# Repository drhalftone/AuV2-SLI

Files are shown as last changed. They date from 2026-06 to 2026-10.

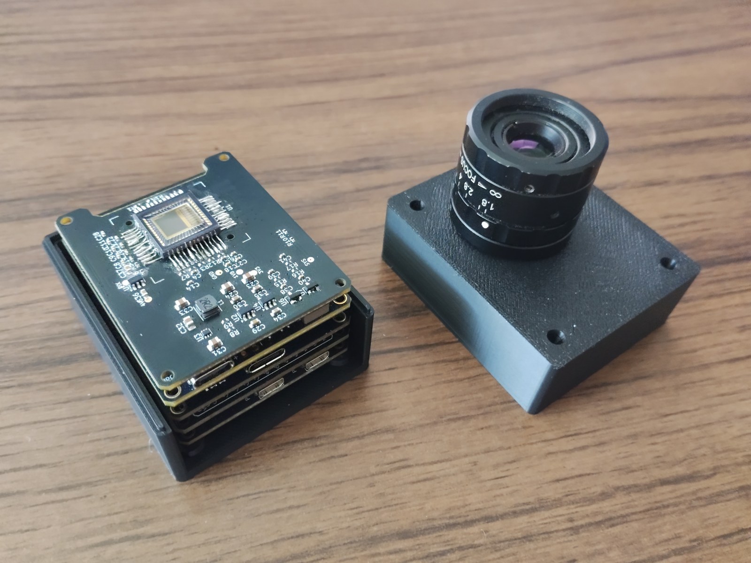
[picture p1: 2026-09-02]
press/stack_with_lens_cap_print.jpg

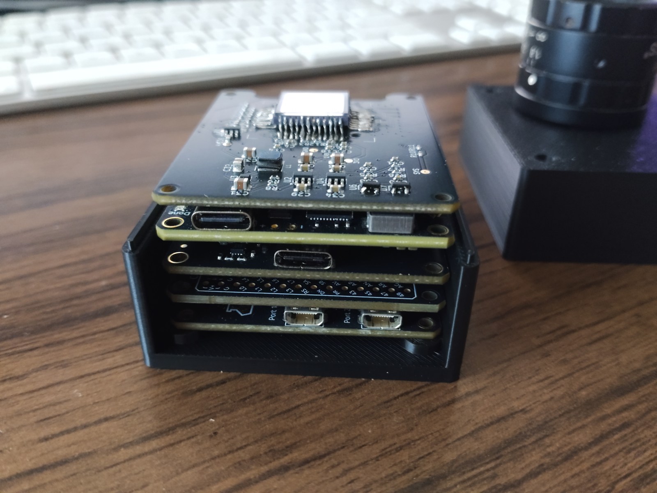
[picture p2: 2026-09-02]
press/stack_connector_edge_print.jpg

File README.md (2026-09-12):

# AuV2-SLI — an FPGA structured-light scanner with the camera inside it

A **BYOP (Bring Your Own Projector) machine-vision camera**: an Alchitry **Pt V2**
(Xilinx Artix-7 **XC7A100T-2**) sits inline on HDMI between a PC and a projector, and carries
an **ON Semi PYTHON 1300** global-shutter sensor on a stacked daughter board. One bitstream
generates the structured-light patterns, drives the projector, triggers the sensor at a
commanded delay from the projected vsync, and streams 10-bit frames to the host over an
**Alchitry Ft+** (FT601Q) USB 3.0 link.

The FPGA can:

- **Pass HDMI through** from a PC to the projector, triggering the camera on each new frame.
- **Replace the video with on-board SLI fringes** — resolution-adaptive, generated on the fly.
- **Run fully offline, with no HDMI source at all** — it reads the projector's EDID and drives
  it at a mode the projector actually advertises, up to **1280×1024@60** or **800×600@120**.
- **Genlock capture to projection** — camera triggers are issued a programmable delay after the
  projected vsync, and **stack**, so patterns advance at the full HDMI frame rate instead of at
  (exposure + delay).
- **Stream to the PC over USB 3** — 1280×1024 × 10 bit, byte-exact, up to 120 fps sustained.

> The HDMI datapath is adapted from [hamsternz/Artix-7-HDMI-processing](https://github.com/hamsternz/Artix-7-HDMI-processing) (MIT).
> Original SLI design by Qishi Hu. This fork adds the EDID-driven offline output, the adaptive
> pass-through clocking, the CEA-aware EDID merge, the PYTHON 1300 receive chain, the Ft+ USB 3
> image path, and genlock.

---

## 0. Quick orientation — what this repo is, on one screen

| | |
|---|---|
| **FPGA** | Alchitry **Pt V2**, `xc7a100tfgg484-2` (the original Au V2 / XC7A35T build still exists — `build.tcl`) |
| **Top level** | `sources_1/imports/RTL/Au2_SLI.vhd` (VHDL, instantiating the Verilog subsystems) |
| **Current build** | `build_merged.tcl` → `build_merged/Au2_SLI.{bit,bin}` — HDMI/SLI **+** camera **+** Ft+ |
| **Constraints** | `constrs_1/imports/RTL/Au2_pt.xdc` + `pt_ftplus_merged.xdc` |
| **Camera** | ON Semi **PYTHON 1300** (`NOIP1SN1300A-QTI`), 1280×1024, global shutter, 4-lane LVDS @ 720 Mbps |
| **Camera board** | `LauPythonCamera_Pt_Stack/` — the KiCad board **and** its Verilog (`ddr/`) |
| **Image path** | Alchitry **Ft+** (FT601Q) USB 3.0 — ~325 MB/s measured, 132 fps at 10-bit |
| **Control path** | the same Ft+ (opcode-0 tunnel), **and** a 115200 UART on Port A (COM6) kept as an independent witness |
| **Frame buffer** | DDR3 via MIG — **mandatory**, the sensor reads out in a 4.55 ms burst at 576 MB/s |

**Two control links, on purpose.** Everything the host needs is reachable over the Ft+. Port A's
UART is kept because *the frame stream goes silent exactly when the camera fails* — the link that
can still answer in that state is the one worth having.

### Where to look

| Document | For |
|---|---|
| [`USB_COMMAND_REFERENCE.md`](USB_COMMAND_REFERENCE.md) | **Every get and put** — 11 writable registers, ~120 readable, 6 table targets, the Ft+ opcodes |
| [`FTPLUS_API.md`](FTPLUS_API.md) | The Ft+ control API, marked R / W / R-W |
| [`FRAME_HEADER_PLAN.md`](FRAME_HEADER_PLAN.md) | Per-frame header design (format 3 → 4): pairing, timestamps, `pat_period` |
| [`GENLOCK_MILESTONES.md`](GENLOCK_MILESTONES.md) | Locking exposure to the projected frame — G0…G3 |
| [`MERGE_MILESTONES.md`](MERGE_MILESTONES.md) | How HDMI and camera were merged onto one FPGA — M0…M7 |
| [`PT_PASSTHROUGH_DEBUG.md`](PT_PASSTHROUGH_DEBUG.md) | Pass-through bring-up on the Pt, and the bug that broke 640×480 for 16 months |
| [`CAMERA_RTL_PLAN.md`](CAMERA_RTL_PLAN.md) / [`CAMERA_RTL_REVIEW.md`](CAMERA_RTL_REVIEW.md) / [`CAMERA_SENSOR_PROTOCOL.md`](CAMERA_SENSOR_PROTOCOL.md) | The camera receive chain: plan, review, datasheet constants |
| [`PC_INTERFACE_INVENTORY.md`](PC_INTERFACE_INVENTORY.md) | Complete PC ↔ FPGA comms inventory |
| [`ROADMAP.md`](ROADMAP.md) / [`MIPI_CSI2_ROADMAP.md`](MIPI_CSI2_ROADMAP.md) / [`POLARFIRE_PORT_FEASIBILITY.md`](POLARFIRE_PORT_FEASIBILITY.md) | Board stack, a MIPI CSI-2 receiver, a PolarFire port |

---

## 1. RTL module map

Paths relative to `sources_1/imports/RTL/` unless noted.

### 1.1 Top level and clocking

| Module | Role |
|---|---|
| `Au2_SLI.vhd` | **Top.** Instantiates everything; owns mode selection, the DRP retune, `ext_sync`, the boot retune one-shot |
| `clk_selector.v` | Chooses between the recovered pass-through clock and the offline generated clock (`sel`) |
| `drp_clkgen13.v` | The **offline** output-clock MMCM — 13 curated modes, retuned over DRP |
| `drp_recfg.v` | DRP write sequencer for `drp_clkgen13` (per-mode M/D/O words) |
| `rx_drp_recfg.v` | DRP sequencer for the **recovery** MMCM (pass-through side) |
| `rx_freq_band.v` | Picks the recovery-MMCM band from the **measured** input frequency — this is what makes pass-through adaptive rather than fixed-×15 |

Clock domains: `clk100` (control / EDID / USB), the pixel clock and its ×5 (`pixel_io_clk_x5`),
`wordclk` (72 MHz, recovered from the sensor's LVDS), and MIG's `ui_clk`.

### 1.2 HDMI receive (pass-through)

| Module | Role |
|---|---|
| `hdmi_io.vhd` | Wrapper for the input and output halves of the HDMI stream |
| `hdmi_input.vhd` | Decoded-stream assembly: control periods, data islands, sync extraction |
| `input_channel.vhd` | One TMDS channel: deserialise → align → decode (Mike Field) |
| `deserialiser_1_to_10.vhd` | ISERDESE2 1:10 |
| `alignment_detect.vhd` | **Bitslip search.** `signal_quality` accumulates `x"100000"` per error and trips at bit 27 |
| `tmds_decoder.vhd` | 10b → 8b TMDS decode |
| `video_meas.v` | Measures the **incoming** timing: h/v active, frame period, validity (regs `0x60`–`0x6A`) |
| `video_phase_fifo.v` | Elastic phase-compensation buffer across the recovered-clock boundary |

> **`alignment_detect.vhd` is the one to remember.** A dropped hex digit (`x"000100"` instead of
> `x"100000"`, introduced 2025-04-17) made the bitslip search **4096× too slow** — 31 ms per tap
> instead of 7.6 µs. Fast pixel clocks still converged; **640×480 never did.** Restoring the
> upstream constant fixed 640×480@60 and @75 pass-through.

### 1.3 HDMI transmit

| Module | Role |
|---|---|
| `dvid_output.vhd` | **DVI-D** output assembly: 3 × TMDS encode + 4 × serialise. Control codes only — **no guard bands, preambles or data islands** (those exist on the RX side, not here) |
| `tmds_encoder.vhd` | 8b → 10b TMDS encode |
| `serialiser_10_to_1.vhd` | OSERDESE2 10:1 — **the ceiling**: ×5 must stay under ~600 MHz |
| `vga.vhd` | **The live offline timing generator** — runtime H/V geometry in via ports, from `mode_timing_rom` |
| `video_timing_gen_rt.v` | Cleaner runtime timing generator (gates counters on `mmcm_locked`). **Written but NEVER instantiated** — unfinished Phase-D2 work; `vga.vhd` does this job today |
| `mode_timing_rom.v` | Per-mode video geometry lookup, keyed by `mode_idx` |
| `mode_table.vh` | The 14 curated modes (§4) |

### 1.4 EDID

| Module | Role |
|---|---|
| `i2c_master_edid.v` | Bit-banged I²C master; reads the **projector's** EDID off the output DDC |
| `edid_merge.v` | Self-contained merge unit + hot-plug ownership; re-probes every ~0.5 s |
| `edid_builder.v` | Builds the merged block served to the PC (monitor name `FPGA-PT`) |
| `edid_serve.vhd` | RAM-backed DDC **slave** on the input connector |
| `mode_select.v` | Parses the display EDID → supported-mode mask → the pick (regs `0x20`–`0x2A`) |

> `edid_fall` (reg `0x82`) counting **exactly 2/s is healthy** — it is the 0.5 s monitor-presence
> probe, not a fault. This was misdiagnosed twice.

### 1.5 Pattern generation

| Module | Role |
|---|---|
| `pattern_gen.v` | **Resolution-adaptive fringe DDS** (§5) |
| `pixel_pipe.v` | Pattern/pass-through mux, top-left-pixel trigger detection, the ready-paced GPIO handshake |
| `vga.vhd` | The offline test pattern — red = horizontal ramp, green = vertical ramp, blue = `h xor v` (XOR checker reveals geometry / tearing / a dead channel). Also generates the offline video timing — see §1.3 |

### 1.6 Camera — PYTHON 1300

RTL under `sources_1/imports/RTL/` and `LauPythonCamera_Pt_Stack/ddr/`.

| Module | Role |
|---|---|
| `cam_lvds_rx.v` | 1:10 LVDS receiver, PLL mode, per-lane IDELAYE2 |
| `cam_align.v` | Per-lane training / bitslip alignment |
| `cam_sync_decode.v` | Sync-channel decode + 4-lane de-interleave (proven bit-exact against the OVC reference) |
| `cam_spi_master.v` | 9-bit-addr / 16-bit-data SPI to the sensor |
| `cam_boot_seq.v` | ROM-driven power-up sequencer |
| `cam_cds_rom.v` | The CDS / sequencer-program upload payload |
| `cam_line_buf.v` | One-line capture buffer (bring-up) |
| `cam_async_fifo.v` | Dual-clock gray-pointer FIFO, **FWFT** |
| `cam_reply_fifo.v` | Control-plane reply bytes, `clk100` → `ui_clk` |
| `ddr/cam_frame_ft.v` | **The datapath.** Camera → DDR3 → FT601. Owns exposure, trigger period, re-arm, frame count, the genlock delay engine, and `cam_stat_o` |
| `ddr/cam_frame_ddr.v`, `ddr/ddr_bist.v`, `ddr/ddr_loop_ft.v`, `ddr/ft_probe_bottom.v` | Bring-up harnesses, kept as isolation tests |

> **The DDR3 is not optional.** The sensor reads a frame out in a **4.55 ms burst at 576 MB/s**
> against a 325 MB/s link. Live video cannot bypass the buffer, and lowering the frame rate does
> not help — the *burst* rate is what exceeds the link.

> `cam_async_fifo`'s `ram_style="block"` is **ineffective** (combinational FWFT read): 0 BRAMs are
> used. FIFO depth is not an available remedy.

### 1.7 Host link

| Module | Role |
|---|---|
| `uart_rx.v` / `uart_tx.v` | 8N1, LSB first |
| `uart_ctrl.v` | The `0xA5` control protocol — register file, table upload/readback |
| `status_line.v` | The one-line telemetry stream |
| `usb_link.v` | Arbitrates telemetry vs. command replies; **derives the max usable exposure** (§7.4) |
| `led_idle_anim.v` | "Sign of life" idle animation over the status LEDs |

---

## 2. Operating modes

### 2.1 Pass-through with top-left-pixel (TLP) trigger
The PC plays the patterns; the FPGA forwards the video unchanged, samples the **top-left pixel** of
each frame, and fires a camera pulse on the next VSYNC when that value changes.

### 2.2 Pass-through with on-board SLI patterns
The FPGA **replaces** the incoming frames with locally generated fringes. Orientation (`SW[0]`),
per-channel enables (`SW[3:1]`) and the frame/frequency sequencing drive it at runtime; all four
switches are overridable over USB (`SLICTRL`, reg `0x13`).

### 2.3 Offline (EDID-driven) — no HDMI source required
With nothing on the input, the FPGA generates everything from its own 100 MHz oscillator. The
output pixel clock **and** the video timing are reconfigured at runtime to match the projector's
EDID: a dedicated `MMCME2_ADV` is retuned over DRP and `vga.vhd`'s timing ports are loaded from the
curated table via `mode_timing_rom`.

> **Boot retune one-shot.** On power-up the DRP retune pulse used to be issued before the MMCM had
> locked, and was discarded — a blank screen on every cold boot. `Au2_SLI.vhd` now re-issues
> `clkgen_sen` once at **1 s** after configuration (`boot_cnt = 100_000_000` on `clk100`).
> `boot_cnt` is declared `integer` deliberately: both `STD_LOGIC_ARITH` and `NUMERIC_STD` are in
> scope in that file, so an `unsigned` would be ambiguous.

---

## 3. Genlock — the reason the FPGA is inline

`ext_sync` is the **output** vsync (`Au2_SLI.vhd`: `ext_sync => out_vsync`) delivered into
`cam_frame_ft.v`. Camera triggers are issued a programmable delay after it.

**Triggers stack.** Because the delay and the exposure are both known exactly, the delay engine is a
*fire-time queue*, not a wait-for-ready handshake:

```verilog
localparam [23:0] XS_TIMEOUT = 24'd10_000_000;   // 100 ms with no vsync -> fall back
localparam integer GLQ_AW    = 5;                // 32 outstanding triggers
reg [23:0] gl_now;                               // free-running 10 ns time base
reg [23:0] glq [0:31];                           // absolute fire-times
wire [23:0] gl_late = gl_now - glq[glq_rd];      // top bit CLEAR = deadline passed
wire gl_push = xs_rise && gl_live && !glq_full;
wire gl_pop  = !glq_empty && !gl_late[23];
```

So with a delay longer than a frame, **patterns advance at the full HDMI rate** — the capture of
pattern *k* simply arrives while pattern *k + floor(D/T)* is on screen. That pairing offset is
`floor(D/T)`; read it from reg `0x5E` (outstanding). **Do not assume it** — an offset wrong by one
yields a phase map that looks plausible and is wrong everywhere.

- `gl_en` is what was **commanded**; `gl_live` is whether `ext_sync` is actually arriving. They
  differ exactly when the display has gone away and the trigger has fallen back to free-running.
- Set it over the Ft+: **opcode 7**, `{4'd7, gl_en, 3'b0, delay[23:0]}`, delay in 10 ns ticks.
- Read it back over the UART: `0x5A`–`0x5C` delay, `0x5D` `{gl_live, gl_en}`, `0x5E` outstanding,
  `0x5F` FIFO overflows.

> **Sync must be held across the whole control period.** `hdmi_input.vhd` used to clear
> `raw_vsync`/`raw_hsync` alongside `raw_blank`, so on the 8 of 14 modes with **negative** vsync
> polarity `ext_sync` fired once per *line*. Sync is now assigned only from `ch0_ctl`.

**Not yet proven:** where the exposure actually lands optically inside the projected frame. Nothing
on the board sees photons — that measurement is photometric.

---

## 4. The curated mode table (`mode_table.vh`)

| idx | Mode | Pixel clock | H pol | V pol |
|---|---|---|---|---|
| 0 | 800×600@120 (CVT-RB) | 73.270 MHz | + | − |
| 1 | 640×480@120 (CVT-RB) | 52.420 MHz | + | − |
| 2 | 1024×768@75 (DMT) | 78.750 MHz | + | + |
| 3 | 800×600@75 | 49.500 MHz | + | + |
| 4 | 640×480@75 | 31.500 MHz | − | − |
| 5 | 1024×768@70 | 75.000 MHz | − | − |
| 6 | 800×600@72 | 50.000 MHz | + | + |
| 7 | 640×480@72 | 31.500 MHz | − | − |
| 8 | 1280×720@60 (CEA/DMT) | 74.250 MHz | + | + |
| 9 | 1280×800@60 (CVT-RB) | 71.110 MHz | + | − |
| 10 | 1024×768@60 | 65.000 MHz | − | − |
| 11 | 800×600@60 | 40.000 MHz | + | + |
| 12 | **640×480@60 — FAILSAFE** | 25.175 MHz | − | − |
| 13 | 1280×1024@60 (DMT) | 108.000 MHz | + | + |

**Selection order is `PRIO[] = {0,1,2,3,4,6,7,5,13,9,8,10,11,12}`** — highest refresh, then highest
pixel count.

> Priority is **deliberately not** the table index. `mode_idx` is a shared key into *both*
> `mode_table.vh` geometry **and** `drp_recfg`'s per-mode MMCM words, so re-sorting the table to
> express priority would hand each mode another mode's pixel clock. `mode_select` walks an explicit
> `PRIO[]` list instead; [`sim/tb_mode_select.v`](sim/tb_mode_select.v) covers it.

The EDID is a **filter, not a source** — a display's preferred timing is *matched against* this
table, never adopted. No match → idx 12.

Pin a mode with `MODEFORCE` (reg `0x14`; `0x8D` = force idx 13).

---

## 5. `pattern_gen.v` — resolution-adaptive fringes

The fringe period is solved **per mode at runtime** from the active size:

```
F     = active size along the varying axis   (orient=0 -> Vactive, orient=1 -> Hactive)
b     = ceil(F / 288)
P_lo  = 288b      P_mid = 48b      P_hi = 8b        (exact 1 : 6 : 36)
```

so the same `frq` index is a **different spatial frequency at every resolution**, and `P_lo` is
re-solved on a mode change. A scan spanning a mode change silently changes fringe period unless the
period travels with the data — which is why `pat_period` is in the planned frame header.

`frq == 3` is **not a fringe**: it selects a flat full-field flashing block for texture/albedo
capture. Sequence: 3 frequencies × 8 phases = 24 frames, plus the flash entries.

**The `corr` table is live in the pixel path.** `pattern_gen` presents its raw cosine to a 256-entry
transfer LUT and uses the result for every **fringe** pixel: `out = corr[cos]`. It powers up
identity, so leaving it unwritten changes nothing. FLASH pixels bypass it and stay true
`0x00`/`0xFF`. The lookup is **combinational by necessity** — a registered BRAM read would apply
each pixel's correction to the *next* pixel — so it synthesises as 256×8 LUTRAM.

`host/upload_corr.py --selftest` proves the LUT reaches the pixels: it uploads a constant curve and
watches the pipe-**output** top-left sample (`O=`) collapse onto that constant while the
pipe-**input** sample (`P=`) does not move.

> **`LUT` (0x00, 720 B) and `LUT_V` (0x01, 1280 B) have no consumer** — vestigial from the old
> `indexMap`/ROM design. They upload and read back fine and do nothing.

---

## 6. HDMI clocking, EDID merge, and the two ceilings

### Pass-through
`rx_freq_band.v` measures the incoming frequency and selects the recovery MMCM's band; the
multiplier **follows the input** rather than being fixed at ×15. `BANDWIDTH = HIGH`, so it tracks
the GPU's spread-spectrum clock.

**Verified working:** 640×480@60/@75, 800×600@60, 1024×768@60/70/75, 1280×720@60, 1280×800@60.

> **800×600 pass-through was advertised by arithmetic and never tested** until 2026-08-30; it ran
> the MMCM VCO at its rated minimum. `test_modecycle.py` measures only the **input**, so it reports
> success on a mode the projector never displays. Trust an eye on the projector, not that tool.

> **1280×1024 pass-through was attempted and dropped.** Recovering 108 MHz and re-serialising at
> 540 MHz never held sync — the recovered clock carries the GPU's spread spectrum, and a
> jitter-cleaner MMCM only reached "mostly perfect". Offline SXGA (clean clock, no domain crossing)
> is the supported 1280×1024 route.

### Served EDID
The FPGA reads the **projector's** EDID over the output DDC and serves the PC a **merged** EDID
(monitor name `FPGA-PT`) = `{projector's modes} ∩ {pass-through window}`, with a **60 MHz floor** so
only modes pass-through can actually hold are offered. The merge reads block-0 timings **and** the
CEA-861 extension's Video Data Block, so a TV-style sink advertising 720p60 only as VIC 4 is still
picked up.

### Hot-plug / EDID re-read
The board owns the host HPD line: held **low** until a projector is detected and a merged EDID
built, then asserted. It also **re-pulses HPD (~500 ms low) whenever the merged EDID content
changes** — many projectors serve a placeholder EDID during warm-up, and this makes their real modes
appear without unplugging the PC's cable. Per-build serial and checksum bytes are excluded from the
change detector, so it fires only on real mode changes.

`LINKCTL` (reg `0x15`) forces a self-timed disconnect: **dropping the host HPD is the only reliable
way to force the board offline** — a host-side detach cannot do it.

### Offline ceiling
The output serialiser sets it: **1280×1024@60 (108 MHz, ×5 = 540 MHz) is the top offline mode**,
HW-verified on this −2 part. **1080p60 is NOT reachable** (×5 = 742.5 MHz, over the ~600 MHz
OSERDES/BUFG ceiling; the HDMI I/O is on 3.3 V TMDS HR banks, ~1.2 Gb/s/ch).

---

## 7. The host interface

### 7.1 Two transports, one protocol

The `0xA5` framed protocol is identical on both links.

| Op | Request | Reply |
|---|---|---|
| Write reg | `A5 57 ADDR DATA CK` | `K` ok / `N` read-only or undefined / `E` bad CK |
| Read reg | `A5 52 ADDR CK` | `ADDR DATA CK2` |
| Upload table | `A5 5B TGT D[0..N-1] CK` | `K` / `E` |
| Read table | `A5 72 TGT CK` | `TGT D[0..N-1] CK2` |

`SYNC 0xA5` is never part of a checksum; `CK` drives the running payload sum to 0 mod 256.

**Over the UART** (COM6, 115200 8N1) the bytes go on the wire directly.

**Over the Ft+** they are tunnelled as **opcode-0 words**, three bytes at a time with an explicit
count: `{4'd0, count[3:0], byte2, byte1, byte0}`. They cannot be packed raw — the top nibble of
every OUT word is a camera opcode, so a protocol byte landing at `0x1?` would fire opcode 1 and
silently rewrite the exposure.

Replies come back **interleaved with video** on the IN pipe, with the same 32-byte header shape as a
frame: magic `"SLI1"` (frames are `"SLI0"`), format 4. **A reply is a transport chunk, not a
message** — one reply can split across two packets and two can share one, so the host reassembles a
byte stream and lets the `0xA5` framing do its own work. Replies leave only at **frame boundaries**:
at 120 Hz that is up to ~8.3 ms of latency, by construction. Size timeouts in milliseconds.

### 7.2 Ft+ opcodes (top nibble of each 32-bit OUT word)

| Op | Payload | Effect |
|---|---|---|
| 0 | `{count[3:0], b2, b1, b0}` | **`0xA5` protocol tunnel** — see above |
| 1 | `[15:0]` | Set exposure, in **375 ns** units |
| 2 | `[23:0]` | Set the free-running trigger period (10 ns ticks); ignored if ≤ 1000 |
| 3 | — | **Re-arm** the capture |
| 4 | `[5:0]` | Frames per run (1…`MAXF`) |
| 5 | — | Request a status reply on the IN pipe |
| 7 | `{gl_en, 3'b0, delay[23:0]}` | **Genlock**: enable + vsync→trigger delay in 10 ns ticks |
| 8 | *(planned)* | Arm an epoch reset on the next `ext_sync` — see `FRAME_HEADER_PLAN.md` |

> Opcode 6 is unassigned. Opcode 3 (**re-arm**) is easy to forget and its absence is invisible: a new
> exposure changes nothing the host can see, because DDR still holds the burst captured at the old
> value and capture is one-shot per bitstream load.

### 7.3 Register map

**Writable (11):** `0x13` SLICTRL, `0x14` MODEFORCE, `0x15` LINKCTL, `0x16` CAMSIM,
`0x30`–`0x34` CAM_SPI (addr / `{rw,addr[8]}` / wdata lo / wdata hi / GO), `0x37` CAM_GPIO,
`0x39` CAM_BOOT. Everything else answers `N` to a write.

| Addr | Name | Acc | Meaning |
|---|---|---|---|
| `0x00` | ID | R | constant `0x48` (`'H'`) — the control bitstream is loaded |
| `0x01` | VERSION | R | protocol version (`0x01`) |
| `0x02` | STATUS | R | `{vsync, hsync, VPol, sel, mode, rdy, f_frm, trig}` (same as the LEDs) |
| `0x06` | FLAGS | R | `{…, usb_sw_en, lut_loaded}` |
| `0x10` | PINS | R | `{eff_sw[3:0], phys_sw[3:0]}` — active vs. physical switch pins |
| `0x13` | SLICTRL | R/W | `{7:sw_en, 6:mode_en, 5:mode_val, 3:R, 2:G, 1:B, 0:orient}` |
| `0x14` | MODEFORCE | R/W | `{7:force_en, 3..0:idx}` — pin the **offline** mode (`0x8D` = idx 13) |
| `0x15` | LINKCTL | R/W | `{7..2:secs×2, 1:proj, 0:host}` self-timed disconnect; `0x41` = host-drop 8 s |
| `0x16` | CAMSIM | R/W | host-driven camera-ready, to run the pipeline with no camera |
| `0x20` | MODE | R | `{7:valid, 6:edid_ok, 3..0:mode_idx}` — the index **in use** |
| `0x21` | REFR | R | refresh rate, Hz |
| `0x22`–`0x23` | HACT | R | active pixels, 12-bit |
| `0x24`–`0x25` | VACT | R | active lines, 12-bit |
| `0x26`–`0x28` | PCLK | R | pixel clock in kHz, 17-bit |
| `0x29`–`0x2A` | SUPP | R | 14-bit supported-mode mask (bit *i* = table index *i*) |
| `0x30`–`0x36` | CAM_SPI | R/W | PYTHON 1300 SPI mailbox (`0x34` GO/busy, `0x35`/`0x36` rdata) |
| `0x37` | CAM_GPIO | R/W | `{7:reset_n, 2..0:trigger}` — resets to `0x00` (sensor held in reset) |
| `0x38` | CAM_MON | R | `{1..0:monitor}` |
| `0x39` | CAM_BOOT | R/W | boot sequencer; W starts it (`N` if busy), R = `{ready, busy, failed, pll_timeout}` |
| `0x3A` | CAM_STAT0 | R | `{stw[2:0], rd_busy, calib, aligned, streaming, cap}` — "is it alive" |
| `0x3B` | CAM_STAT1 | R | `{cfifo_ovf, ufifo_ovf, ufifo_empty, txe, 0000}` — "is it healthy" |
| `0x3C`–`0x3D` | LDROP | R | padded frames; **static == none lost** |
| `0x3E`–`0x3F` | CAM_PER | R | frame period **÷ 16**, in 72 MHz wordclk cycles |
| `0x40`–`0x41` | EXPO0 | R | exposure, 375 ns units |
| `0x42`–`0x47` | TRIG→INT | R | trigger → integration start, **min** then **max**, 10 ns units |
| `0x48`–`0x49` | INT_LEN | R | last integration length, 160 ns units |
| `0x4A`–`0x52` | VS_PER | R | vsync period: last / min / max, 10 ns units |
| `0x53`–`0x57` | MAXEXP | R | max usable exposure — §7.4 |
| `0x58`–`0x59` | XS_CNT | R | `ext_sync` edge count, free-running, wraps |
| `0x5A`–`0x5C` | GL_DLY | R | genlock delay, 10 ns ticks |
| `0x5D` | GL_STAT | R | `{6'b0, gl_live, gl_en}` |
| `0x5E` | GL_OUT | R | triggers outstanding = the pairing offset |
| `0x5F` | GL_OVF | R | genlock FIFO overflows (saturates) |
| `0x60`–`0x6A` | RX_MEAS | R | **incoming** HDMI: h/v active, period, `{vid_valid, meas_ok}`, recovered pclk kHz |
| `0x6B`–`0x6C` | RX_DIAG | R | decode diagnostics; phase-FIFO re-primes |
| `0x6D`–`0x80` | CTL/VDP/PRE/GB/EVT | R | control-period, video-data-period, preamble, guard-band and event counters |
| `0x81`–`0x82` | HPD_DIAG | R | HPD-to-PC falling edges; `edid_ok` falling edges |
| `0x83`–`0x8D` | OUT_MEAS | R | **transmitted** timing: h/v active, period, valid, pclk kHz |
| `0x8E`–`0x90` | TRIG_PER | R | the free-running trigger period in effect |

**Read `0x67` first.** If `meas_ok` is 0 the other six read 0 *on purpose* — a stale resolution that
looks live is worse than no answer.

**Min and max are the point** for `0x42`–`0x47` and `0x4A`–`0x52`. The datasheet gives no
trigger-to-exposure delay at all and says integration snaps to a line boundary (~5.7 µs) whenever it
begins during a readout — which in pipelined mode is always. `max − min` **is** that jitter,
measured; a single sample could not show it. The window resets every status tick (~10 Hz), so each
read describes a fresh window rather than an ever-widening high-water mark.

**Table targets** (op `0x5B` upload / `0x72` read):

| TGT | Name | Size | Acc | Contents |
|---|---|---|---|---|
| `0x00` | LUT | 720 B | R/W | vestigial — **no consumer** |
| `0x01` | LUT_V | 1280 B | R/W | vestigial — **no consumer** |
| `0x02` | CORR | 256 B | R/W | the radiometric transfer LUT, live in the pixel path (§5) |
| `0x03` | EDID | 256 B | **R** | the EDID the **display** sent us — what `mode_select` decided from |
| `0x04` | CAM_LINE | 1280 B | **R** | one captured camera line (bring-up) |
| `0x05` | EDID_SRV | 256 B | **R** | the **merged** EDID we serve to the PC |

`0x03` vs. `0x05` is the pair worth knowing: one is what the projector claims, the other is what the
PC is told. `host/offline_mode.py` reads both.

> An EDID readback is always 256 bytes; if the display has no extension block, bytes 128–255 are
> stale RAM. Byte `0x7E` of block 0 is the authoritative extension count.

### 7.4 Max usable exposure — the FPGA works it out itself

`usb_link.v` derives how long the sensor can integrate at whatever rate it is *actually* running:

```verilog
wire        gl_live_s  = cam_stat_i[169];
wire [23:0] trig_per_s = cam_stat_i[215:192];
wire [23:0] eff_per    = gl_live_s ? vsp_last_p : trig_per_s;   // vsync period, or free-run period
```

Reserve = `GAP_TICKS` 4410 (44.1 µs) + `MARGIN_TICKS` 1000 = **54.1 µs**, then scaled from 10 ns into
375 ns register units by `×27962 >> 20`.

- `0x53`/`0x54` — max exposure **in exposure-register units**; write it straight back with opcode 1.
- `0x55` — `{7: valid, 6: limited by the 16-bit register rather than by the frame period}`.
- `0x56`/`0x57` — the reserve subtracted, in 10 ns ticks.

**`valid = 0` means do not guess.** Commanding an exposure longer than the frame period wedges the
sensor until the FPGA is reconfigured — the exact failure this register exists to prevent.

> **Trap:** `0x3E`/`0x3F` holds the camera period **÷ 16** in 16 bits and therefore cannot represent
> anything below **68.67 Hz**. A genlocked 59.9 Hz and 6.16 Hz produce the same reading. Infer
> nothing about genlock from it — read `0x5D`. `host/max_exposure.py` still infers, and is wrong
> below 68.67 Hz.

### 7.5 Telemetry (COM6, 115200 8N1, ~2 lines/s)

```
S=sel V=pol T=trig F=frm M=mode R=rdy N=vsync L=hh D=hh G=hh P=hh C=hh O=hh
```

`S` = pass-through(1)/offline(0), `D` = decode debug (symbol-sync / PLL-lock / sel), `P`/`O` =
recovered vs. pipe-output top-left red, `N` = VSYNC edges per window.

> `N` is an **edge count** and dithers between 51 and 52 at 120 Hz — it cannot resolve the period
> better than ~2% and cannot see jitter at all. Use `0x4A`–`0x52` for that.

---

## 8. Host tools

### 8.1 Over the Ft+ — `ft_usb_video/host/`

Needs `ftd3xx`; only **one** process may hold the D3XX handle at a time.

> **There is exactly one viewer: `cam_live.py`.** Because only one process can hold the D3XX handle,
> a second viewer could only ever be the wrong one to have open. `ft_video_grab.py` used to default
> to a controls-free PySide6 window; that was removed 2026-09-01 and it is now headless. Nothing in
> the repo needs PySide6.

| Tool | Does |
|---|---|
| `cam_live.py` | **The live viewer — the only one in this repo.** tkinter; exposure slider, plus a second row with a *sync to projector* checkbox and a trigger-delay slider. The exposure ceiling tracks the measured rate |
| `cam_ctl.py` | Exposure, frame rate and re-arm from the command line |
| `campack.py` | Frame geometry, header parsing and 10-bit unpacking — **shared** by the other tools |
| `cam_rate_bench.py` | Frame rate over repeated 24-frame runs |
| `ft_cam_burst.py` | An N-frame burst captured into DDR and streamed out |
| `ft_cam_verify.py` | Byte-exactness of the FT601 bus, plus a PNG |
| `drift_check.py` | Frame-to-frame alignment drift, in kernels |
| `row_align_check.py` | Are delivered frames aligned *with each other*? (row profiles) |
| `ring_check.py` | Frames must be clean, fresh, and cost no lost kernels |
| `scan_latency.py` | Re-arm → time until a complete **new** scan arrives |
| `expo_check.py` | Exposure is settable at runtime; measures the response |
| `ddr_loop_check.py` | Concurrent DDR3 write+read loopback, byte by byte |
| `test_campack.py` | Round-trips the packed-10 layout against a model of the RTL packer |
| `test_m5_reply.py` | Does the link answer back without damaging the frame stream? |
| `ft_video_grab.py` | Throughput meter, **headless** — framed FPS/MB-s, or `--raw` unframed. Also the home of `FtDevice` / `FrameAssembler` / `unpack_raw10`, which the other tools import |
| `ft_bench_async.py`, `ft_diag_rows.py` | Zero-copy throughput sweep; per-column corruption forensics |

> **`ft_video_snap.py` validates the SYNTHETIC SLI pattern**, not the camera. Pointed at real camera
> data it reports "0 frames matching, worst pixel error 1023" and writes a random-looking PNG. That
> is the tool answering a different question. Use `cam_live.py` to judge real output.

### 8.2 Over the Ft+ control plane — `host/`

`ftlink.py` (the transport class), `test_m6a_ctlpath.py`, `test_m6a_under_load.py`,
`test_m6b_reply.py`, `test_m6c_silicon.py`, `dbg_m6b_packet.py`.

### 8.3 Over the UART — `host/`

| Tool | Does |
|---|---|
| `test_silicon.py` | The bring-up test — **15/15** |
| `test_protocol.py` | Offline cross-check of the framing |
| `dump_edid.py` | Dump and decode the display's EDID as the FPGA captured it |
| `read_mode.py` | Which offline mode was picked, and what it had to choose from |
| `force_mode.py` | Pin the offline mode over `MODEFORCE` |
| `offline_mode.py` | Inspect both EDIDs and drive the offline mode |
| `rx_timing.py` | What the source is actually sending |
| `read_cam_status.py` | The camera datapath status (`0x3A`–`0x41`) |
| `max_exposure.py` | How long the camera can expose at the current rate *(see the 68.67 Hz trap)* |
| `measure_vsync_period.py` | Vsync period and jitter (genlock G0) |
| `measure_trigger_latency.py` | Trigger → integration start, and its jitter |
| `measure_exposure_gap.py` | Is the blind window between exposures constant? |
| `upload_corr.py` | Upload the radiometric LUT and prove it is live (`--selftest`) |
| `test_modecycle.py` | Cycle the PC's HDMI modes and check the FPGA follows *(measures the INPUT only)* |
| `test_3b_cameraidle.py`, `test_3c_camerawedge.py`, `test_3d_modechange.py` | Merge isolation: the camera must not disturb HDMI, and vice versa |
| `soak.py`, `stress_attack.py`, `usb_speed.py` | Long-run stability, hostile input, USB 3 confirmation |
| `lauauboard.{h,cpp}` | The C++ host-side implementation of the protocol |

> After a board reset, `edid_merge` needs a few seconds to finish reading the DDC. Until it does,
> `edid_ok` is 0 and `SUPP` is empty while `MODE` still reads the power-up default — a half-state
> that looks like a failed pick. `read_mode.py` waits for `edid_ok`.

---

## 9. Building and flashing

**Vivado 2025.2.1** lives at `C:\AMDDesignTools\2025.2.1\Vivado\bin\vivado.bat` (**not**
`C:\Xilinx`, and not on `PATH`).

```
vivado -mode batch -source build_merged.tcl    # -> build_merged/Au2_SLI.{bit,bin}   THE CURRENT DESIGN
vivado -mode batch -source build_pt_hdmi.tcl   # the HDMI/SLI half alone on the Pt V2
vivado -mode batch -source build.tcl           # the original Au V2 / XC7A35T design
vivado -mode batch -source program.tcl         # volatile JTAG load
```

| Script | Part | Contents |
|---|---|---|
| `build_merged.tcl` | XC7A100T (Pt V2) | **Current** — HDMI/SLI + PYTHON 1300 + Ft+ + MIG |
| `build_pt_hdmi.tcl` | XC7A100T | HDMI/SLI only — faster turnaround for pass-through work |
| `build_pt.tcl` | XC7A100T | **Stale** — predates M2, no camera datapath |
| `build.tcl` | XC7A35T (Au V2) | The original design; still builds |

Do not run two builds concurrently — they share an out-of-tree IP generation directory.

**Flashing** with the Alchitry loader **2.0.52+** (not the old `C:\Program Files\Alchitry` copy):

```
alchitry.exe load --bin build_merged/Au2_SLI.bin --board PtV2 --ram     # volatile, for testing
alchitry.exe load --bin build_merged/Au2_SLI.bin --board PtV2 --flash   # persistent
```

`AlchitryFlasher/AlchitryFlasher.cmd` is a one-click Windows flasher for the released
`Bitstream/Au2_SLI.bin` (SHA-256 checked).

**Simulation is available** — `xvhdl` / `xvlog` / `xelab` / `xsim` are installed.
`sim/tb_mode_select.v` covers the mode pick; `sim/tb_hdmi_loopback.v` + `sim/run_hdmi_tb.sh` cover
the HDMI path.

> **Vivado on this host crashes for tool reasons roughly half the time** — `[Designutils 12-1097]`,
> `EXCEPTION_ACCESS_VIOLATION`, bare exit 116 / 127. Retrying the same script normally succeeds.
> Note also that silent one-digit file corruption has been observed on this machine. **Run memtest
> before trusting an artifact.**

---

## 10. Traps this project has already paid for

| Trap | Why it bites |
|---|---|
| **Comments lie; the code does not** | `pre_diag`'s header claims preamble counts but the code counts vsync/hsync rises. `vdp_diag[31:16]` is labelled `in_dvid` and counts `in_adp`. `gb_diag[31:16]` is labelled `vdp_prefix_seen` and counts `vdp_guardband_detect`. Five wrong conclusions in one session came from believing headers |
| **`test_modecycle.py` measures the input** | It reports success on modes the projector never displays |
| **`edid_fall` at exactly 2/s is healthy** | It is the 0.5 s DDC presence probe |
| **`0x3E`/`0x3F` wraps below 68.67 Hz** | Period ÷ 16 in 16 bits. Never infer genlock from it |
| **FWFT FIFO + `rd <= !empty`** | Duplicates the last item every burst; a doubled stream fails exactly like a dead one |
| **Sensor damage at the top of the frame** | Permanent, from a soldering-era fault. Not an LVDS/link bug — do not chase it |
| **720 Mbps LVDS needs IDELAYE2** | Without eye-centring the isolated bit drops and it looks exactly like bad solder |
| **The FT601 can enumerate and not clock** | It can read an EEPROM back perfectly while driving no `ft_clk`. Pulse `RESET_N` |
| **The FT601 can stream fast and lie** | A build measured 192 fps / 0 drops while corrupting `ft_data[31:16]`. An unconstrained source-synchronous bus is invisible to timing *and* to throughput tests. **Verify bytes** |
| **Build scripts can silently drop generics** | Two experiments were invalidated this way. Check the generics actually reached synthesis |
| **PowerShell here-docs mangle git messages** | `git commit -m @'…'@` fails with pathspec errors. Write the message to a file and use `git commit -F` |
| **The RX input self-oscillates with no cable** | `sel`/offline hunts and `symbol_sync` is fooled; `pll_locked` staying 0 is the honest signal |

---

## 11. Pins, LEDs and switches

The Pt V2 pinout is in `constrs_1/imports/RTL/Au2_pt.xdc` (+ `pt_ftplus_merged.xdc` for the Ft+);
the camera board's connector map is in [`CAMERA_IO_MAP.md`](CAMERA_IO_MAP.md).

### Config switches

| Switch | Function |
|---|---|
| `SW[3]` | Red channel enable |
| `SW[2]` | Green channel enable |
| `SW[1]` | Blue channel enable |
| `SW[0]` | 0 = vertical stripes, 1 = horizontal |

All four are overridable over USB via `SLICTRL` (`0x13`) with bit 7 set:
`effective_sw = sw_en ? usb_value : SW`. `PINS` (`0x10`) shows both nibbles, so you can confirm the
override took and read live switch state at any time.

> **Next board rev:** make all four switches uniform (all pull-up / default-high, switch → GND). That
> needs the HvsV switch rewired from +3V3 to GND **on the PCB** — it is not an FPGA-only change —
> plus the HvsV logic inverted.

### LEDs

| LED | Indication |
|---|---|
| 7 | VSYNC |
| 6 | HSYNC |
| 5 | VSYNC polarity (1 = positive) |
| 4 | HDMI-Rx clock detected (off in offline mode) |
| 3 | 0 = SLI pattern, 1 = desktop display |
| 2 | Camera trigger ready |
| 1 | Current frame is the first of the pattern |
| 0 | Trigger output |

`led_idle_anim.v` runs a slider animation when nothing is connected — a deliberate sign of life.

### Legacy DB-9 camera GPIO (Au V2 / Br V2 era, still in `pixel_pipe.v`)

A 4-line handshake per camera: **trigger** out, **mode** in, **first-frame** out, **ready** in.
`pixel_pipe.v` drives `C1_out(0)` / `C2_out(0)`; Cam2 mirrors Cam1's outputs but only **Cam1's**
ready and mode inputs are wired, so Cam2's readiness does not gate the capture rate. This path is
independent of the PYTHON 1300 trigger, which comes from `cam_frame_ft.v`.

`pixel_pipe.v` uses a 1-deep `pending` with fresh-ready arming and a `GLITCH_CYC = 10000` de-glitch
(commit `ae8fa1e`).

> **Deferred TODO:** port the MimasA7 `cam_pace.v` edge-paced trigger over the AuV2 `rdy_cnt`
> accumulation, splitting split-mode's two jobs.

> `pattern_gen`'s enable comes from the camera board's `mode` GPIO (`C1_in[1]`), which the XDC
> **pulls low** — with no camera attached the generator is off and the offline test pattern passes
> straight through. Set `0x13` `mode_en` + `mode_val` to force the SLI fringes on with no camera
> board.

---

## 12. Boards in this repo

| Folder | What it is |
|---|---|
| [`LauPythonCamera_Pt_Stack/`](LauPythonCamera_Pt_Stack/) | **The current camera** — PYTHON 1300 daughter board for the Pt V2, *and* its Verilog under `ddr/` |
| [`LauCameraTrigger_Alchitry/`](LauCameraTrigger_Alchitry/) | The original Br V2 → DB-9 trigger breakout, plus the Basler / Alvium wiring guides |
| [`LauCameraTrigger_Alchitry_3xJST/`](LauCameraTrigger_Alchitry_3xJST/) | The same, with 3× on-board JST-7 connectors |
| [`LauCameraTrigger_Alchitry_Stack/`](LauCameraTrigger_Alchitry_Stack/) | DF40 stacking version; SPDT config switches, trigger broadcast to 3 cameras |
| [`LauMipiCamera_Alchitry_Stack/`](LauMipiCamera_Alchitry_Stack/) | MIPI CSI-2 board (WIP scaffold) — open in KiCad and run ERC/DRC before relying on it |

Camera-wiring guides under `LauCameraTrigger_Alchitry/`: Basler ACE USB 3.0, Allied Vision Alvium
1800, a three-camera DB-9 harness, the on-board JST-7 variant, and the Vimba FPGA timing guide.

> **rev-1 `LauCameraTrigger` had a floating GND island** at the DIP switch (SW1 / caps / tie-low not
> bonded to DF40 GND). rev-1 boards are bodged; fixed in layout, pending fab verification.

---

## 13. Repository layout

```
├── README.md                        # this file
├── USB_COMMAND_REFERENCE.md         # every get and put, both transports
├── FTPLUS_API.md                    # the Ft+ control API
├── FRAME_HEADER_PLAN.md             # per-frame header design (format 3 -> 4)
├── GENLOCK_MILESTONES.md            # G0..G3 — exposure locked to the projected frame
├── MERGE_MILESTONES.md              # M0..M7 — HDMI + camera on one FPGA
├── PT_PASSTHROUGH_DEBUG.md          # pass-through bring-up on the Pt
├── PC_INTERFACE_INVENTORY.md        # complete PC <-> FPGA comms inventory
├── PC_INTERFACE_PLAN.md             # diagnostics on the Pt, everything else on the Ft
├── CAMERA_RTL_PLAN.md               # PYTHON 1300 bring-up plan + gates
├── CAMERA_RTL_REVIEW.md             # fresh-eyes receiver-chain review (P1-P4)
├── CAMERA_SENSOR_PROTOCOL.md        # datasheet-cited protocol constants
├── CAMERA_IO_MAP.md                 # camera board I/O pin map
├── CAMERA_POWER_DESIGN.md           # camera board power design
├── CAMERA_POWER_SIMULATION.md       # camera board power simulation
├── CAMERA_CALIBRATION_NOTES.md      # two-point calibration — where it could live
├── ROADMAP.md                       # hardware expansion (DF40 stacking, Ft+, MIPI)
├── MIPI_CSI2_ROADMAP.md             # custom MIPI CSI-2 receiver plan
├── POLARFIRE_PORT_FEASIBILITY.md    # porting to a Microchip PolarFire kit
├── build_merged.tcl                 # THE CURRENT BUILD  (Pt V2: HDMI + camera + Ft+)
├── build_pt_hdmi.tcl                # HDMI/SLI half alone on the Pt V2
├── build_pt.tcl                     # stale Pt build (pre-M2)
├── build.tcl                        # original Au V2 / XC7A35T build
├── program.tcl                      # volatile JTAG load
├── sources_1/                       # HDL (sources_1/imports/RTL) + IP
├── constrs_1/                       # XDC — Au2.xdc (Au V2), Au2_pt.xdc + pt_ftplus_merged.xdc (Pt)
├── sim/                             # xsim testbenches
├── host/                            # UART + Ft+ control-plane tools, and the C++ host class
├── ft_usb_video/                    # the USB 3 image path — viewer, benches, verifiers
├── press/                           # press release (LaTeX + PDF) and the HTML reference pages
├── Bitstream/                       # released bitstream (Au2_SLI.bin)
├── AlchitryFlasher/                 # one-click Windows flasher
├── Matlab/                          # legacy pattern-generation scripts
├── build_scripts/                   # historical project-mode scripts (superseded)
├── Lau*_Alchitry*/ , LauPythonCamera_Pt_Stack/   # KiCad boards
└── LICENSE
```

## Licensing

The HDMI pass-through foundation is adapted from
[hamsternz/Artix-7-HDMI-processing](https://github.com/hamsternz/Artix-7-HDMI-processing) (MIT).

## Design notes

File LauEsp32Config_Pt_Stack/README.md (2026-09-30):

# ESP32 wireless programmer — Pt V2 element card

_Started 2026-09-02. Nothing is built. Scope is deliberately narrow: **reprogram
the Pt V2's FPGA over WiFi from a board inside the stack.** Everything needed
electrically is now confirmed from Alchitry's own Rev A schematic and pinout sheet,
both in `docs/`. Read the **rev B warning** in §3 before committing a layout._

---

## 1. Why this board exists

**The Ft+ cannot configure the FPGA, and it is the only host↔FPGA link this camera
has.** That single fact is the whole justification.

Today the Pt is programmed over its own USB-C through the FT2232H, by the Alchitry
loader. Fine on a bench with the enclosure open; not fine for

- a camera **sealed in the printed enclosure**, where the Pt's USB-C is not meant
  to be user-accessible;
- a **just-in-time workflow** — write HDL, compile, push — where walking a cable to
  the part defeats the point;
- **multiple cameras**, where the cable count grows with the array.

So: an element card carrying an ESP32, sitting in the stack, driving the FPGA's
JTAG from inside. It replaces the GPIO board currently used as a spacer, so it
costs no stack height that is not already accounted for.

> The founder of Alchitry, who designed these boards, says the approach should
> work. §3 and §4 are the pin- and part-level confirmation of that.

## 1a. Stack position — in place of the Sp spacer between Ft+ and Hd. VERIFIED 2026-09-16

```
   [ camera element ]      top of the Pt
     Alchitry Pt V2
   [ Sp ]                  clears the Pt's bottom-side caps
   [ Ft+ ]
   [ ESP32 card ]          <- replaces the second Sp (micro-HDMI / USB cable clearance)
   [ Hd ]
```

Checked against Alchitry's own schematics (`docs/Alchitry_Platinum_RevA_schematic.pdf`
sheet 4, `docs/FtPlusSchematic.pdf`, `docs/HdSchematic.pdf`), read from rendered images:

- **Connector genders match.** Pt, Ft+ and Hd all carry `DF40C-xxDS-0.4V(4.0)` receptacles on
  top and `DF40C-xxDP-0.4V` plugs on the bottom. This card does the same, so it fits
  anywhere a spacer fits.
- **The control signals reach this slot.** The Ft+ and the Hd pass control pins C29–C50
  straight through and use none of them.
- **Alchitry numbers every bottom plug mirrored.** On all three boards, bottom plug pin *2k*
  mates receptacle pin *2k−1*: the Pt's J8 has +3V3 on **even** 1–16, RESET on 38, TCK on 50.
  Carried through the Ft+ into this card's top receptacle (receptacle numbering), the pins
  land **exactly where §3 and the schematic assume**: +3V3 odd 1–15, 37 Reset, 39 DONE,
  41 PROGRAM_B, 43 TDI, 45 TDO, 47 TMS, 49 TCK. **No netlist change is needed.**
- **The FPGA nets on 29–36 are NOT the ones in §3b.** §3b decoded the Pt's *top* connector.
  Below the Pt they come from J8, the bottom connector:

  | Card pin | FPGA net (Pt J8) | | Card pin | FPGA net (Pt J8) |
  |---|---|---|---|---|
  | 29 `FAB_SCK` | `34_L1_N` | | 30 `FAB_IO2` | `34_L15_N` |
  | 31 `FAB_MOSI` | `34_L1_P` | | 32 `FAB_IO3` | `34_L15_P` |
  | 33 `FAB_IRQ` | `34_L3_N` | | 34 `FAB_MISO` | `34_L6_N` |
  | 35 `FAB_SPARE` | `34_L3_P` | | 36 `FAB_CS` | `34_L6_P` |

  All are bank 34, hardwired 3.3 V, and they are still true N/P pairs. Constrain them **by
  package pin** from Alchitry's `pt_*_bottom` constraint files (bank-16/34 labels are swapped
  in the schematic, §3b).

**Mechanical consequences:**
- **Stack height is unchanged.** The gap on each side stays 4.125 mm (§6.3).
- **Top face:** faces the Ft+ underside, which has no components (§6.3). The whole gap is usable.
- **Bottom face:** now faces the **Hd's top side, where its micro-HDMI receptacles are.**
  Cable clearance there is what the spacer was for. **Measured from the Hd STEP (§6.3):**
  ≥ 2.67 mm under the card everywhere except over the two HDMI connectors (1.15 mm). That area
  is now a B.Cu no-footprint rule area (x 0–9.5, y 17.5–40, left edge).
- **Rev B:** Alchitry's "JTAG pins will change places" note is on the *top* connector
  column of the rev A pinout sheet. Whether the bottom connector changes too is unconfirmed.
  The straps (`SCHEMATIC.md` §4) cover the published Au order either way.

## 2. Configure RAM, never the boot flash

**The bitstream goes into the FPGA's volatile configuration memory. The QSPI boot
flash is never written.**

The consequence is the point: **power-cycling the camera restores its camera
functionality.** The Pt reloads the shipped image from flash on boot, so whatever
experimental bitstream was pushed is simply gone.

That makes the failure mode of a bad JIT build *a reboot*, not a brick. A pipeline
that can write boot flash can permanently kill a sealed unit; one that can only
write configuration RAM cannot. **Treat "never touch the QSPI flash" as a design
rule, not a phase-one simplification.**

The schematic reinforces it: **`CCLK_0` (L12) is shared with `QSPI_SCK`** — the
configuration clock and the flash clock are the same net. Anything driving
configuration is already adjacent to the flash bus, so the separation has to be
kept deliberately, in firmware.

## 3. J3 "Control" — the connector this board lives on

From Alchitry's **"Pinout and Trace Lengths"** sheet, exported to
`docs/Pt_V2_pinout_trace_lengths.csv`. Generated from the CSV, not transcribed.
**Identical on the top and bottom sides**, so a pass-through card sees the same map
on both faces.

| Pin | Signal | | Pin | Signal |
|---|---|---|---|---|
| 1–15 odd | `+3V3` | | 2–16 even | `RAW` |
| 17–27 odd | `GND` | | 18–28 even | `GND` |
| 29, 33 | `IO_N` | | 30, 34 | `IO_N` |
| 31, 35 | `IO_P` | | 32, 36 | `IO_P` |
| **37** | **`Reset`** | | 38 | `VBSEL_A` |
| **39** | **`DONE`** | | 40 | `VBSEL_B` |
| **41** | **`Program`** | | 42 | `A1V8` |
| **43** | **`TDI`** | | 44 | `AVP` |
| **45** | **`TDO`** | | 46 | `AVN` |
| **47** | **`TMS`** | | 48 | `AREF` |
| **49** | **`TCK`** | | 50 | `AGND` |

Everything the board needs is here, and more than just the four JTAG pins:

- **`Program` (41)** — force a reconfigure rather than relying on JTAG state alone.
- **`DONE` (39)** — read back whether a push actually took. Without it the ESP32
  cannot tell the host a configuration succeeded, and a JIT loop would be debugging
  HDL when the load silently failed.
- **`Reset` (37)** — a clean way back to a known state.
- **`+3V3` on eight pins, `RAW` on eight** — take either rail.
- **Four spare `IO_N`/`IO_P` pairs (29–36)** — a side channel between ESP32 and
  fabric that costs nothing from Bank A or Bank B.

**`INIT_B` is NOT on J3.** It exists on the FPGA (U12) but does not reach the
connector, so the init/clear phase cannot be observed. `DONE` is the completion
signal available, and the firmware should not assume more.

> ### ⚠ THE JTAG PINS MOVE IN REV B
>
> Alchitry's sheet carries this note verbatim in the Control column:
>
> **"Note: JTAG pins will change places to match Au with rev B"**
>
> The table above is **rev A**. A layout hard-wired to these numbers is wrong on
> rev B, and the failure is not obvious — TDI/TDO swapped is a chain that does not
> respond, which reads exactly like a dead ESP32 or a bad joint. This project has
> already lost days to that class of fault twice: the LVDS eye that looked like bad
> solder, and the chip-ID silence that was three hand-solder defects.
>
> **Confirm the board revision before committing a layout**, and prefer a footprint
> that can be strapped, or a buffer whose pin order can be jumpered, over one that
> hard-wires rev A.

## 3b. A second path: SPI to the running design

J3 carries **four spare FPGA I/O pairs — eight signals — and the current designs use
none of them.** Decoded from sheet 3 of the Rev A schematic (Altium doubles
characters in the PDF text layer; these are the de-doubled net names):

| J3 pin | FPGA net | | J3 pin | FPGA net |
|---|---|---|---|---|
| 29 | `BANK14_L18_N` | | 30 | `BANK34_L5_N` |
| 31 | `BANK14_L18_P` | | 32 | `BANK34_L5_P` |
| 33 | `BANK34_L2_N` | | 34 | `BANK14_L23_N` |
| 35 | `BANK34_L2_P` | | 36 | `BANK14_L23_P` |

Two pairs on bank 14, two on bank 34. **These are the Pt's TOP-connector nets. In the card's
actual slot (below the Ft+, §1a), pins 29–36 are bank-34 `L1`/`L3`/`L6`/`L15` from the
bottom connector J8. Use §1a's table for constraints.** **SPI needs four signals** — SCK, MOSI, MISO,
CS — so half of them do the job and the other four are free for an interrupt, a
handshake, or flow control. They are differential-capable pairs, so LVDS is
available on the same wires if CMOS SPI ever proves too slow.

**Keep these two paths distinct, because they solve different problems:**

| | JTAG (§3) | SPI (here) |
|---|---|---|
| Talks to | the configuration engine | a design that is already running |
| Available | always, even with dead fabric | only once a bitstream is loaded |
| Used for | pushing a bitstream | exchanging data with it |

That second row is the point. Once a JIT image is configured, the ESP32 and the
fabric can move data directly — results out over WiFi without involving the host or
the Ft+ at all. For a compute module that is arguably worth as much as the
programming path.

**Unused today, confirmed:** nothing in `constrs_1/imports/RTL/*.xdc` references a
bank 14 or bank 34 pin, so the SLI and camera designs leave the control connector's
I/O entirely free.

> **This corrects the repo.** `CAMERA_IO_MAP.md:35` records J3's signal pins as
> "—", i.e. none. That extraction was aimed at Bank A/B and missed these four
> pairs; Alchitry's pinout sheet and sheet 3 of the schematic both show them.

### 3b.1 How fast, and what the eight signals should carry

**The wire is not the constraint; the C3's pin count is.**

GP-SPI2 runs to **80 MHz**, and the part has Dual and Quad SPI:

| Mode | Signals | Theoretical | Realistic sustained |
|---|---|---|---|
| Single-bit SPI @ 80 MHz | 4 | 80 Mbps = **10 MB/s** | ~8 MB/s |
| **Quad SPI @ 80 MHz** | 6 | 320 Mbps = **40 MB/s** | **~10–25 MB/s** |

The FPGA side is nowhere near its limit — Artix-7 I/O would go far faster. The
ceiling is the C3's GDMA, its single 160 MHz core, and 400 KB of SRAM to land in.
Note this is **3–6× the radio's ~4 MB/s**, so the local link is never what limits
anything leaving over WiFi — but it is real bandwidth for ESP32↔fabric work.

**Audio, as a worked case, is trivial:** 48 kHz × 24-bit stereo is 2.3 Mbps =
**288 kB/s**, about 1–3% of the link. Even 192 kHz × 32-bit × 8 channels is 6 MB/s
and still fits.

**But the GPIO budget does not.** The C3-MINI-1 has **15 GPIOs** — that is in the
datasheet title, not a derived number:

| Function | Pins |
|---|---|
| JTAG: TCK, TDI, TDO, TMS | 4 |
| `PROGRAM_B`, `DONE` | 2 |
| USB D+/D− (GPIO18/19) | 2 |
| SPI to FPGA | 4 |
| I2S microphone (BCLK, WS, SD) | 3 |
| **Total** | **15** |

Exactly at the limit — with no `Reset`, no margin, single-bit SPI only, and ignoring
that GPIO2/8/9 are strapping pins (GPIO9 is reserved for the §6.0 boot pad). In
practice it is over budget.

> ### Put sensors on the FPGA side, not the ESP32 side
>
> A microphone can sit **physically on this card** while its data lines run to J3's
> spare pairs rather than into the ESP32. That returns 3 GPIOs — but the better
> reason is **timing**.
>
> Audio in this system will want to be aligned with camera frames or projector
> vsync, and **the FPGA owns those clock domains**. Routing it through the ESP32
> inserts buffering and jitter and gives up sample-accurate alignment to the exact
> events worth correlating against. The FPGA can timestamp audio in the same domain
> it already timestamps vsync.
>
> A PDM MEMS mic needs **two wires** (clock out, data in); I2S needs three. A CIC
> decimator for PDM is a small amount of fabric. The ESP32 can still configure the
> part over I2C if it needs configuring.

**Proposed allocation of the eight signals** — six used, two in reserve:

| J3 pins | Net | Use |
|---|---|---|
| 29 / 31 | `BANK14_L18_N/P` | SPI SCK, MOSI |
| 34 / 36 | `BANK14_L23_N/P` | SPI MISO, CS |
| 30 / 32 | `BANK34_L5_N/P` | PDM mic CLK, DATA |
| 33 / 35 | `BANK34_L2_N/P` | spare — IRQ, handshake |

If Quad SPI is wanted later it needs 6 signals, which costs the spare pair and the
mic has to move to a pair shared with something else. Single-bit SPI at 80 MHz is
already 2× the radio; take quad only if the ESP32 is doing local processing.

**Two things to confirm before relying on it:**

- **Bank VCCO.** ESP32-C3 GPIO is 3.3 V. Bank 14 is almost certainly 3.3 V, but
  bank 34's rail is unverified here, and the Pt's `VBSEL` mechanism can switch a
  bank to 2.5 V. Check sheet 6, LINEAR REGULATORS, before committing.
- **The bank-16/34 naming caveat.** Alchitry's own product page warns that "the
  names of signal on bank 16 and bank 34 are swapped in the schematic. This makes no
  functional difference but may be confusing." Treat `BANK34` as a label, not a bank
  number, and **constrain by package pin**.

## 4. What the schematic settles

From `docs/Alchitry_Platinum_RevA_schematic.pdf`, **sheet 8 "FTDI PROGRAMMING"**.
These two findings are why this board is straightforward rather than delicate.

### 4.1 JTAG is at 3.3 V — no level shifting

The JTAG and configuration pins are all on **bank 0**, the dedicated configuration
bank: `TCK_0` (V12), `TDI_0` (R13), `TDO_0` (U13), `TMS_0` (T13), `PROGRAM_B_0`
(N12), `INIT_B_0` (U12), `DONE_0`, `CFGBVS_0`. `VCCO_0` and the `PROGRAM_B` /
`DONE` pull-ups all sit on **+3V3**.

**ESP32 GPIO drives these directly.** No translator, nothing extra in the fast
path.

### 4.2 The FT2232H is isolated by 100 Ω — contention is survivable

**`RN2` is a 100 Ω series resistor array** between the FT2232H's ADBUS pins and the
`TCK` / `TDI` / `TMS` nets. That is the most useful thing on the sheet.

- A hard fight — FTDI driving high, ESP32 driving low — is limited to
  3.3 V / 100 Ω ≈ **33 mA**, which both parts survive. The board cannot destroy
  itself if both ends drive at once.
- In practice there is no fight: the FT2232H's MPSSE pins are high-Z unless a USB
  host has the interface open, so with no cable attached the ESP32 owns the bus.
- **`TDO` is an FPGA output** feeding the FTDI's input, so the ESP32 only ever
  reads it. No contention on that line at all.
- **Survivable is not the same as working.** With the original 33 Ω straps, an ESP32
  pulling low against an FTDI still driving high gives the FPGA
  3.3 × (≈15 + 33) / (≈15 + 33 + 100) ≈ **0.8 V**: at VIL(max), so JTAG would be
  unreliable exactly when the FTDI has been left in MPSSE by a loader run. The
  TCK/TMS/TDI straps (R10–R12, and rev B R14–R16) are therefore **0 Ω** (≈0.3–0.4 V);
  the TDO straps (R13/R17) keep 33 Ω. Changed at order time, 2026-09-30.

**So a mux is a robustness choice, not a requirement.** Direct connection works. A
buffer with an output enable is still the better build — it makes "USB cable wins"
explicit rather than emergent — but the design is not blocked on it, and a first
prototype can go direct.

## 5. Programming modes

| Mode | What it is | Use |
|---|---|---|
| **XVC over WiFi** | ESP32 presents as a Xilinx Virtual Cable on a TCP port; Vivado connects and programs as though the part were local | development, debug, ILA |
| **Standalone push** | bitstream streamed over WiFi and clocked straight in | the JIT path, no PC tooling in the loop |
| ~~QSPI boot flash~~ | writes the persistent image | **excluded** — see §2 |

XVC is worth having even though the JIT path does not need it: it makes Vivado's
own tools, including hardware debug, work over the air — which is what you will
want the first time a pushed image misbehaves.

**Timing.** The merged Pt bitstream is **2.46 MB = 19.7 Mbit**
(`build_merged/Au2_SLI_merged.bin`). Bit-banged at 1 MHz TCK that is ~20 s; driving
TCK/TDI from the ESP32's SPI peripheral at 10 MHz brings it to ~2 s. The compile
dominates the JIT loop either way.

## 6. Remaining design problems

### 6.0 No USB connector — pads instead. DECIDED

**The board carries no USB receptacle.** Firmware reaches the ESP32 by a pad field
for the first flash, and by OTA thereafter.

The module makes this cheap: the **ESP32-S3** (like the C3 this section was first
written for) has a **native USB Serial/JTAG controller**, so there is no bridge chip
to justify — `GPIO19 = USB_D−`, `GPIO20 = USB_D+` go straight to a host. The classic
UART bootloader is also available on `GPIO43/44` (U0TXD/U0RXD) as a fallback.

A connector was rejected on the edge budget, not the parts cost. The stack already
presents **two HDMI and two USB-C** (Pt config, Ft+ data), and the printed enclosure
has exactly **one port window**. A fifth connector means another opening to cut and
seal — in a design whose entire purpose is that a *sealed* unit can be
reprogrammed.

**As built (S3):** 1.0 mm pads TP1–TP8 on the top face, in a row at y = 103.4
(board edge), verified pad-to-pin against the S3-MINI-1U datasheet on 2026-09-30:

| Pad | Net | U1 pin | Why |
|---|---|---|---|
| TP1 | `+3V3` | 3 | bench power when the card is out of the stack |
| TP2 | `GND` | GND | return |
| TP3 | `USB_DP` | 24 (GPIO20) | native USB, first flash |
| TP4 | `USB_DN` | 23 (GPIO19) | " |
| TP5 | `ESP_EN` | 45 | reset into the bootloader |
| TP6 | `ESP_BOOT` | 4 (GPIO0) | boot strap — hold low at reset to force download mode |
| TP7 | `ESP_TXD0` | 39 (GPIO43) | UART0 fallback |
| TP8 | `ESP_RXD0` | 40 (GPIO44) | " |

GPIO0 relies on the module's internal pull-up; a stray download-mode boot from noise
on the ~35 mm trace to TP6 is possible in principle (an external 10k is a next-rev
option). **Caveat:** the pads are on the face that sits under the Ft+ (≈4 mm gap), so
they are reachable for the first flash out of the stack, not from inside it — the
in-stack path is OTA.

**The recovery story is OTA with A/B partitions and rollback.** That is the same
philosophy as §2: do not try to prevent a bad update, make it recoverable. Rollback
is the ESP32's equivalent of the power-cycle that restores the FPGA. The residual
risk is a bootloader-level mistake that rollback cannot catch — that one needs the
pads, which is why they exist and why their placement matters.

> If a real port is ever wanted, it does fit: a USB-C receptacle is ~3.2 mm against
> the 4.125 mm gap. It would have to sit at the **W edge** to line up with the base
> box's existing port window — the same end where the lens box seam is now filled.

### 6.1 Bitstream storage
> **Superseded by `SD_BITSTREAM_LIBRARY.md` (2026-09-13):** a microSD library on the
> card, reported and loaded through an MCP server on the ESP32. It also proposes moving
> to the ESP32-S3-MINI-1U, since microSD does not fit the C3's GPIO budget.

2.46 MB does not sit comfortably in a 4 MB module beside an application. Either an
8/16 MB module, or **stream over WiFi and never store it** — which keeps versioning
on the server and leaves no stale image to load by accident.

### 6.2 Power
The 3V3 rail is a **4 A** supply (`CAMERA_POWER_DESIGN.md:300`), so the ESP32's
average draw is irrelevant. Its WiFi TX peaks are fast transients, though: **local
bulk capacitance on this card**, not borrowed from the Pt's decoupling.

### 6.3 Mechanical budget — SETTLED

The DF40 stack sets **4.125 mm** board-surface to board-surface with the spacer in
place: `(24.50 − 5 × 1.60) / 4`, against the connector's 4.0 mm nominal. Before the
spacer it was 4.200 mm over three gaps, so the two derivations agree.

**The Ft+ has no components on its underside** (inspected on the assembled stack),
so the whole gap above this board is available.

| | |
|---|---|
| Gap to the Ft+ above | **4.125 mm**, all of it usable |
| **ESP32-MINI-1 / C3-MINI-1**, on the **top** face | 2.4 mm |
| Clearance remaining | **1.725 mm** |

That is a comfortable fit, and the MINI series is the right pick over a WROOM
(3.1 mm) — 0.7 mm is a large fraction of a 4 mm budget for identical silicon.

**The bottom face IS now budgeted, from Alchitry's Hd STEP (2026-09-16).** The card sits
above the Hd (§1a), so its bottom face looks down on the Hd's top side across the same
4.125 mm gap. `hd_clearance.py` measured the Hd and wrote `mech/hd_top_clearance.png`.

| Hd top-side part | Board position (mm from corner, y down) | Height | Clearance for the card's bottom face |
|---|---|---|---|
| 3 × DF40HC(4.0) receptacles | the element sites | 3.90 | 0.22 (these mate with the card's plugs) |
| **2 × HDMI connectors** | **x 0.2–7.8, y 19.2–25.8 and 31.7–38.3** (left edge) | **2.97** | **1.15** |
| IC, 3.4 × 3.2 | x 25.3–28.7, y 14.9–18.1 | 1.45 | 2.67 |
| 2 × 2.2 × 2.1 parts | (12.1–14.3, 22.8–24.9), (11.4–13.6, 39.0–41.1) | 1.10 | 3.02 |
| everything else | — | ≤ 0.90 | ≥ 3.22 |

So away from the two HDMI connectors, **there is at least 2.67 mm under the card
everywhere**. That fits 0805 caps (~1.3 mm), SOT-23 (~1.1 mm) and TSSOP (1.2 mm) with
margin. **Keep the bottom face clear over the HDMI footprints. DONE:** `add_hdmi_keepout.py` puts a
B.Cu rule area (no footprints; tracks and vias allowed) at x 0–9.5, y 17.5–40, which is both
connectors plus 1.5 mm, out to the left edge. DRC enforces it (tested by moving a footprint
inside). 1.15 mm is marginal even
for a 0402, and a mated HDMI plug's shell may need more. Measure a plugged-in cable before
using that area.

> **How the STEP was read.** The raw point cloud *is* unusable: it spans −13.71 to +19.20 mm
> because it carries axis placements and construction geometry. `check_step.py` also rejects
> Alchitry's face winding. So KiCad tessellates the file instead: it's attached as a
> dummy footprint's 3D model and exported with `kicad-cli pcb export stl`, so only real faces
> survive. The mesh is exactly 55 × 45 mm, the board surfaces are at z 1.52 / 3.12, the plugs
> below reach 1.1 mm, and the tallest part above is 3.90 mm, matching Hirose's D = 3.9. The
> three receptacles land on the element-standard positions, which fixes the frame
> (y = 45 − y_model). **This is Alchitry's CAD, not calipers.** A quick caliper check of the
> HDMI connector height on real hardware is still worth doing.

### 6.4 RF, and the aluminium shroud
A 2.4 GHz radio is going inside a stack with 720 Mbps LVDS, DDR3 and HDMI TMDS —
noise in both directions.

**Choosing the MINI on the top face makes this the binding constraint, not the
mechanical one.** The board fits easily; the antenna is the part that does not.

- The `-MINI-1` variants carry a **PCB antenna** at one end. That antenna would sit
  **4.125 mm below the Ft+'s ground plane**, with the Hd+'s plane below it — a
  patch antenna sandwiched between two copper planes a few millimetres away. It
  will detune and lose most of its efficiency. This fits and does not work.
- **The CNC aluminium shroud ring would then sit around it as well**, which no
  firmware can fix.

**DECIDED: external wired antenna — the `U` variant, `ESP32-C3-MINI-1U`.** The
PCB-antenna part is not viable in this stack, and the wired antenna is the right
answer rather than a workaround: it is the only version whose radiating element can
be placed where neither the two ground planes nor the aluminium ring surround it.

**The height works out, confirmed from the datasheet** (`docs/esp32-c3-mini-1_datasheet.pdf`,
Table 1 and the §7.1 side views):

| Variant | Dimensions | Antenna |
|---|---|---|
| ESP32-C3-MINI-1 | 13.2 × 16.6 × **2.4** mm | PCB antenna |
| **ESP32-C3-MINI-1U** | 13.2 × **12.5** × **2.4** mm | external connector |

Both side views state **2.4 ± 0.15 mm**, so the connector is inside the module
envelope — Espressif use a low-profile third-generation antenna connector, not a
standard full-height u.FL. Against §6.3's 4.125 mm gap that leaves **1.725 mm**,
unchanged from the PCB-antenna part. The `-1U` is also **4.1 mm shorter** (12.5 vs
16.6), since the antenna keep-out area is gone — free board area on a small card.

**What is still unverified: the MATED height.** The datasheet's 2.4 mm is the
module alone. A plug pushed onto that connector, plus the coax bend radius, sits
above it, and 1.725 mm is not much to give away. Two mitigations, both cheap to
adopt now:

- **Place the module so its connector end faces the board edge**, so a plug can
  overhang the stack outline rather than fight the Ft+ above it.
- **1.13 mm coax routes laterally within the gap without trouble** — it is the
  vertical mating stack-up, not the cable, that is at risk.

Measure a mated plug before committing the placement. If it does not clear,
soldering the coax directly to the RF pads removes the connector height entirely at
the cost of serviceability.

### 6.5 Mechanical
A true pass-through element card — DF40 top *and* bottom — to preserve the stack,
exactly as the GPIO board it replaces. The 5.5 mm it occupies is already carried in
the 24.5 mm stack height and the lens box skirt
(`LauPythonCamera_Pt_Stack/mech/gen_lens_box.py --pcb-t 7.1`).

## 7. Source documents (`docs/`)

Downloaded 2026-09-02. **None of these are committed** -- see `docs/.gitignore`.
They are vendor documents, they total ~135 MB, and every number in this README is
sourced to a named sheet, page or table below, so the analysis stands without them.
Fetch them again with the URLs here.

| File | Source |
|---|---|
| `Alchitry_Platinum_RevA_schematic.pdf` | `cdn.alchitry.com/docs/Pt-V2/Alchitry Platinum Rev A.pdf` |
| `Alchitry_Platinum_v2.step` | `cdn.alchitry.com/docs/Pt-V2/Alchitry Platinum v2.step` |
| `Pt_V2_pinout_trace_lengths.csv` | "Pinout and Trace Lengths", linked from the Pt V2 product page |
| `FtPlusSchematic.pdf` | `cdn.alchitry.com/docs/Ft-V2/FtPlusSchematic.pdf` |
| `FtPlus.step` | `cdn.alchitry.com/docs/Ft-V2/FtPlus.step` |
| `HdSchematic.pdf` | `cdn.alchitry.com/docs/Hd-V2/HdSchematic.pdf` |
| `Hd.step` | `cdn.alchitry.com/docs/Hd-V2/Hd.step` |
| `esp32-c3-mini-1_datasheet.pdf` | Espressif, ESP32-C3-MINI-1 / 1U datasheet |

Sheet map: **3** TOP CONNECTORS · **4** BOTTOM CONNECTORS · **5** ARTIX DECOUPLING ·
**6** LINEAR REGULATORS · **8** FTDI PROGRAMMING.

**Use Rev A, not "First Batch."** A separate `Alchitry Platinum Rev A - First
Batch.pdf` sits on the same CDN path; it is the pre-production drawing and reports
7,880 pages against Rev A's 9.

## 8. Status

| | |
|---|---|
| Schematic | **generated 2026-09-16**, straps revised 2026-09-30 — `SCHEMATIC.md`; ERC clean, all 17 BOM lines JLCPCB-stocked |
| Layout | **routed, DRC clean** — 4-layer, In1 GND / In2 +3V3, GND pours both faces, 474 vias 0.45/0.20 |
| Fab | **ORDERED 2026-09-30** from JLCPCB, Standard PCBA both sides. Upload set in `production/jlcpcb/` (see below) |
| Firmware | not started |
| Electrical unknowns | **none** — J3 mapped, 3.3 V confirmed, FTDI isolation confirmed |
| Module | **ESP32-S3-MINI-1U-N8** (decided 2026-09-16, supersedes the C3) — external wired antenna, top face |
| Antenna | external, routed outside the aluminium shroud (§6.4) |
| SPI to fabric | 4 spare I/O pairs on J3 29-36, unused today; ~10 MB/s single-bit (§3b) |
| GPIO budget | S3: 29 used, 7 spare, 3 straps left NC (`SCHEMATIC.md` §6). The C3's 15-pin limit in §3b.1 no longer applies |
| USB | **no connector** — USB_D+/D- (GPIO20/19), EN, GPIO0, UART0, GND, +3V3 as pads TP1-TP8; OTA after (§6.0) |
| microSD library | **in the schematic** — Molex 104031-0811, SDMMC 4-bit |
| JTAG rev A/B | rev A wired; rev B by moving 4 strap resistors (`SCHEMATIC.md` §4). TCK/TMS/TDI straps 0 Ω, TDO 33 Ω (§4.2) |
| Next | bring-up when boards arrive; before that, measure a mated U.FL plug (≈2 mm est. vs ≈1.6 mm above the module) and confirm the Pt is rev A |

### 8.1 The JLCPCB order (2026-09-30)

`production/jlcpcb/` is **exactly what was uploaded**: `_gerbers.zip` (13 files, KiCad
10.0.3, generated twice and compared), `_BOM.csv`, `_CPL.csv`.

- **CPL rotations are corrected for JLC's library**, not KiCad's: Q1/Q2 0 (KiCad 180),
  U2 270 (KiCad 0), J7 270 (KiCad 90). Found by fitting each LCSC part's EasyEDA
  footprint to the KiCad one. Regenerating the CPL from `kicad-cli pcb export pos`
  loses these — re-apply them.
- **Order settings:** Single PCB (JLC adds the edge rails, as on the camera card — the
  board is under their 70 × 70 mm PCBA minimum); 4 layers, 1.6 mm, ENIG; min via
  0.2 mm (JLC then forces FR4 TG155 + 4-wire Kelvin test); **Epoxy Filled & Capped**
  vias — 7 vias sit inside SMD pads and 134 merge with a pad edge (J4–J6, U1) with the
  hole 0.05–0.10 mm outside a 1:1 mask opening; Confirm Production File and Confirm
  Parts Placement both on.
- **Pre-order review (four independent checks) found no blocker:** U1 land pattern and
  all 65 pins against the S3-MINI-1U datasheet; J1–J6 against Alchitry's official V2
  element library (positions, genders, 210-pad pass-through); the JTAG / PROGRAM_B /
  DONE / microSD / power circuits against the Pt Rev A schematic; JLC DFM limits.
  Open: the DF40HC receptacle footprint is KiCad/Alchitry-official but not yet built
  on one of our boards; D1's EasyEDA pad numbering is swapped (cathode = GND pad).

**Long-term goal — [`COMPUTE_RING_PLAN.md`](../COMPUTE_RING_PLAN.md):** the camera
stacks as a ring of FPGA compute nodes that LLMs hand work to over MCP — host data over
the Ft+, control over this card's WiFi, node to node over the HDMI ports. It is still
separate work from getting a bitstream into the part, but it raises the stakes on two
choices here: the SPI side channel (§3b) becomes the path for loading kernels without
breaking the ring, which strengthens the C3 → S3 case in `SD_BITSTREAM_LIBRARY.md`.

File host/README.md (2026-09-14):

# AuV2-SLI host tools

Two things live here, and they speak to the board over **different transports**.

## 1. Python tools over the Ft+ (USB 3) — the current interface

Everything the host does with the merged design goes through
[`ftlink.py`](ftlink.py), which implements the `0xA5` control plane and the camera
opcodes over D3XX. Register and opcode reference: [`../FTPLUS_API.md`](../FTPLUS_API.md).

| Tool | What it does |
|---|---|
| `ftlink.py` | The transport. `send_bytes` (0xA5 protocol), `send_word` (camera opcodes), register and table read/write |
| `usb_speed.py` | **Run this first when anything looks slow.** Reports the enumerated USB speed *and* measured throughput — a USB 2 cable in a USB 3 port looks identical from the outside and costs 4x |
| `diag_reply_stall.py` | **Why Ft+ replies stop when the camera does.** Idles the camera, retries Port B replies, and reads `0x3B` over Port A to say which side of the FT601 holds the bytes |
| `max_exposure.py` | Asks the FPGA the longest exposure usable at the current frame rate, and optionally applies it |
| `measure_vsync_period.py` | Display frame period and its jitter, at 10 ns (genlock G0) |
| `measure_trigger_latency.py` | Trigger to exposure-start delay and its jitter, from the sensor's own monitor pin |
| `measure_exposure_gap.py` | Sweeps exposure to find the constant inter-exposure gap and the readout floor |
| `test_m6c_silicon.py` | The full control-plane test over D3XX — registers, all three tables, EDID |
| `test_m6a_ctlpath.py`, `test_m6a_under_load.py`, `test_m6b_reply.py` | Control-plane bring-up, command and reply directions |
| `test_3b_cameraidle.py` | M3/3b — idle the camera, prove HDMI does not notice |
| `soak.py`, `stress_attack.py` | Long-run and adversarial tests |
| `read_cam_status.py`, `dump_edid.py`, `read_mode.py`, `force_mode.py`, `upload_corr.py` | Point tools over the serial port |

### Why several of these read over the serial port on purpose

Port A is not legacy. It is the **independent witness**: a test that measures the
camera over the same link whose traffic it is disrupting cannot distinguish the two.
This matters concretely — the Ft+ reply path currently goes silent whenever the
frame stream stops, so anything that wedges or idles the camera also stops USB 3
readback. See the known limitation in [`../FTPLUS_API.md`](../FTPLUS_API.md).

## 2. The Qt linearisation app — NOT yet migrated

A minimal Qt app that coordinates a **Basler USB camera** with the SLI FPGA to
measure the projector response, build an **8-bit intensity correction
(linearisation) table**, and upload it over USB.

> **It still speaks `QSerialPort` at 115200 baud.** Moving it to D3XX is the
> outstanding half of merge milestone M7 — the soak half passed, the host migration
> did not start. Everything below describes the app as it stands.

The FPGA renders the *linearised* sinusoid on the fly: it reads the cosine amplitude
from its pattern table and passes it through the uploaded correction table —
`out = corr[cos_sample]` (see `../ctrl/sli_lut.v`, TARGET `0x02`). The correction is
**intensity→intensity**, so it is resolution-independent; the resolution-dependent
cosine period stays in the FPGA's pattern LUT.

## What got ported

Brought over from `LAU3DVideoRecorder/LAUMultiPathRecorder` (bare minimum only):

| File | Role |
|---|---|
| `laumemoryobject.{h,cpp}` | core buffer / TIFF data type (unchanged) |
| `laubaslerusbcamera.{h,cpp}` | Basler USB capture + mean-pixel measurement (unchanged) |
| `lautonecorrectionwidget.{h,cpp}` | builds the inverse-response (tone) curve (unchanged) |

New, written for this repo:

| File | Role |
|---|---|
| `lauauboard.{h,cpp}` | **USB interface to the Au** — `0xA5` register R/W + correction-table upload (TARGET `0x02`). Protocol mirrors `../tools/uart_ctrl.ps1` / `../ctrl/uart_ctrl.v`. |
| `lauslicalibrationdialog.{h,cpp}` | wires camera → tone curve → upload; full-screen ramp window |
| `main.cpp`, `AuV2SLIHost.pro` | entry point + qmake project |

The old Mojo uploader (`laumojoboardwidget`, `laulookuptablewidget`, `qcustomplot`)
was **not** ported — it spoke a different serial protocol and baked the linearised
sinusoid into the pattern table. This design keeps the pattern cosine in the FPGA and
uploads only the 256-byte correction curve.

## Build

Prerequisites: Qt 5.15+/6 (with the **serialport** module), **libtiff**, and the
**Basler pylon** SDK. Edit the include/lib paths in `AuV2SLIHost.pro` to match your
install (the Windows block assumes `C:/usr/Tiff` and `pylon 8`).

```
qmake AuV2SLIHost.pro
make                 # or nmake / jom on Windows
```

Build without a camera (UI + board upload only): `qmake CONFIG+=nobasler`.

## Workflow

1. **Connect the board** — pick the FT2232 COM port, *Connect*. Confirms `ID=0x48`.
2. **Connect the camera** — opens the first Basler USB camera.
3. **Show ramp window** — pick the projector screen; a full-screen gray field appears.
4. **Run linearisation sweep** — for gray 0…255 the app shows the level, waits the
   *settle/display latency*, grabs one frame, and records the camera's mean pixel,
   producing the inverse-response curve in the tone widget.
5. **Upload correction to FPGA** — sends the 256-byte table (`A5 5B 02 …`). The Au
   replies `K`; the projected fringes are now linearised.

`Reset correction (identity)` restores `corr[i]=i` (no linearisation). `Save/Load
(.tcc)` persist a curve.

## Notes / to verify on hardware

- **Trigger topology is hardware-dependent.** With *HDMI/line trigger* checked the
  camera waits for its Line1 trigger (projector/Au VSYNC); unchecked, the camera
  drives its own output line. Match this to how the Basler trigger lines are wired to
  the Au `cam_pace` GPIO, and tune the *settle/display latency* to the projector lag.
- The camera config in `laubaslerusbcamera.cpp` (ROI, binning, 10-bit mono, exposure)
  is inherited unchanged from the source project — adjust for your sensor/projector.
- The FPGA `lut→corr` read path is two cascaded async RAM reads; confirm it closes
  timing in synthesis (noted in `../ctrl/sli_lut.v`).

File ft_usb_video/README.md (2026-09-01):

# ft_usb_video — FT601 USB-3 video throughput test (Pt V2 + Ft+)

> **STATUS: this subproject answered its question and was absorbed.** The FT601
> datapath proven here is now part of the merged design (`build_merged.tcl`), where
> `cam_frame_ft` carries the camera, DDR3 ring and Ft+ together with the HDMI/SLI
> path. The measurements below stand; the *separate build* does not need running
> again. Current interface: [`../FTPLUS_API.md`](../FTPLUS_API.md).

**Goal:** answer "how many 1280×1024 frames/second can we push over the Ft+ (FT601Q)
USB-3 port?" — by generating real SLI video on the FPGA (the same phase-shifting
cosine fringes the HDMI path emits) at the **PYTHON 1300 raster**, streaming it out
the FT601, and grabbing/displaying it on the PC while measuring MB/s and FPS.

This is the first thing that moves **real data** across the Ft+. The stack I/O check
(`../LauPythonCamera_Pt_Stack/iocheck/`) only proved the Ft+ pins *place*; it moved
nothing. Everything here reuses those exact, already-proven pins.

```
  sli_frame_gen  (PIX_FMT=1) ─┐
   8-bit SLI fringes, 4px/word │──▶ ft601_sync_tx ──245 sync FIFO──▶ FT601 ──USB3──▶ PC
  raw10_test_gen (PIX_FMT=3) ─┘     (FPGA = master,                    ft_video_grab.py
   packed 10-bit, 16px/5words        IOB-registered bus)               ft_video_snap.py
```

## Files

| File | What |
|---|---|
| `rtl/sli_frame_gen.v` | 1280×1024 cosine-fringe frame source, 8-bit mono, 4 px / 32-bit word, 8-word framing header |
| `rtl/ft601_sync_tx.v` | FT601 **245-Synchronous-FIFO** write master (FPGA is the master, `ft_clk` = 100 MHz) |
| `rtl/raw10_test_gen.v` | packed 10-bit (MIPI RAW10) pixel-index counter, 16 px / 5 words — the bandwidth/integrity pattern |
| `rtl/ft_video_top.v` | top: `PIX_FMT` selects the source, wires generator → master → FT601 pins; single `ft_clk` domain |
| `build/run_ftvideo.tcl` | Vivado batch build → `out/ft_video.bit` + `out/ft_video.bin`, **+ FT601 IOB/timing assertions** |
| `host/ft_video_grab.py` | D3XX throughput meter, **headless**: FPS/MB-s framed, or `--raw` unframed. Also the home of `FtDevice` / `FrameAssembler` / `unpack_raw10` |
| `host/ft_video_snap.py` | **byte-exact verifier**: recomputes the RTL pattern and diffs every pixel; writes PNGs (stdlib only) |
| `host/ft_diag_rows.py` | corruption forensics: per-column consensus, error rate, byte-lane / offset histograms |
| `host/ft_bench_async.py` | zero-copy / overlapped throughput bench — `--sweep` (size×depth), `--stall` (consumer freeze). **Found the 348 MB/s ceiling.** |
| `host/cam_live.py` | **THE VIEWER** — the only one. tkinter; exposure slider, sync-to-projector checkbox, trigger-delay slider |
| `host/requirements.txt` | `ftd3xx`, `numpy`, `pillow` |

### Live camera tools (`cam_frame_ft` — the DDR3 ring build)

| File | What |
|---|---|
| `host/campack.py` | **Shared**: header parsing, frame iteration, and the packed-10 unpacker. Consumers **switch on the format field** — reading packed bytes as `u16` does not fail loudly, it paints a plausible wrong picture |
| `host/cam_live.py` | live viewer. Preview follows the window (aspect preserved); exposure slider capped at the frame period and applied on release; **Save TIFF** writes the on-screen frame as raw 10-bit counts in a 16-bit TIFF; status line carries `ldrop` growth and saturation % |
| `host/cam_ctl.py` | runtime control: exposure (`--us`), frame rate (`--fps`), frames per scan, re-arm |
| `host/ring_check.py` | ring integrity: frames must be **CLEAN** (no padding), **FRESH** (`frame_idx` advancing) **and cost no kernels** (`ldrop` static). None of the three is sufficient alone |
| `host/row_align_check.py` | **do delivered frames agree with each other?** Correlates row profiles; a matching alignment must peak at zero shift. This is what caught the rolling-frame bug |
| `host/drift_check.py` | kept mainly for its docstring: correlating the RAW pixel stream locks onto the 8-px kernel de-interleave pattern and returns a confident, meaningless shift that is always a multiple of 8 |
| `host/expo_check.py` | proves exposure is settable **at runtime** and the response is monotonic; reports saturation, since a frame pinned at full scale looks stable and proves nothing |
| `host/test_campack.py` | round-trips the packed-10 layout against a transcription of the RTL wires, including full-scale values where a dropped low bit would hide. `python test_campack.py` |

## The numbers to expect

The FT601 in 245-sync FIFO mode clocks 32 bits at 100 MHz. Measured on this
Pt V2 + Ft+ + host. **The headline number is 348 MB/s** (`ft_bench_async.py`,
zero-copy); the `ft_video_grab.py` figures below are ~12 % lower because that
reader copies every buffer — see the resolved note after the table:

> ### ⚠️ 348 MB/s IS A BARE-LINK NUMBER. DO NOT BUDGET A CAMERA AGAINST IT.
>
> Everything on this page is the FT601 fed by a **pattern generator** — no sensor, no
> DDR, nothing else touching the memory controller. That is the right way to find the
> *link's* ceiling, and 348 MB/s is a real ceiling.
>
> It is **not** what a running camera gets. With capture into the DDR3 ring active, the
> same `ft_bench_async.py` measures **231.7 MB/s** (2026-08-17), because the reader is
> now sharing one MIG command port with the capture writer. Sampled while saturated,
> both ends were limiting at once: the DDR→USB FIFO ran dry 32 % of the time **and**
> the FT601 back-pressured 40 %.
>
> Budgeting against 348 produced a build that targeted 120 Hz at 16 bpp — "314.6 MB/s,
> ~10 % margin" — and delivered **88 fps**. See
> [`../LauPythonCamera_Pt_Stack/README.md`](../LauPythonCamera_Pt_Stack/README.md)
> *Operating point*.
>
> **Two numbers, two purposes:** 348 MB/s bounds the link. **~232 MB/s** is the
> camera budget.

```
  theoretical ceiling   = 4 B × 100 MHz            = 400 MB/s  (3.2 Gbps)
  frame on the wire     = 32 B header + 1280×1024  = 1,310,752 B  (8-bit mono)

  MEASURED:
    --raw --stream --chunk 0x400000   309 MB/s  (2.47 Gbps)   77% of ceiling
    --raw          --chunk 0x100000   287 MB/s  (2.29 Gbps)
    --bench --stream --chunk 0x400000 252 MB/s  ->  192 fps,  0 dropped
    --bench        --chunk 0x100000   233 MB/s  ->  178 fps,  0 dropped
```

### Packed 10-bit (format 3) — the density the sensor actually produces

Built with `-tclargs 3`, measured the same day. **The MB/s is unchanged** (the link
does not care what the bytes mean); only bytes/frame, and therefore FPS, differ:

```
  frame on the wire     = 32 B header + 1280*1024*10/8 = 1,638,432 B  (1.638 MB)

    ft_bench_async.py, zero-copy      348 MB/s   ->  212 fps  (TRUE link ceiling)
    --raw --stream --chunk 0x400000   308 MB/s   ->  188 fps  (simple reader)
    --bench --stream --chunk 0x400000 255 MB/s   ->  156 fps,  0 dropped
```

**This is the result that matters for the camera:** 156 fps *through the current
un-optimized Python grabber* already clears the PYTHON 1300's 150 fps, and the link
itself has **212 fps** of headroom with a zero-copy reader — enough to cover even the
sensor's full 210 fps, though by only ~1 %, so treat that as marginal rather than
comfortable. Padding 10-bit into 16 (2 px/word) instead would
give only ~118 fps — **below** the sensor — so the packing is what buys the margin.

| | 8-bit mono (fmt 1) | packed 10-bit (fmt 3) |
|---|---|---|
| bytes/frame | 1,310,752 | 1,638,432 |
| link-ceiling FPS @ 348 MB/s (zero-copy) | **265** | **212** |
| link-ceiling FPS @ 308 MB/s (simple reader) | 236 | 188 |
| measured framed FPS (`--bench`) | 192 | **156** |
| dropped | 0 | 0 |
| LUTs | 980 | **230** |
| build WNS | 0.075 ns | 0.514 ns |

The 10-bit build is *smaller and faster to close* because it drops the 4096-entry
cosine ROM (~800 LUTs, read 4× per word). See "Choosing a test pattern" below.

### Frame rate by pixel format, at the measured 348 MB/s (1280×1024)

**MB/s is format-independent** — the FT601 moves 4 bytes per accepted word whatever
they mean, confirmed empirically (309 MB/s for the 8-bit build vs 308 for the 10-bit
build under identical conditions). So only bytes/frame changes, and FPS follows:

| format | bytes/frame | FPS @ 348 MB/s | status |
|---|---|---|---|
| 8-bit mono (`PIX_FMT=1`) | 1,310,752 | **265** | measured |
| packed 10-bit RAW10 (`PIX_FMT=3`) | 1,638,432 | **212** | measured |
| 10-in-16 padded (**16 bpp**) | 2,621,472 | **133** | *derived* — no bitstream for it |

**Padding 10 bits into 16 costs 37 % of the frame rate** (133 vs 212) purely because
6 of every 16 bits on the wire are zeros. Same MB/s, less payload.

What 16 bpp does and does not reach:

| target | rate needed @16 bpp | fits in 348 MB/s? |
|---|---|---|
| **120 fps** (one exposure per 120 Hz HDMI frame) | 314.6 MB/s | **yes — ~10 % margin** |
| 150 fps | 393.2 MB/s | no |
| 210 fps (sensor max) | 550.5 MB/s | no |

That 314.6 MB/s is the same figure `CAMERA_RTL_PLAN.md` already carries as the DDR
*write* rate at 120 Hz — so at the 120 fps operating point the USB drain and the DDR
fill are essentially matched.

**Which packing to choose depends on the mode, not on this table:**
- **Continuous streaming** — pack. 16 bpp caps at 133 fps; packed 10-bit clears 150 and
  just touches 210.
- **Burst-capture to DDR** — padding barely matters and 16-bit unpacked is arguably
  right (see `CAMERA_RTL_PLAN.md`): you never stream at sensor rate, 32 frames × 2.5 MiB
  = 80 MiB drains in **0.24 s**, and the packer disappears from the FPGA entirely.

Two things that matter when reading those:

- **`--stream` is worth ~24 MB/s**, and it plateaus by a 4 MiB chunk (16 MiB buys
  only ~1 MB/s more). Use `--stream --chunk 0x400000` for any real measurement.
- **The raw→framed gap (~57 MB/s) is the Python parse loop, not the link.**
  `FrameAssembler.feed` concatenates into a `bytearray` and `del`-slices it per
  chunk. That is a host software limit; the FPGA and USB are not involved.
- **✅ RESOLVED 2026-07-31 — the real ceiling is 348 MB/s, and 308 was our own
  memcpy.** The numbers above were suspected of being reader-limited; `ft_bench_async.py`
  settled it. `FtDevice.read()` does three size-proportional memory passes per
  transfer — `create_string_buffer` (allocate + zero-fill), `.raw` (copy whole
  buffer), `[:n]` (copy again) — none overlapped with the DMA. Removing them:

  | reader | MB/s | |
  |---|---|---|
  | fresh buffer + full copy per transfer (what `ft_video_grab.py` does) | 305 | baseline |
  | preallocated buffer, zero copies | **348** | **+14 %** |
  | + 8 transfers queued (async) | **349** | +14 % |

  **Queue depth turned out to be irrelevant to peak throughput** — 342 MB/s at depth 1
  with 256 KiB buffers, 348 at depth ≥2 with 4 MiB. The entire win was eliminating the
  host-side memory churn, not pipelining. 348 MB/s is **87 % of the 400 MB/s
  theoretical**, and data stays byte-exact at that rate (200/200 frames verified).

So at 8-bit the **USB link is not the bottleneck for the sensor** (PYTHON 1300 tops out
at 150 fps): 192 fps sustained leaves headroom. `--raw` gives the pure link rate;
`--bench` gives the rate after framing/drop-checking; the GUI shows the moving fringes.

## Verify correctness, not just speed

**Throughput alone will not tell you the link is working.** On 2026-07-30 this design
streamed 1280×1024 at 192 fps with *zero dropped frames* while silently corrupting
half of every pixel word — see the bug note at the end of this file. Always run:

```powershell
cd host
python ft_video_snap.py                # 400 frames, byte-exact vs the RTL model
```

Expected output on healthy hardware:

```
  format                                : packed 10-bit MIPI RAW10
  frame on the wire                     : 1,638,432 B (1.638 MB)  1280x1024
  frames matching the RTL byte-for-byte : 300
  frames with ANY mismatched pixel      : 0
  frame index gaps (dropped)            : 0
```

It auto-detects the format from the frame header, so the same command checks either
bitstream.

It also writes `snap_frq<q>_frm<m>.png` so the fringes can be eyeballed without any
GUI toolkit installed. If frames *do* mismatch, run `python ft_diag_rows.py` — it
prints an error histogram by byte lane (`x mod 4`) and by transfer offset, which is
what localizes the failure to specific data bits.

## Choosing a test pattern

`PIX_FMT` (a `ft_video_top` parameter, set with `-tclargs`) picks the stream source:

| | `1` — `sli_frame_gen` | `3` — `raw10_test_gen` |
|---|---|---|
| content | 8-bit SLI cosine fringes, 4 px/word | packed 10-bit RAW10, 16 px / 5 words |
| pixel value | 4096-entry cosine ROM | `(y*1280 + x) & 0x3FF` |
| use it to | *see* the link work (real picture) | measure the link at sensor density |

**For a pure bandwidth/integrity test, prefer format 3** — and not only because it
is smaller. A cosine is a *weak* signal-integrity pattern: adjacent samples differ
by a few counts, so the high data bits seldom toggle, which is exactly why the
`ft_data[31:16]` corruption stayed hidden. The counter sweeps all 1024 codes
continuously, so every data bit toggles at its maximum rate, and every pixel is
predictable in closed form.

## Build

Uses the same Vivado batch flow as `build_pt.tcl` (part `xc7a100tfgg484-2`,
single-threaded to dodge this host's `.tcl`-read race). From this folder:

```powershell
cd build
# 8-bit SLI fringes  -> out/ft_video.bin
vivado -mode batch -source run_ftvideo.tcl -log out/vivado.log -journal out/vivado.jou
# packed 10-bit RAW10 -> out/ft_video_raw10.bin
vivado -mode batch -source run_ftvideo.tcl -log out/vivado.log -journal out/vivado.jou -tclargs 3
```

Outputs are named per format, so both bitstreams coexist in `out/`. The build
prints, and **hard-fails on**:

```
=== FT601 IOB packing: 32/32 data flops + 1 WR# copy in OLOGIC ===
=== FT601 bus setup slack (clock-to-out vs FT601 window) = 0.514 ns ===
=== FT601 bus hold slack = 1.893 ns ===
=== TIMING: setup WNS = 0.075 ns ===
```

Do not "fix" a failure there by deleting the check — it is guarding a bug that
produces perfect-looking throughput and wrong pixels. See the bug note at the end.

> `write_bitstream` on this host occasionally dies with `EXCEPTION_ACCESS_VIOLATION`
> (a garbage `CH1_RXDATA[127:0]]` name string). That is a tool flake, not the
> design — just re-run the build.

## Flash (RAM — this is a test, don't burn flash)

```powershell
Alchitry.exe load --bin build/out/ft_video.bin --board PtV2 --ram
```

Use the Alchitry Labs V2 loader (2.0.52+), same one the Au flow uses. `--ram` is
temporary (gone on power-cycle), which is what you want while iterating.

LEDs: the top six LEDs count frames (a visibly faster blink = frames leaving faster);
the bottom two show FT601 write activity. All dark ⇒ no `ft_clk` (Ft+ not powered /
not in sync-FIFO mode) or the board is held in reset.

## Grab + measure on the PC

Prereqs: **FTDI D3XX driver** installed and the FT601 enumerating as a D3XX device
(not the D2XX/VCP serial driver). Then:

```powershell
cd host
pip install -r requirements.txt

python cam_live.py                     # LOOK at the camera (the one viewer)

python ft_video_grab.py                # MEASURE: parse frames, print fps + MB/s + drops
python ft_video_grab.py --raw          # pure read, link upper-bound MB/s
python ft_video_grab.py --stream --chunk 0x100000   # streaming pipe, 1 MiB URBs
```

> **One viewer, one measurer.** `ft_video_grab.py` is headless; it used to default
> to a controls-free PySide6 window, which was removed 2026-09-01. Only one process
> can hold the D3XX handle at a time, so a second viewer could only ever be the
> wrong one to have open. To see pixels, use `cam_live.py`.

- `--raw` vs `--bench`: `--raw` measures the driver+link with zero parsing (the true
  ceiling); `--bench` measures after framing/drop-detection. A big gap between them
  means the Python parse loop is the limit, not the link — try `--stream` and a larger
  `--chunk`, or move parsing off the read thread.
- **dropped > 0** in `--bench`/GUI means the host isn't draining fast enough (frame
  indices skipped), *not* an FPGA fault — the generator only advances when the FT601
  accepts a word, so it never overruns; drops are always host/USB-buffer side.

## How the FT601 write actually works (why the master is tiny)

245-sync FIFO, FPGA = master, everything on the FT601's `ft_clk`:

- `TXE#` low ⇒ USB buffer has room. A word on `DATA`/`BE` is taken by the FT601 on
  every rising edge where `WR#`=0 **and** `TXE#`=0.
- `DATA` and `WR#` are launched from **IOB flops**, so what the FT601 sees is a
  fixed Tco after the edge rather than a combinational path through the pattern
  ROM. This is not optional — driving them from logic is what corrupted the upper
  16 bits (see the bug note below).
- Registering the outputs costs a cycle, so `WR#` can no longer be a combinational
  echo of `TXE#`. Instead the master asks, at each edge, whether the word it was
  *already presenting* got taken: `accepted = ~wr_n_int & ~ft_txe`. Both terms are
  evaluated at the same edge the bridge uses, so the two chips can never disagree.
- If not accepted (`TXE#` went high), the master simply **holds and re-presents**
  the same word. The FWFT source has not been popped yet, so that hold *is* the
  skid buffer — no extra storage, and no word is ever lost or duplicated.
- The generator advances one word per accepted write, so generation is paced by USB
  back-pressure. That's what makes the measured FPS a clean link number.
- `OE#`/`RD#`/`BE` are static levels (TX only, all bytes valid), driven from
  constants — no per-cycle edge, so they need no IOB flop.

## Assumptions / gotchas

- **FT601 mode.** The Ft+ must be configured for **245 Synchronous FIFO @ 100 MHz**
  (that's why `ft_clk` is constrained to 100 MHz in `build/alchitry_pt_ft_plus_top.xdc`).
  Alchitry ships it this way; if `ft_clk` is a different rate or the chip is in
  multi-channel mode, reconfigure with FTDI's **FT60x Chip Configuration Programmer**.
  Read pipe is `0x82` (channel 0 IN).
- **Which connector the Ft+ is on decides the pin map.** In this stack the Ft+ sits on
  **top** of the Pt, so the build reads `build/alchitry_pt_ft_plus_top.xdc` (`ft_clk` =
  H4). The Pt's top and bottom connectors are independent banks with different FPGA
  pins: Alchitry's published `pt_ft_plus_bottom.xdc` maps the same element pin to D17,
  so using it with the board on top leaves `ft_clk` unconnected and everything reads
  FTCLK=0. If you ever move the Ft+ to the bottom, swap the XDC — and
  `build/diag/ft_clk_probe.v` will tell you which pin is live without a scope.
- **`ft_data` output timing — this WAS broken; see below.** The bus is now launched
  from IOB flops and the interface is constrained. `run_ftvideo.tcl` hard-fails the
  build if either regresses, so this should stay fixed.
- **`ftd3xx` API drift.** The wrapper's read call has changed across releases; the host
  tries `readPipe(pipe, buf, len)` then falls back to `readPipeEx`. If neither matches
  your version, adjust `FtDevice.read()`.

## Bug found and fixed: silent corruption of `ft_data[31:16]` (2026-07-30)

Recorded because the failure mode is nasty and easy to reproduce by accident.

**Symptom.** Everything that a throughput test measures looked perfect: 1280×1024
frames locked, headers valid, frame indices monotonic, **zero dropped frames**,
~192 fps sustained. But `ft_video_snap.py` — which recomputes what
`sli_frame_gen.v` *should* have emitted and diffs it — reported 400/400 frames
wrong, and `ft_diag_rows.py` localized it precisely:

```
errors by byte lane (x mod 4):  {0: 0, 1: 0, 2: 11419, 3: 25120}
```

`ft_data[15:0]` was byte-perfect; `ft_data[31:16]` was corrupt. The upper half is
exactly the group placed in the far bank (G4/H3/G3/P5/P4/P6/N5/M6/M5/L5/L4/K6/J6/
E2/D2/M3), whose longer launch path missed the FT601's ~1 ns setup window while
the near half made it. `ft_wr` (E3) lives in that same far bank but never
glitched — with `s_valid` tied high it goes low once and stays low, so it has no
per-cycle edge to violate. Only DATA toggles every clock, and only DATA broke.

**Two root causes, both required to hide it:**

1. `ft601_sync_tx.v` drove the pads combinationally (`assign ft_dout = s_word`),
   straight through the cosine ROM and phase adders. Huge, per-bit-variable
   clock-to-out.
2. The XDC had **no `set_output_delay`** — despite the module header claiming it
   did. With no output delay the FT601 interface was not in the timing graph at
   all, so Vivado never checked it, never warned, and reported a clean WNS.
   *An unconstrained path is not a failing path; it is an invisible one.*

**Fix.** Launch DATA/WR# from IOB (`OLOGIC`) flops, constrain the interface with
the FT601Q datasheet window (out: 1.0 ns setup / 1.0 ns hold; in: 7.0/1.0 ns), and
restore exactness with a registered handshake — `accepted = ~wr_n_int & ~ft_txe`
evaluated at the same edge the bridge uses, holding (re-presenting) the word when
it is not taken. The FWFT source is only popped on acceptance, so the hold *is*
the skid buffer; no extra storage is needed.

WR# needs two physical copies: an IOB flop's `Q` is not visible to the fabric, but
`accepted` reads WR# back. Vivado replicates this itself (`wr_n_pad_reg` in a
SLICE for the logic, `wr_n_pad_reg_rep` in `OLOGIC` driving the pin), which is why
`run_ftvideo.tcl` asserts on **placement, not on cell names**.

**After the fix:** FT601 bus setup slack **+0.514 ns**, hold **+1.893 ns**,
400/400 frames byte-exact, all 24 (frq,frm) states intact, throughput unchanged
at 309 MB/s raw / 192 fps framed — the fix costs nothing.

**Guards added to `run_ftvideo.tcl`** (the build now fails, loudly, on either):

1. all 32 data flops must be placed in `OLOGIC` sites, and WR# must have an
   `OLOGIC` copy driving the pad;
2. the data pins must have **at least one max-delay timing path** — zero paths
   means `set_output_delay` went missing again and the interface is untimed.

**Lesson for the rest of this project:** a source-synchronous output bus that is
not constrained will not fail timing, it will fail *silently on the wire*, and
only on the bits that happen to place far away. Any interface where we drive data
that another chip clocks in (FT601 here, the camera sensor links elsewhere) needs
both a registered launch and a real `set_output_delay` — plus a byte-exact
end-to-end check, because MB/s and drop counts cannot see this class of bug.

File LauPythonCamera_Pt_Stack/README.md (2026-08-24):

# LauPythonCamera_Pt_Stack — Design Blueprint

> **STATUS: the board works and is in the merged design.** The sensor is alive,
> aligned and streaming 1280x1024 at 120.000 Hz over the Ft+, concurrently with
> the HDMI/SLI datapath in one bitstream — see
> [`../MERGE_MILESTONES.md`](../MERGE_MILESTONES.md). This document remains the
> design blueprint for the PCB itself.
>
> Known hardware note: the Andon LCC48 socket is effectively unobtainable, so the
> sensor is held by a printed fixture clamping wires to the bottom castellations —
> see [`mech/README.md`](mech/README.md).

> ### Power: §§6.2 and 6.5 were rewritten on 2026-07-18 and now match the board.
>
> **[`../CAMERA_POWER_DESIGN.md`](../CAMERA_POWER_DESIGN.md) remains authoritative** for the
> power tree — full derivation, SPICE verification and BOM. This document is the design
> blueprint; where the two disagree, that one wins.
>
> **What changed, and why it matters historically.** The original power section described a
> "3.3 V tap through ferrites + load switch" tree, built on the premise that the Pt's `+3.3V`
> rail is 3.300 V. **It is 3.278 V** — derivable from Alchitry's own feedback divider
> (R16 = 31.6 kΩ / R15 = 10.2 kΩ into the ADP5052's 0.8 V reference), ±1.5 % → **3.229–3.327 V**.
> That broke the design three ways:
>
> - **`vdd_pix` (3.25–3.35 V) was out of spec** at the rail's low corner, by 21 mV.
> - **`vdd_33` had ~7 mV** of worst-case margin after ferrite and connector IR drop.
> - **The tap made correct power-up sequencing impossible.** `vdd_33` tapped from `+3V3` rises the
>   instant the Pt's rail does, but 1.8 V can only be made by LDO'ing *down from that same rail* —
>   so `vdd_18` always came up **after** `vdd_33`, the forbidden order, on every power-up. That
>   risks latch-up and a dead sensor.
>
> The board uses **boost → LDO**: `+3V3` → TPS61023 boost to 4.45 V → two TPS7A2033 LDOs for
> `vdd_33` and `vdd_pix`, `vdd_18` from a TPS7A2018 off `+3V3` directly, and **two TLV803S
> supervisors** enforcing power-up *and* power-down ordering. **There is no load switch and no
> ferrite on this board.** If you find text saying otherwise, it is stale — report it (§14.6).

Custom Alchitry **element board** carrying an onsemi **PYTHON 1300** global-shutter image
sensor in a **socketed 48-pin LCC**, for the AuV2-SLI structured-light system.

## Status

| | |
|---|---|
| Pin plan | ✅ **Confirmed by Vivado** (§13.1) |
| Whole stack — Pt V2 + Hd + Ft+ + camera | ✅ **Confirmed by Vivado** — 105 ports, no conflicts (§13.2) |
| Schematic | ⚠️ Complete and audited — but the **power tree was rebuilt from scratch** after an audit found it architecturally wrong (§6.5). **Deserves a human read before fab.** |
| Socket footprint | ✅ Built and verified (§12) — **no longer blocked** |
| Stackup / netclasses / DRC rules | ✅ Written (§11), and **calibrated against a real DRC run** (§14.7) |
| **Layout** | ✅ **Routed, reviewed (§14), DRC-clean (0 errors, 0 unconnected), and all three Tier 1 defects are FIXED** — re-verified against the board 2026-08-06. U1 decoupling closed by moving ten caps to the underside beneath the pins; power-section stitching now 13 GND vias; `+3V3_SYS` widened to 0.6 mm with the J3 pins fanned out. Six test points added. **Fab-ready** — two optional single-via redundancy items remain (§15.0), neither a blocker. |
| **Sensor + socket ordered** | ❌ **Do this first** — §15.1. Sensor: **~27-week** factory lead if distributor stock runs out — this is the critical path. Socket: **no stock anywhere**, Andon builds to order in **6–8 weeks**, so it is *not* the driver. |

**Eleven bugs have been found and fixed in this design so far**, including two that would have
destroyed the sensor and two that would have scrapped the board. Every one was a *boundary
crossed without re-deriving*: datasheet frame → KiCad frame, body extent → copper extent,
thermal question → voltage question, logic behaviour → electrical behaviour.

The FPGA side is tool-verified (§13). **The board side is verified only by my own arithmetic.**
The power section in particular has been rewritten and should be read by a human before copper.

---

## 1. What this board is for

The SLI system puts the FPGA **inline on HDMI between the host PC and the projector**
(hence the EDID-merge / HPD re-pulse logic in the main RTL). This board adds the *camera*
half: a 1.3 MP global-shutter sensor whose exposure can be synchronized to the projected
pattern sequence.

Because the camera must capture **in sync** with the projected patterns, HDMI pass-through
and camera capture run **simultaneously**. That constraint drives the entire pin plan below.

---

## 2. Board stack

```
   [ LauPythonCamera_Pt_Stack ]  <- THIS BOARD.  TOP, Bank B (B33-B78), bank 13, VCCO = 2.5 V
 ────────────────────────────────
          Alchitry Pt V2            XC7A100T-2FGG484I, 206 IO, 256 MB DDR3L
 ────────────────────────────────
   [ Sp ]    spacer — clears the Pt's bottom-side capacitors        $14.99
   [ Ft+ ]   bottom  A3-A42 + B3-B24   (3.3 V)   FT601Q USB3, 348 MB/s measured
   [ Sp ]    spacer — micro-HDMI / USB cable clearance              $14.99
   [ Hd  ]   bottom  A45-A78           (3.3 V)   2x micro-HDMI (PC in, projector out)
```

**This board goes on TOP, alone.** Rationale:

- The **Hd's signal pass-through is undocumented** and may terminate a stack. Keeping the
  camera on top means it never has to sit above the Hd, and **this board needs no
  pass-through connectors at all.**
- The 32 multi-voltage pins (the only ones that can run at 2.5 V) exist **only on the top**
  Bank-B connector. There are **zero** multi-voltage pins on the bottom. The camera
  therefore *must* be on top.

A `Br` ($14.99) may substitute for either `Sp`. **Do not use the `Fn`** — its fan-control
solder jumper lands on **B36, a bank-13 pin**, and would consume half of one of our LVDS
pairs.

---

## 3. Why the pin plan works — bank voltages

This is the crux of the design, and it was the one thing that could have sunk the stack.

| Consumer | IO standard | Required VCCO |
|---|---|---|
| Hd (HDMI TMDS) | `TMDS_33` | **3.3 V** |
| Ft+ (FT601 FIFO) | `LVCMOS33` | **3.3 V** |
| **This board (sensor LVDS)** | **`LVDS_25`** | **2.5 V** |

An FPGA bank has exactly one VCCO, so these had to land in different banks. On the Pt V2
they do:

| Bank | VCCO | Pins |
|---|---|---|
| 14, 16, 34, 35 | **hardwired 3.3 V** | Hd and Ft+ live here |
| 15 | 1.35 V | DDR3L (internal) |
| **13** | **switchable 3.3 / 2.5 / 1.8 V** | **top Bank B, B33-B78 — 32 pins / 16 pairs — ALL OURS** |

**Neither the Hd nor the Ft+ places a single pin in bank 13.** Verified against Alchitry's
own constraint sources (`ft_plus_v2.acf`, `hd_v2.acf`, `PtV2TopPin.kt`) and cross-checked
against the official `pt_hd_bottom.xdc` / `pt_ft_plus_bottom.xdc`. The product pages do not
contain this information.

The Ft+ (A3-A42 + B3-B24) and the Hd (A45-A78) are also **mutually disjoint** — they are
designed to coexist. Their only conflict is mechanical (cable clearance), solved by the `Sp`.

### LVDS_25 nuance that forces bank 13

An `LVDS_25` **input** with *external* 100 Ω termination imposes no VCCO requirement and
would work in a 3.3 V bank. But:

- an `LVDS_25` **output** — which we need, to drive `lvds_clock_in±` **into** the sensor — and
- any input using the FPGA's **internal `DIFF_TERM`**

both **require VCCO = 2.5 V**. So bank 13 is mandatory regardless of how we terminate.

> **DANGER.** Alchitry: *"Failing to set the tri-voltage pins correctly could damage the
> FPGA."* See the VBSEL strapping in §6.

---

## 4. Sensor

**`NOIP1SN1300A-QTI`** — PYTHON 1300, monochrome, 4-LVDS output, 48-pin LCC. *(The
originally-specified `-QDI` is discontinued; `-QTI` is the identical sensor with a peel-off
protective foil over the glass — see the ordering note below.)*

| | |
|---|---|
| Resolution / rate | 1280 x 1024, 10-bit, **150 fps** (sensor max; we run a locked **120 Hz** — see *Operating point*) |
| Pixel | 4.8 x 4.8 µm, global shutter |
| Package | 48-pin LCC, **14.22 x 14.22 mm, 1.016 mm pitch**, D263 glass lid |
| Output | 4 LVDS data + 1 LVDS sync + 1 LVDS clock out; 720 Mbps/ch |
| Supplies | `vdd_33` 3.3 V, `vdd_18` 1.8 V, `vdd_pix` 3.3 V (tight: 3.25-3.35 V) |
| Price / lead | ~$139, long factory lead — order early |

**The VITA 1300 (`NOIV1SN1300A`) is pin-for-pin identical** — all 48 pins, both LVDS and
parallel variants — so this board accepts either. PYTHON is preferred: faster, and the VITA
datasheet carries a *"no silicon fix planned"* erratum (first-row blooming, costing 5 rows).

Design the rails to **PYTHON's tighter tolerances** so either part drops in.

> **Order the `-QTI` suffix.** The originally-specified `-QDI` (no protective foil) has been
> discontinued. `-QTI` is the identical PYTHON 1300 sensor but ships with a **peel-off
> protective foil** over the glass — remove it before installing the sensor (handle the glass
> by the edges afterward). The foil is otherwise harmless handling protection, and a bonus:
> its tab points toward pin 1 — a useful orientation aid, since the package has no chamfer/dot (§12).

### Bandwidth check

```
1280 x 1024 x 10 bit x 150 fps  =  245.8 MB/s
Ft+ (FT601Q), BARE LINK 2026-07-31 = 348   MB/s     ->  pattern generator only
Ft+ (FT601Q), END-TO-END 2026-08-17 = 232  MB/s     ->  with camera + DDR running
Ft  (FT600),  datasheet estimate  =  190   MB/s     ->  does NOT fit
```

> **THE TWO Ft+ NUMBERS MEASURE DIFFERENT THINGS, and only one of them is a budget.**
> 348 MB/s is the FT601 fed by a pattern generator — no camera, no DDR, nothing
> competing. With the real pipeline running, the *same* `ft_bench_async.py` measures
> **231.7 MB/s**, because the reader is now sharing one MIG port with the capture
> writer. Sampled while saturated, both ends were at their limit at once: the DDR→USB
> FIFO ran dry 32 % of the time **and** the FT601 back-pressured 40 %.
>
> **Budget against ~232 MB/s.** Using 348 led directly to a build that targeted 120 Hz
> at 16 bpp (314.6 MB/s "with ~10 % margin") and delivered **88 fps**.
>
> The Ft (FT600) number is still an estimate — not measured here.

### Operating point — ACHIEVED 2026-08-17

**1280 × 1024, packed 10-bit, locked 120.000 Hz, exposure settable at runtime.**

```
capture     120.000 Hz   (600,000 wordclk cycles, +/-2 cycles jitter -> ~3 ppm)
delivered   119.8 fps    201 MB/s, 25 CLEAN / 0 padded, ldrop static at 0
alignment   10 of 10 frames agree, r = 1.000
exposure    monotonic 75 us -> 4800 us, no saturation, independent of frame rate
```

Three things had to be true at once, and each was a separate fault:

1. **Dense 10-bit packing** (format 3, 4 px in 5 bytes). At 16 bpp a 120 Hz frame costs
   314.6 MB/s against ~232 available; packed it costs **196.6 MB/s**. 37.5 % of every
   byte moved had been zero padding. Packing goes all the way into DDR, not just onto
   the wire — otherwise the reader still pulls 314.6 MB/s out of DDR, which is the side
   that was already starving.
2. **Frame-start resync in the DDR writer.** Without it, one lost kernel repositioned
   every frame that followed, permanently — the picture rolled in both axes.
3. **The trigger pulse width.** `TRIGGERED=1` paced the sensor at a perfect 120.000 Hz
   while delivering *no pixels at all*, because the pulse width came from an
   **exposure-sweep experiment table that was never gated on `EXPO_SWEEP`**. It cycled
   50 → 6400 µs every eight frames, and 6.4 ms of integration plus 6.86 ms of readout
   does not fit in an 8.33 ms period. It also meant exposure was set by pulse width, so
   `exposure0` did nothing in triggered mode. The trigger is now a fixed 10 µs
   frame-start marker and the sensor integrates for `exposure0`.

#### Usable exposure range at 120 Hz — and a state that needs a reflash to escape

**Maximum exposure is 8280 µs, and the boundary is a cliff, not a slope.** The sensor
cannot integrate for a whole frame period *and* still answer the next trigger, so past
the limit it skips triggers. Measured against the DELIVERED rate:

```
 600..8280 us   111-122 fps   full rate, ldrop 0 at every setting
      8300 us      0.0 fps    collapses
      8333 us     59.8 fps    every other trigger missed
```

> **The status UART cannot see this.** It reports a healthy 120.00 Hz throughout,
> because the FPGA goes on triggering whether or not the sensor answers. Only the
> delivered byte rate shows the truth — the same trap as the throughput-vs-bytes
> lesson in [`ROADMAP.md`](../ROADMAP.md) §6.

> **⚠️ OVER-EXPOSING WEDGES THE SENSOR.** After one setting above the cliff, restoring a
> valid exposure did NOT recover it: `expo_cur` read back correctly and frame_start kept
> arriving at 120.000 Hz, but no frame ever completed (`rdBusy = 0`) and no bytes
> reached USB. A re-arm (opcode 3) did not help either. It took a full FPGA reconfigure
> to re-run the sensor's SPI boot sequence. So the host-side cap is a SAFETY feature,
> not a convenience — `cam_live.py` limits the slider to 8280 µs for this reason.

> **The 120 Hz is the right RATE but not a locked PHASE.** The trigger comes from the
> FPGA's own 100 MHz crystal, so it drifts against a projector on a different
> oscillator. For structured light that drift is the whole problem — see
> [`ROADMAP.md`](../ROADMAP.md) §6.5 for the external-HDMI-sync plan (vsync-derived
> trigger with a user-programmable phase shift), and the wiring question that gates it.

The Ft+ is **mandatory**. The Ft cannot carry full-rate capture, and the Pt V2's onboard
FT2232HQ is USB 2.0 (JTAG/UART only) — not a data path.

---

## 5. Pin plan

<!-- PIN_TABLE_START -->

> ### ⚠️ SUPERSEDED — we now use the sensor's internal PLL. See [`CAMERA_SENSOR_PROTOCOL.md`](../CAMERA_SENSOR_PROTOCOL.md) §4.
>
> **The escape hatch became the main road.** The FPGA drives **`clk_pll` at 72 MHz (CMOS)** and the
> sensor's internal PLL multiplies ×5 to the 360 MHz bit clock. **`lvds_clock_in±` is NOT driven** —
> those two pins stay undriven and unconstrained.
>
> Why: Avnet's *published, proven* register sequence (`docs/reference/onsemi_python_sw.c`) is the
> PLL variant, and no bypass-mode sequence is published — the datasheet warns that inventing one
> *"may cause the sensor to malfunction."* It also deletes the entire 360 MHz LVDS transmit path
> (no ODDR, no OBUFDS), and it costs nothing: **both modes give 720 Mbps/lane and the same max
> frame rate.**
>
> **The board is unchanged** — `clk_pll` was already routed for exactly this. Nothing to respin.

**Original plan (no longer followed):** ~~the FPGA drives the sensor's LVDS clock directly
(`lvds_clock_in±` at ~360 MHz, PLL bypassed); `clk_pll` is routed but unused — kept as an escape
hatch.~~

### 5.1 LVDS — top Bank B, bank 13, VCCO = 2.5 V

All 7 differential pairs. `IOSTANDARD LVDS_25`; inputs use internal `DIFF_TERM TRUE`
(legal because bank 13 is at 2.5 V).

**All seven pairs are on the DF40's EVEN row.** This is **forced by geometry, not chosen** —
see §5.1.1. An earlier revision used the odd row (both MRCC pairs are there) and was wrong.

| Sensor signal | Sensor pins (N/P) | Dir (FPGA) | Elem pins (N, P) | FPGA pins (N, P) | Clock cap. |
|---|---|---|---|---|---|
| `clock_out±` | 7 / 8 | IN | **B40, B42** | **Y12, Y11** | **SRCC** — forwarded bit clock |
| `doutn0 / doutp0` | 9 / 10 | IN | B46, B48 | V15, U15 | (spare SRCC) |
| `doutn1 / doutp1` | 11 / 12 | IN | B52, B54 | AB17, AB16 | — |
| `doutn2 / doutp2` | 13 / 14 | IN | B58, B60 | AA16, Y16 | — |
| `doutn3 / doutp3` | 15 / 16 | IN | B64, B66 | T15, T14 | — |
| `sync±` | 17 / 18 | IN | B70, B72 | Y14, W14 | — |
| `lvds_clock_in±` | 23 / 24 | **OUT** | B76, B78 | W16, W15 | — |

Spare: all 8 odd-row pairs. **`(B34,B36)` is deliberately NOT used** — `B36` is the Alchitry
`Fn` fan-control pin.

#### 5.1.1 Why the EVEN row — geometry, not preference

**The DF40's two rows escape in OPPOSITE directions.** Measured from the footprint on the
fabbed boards: **odd pins at y = +1.355 mm, even pins at y = −1.355 mm**, 40 each, on 0.4 mm
pitch. Each row's SMT tails splay *outward*, away from the connector centreline.

Now put that on the real board (§8, taken from the fabbed `LauCameraTrigger_Alchitry_Stack`):

```
   board:   55 x 45 mm
   Bank B:  at y = 41       -> odd row at y = 42.4, even row at y = 39.6
   board edge at y = 45     -> the ODD row escapes into a 2.6 mm strip.
```

**A 16.76 mm socket cannot fit below Bank B.** So the sensor must sit *above* it — and
therefore **only the EVEN row faces the sensor.** An odd-row pair would have to cross the even
row's 0.4 mm-pitch pads (impossible on `B.Cu`) or loop around the connector body. Seven
differential pairs looped around a connector at 720 Mbps is not a route anyone wants.

**The catch, and how it was settled.** Bank 13's even row has **no MRCC pairs** — only two
**SRCC**. So: can an SRCC pin drive `BUFIO` + `BUFR` into a cascaded `ISERDESE2`? I.e. does
the *real* 1:10 LVDS receiver place on these pins?

**Vivado says yes** (§13.1 — `iocheck/pt_camera_rx.v` is the actual receiver, not a stub):

```
  BUFIO placed     : 1     <- an SRCC pin drives it
  BUFR  placed     : 1     <- an SRCC pin drives it
  ISERDESE2 placed : 10    <- 5 lanes x master+slave cascade, 10 bits each
```

A `BUFG` (which *does* need MRCC) is the wrong structure for a 720 Mbps source-synchronous
link anyway. **`BUFIO` is the low-skew I/O clock you actually want**, and SRCC drives it.

#### The order, and why nothing crosses

With the (corrected, §12) footprint at rotation 0, the sensor's LVDS pins land contiguously on
the edge facing Bank B:

```
  sensor bottom edge, left -> right:
  7/8 clock_out | 9/10 dout0 | 11/12 dout1 | 13/14 dout2 | 15/16 dout3 | 17/18 sync
  [corner]
  23/24 lvds_clock_in     <- right edge, mid-height
```

The table assigns even-row pairs in that same left-to-right sequence, so **nothing crosses**.
`lvds_clock_in` takes the far-right pair because it exits the sensor's right edge.

**Polarity is free.** On the sensor, N is the lower pin number (7 = `clock_outn`). On the
connector, N is also the lower element-bus pin (B40 = N). Every pair runs N-to-N, P-to-P with
no intra-pair swap.

### 5.2 Single-ended control — top Bank A, 3.3 V

**Deliberately NOT in bank 13.** The sensor's CMOS pins are **3.3 V** level; driving them
from a 2.5 V bank would put V<sub>OH</sub> uncomfortably close to the sensor's V<sub>IH</sub>.

Top Bank A is **hardwired 3.3 V and cannot be dragged to 2.5 V by the VBSEL straps** —
`PtV2TopPin.bankToVcco()` returns a single-element `["3.3"]` for banks 14/16/34/35, and only
bank 13 returns `["3.3","2.5","1.8"]`. VBSEL controls bank 13 and nothing else. All 52 pins of
top Bank A are free (the Ft+ and Hd are on the *bottom*).

`IOSTANDARD LVCMOS33`.

#### The bank 14 / bank 35 split is deliberate — do not shuffle it

**`A3-A6` are bank 14, the Artix-7 configuration bank. `A9-A18` are bank 35, ordinary IO.**

FPGA user I/O sit **Hi-Z until `DONE` goes high**. Between power-up and bitstream load, every
control line into the sensor floats. So anything that could *disturb* the sensor while
floating is kept **off bank 14** and given an **external pull on this board**:

| Sensor signal | Sensor pin | Dir | Elem pin | FPGA pin | Bank | Pull |
|---|---|---|---|---|---|---|
| `mosi` | 2 | OUT | A3 | AB22 | 14 | — |
| `miso` | 3 | IN | A4 | AB18 | 14 | — |
| `sck` | 4 | OUT | A5 | AB21 | 14 | — |
| `clk_pll` | 25 | OUT | A6 | AA18 | 14 | — *(unused; PLL bypassed)* |
| `reset_n` | 46 | OUT | A9 | E3 | 35 | **R4, 10k PULL-DOWN** |
| `ss_n` | 47 | OUT | A10 | N2 | 35 | **R3, 10k PULL-UP** |
| `trigger0` | 41 | OUT | A11 | F3 | 35 | **R5, 10k PULL-DOWN** |
| `trigger1` | 42 | OUT | A12 | P2 | 35 | **R6, 10k PULL-DOWN** |
| `trigger2` | 43 | OUT | A15 | M2 | 35 | **R7, 10k PULL-DOWN** |
| `monitor0` | 44 | IN | A16 | L1 | 35 | — |
| `monitor1` | 45 | IN | A17 | M3 | 35 | — |

`A18` (M1) is spare.

**Why each pull:**
- **`ss_n` pulled HIGH** — a floating SPI select could read as **asserted**, and the sensor
  would try to clock in garbage from a floating `sck`/`mosi`.
- **`reset_n` pulled LOW** — holds the sensor *in reset* until the FPGA is configured and
  deliberately releases it. Fail-safe direction.
- **`trigger0-2` pulled LOW** — no spurious exposures during configuration.

Bank 14 then carries only signals that are harmless while floating: `mosi` and `sck` (inert
while `ss_n` is deasserted), `miso` (an input), and `clk_pll` (unused entirely).

The XDC also sets `BITSTREAM.CONFIG.UNUSEDPIN PULLDOWN` so the FPGA's internal weak pulls
agree with the external ones rather than fight them. **The external resistors are the primary
guarantee** — don't rely on the bitstream setting alone, since it does nothing before the
bitstream loads, which is exactly the window that matters.

> **No I²C pull-ups.** Unlike `LauMipiCamera_Alchitry_Stack` (which has `R_SCL`/`R_SDA` at
> 4k7), the PYTHON uses **SPI**, not I²C. Push-pull, no bus pull-ups needed.

### 5.3 Control header (C) — power and strapping

| C pin(s) | Signal | This board |
|---|---|---|
| 1, 3, 5, 7, 9, 11, 13, 15 | `+3.3V` | Input |
| 2, 4, 6, 8, 10, 12, 14, 16 | `VDD` (5–12 V) | Input — source for local regulators |
| 17–28 | `GND` | — |
| **38** | **`VBSEL A`** | **Strap HIGH** |
| **40** | **`VBSEL B`** | **Strap HIGH** |

`VBSEL A` = `VBSEL B` = HIGH → **bank 13 VCCO = 2.5 V**. Required. Nothing else may drive them.

> **Do not route the JTAG pins** (C43/45/47/49). Alchitry: *"JTAG pins will be reordered to
> match the Au on rev B."* That mapping is changing between board revisions.

### 5.4 Connector pin pattern (both A and B, 80-pin)

```
pins  1, 2   GND
pins  3, 4   IO (N)      pins  5, 6   IO (P)     -> pairs (3,5) and (4,6)
pins  7, 8   GND
      ... repeating: 2 GND, then 4 IO, ...
pins 79,80   GND
```
52 IO + 28 GND = 80. Odd column pairs with odd; even with even.

> **Bottom-side connector numbering is MIRRORED** relative to the silkscreen. Irrelevant here
> (this board is on top) — but it will bite if the board is ever moved to the bottom.

### 5.5 ✅ This pin plan is CONFIRMED BY VIVADO — see §13

Everything in §5 was derived by hand, from Alchitry's `.acf` files, a Kotlin source file, and
a scraped Xilinx package CSV. **It has since been checked against Xilinx's own device
database and it passes.** Do not "correct" this table from memory. See **§13**.

<!-- PIN_TABLE_END -->

---

## 6. Power and strapping — rules this board MUST obey

### 6.1 VBSEL — sets bank 13 to 2.5 V

Bank 13's VCCO is selected by two strap pins on the **50-pin control header (C connector)**:

| VBSEL A | VBSEL B | Bank 13 VCCO |
|---|---|---|
| floating | floating | 3.3 V |
| low | low | 3.3 V |
| low | high | 3.3 V |
| high | low | 1.8 V |
| **high** | **high** | **2.5 V  <- REQUIRED** |

**This board must strap `VBSEL A` = `VBSEL B` = HIGH.** No other board in the stack may
drive them. (low = 0-0.9 V, high = 1.1-3.3 V.)

### 6.2 There is no 5 V. Everything comes from `+3.3V`.

The Alchitry Pt V2 is a **3.3 V board**. The element connectors expose `+3.3V` on the control
header (pins 1–15 odd, 4 A available) and nothing else usable.

> **The `VDD` pins (control header, 2–16 even) are DELIBERATELY LEFT UNCONNECTED.** Alchitry's
> pinout page describes `VDD` as "5–12 V board power," but there is no 5 V on this board. Do
> not design against it, and do not "helpfully" wire it up.

**This board generates every sensor rail from `+3.3V`.** That single constraint shapes the whole
of §6.5. You **cannot LDO 3.3 V down to an accurate 3.3 V** — there is no headroom — so the
board **boosts to 4.45 V first and regulates back down**. That is why `U3` exists.

> An earlier revision concluded from this that `vdd_33` and `vdd_pix` "cannot be regulated" and
> had to be filtered taps. **That conclusion is wrong and is superseded by §6.5.** Both rails are
> now properly LDO-regulated; only the *headroom* had to be manufactured.

| Rail | Sensor pins | Spec | Current |
|---|---|---|---|
| `vdd_33` | 1, 19, 29, 36 | 3.2–3.4 V | ~140 mA |
| `vdd_18` | 6, 22, 26 | 1.7–1.9 V | ~80 mA |
| `vdd_pix` | 31, 33, 38, 40 | **3.25–3.35 V** — tight | ~5 mA |

### 6.3 Power entry

**All element power arrives on the 50-pin control header (C connector) only.** The Bank A
and Bank B 80-pin connectors carry **IO + GND exclusively — no power pins.** Route
`+3.3V` / `VDD` / `GND` from the C header.

### 6.4 Required discretes

- **47 kΩ from `ibias_master` (pin 28) to `gnd_33`.** Non-optional — the sensor's master
  bias reference.
- **100 Ω differential termination** on the LVDS receive pairs, unless using the FPGA's
  internal `DIFF_TERM` (which is available, since bank 13 is at 2.5 V).

---

### 6.4.1 Pull resistors — every sensor CMOS INPUT gets one

FPGA user I/O are **Hi-Z until `DONE` goes high**. During the whole configuration window,
`vdd_33` is already up and every control line into the sensor floats. A floating CMOS input
sits at an indeterminate level and burns **crowbar current** in the sensor's input buffer.

**Every sensor CMOS input on this board has a pull. All eight of them.**

| Net | Sensor pin | Dir | Pull | Why |
|---|---|---|---|---|
| `ss_n` | 47 | IN | **R3, 10k UP** → `+3V3_CAM` | a floating select could read as ASSERTED |
| `reset_n` | 46 | IN | **R4, 10k DOWN** | active-low → holds the sensor in reset. Fail-safe. |
| `trigger0-2` | 41-43 | IN | **R5/R6/R7, 10k DOWN** | rising edge starts integration; low = no spurious exposure |
| `mosi` | 2 | IN | **R12, 10k DOWN** | |
| `sck` | 4 | IN | **R13, 10k DOWN** | |
| `clk_pll` | 25 | IN | **R14, 10k DOWN** | unused in this clocking scheme, but still a CMOS input |

> **Designators verified against the routed board (2026-07-18).** An earlier revision of this
> table listed these three as `R13`/`R14`/`R15`, off by one. **`R15` is not a sensor pull at
> all** — it is the **100 kΩ `EN_PIX` pull-up to `+3V3_CAM`**, i.e. the sequencing interlock
> (§6.5). Do not repurpose it.

> **`R12`/`R13`/`R14` were missing.** They were originally exempted because `mosi` and `sck`
> are "inert while `ss_n` is deasserted". **That is a logic argument, not an electrical one.**
> The pins are CMOS input buffers regardless of what the protocol is doing, and they float for
> tens to hundreds of milliseconds at every power-up.

> **`R3` pulls up to `+3V3_CAM`, not `+3V3_SYS`.** This looks like an inconsistency and is
> deliberate: pulling to the *sensor's own* rail avoids driving a pin high through the sensor's
> ESD structure while `vdd_33` is still off. Do not "tidy" it to `+3V3_SYS`.

`BITSTREAM.CONFIG.UNUSEDPIN PULLDOWN` in the XDC does **not** cover these — they are *used*
pins, and the setting does nothing before the bitstream loads, which is exactly the window
that matters. **The external resistors are the only guarantee.**

### 6.5 The power tree

> **This tree is what is on the board** — verified against the schematic, the routed copper and
> `production/LauPythonCamera_Pt_Stack_bom.csv`. Full derivation, SPICE verification and BOM:
> **[`../CAMERA_POWER_DESIGN.md`](../CAMERA_POWER_DESIGN.md)**, which is authoritative if the two
> ever disagree.
>
> An earlier revision of this section described a **tap-through-ferrites** design — a load switch
> plus `FB1`/`FB2` beads. **That design is dead, and there is no `FB1` or `FB2` on this board.**
> It could not meet `vdd_pix`'s accuracy window and could not sequence correctly. If you find
> text anywhere referring to `U3` as a "load switch" or to a ferrite, it is stale — report it.

```
  +3V3_SYS  (J3 pins 1,3,5,7,9,11,13,15 — 3.229 to 3.327 V, noisy)
     |
     +--> U3  TPS61023 boost ---> +4V5 (4.45 V) --+--> U4 TPS7A2033 --> +3V3_CAM  vdd_33  140 mA
     |    L1 2.2uH, R8/R9 330k/51k                |
     |                                            +--> U5 TPS7A2033 --> +3V3_PIX  vdd_pix   5 mA
     |
     +--> U2  TPS7A2018 -----------------------------------> +1V8_CAM  vdd_18   80 mA
     |
     +--> U6  TLV803S (2.93 V) --> EN_PIX   (pull-up to +3V3_CAM = the interlock)
     +--> U7  TLV803S (2.93 V) --> EN_BOOST (via R17 1k / C41 220n = 493 us shutdown skew)
```

One boost, three LDOs, two supervisors. The boost exists **only** to give the LDOs headroom —
you cannot LDO 3.278 V down to an accurate 3.300 V. All accuracy and all noise rejection
(75–95 dB PSRR) happen in the LDOs.

**Power-up:** `vdd_18` → `vdd_33` → `vdd_pix`.  **Power-down:** `vdd_pix` → `vdd_33` → `vdd_18`.
Both enforced structurally, not by matched time constants.

> **`+3V3_PIX` must keep ≤ ~1.5 µF total** (C8–C11 are **100n**, not 1µ; there is deliberately
> **no bulk cap** on this rail). Power-down depends on U5's 150 Ω internal auto-discharge
> collapsing `vdd_pix` first. Adding a 10 µF bulk cap here silently breaks the shutdown ordering.
>
> **As built the rail carries 1.540 µF** — C8–C11 100n, C19–C22 10n, C28 100n, C37 1µ — i.e.
> 40 nF over the stated budget. τ = 150 Ω × 1.54 µF = **231 µs**, still three orders of magnitude
> inside the 10 µs requirement, so this is accepted. Recorded so it stays a decision, not a drift.

#### `U3` is a BOOST, and it exists only to manufacture headroom

**You cannot LDO 3.3 V down to 3.3 V.** The Pt's `+3V3` is 3.278 V — an LDO regulates only
*downward* and needs its input meaningfully above its output. So the answer is **up, then back
down**: boost to 4.45 V, then LDO back to an accurate 3.300 V.

`U3` is a **TPS61023** synchronous boost, not a switch and not the regulator. **All accuracy and
all noise rejection happen in the LDOs** (75–95 dB PSRR). The sensor sees **3.300 V ±1.5 %** —
the LDO's spec — rather than 3.278 V ±whatever Alchitry's tolerance turns out to be.

`R8` = **330 kΩ**, `R9` = **51 kΩ** → V_OUT = 0.595 × (1 + 330/51) = **4.445 V**.

> **Do not "tidy" R8/R9 to 649 k/100 k.** That pair gives 4.457 V — a 12 mV difference, entirely
> irrelevant — but **649 kΩ is a JLCPCB *Extended* part**, and paying a feeder fee for one
> resistor is silly. 330 k/51 k are both **Basic**. This was a deliberate choice, not an
> approximation.

**Why 4.45 V and not lower?** The TPS7A20's PSRR is specified at V_IN = V_OUT + 1.0 V. Even at
the low corner of the boost's reference tolerance, 4.33 − 3.3 = **1.03 V**, so full specified
PSRR is retained under all conditions. Dropping to 4.0 V would save ~60 mW of LDO heat and
forfeit that.

`vdd_18` **skips the boost entirely** — it already has 1.43 V of headroom straight from `+3V3`.

#### `vdd_pix` gets its own LDO — and that is what closes the accuracy window

`vdd_pix`'s window is **3.25–3.35 V (±1.52 %)**, which is tight. `U5` is a **TPS7A2033**, the
same part as `U4`, regulating to **3.3 V ±1.5 % → 3.2505–3.3495 V**. That fits, with ~50 mV of
margin at each end.

> **This supersedes an earlier "honest cost" note** which stated that `vdd_pix`'s tolerance *is*
> the Pt's `+3.3V` tolerance, and that the rail could sit ~16 mV outside its window at both
> extremes. **That was true of the dead tap-through-ferrites design and is not true now.**
> `vdd_pix` is independently regulated, so the Pt's rail accuracy no longer propagates to it.
> The old action item — "measure the Pt's 3.3 V rail the day the board arrives" — is **no longer
> load-bearing** for `vdd_pix`. Measuring it is still worth 30 seconds, but nothing depends on it.

#### Sequencing — two supervisors, and both are required

`U6` and `U7` are **TLV803S**, active-low open-drain, V_IT = **2.93 V**, 200 ms power-up delay.

| Node | Circuit |
|---|---|
| `U2.EN` (`vdd_18`) | tied directly to `+3V3` — comes up with the rail |
| `U3.EN` (boost) | `U7` RESET → `R17` **1 kΩ** series → EN; `C41` **220 nF** to GND; 100 kΩ pull-up to `+3V3` |
| `U4.EN` (`vdd_33`) | tied directly to `+1V8_CAM` |
| `U5.EN` (`vdd_pix`) | `U6` RESET direct; **100 kΩ pull-up to `+3V3_CAM`**; `C39` **10 nF** to GND |

**The interlock is `U5.EN`'s pull-up going to `vdd_33`, not to `+3V3`.** Before `vdd_33` exists
that pull-up sits at 0 V, so `vdd_pix` *physically cannot* enable early. The ordering is
structural, not a race between time constants.

> **⚠️ TWO supervisors are required. This is not optional, and the failure is silent.** If one
> open-drain RESET drove both enables, then whenever RESET released, the two nodes would be
> connected *to each other* through the series resistor — the pull-up on `EN_BOOST` would drag
> `EN_PIX` to ~1.6 V, above the TPS7A20's 0.9 V V_IH, and `vdd_pix` would rise *with* `vdd_33`
> instead of after it. Neither a larger resistor nor a diode-AND rescues it (see
> `CAMERA_POWER_DESIGN.md` §6). Cost of the second supervisor: $0.09.

*Power-up* — **`vdd_18` → `vdd_33` → `vdd_pix`**: `vdd_18` at t ≈ 1 ms; both supervisors release
at t ≈ 200 ms; the boost's EN crosses 1.2 V at t ≈ 210 ms → 4.45 V in ~700 µs; `vdd_33` at
t ≈ 212 ms; `U5.EN` then charges (τ ≈ 833 µs) and `vdd_pix` follows **330 µs later**, t ≈ 213.5 ms.

*Power-down* — **`vdd_pix` → `vdd_33` → `vdd_18`**: both supervisors assert **immediately** below
2.93 V (the 200 ms delay applies only to release). `vdd_pix` collapses first via U5's 150 Ω
discharge (τ = 150 Ω × 1.54 µF as built = **231 µs**; `CAMERA_POWER_DESIGN.md` quotes 216 µs
against its 1.44 µF budget); `U3.EN` decays through 1 kΩ into 220 nF and the boost disconnects at
t ≈ 493 µs, dropping `vdd_33` second; `U2` holds `vdd_18` up until `+3V3` falls below ~1.95 V,
so it dies last.

Separations are **hundreds of µs to ms**, against a **10 µs** datasheet requirement — and both
directions are **SPICE-verified** with manufacturer models (`CAMERA_POWER_DESIGN.md` §7.5).

> **The boost is what created the power-down problem, and the supervisor is what solves it.**
> Once started, the TPS61023 runs with V_IN as low as 0.5 V — left alone it would hold 4.45 V
> while `+3V3` collapsed, making `vdd_33` outlive `vdd_18`: the exact inverse of the required
> order. `U7` yanking `U3.EN` low at 2.93 V is what prevents that.

#### Part requirements — do not let a BOM optimiser touch these

| | |
|---|---|
| **`U2`** | `TPS7A2018PDBVR` — LDO 3.3 → 1.8 V, SOT-23-5. Accuracy below 2.8 V out is **±40 mV**, not ±1.5 % — do not write "±1.5 %" next to this rail. |
| **`U3`** | `TPS61023DRLR` — synchronous boost, SOT-563. **EN V<sub>IH</sub> 1.2 V max, absolute not ratiometric.** True input-to-output disconnect in shutdown — which the power-down ordering depends on. |
| **`U4`, `U5`** | `TPS7A2033PDBVR` — **same part number for both.** 150 Ω auto-discharge; `U5` relies on it. |
| **`U6`, `U7`** | `TLV803SDBZR` (`C132016`) — 2.93 V threshold, open-drain. **Two of them.** Order the **R** (reel) code, not the `T` — see `CAMERA_POWER_DESIGN.md` §6. |
| **`L1`** | 2.2 µH, **I<sub>sat</sub> ≥ 1.2 A** (peak is 584 mA worst-case → 2.05× margin). |

#### Decoupling

As built, verified against the routed copper — **11 supply pins, each with a primary cap and a
10 nF**, plus per-rail bulk:

| Rail | Per-pin primary | Per-pin HF | Bulk / local | Total |
|---|---|---|---|---|
| `vdd_33` (`+3V3_CAM`, 4 pins) | C1–C4 **1 µF** | C12–C15 **10 nF** | C23 10 µF, C26 100 n, C35 1 µF | 15.14 µF |
| `vdd_18` (`+1V8_CAM`, 3 pins) | C5–C7 **1 µF** | C16–C18 **10 nF** | C24 10 µF, C27 100 n, C30 1 µF | 14.13 µF |
| `vdd_pix` (`+3V3_PIX`, 4 pins) | C8–C11 **100 nF** | C19–C22 **10 nF** | C28 100 n, C37 1 µF — **no bulk** | 1.54 µF |
| `+4V5` (boost out) | — | — | C32/C33 10 µF, C34/C36 1 µF | 22.0 µF |
| `+3V3_SYS` (boost in) | — | — | C31 10 µF, C29 1 µF, C38/C40 100 n | 11.2 µF |

> **`vdd_pix`'s primary is 100 nF, not 1 µF** — deliberately, to stay inside the capacitance
> budget the shutdown ordering depends on (above). It is the one rail that breaks the pattern.

`C39` (10 n) and `C41` (220 n) are **not decoupling** — they are the `EN_PIX` and `EN_BOOST`
timing capacitors in the sequencing network.

**The 10 nF bank is not optional.** There was originally **no capacitor anywhere on this board
below 100 nF** — while the sensor's **LVDS drivers run off `vdd_18` and toggle at 360 MHz**. A
1 µF X7R 0402 self-resonates at 3–6 MHz and is *inductive* above that. Compounding it: **both
inner layers are ground (§11.2) — there is no power plane**; and the sensor is **socketed**,
adding ~1–3 nH per contact.

#### VBSEL — verified, and clean

`R10`/`R11` (1 k to `+3V3_SYS`) strap `VBSEL_A`/`VBSEL_B` HIGH → **bank 13 VCCO = 2.5 V**. Not
optional (§3).

They land on **TPS2116 `PR1` pins** — analog comparator inputs with a ~1.0 V internal reference,
which is why Alchitry spec a *band* ("low = 0–0.9 V, high = 1.1–3.3 V") rather than a CMOS
level. The Pt already loads them with **10 kΩ**, so our 1 kΩ gives **3.0 V** — comfortably
inside the high band.

**Nothing else in the stack drives them.** The **Hd**, **Ft+** and **Br** control headers are
pure pass-throughs with **zero components on any control pin** — verified from their schematics.
The only unverified link is the **`Sp` spacer** (no published schematic). Almost certainly a bare
pass-through, but **worth 30 seconds with a multimeter** before trusting it.

> Note the Pt V2 being a "3.3 V board" refers to its **power input and default I/O**. Its **32
> triple-voltage pins (bank 13)** genuinely do support 2.5 V — that is what VBSEL selects, and
> Vivado independently places `LVDS_25` + `DIFF_TERM` there with VCCO = 2.50 V (§13). The LVDS
> plan is unaffected by any of this.

### 6.6 Connectors

| Ref | Part | Role |
|---|---|---|
| `J1` | `DF40C-80DP-0.4V` | **Bank A** — 11 single-ended control signals (banks 14/35, 3.3 V) |
| `J2` | `DF40C-80DP-0.4V` | **Bank B** — the 7 LVDS pairs (bank 13, 2.5 V), all on the **EVEN** row (§5.1.1) |
| `J3` | `DF40C-50DP-0.4V` | **Control header** — *all* element power, plus the VBSEL straps |

The 80-pin symbol puts **odd pins on the left, even on the right**, mirroring the connector's
two physical rows — so each differential pair (odd, odd+2) lands adjacent on the same side of
the symbol, and the row split that drives the whole layout (§5.1.1) is visible in the
schematic rather than buried in a table.

**`J1` and `J2` carry no power pins at all** — only IO and GND. Every volt arrives on `J3`.

### 6.7 Cross-checked against a fabbed board

This design was compared against
**[ruffner/lupa300](https://github.com/ruffner/lupa300) → `pcb/uZed/lupa-hdmi-carrier.sch`** —
a *manufactured* FPGA carrier for a LUPA300 in the **same Andon LCC48 socket**. Three changes
came out of that comparison:

> **⚠️ Read this table as history.** The first two rows describe a comparison that led to the
> **ferrite-split topology, which is now dead** (§6.5, §14.6). They are kept because the
> *diagnosis* was right — `vdd_pix` genuinely needed dedicated attention — even though the
> *remedy* was later replaced by a better one. **Row 3 is still current.**

| Change | Why | Status |
|---|---|---|
| **Ferrite bead on `vdd_pix`** | Their board beads `VPIX`, `VDDA` and `VADC` (BLM18). We had **nothing** on the pixel supply — the most noise-sensitive rail on the sensor. This was a genuine omission. | ❌ **Superseded.** `vdd_pix` now has its **own TPS7A2033 LDO** (`U5`) with 75–95 dB PSRR — strictly better than a bead. No ferrite on the board. |
| **The whole topology** | They feed **one ultra-low-noise LDO** into the sensitive rails and **split them with ferrites**, with the LDO's output cap **before** the beads. | ❌ **Superseded** by boost → 3 LDOs → 2 supervisors. The `vdd_pix` power-down problem is instead eliminated by U5's 150 Ω auto-discharge plus the `EN_PIX` interlock. |
| **Per-pin decoupling 100 nF → 1 µF** | Their primary decoupler is **1 µF**, not 100 nF, backed by 0.1 µF. A modern 1 µF X7R in 0402 has similar ESL to a 100 nF but 10× the capacitance, so it holds supply impedance down across a wider band. | ✅ **Current** for `vdd_33` and `vdd_18`. **`vdd_pix` is the deliberate exception** — 100 nF per pin, to stay inside its capacitance budget (§6.5). |

**Two things from that board we deliberately did NOT copy:**

- **Their bias network.** Every LUPA300 bias pin (`BIAS1-4`, `ADC_BIAS`, `PRECHARGE_BIAS`) has
  an R **and** a C. It is tempting to look at our bare `R1` and think a cap is missing. **It is
  not.** Those are *voltage* nodes fed by RC dividers; the PYTHON's `ibias_master` is a
  **current reference** — the 47 kΩ to `gnd_33` sets a reference current and the datasheet
  specifies nothing else. Hanging a cap on a current-set node is not obviously safe and onsemi
  does not ask for one. (If you want certainty, that is an AND9158 question.)
- **Their LVDS termination — because they have none.** The LUPA300 is a **parallel** sensor
  (`D0`–`D9`, `FRAME_VALID`, `LINE_VALID`). Their board says nothing about our termination
  scheme. The 51 Ω networks on it are not on the sensor.

They also generate the sensor clock **locally, with an SI514 oscillator**, rather than driving
it from the FPGA. We deliberately do the opposite (§5) — a local oscillator would break
phase-lock to the projector, which is the whole point of the SLI system.

---
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

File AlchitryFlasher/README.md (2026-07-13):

# Alchitry Au Flasher

A small Windows GUI that **downloads an FPGA bitstream from GitHub and flashes it
onto an Alchitry Au V2 board over USB** — and, if needed, installs the Alchitry
loader for you first. It is a friendly front-end around Alchitry's own
command-line loader; you click through four numbered steps instead of typing
commands.

> ### 📌 What this flashes
> This is the end-user installer for **this** repo's bitstream,
> [`../Bitstream/Au2_SLI.bin`](../Bitstream) — so a non-developer can program an
> Alchitry Au V2 without Vivado or the command line.
>
> It also serves as the **reference model** for a future one-click flasher for the
> **Numato Mimas A7**: the whole framework carries over and only the *loader
> backend* changes. See
> **[Adapting this to the Mimas A7](#adapting-this-to-the-mimas-a7)** at the bottom.

---
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

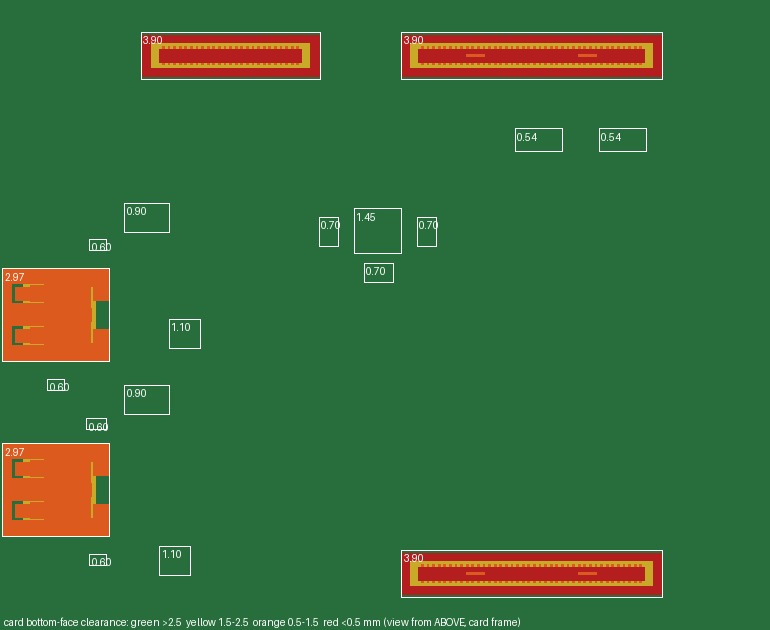
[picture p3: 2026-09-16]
LauEsp32Config_Pt_Stack/mech/hd_top_clearance.png

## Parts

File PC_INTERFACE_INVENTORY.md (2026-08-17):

# PC ↔ FPGA USB communications — complete inventory

_Compiled 2026-08-17 from source, ahead of merging the HDMI/SLI and camera designs._

Every message exchanged with the PC, across both USB ports, for both functions.

**Port A** = Pt V2 onboard FT2232H ch.B → host `COM6`. Present in every build.
**Port B** = Ft+ element board FT601Q → host D3XX, SuperSpeed. Only when the Ft+ is stacked.

`→` = PC to FPGA · `←` = FPGA to PC

| # | Port | Dir | Build | Function | Transaction | Wire format | Reply | Rate / size | Notes |
|---|---|---|---|---|---|---|---|---|---|
| 1 | A | ← | SLI | HDMI | Status telemetry | ASCII `S=s V=v T=t F=f M=m R=r N=nnnn L=hh D=hh G=hh P=hh C=hh O=hh` | — | ~2 lines/s, 115200 | `N`=VSYNC edges/window, `D`=symbol-sync/PLL-lock, `P`/`O`=datapath red |
| 2 | A | → | SLI | both | Write register | `A5 57 ADDR DATA CK` | `K` ok / `N` RO/undef / `E` bad CK | 5 B | `CK` sums payload to 0 mod 256; `A5` excluded |
| 3 | A | → | SLI | both | Read register | `A5 52 ADDR CK` | `ADDR DATA CK2` | 4 B | replies interleave with telemetry; command replies win |
| 4 | A | → | SLI | HDMI | Upload table | `A5 5B TGT D[0..N-1] CK` | `K` / `E` | up to 1283 B | `TGT 0x03` rejected (read-only) |
| 5 | A | → | SLI | HDMI | Read table | `A5 72 TGT CK` | `TGT D[0..N-1] CK2` | up to 1282 B | |
| 6 | A | ↔ | SLI | HDMI | Table `0x00` row LUT | via #4 / #5 | | 720 B | |
| 7 | A | ↔ | SLI | HDMI | Table `0x01` column LUT | via #4 / #5 | | 1280 B | |
| 8 | A | ↔ | SLI | HDMI | Table `0x02` intensity correction | via #4 / #5 | | 256 B | |
| 9 | A | ← | SLI | HDMI | Table `0x03` display EDID | via #5 only | | 256 B | **read-only**; captured off the HDMI *output* DDC |
| 10 | A | ← | SLI | HDMI | Reg `0x00` ID | via #3 | `0x48` | 1 B | proves the control bitstream is loaded |
| 11 | A | ← | SLI | HDMI | Reg `0x01` VERSION | via #3 | `0x01` | 1 B | protocol version |
| 12 | A | ← | SLI | HDMI | Reg `0x02` STATUS | via #3 | `{vsync,hsync,VPol,sel,mode,rdy,f_frm,trig}` | 1 B | same byte as the LEDs |
| 13 | A | ← | SLI | HDMI | Reg `0x06` FLAGS | via #3 | `{…, usb_sw_en, lut_loaded}` | 1 B | |
| 14 | A | ← | SLI | HDMI | Reg `0x10` PINS | via #3 | `{eff_sw[3:0], phys_sw[3:0]}` | 1 B | active vs physical switches |
| 15 | A | ↔ | SLI | HDMI | Reg `0x13` SLICTRL | via #2 / #3 | `{sw_en,mode_en,mode_val,R,G,B,orient}` | 1 B | overrides switch pins and camera `mode` GPIO |
| 16 | A | ↔ | SLI | HDMI | Reg `0x14` MODEFORCE | via #2 / #3 | `{force_en, idx[3:0]}` | 1 B | pins offline mode, overriding the EDID pick |
| 17 | A | ↔ | SLI | HDMI | Reg `0x15` LINKCTL | via #2 / #3 | `{secs×2[5:0], proj, host}` | 1 B | self-timed HDMI disconnect pulse |
| 18 | A | ← | SLI | HDMI | Reg `0x20` MODE | via #3 | `{valid, edid_ok, mode_idx[3:0]}` | 1 B | curated-table index in use |
| 19 | A | ← | SLI | HDMI | Reg `0x21` REFR | via #3 | refresh Hz | 1 B | |
| 20 | A | ← | SLI | HDMI | Reg `0x22`–`0x23` HACT | via #3 | active pixels, lo/hi | 2 B | 12-bit |
| 21 | A | ← | SLI | HDMI | Reg `0x24`–`0x25` VACT | via #3 | active lines, lo/hi | 2 B | 12-bit |
| 22 | A | ← | SLI | HDMI | Reg `0x26`–`0x28` PCLK | via #3 | pixel clock kHz, lo/mid/hi | 3 B | 17-bit |
| 23 | A | ← | SLI | HDMI | Reg `0x29`–`0x2A` SUPP | via #3 | supported-mode mask | 2 B | 14-bit, bit *i* = table index *i* |
| 24 | A | ↔ | SLI | camera | Reg `0x30`–`0x36` CAM_SPI | via #2 / #3 | addr, `{rw,addr[8]}`, wdata×2, go/status, rdata×2 | 7 B | PYTHON 1300 SPI mailbox, 9-bit addr / 16-bit data |
| 25 | A | ↔ | SLI | camera | Reg `0x37` CAM_GPIO | via #2 / #3 | `{reset_n, trigger[2:0]}` | 1 B | resets to `0x00` — sensor held in reset |
| 26 | A | ← | SLI | camera | Reg `0x38` CAM_MON | via #3 | `{monitor[1:0]}` | 1 B | |
| 27 | A | ↔ | SLI | camera | Reg `0x39` CAM_BOOT | via #2 / #3 | W = start; R = `{ready,busy,failed,pll_timeout}` | 1 B | ROM-driven sensor boot; owns SPI + reset while busy |
| 28 | A | ← | camera | camera | Status word | 32 hex chars + CRLF, 128 bits MSB-first | — | ~10/s, **1 Mbaud** | **TX only, no receive path.** Fields below |
| 29 | B | ← | camera | camera | Frame stream, pipe `0x82` | 32 B header + payload, contiguous | — | ~120/s, 1,638,432 B each | Header fields below |
| 30 | B | → | camera | camera | Cmd op `1` exposure0 | `[31:28]=1, [15:0]=units` | none | 4 B | units of 375 ns; **clamp ≤ 8280 µs at 120 Hz** |
| 31 | B | → | camera | camera | Cmd op `2` trigger period | `[31:28]=2, [23:0]=cycles` | none | 4 B | 100 MHz cycles; must be > 1000 |
| 32 | B | → | camera | camera | Cmd op `3` re-arm capture | `[31:28]=3` | none | 4 B | scan mode; in LIVE it only resets the ring |
| 33 | B | → | camera | camera | Cmd op `4` frames per scan | `[31:28]=4, [5:0]=n` | none | 4 B | 1..`MAXF` |

### Row 28 — camera status word fields (128 bits, MSB first)

| bits | field | meaning |
|---|---|---|
| 127:125 | `stw[2:0]` | writer FSM state |
| 124 | reader busy | reader is streaming a frame |
| 123 | `init_calib_complete` | MIG calibrated |
| 122 | `aligned` | LVDS word alignment locked |
| 121 | `streaming` | sensor configured and streaming |
| 120 | `cap` | capture armed |
| 119 | `cfifo_ovf` | camera→DDR FIFO overflowed (sticky) |
| 118 | `ufifo_ovf` | DDR→USB FIFO overflowed (sticky) |
| 117 | `ufifo_empty` | DDR→USB FIFO drained |
| 116 | `txe` | FT601 back-pressuring |
| 115:88 | `wtot` | wordclk cycles over a 24-frame window |
| 87:68 | `wmin` | shortest frame interval in the window |
| 67:48 | `wmax` | longest frame interval in the window |
| 47:32 | `expo_cur` | exposure0 applied, 375 ns units |
| 31:16 | `cmd_count` | commands received — **the only ack for rows 30–33** |
| 15:12 | `rx_dbg` | FT601 receive-path debug |
| 11:6 | `nframes` | frames per scan |
| 5:2 | `cal_retry` | MIG calibration retries |
| 1 | `LIVE` | ring-buffer live mode compiled in |
| 0 | `CONCURRENT` | concurrent capture/playback compiled in |

### Row 29 — frame header (8 little-endian uint32)

| word | contents |
|---|---|
| `h[0]` | `MAGIC` = `0x30494C53` |
| `h[1]` | `frame_idx` — free-running, proves freshness |
| `h[2]` | `{NROW[15:0], NCOL[15:0]}` |
| `h[3]` | `{2'b0, ldrop[15:0], nframes[5:0], 2'b0, slot[5:0]}` |
| `h[4]` | `FBYTES` — payload length (1,638,400 packed 10-bit) |
| `h[5]` | `FBYTES/4` |
| `h[6]` | payload format: `2` = 10-bit in u16, `3` = dense packed 10-bit |
| `h[7]` | `~MAGIC` — validates the header against payload aliasing |

---

## What the merge must reconcile

| # | Issue | Detail |
|---|---|---|
| 1 | **`usb_tx` (AA21)** | The only contested pin in the system. Rows 1–27 (115200, bidirectional) vs row 28 (1 Mbaud, TX-only). One wire. |
| 2 | Two camera boot sequencers | Row 27 (host-initiated) vs `cam_boot_stage1` (automatic at power-up). Both own SPI + `cam_reset_n`. |
| 3 | Two LVDS receiver chains | Both designs instantiate one; collapse to a single instance. |
| 4 | Clocking / CMT budget | HDMI MMCMs + camera MMCM + MIG + the `BUFR` regional clock, against 6 CMTs on the 100T. |
| 5 | Rows 30–33 have no reply path | Fire-and-forget on port B; the only ack is `cmd_count` on **port A** — an existing cross-port dependency. |

**Not an issue — pins and area.** DDR3's 48 pins collide with nothing; the HDMI design's 67
pins and the Ft+'s 45 are disjoint but for `usb_tx`; the 34 pins HDMI shares with the camera
are the *same signals*. Combined ≈ 35% of the 100T's fabric, ~55% of its I/O.

## Constraints any plan must respect

| Constraint | Consequence |
|---|---|
| Exposure ≤ 8280 µs at 120 Hz | Past it the rate halves; at 8300 µs delivery stops. Over-exposing **wedges the sensor** — restoring a valid exposure does not recover it, nor does re-arm. Needs an FPGA reconfigure. Any host that sets exposure must clamp. |
| Port B goes silent when the pipeline wedges | Row 28 is the only window into that state. Camera status must not live *only* on port B. |
| Row 2–27 is the Qt application's transport | `lauauboard.cpp` drives the whole 3-D reconstruction host. Breaking it is not a local change. |

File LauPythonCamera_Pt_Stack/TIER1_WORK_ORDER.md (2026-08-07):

# Tier 1 work order — the three fixes that stand between this board and fab

**Target:** clear README §14.1 so the board can be ordered (§15). Prepared 2026-07-28 against
`LauPythonCamera_Pt_Stack.kicad_pcb` at commit `0417463`, which is **DRC-clean (0 errors, 0
unconnected)** — so any DRC error you see after these edits is yours, which is the point of doing
it in this order.

---

## Status — RE-VERIFIED against the board, 2026-08-06. All four jobs are DONE.

> ⚠️ **The old status table here was stale and under-reported the work.** It said job 1 and the J3
> fan-out were still outstanding; both are in the board. The board was re-routed after this work
> order was written (the `.kicad_pcb` was substantially rewritten), so **trust the board, not the
> coordinates below** — several specific via positions in §2 and §3 no longer match. The table
> below was checked directly against the current `.kicad_pcb` and `production/`.

| Job | State |
|---|---|
| **1 — U1 decoupling** | ✅ **DONE — by redistribution, not addition.** No `C42`–`C51`; instead ten *existing* caps were moved to **B.Cu directly under the pins**. Five 1 µF + 10 nF pairs, one per naked pin — see the table below. This is better than the plan: no new part, no new BOM line, no feeder fee, and the BOM stayed byte-identical. |
| **2 — GND stitching** | ✅ **Done in substance.** The power section (x < 120, y < 95) now carries **13 GND vias**; the original complaint was that **exactly one** existed at x < 112. The eight specific coordinates in §2 no longer all match — the re-route moved them. |
| **3 — `+3V3_SYS` entry** | ✅ **Widened, and the J3 fan-out is DONE.** ⬜ **One item genuinely open — see "What is actually left" below.** |
| **4 — silk off U1's pads** | ✅ **Done** — U1, R1, R14 reference fields moved |
| **Test points** | ✅ **DONE, and not in the original plan.** `TP1`–`TP6` exist on F.Cu, one per rail plus GND. |

### Job 1 as built — which cap pairs with which pin

| Pin | Rail | 1 µF | 10 nF |
|---|---|---|---|
| 19 | `+3V3_CAM` | `C2` | `C15` |
| 22 | `+1V8_CAM` | `C6` | `C17` |
| 26 | `+1V8_CAM` | `C5` | `C16` |
| 29 | `+3V3_CAM` | `C1` | `C12` |
| 36 | `+3V3_CAM` | `C3` | `C13` |

All ten are bottom-side, ~1–2 mm from their pin, against the 25–32 mm they had. **Do not add
`C42`–`C51`** — the job is done, and adding them would double the decoupling and change the BOM.

### Test points as built

| | net | | net |
|---|---|---|---|
| `TP1` | `+3V3_SYS` | `TP4` | `+3V3_CAM` |
| `TP2` | `+4V5` | `TP5` | `+3V3_PIX` |
| `TP3` | `+1V8_CAM` | `TP6` | `GND` |

Five rails + GND, which is exactly what §14.3 asked for and what §15.5 needs on bring-up day.
They carry no LCSC part and are excluded from the BOM and CPL by construction.

---

## What is actually left

Two items, both the same *kind* of thing — a rail reaching somewhere through a **single via**. Neither
is a DRC error, neither is a DC current problem, and neither blocks fab. They are single-point-of-
failure and AC-impedance insurance.

| Where | Current state | Note |
|---|---|---|
| **`+3V3_SYS` entry from J3** at **(111.725, 69.875)** | **one** 0.8/0.4 via | §3 below claims two parallel vias were added at (112.35, 69.90) and (113.00, 69.90). **They are not in the current board** — the re-route removed them. Every milliamp the board consumes still crosses this one via. Cheapest fix on the list: add one or two more on the 0.6 mm stub. |
| **`+3V3_CAM`** at **(124.425, 89.200)** | **one** 0.8/0.4 via | §14.2.2's "double both up". The `+4V5` half of that item now has two vias on the path — (109.675, 73.200) and (106.175, 78.050) — so only the `+3V3_CAM` half remains. |

Optional, from §14.2.1 (EMI insurance, never a blocker): two GND stitches by `CAM_LVDSCLK`'s layer
transition at (148.01, 84.84), and one near (140.2, 94.4) for D3.

Board state as last recorded: **0 errors, 0 unconnected, 70 warnings (all silkscreen), 110 benign
parity warnings.** Zones were refilled and the board saved.

> **The "you must open KiCad to refill zones" caveat is withdrawn.**
> `kicad-cli pcb drc --refill-zones --save-board` does it from the command line, and that is how the
> current fills were produced. It matters more than it sounds: **widening a track without refilling
> makes DRC report the stale fill as a 0.000 mm clearance error** — 15 phantom errors appeared that
> way mid-job and all 15 vanished on refill. If you see a wall of zone-clearance errors, refill
> before believing any of them.
>
> **`production/` is CURRENT** (was: "now stale"). It was regenerated 2026-07-28 against the board
> with job 1, the six test points and the J3 fan-out all in place — README §15.6 records the
> verification. Only regenerate if you touch the board again, e.g. to close the two single-via
> items above. The `production/` BOM was hand-corrected on 2026-08-06 for the `U6`/`U7` supervisor
> part number (`C702125` → `C132016`), matching the schematic, so a regeneration will reproduce it.

Coordinates are **KiCad page coordinates**, the same frame the `.kicad_pcb` uses. Subtract
(100, 60) for board-relative.

> **Read this first: §14.1's stated location for job 1 is wrong.** It says to use "the strip east of
> U1 (x 146–154.5)". The board is **notched to x = 149.5** between y 69.5 and 95.5 — everything past
> 149.5 is off-board — and the 2.3 mm that does exist is already carrying `CAM_CLK_PLL` (x 148.82),
> the `CAM_LVDSCLK` escape and both its vias (x 147.7–148.6, y 82.5–85), `IBIAS_MASTER` and GND.
> **Job 1 below uses the B.Cu-under-the-pins option instead**, which was verified free.

---

## Job 1 — local decoupling for U1's five naked supply pins

**Why it is first:** §14.1 calls it "the single highest-value change on the board". Five of eleven
supply pins have their nearest cap 25–32 mm away — ~20 nH of loop inductance, on a board with **no
power plane** (both inner layers are GND, §11.2.1) feeding a **socketed** sensor (1–3 nH per
contact). Pins 22 and 26 are two of the three `vdd_18` pins, and `vdd_18` is what the **360 MHz LVDS
drivers** run from (§6.5).

### 1.1 The parts to add

Ten 0402s — **five 1 µF + 10 nF pairs**, one per naked pin.

| Qty | Value | Footprint | LCSC | Note |
|---|---|---|---|---|
| 5 | 1 µF | `C_0402_1005Metric` | `C52923` | **same line as C1–C7** — no new BOM line, no new feeder fee |
| 5 | 10 nF | `C_0402_1005Metric` | `C15195` | **same line as C12–C22** — ditto |

**Designators: use C42–C51.** The highest existing is C41.
**Do not reuse C25.** Its absence is deliberate — a 10 µF on `+3V3_PIX` that would have broken the
power-down ordering (§14.6). Restoring that designator would resurrect a fixed bug in the next
BOM audit.

### 1.2 Where each pin's via goes — these land on existing copper

The socket's east pads are **2.54 × 0.635 mm centred at x = 145.906**, so each pad spans
x 144.636 → 147.176. Every one of these four pins **already has its rail trace running west off the
pad**, so the feed via lands on existing copper at **x = 144.40** — 0.24 mm clear of the pad edge,
~1.5 mm from the pad centre:

| Pin | Rail | Pad centre | Put a via at | Lands on |
|---|---|---|---|---|
| 19 | `+3V3_CAM` | (145.906, 87.588) | **(144.40, 87.588)** | the existing 0.5 mm run west to x 138.188 |
| 22 | `+1V8_CAM` | (145.906, 84.540) | **(144.40, 84.540)** | the existing 0.5 mm run west to x 135.81 |
| 26 | `+1V8_CAM` | (145.906, 80.476) | **(144.40, 80.476)** | the existing run west to the x 144.136 riser |
| 29 | `+3V3_CAM` | (145.906, 77.428) | **(144.40, 77.428)** | the existing 0.5 mm run west to x 136.497 |

Use the standard 0.5/0.3 via. **Loop budget: ~1.2 nH via + ~1.5 mm trace ≈ 2.5 nH, against ~20 nH
today.** That is the whole point of the job — do not let the cap drift west to make the routing
tidy, because distance is the defect.

### 1.3 Where the caps go

**Bottom side (B.Cu), directly beneath the pads.** Verified free: the only copper in
x 143–147.5 / y 76–89 on B.Cu is a 1 mm `CAM_LVDSCLK_N` detour at y 87.6–88.6, x 146.97–147.88 —
east of where these caps sit, but **watch it when you place pin 19's pair.**

- **B.Cu is a GND pour** (`(zone (net "GND") (layer "B.Cu"))`), so each cap's ground pad connects to
  the plane where it stands — no ground trace, no ground via, near-zero return inductance. This is
  what makes the bottom side the better option.
- Put the **10 nF nearest the via**, the 1 µF outboard of it. Suggested centres: 10 nF at
  (143.55, *y*<sub>pin</sub>), 1 µF at (141.85, *y*<sub>pin</sub>), with a 0.5 mm B.Cu rail trace
  running west from the via. There is ±1.5 mm of clear y around each pin (pins are 3.0–4.1 mm apart),
  so stacking a pair in y instead is equally fine — **your call, whichever routes cleaner.**
- **Height is not a problem and there is precedent:** `R2` is already a bottom-side 0402 inside the
  DF40 mated height. Still worth a sanity check against the stack gap once placed.

### 1.4 Pin 36 — the one that needs your eye

`+3V3_CAM` at **(136.508, 72.094)**, on the socket's *north* edge, not the east column.

The north strip (y 60–72) holds **no components at all** but is dense with traces — 38 `+3V3_PIX`
segments, GND, and a dozen control nets. **Fallback:** B.Cu immediately south of the pad, under the
socket cavity. Target the same ≤1.5 mm as the others; take ≤2.5 mm if that is what fits. Even a
2.5 mm placement is an order of magnitude better than the 25.4 mm it has now.

---

## Job 2 — ground stitching in the power section ✅ DONE

**Exactly one GND via existed at x < 112.** The boost's high-di/dt return loop was confined to the
F.Cu/B.Cu pours with no path into either inner ground plane for over a centimetre.

> ⚠️ **Correction — the GND pad coordinates first written here were wrong.** They were computed with
> the rotation applied the wrong way round. KiCad's transform is
> **`absolute = origin + R(−θ)·local`**, so for the 90°-rotated caps the two pads were **swapped**.
> Caught because a "GND" trace appeared to terminate on a `+3V3_SYS` pad — an impossible short that
> DRC was not reporting, which meant the arithmetic was wrong, not the board. **U1, U3 and the socket
> are all rotation 0, so job 1's coordinates were never affected.** Verified positions below.

**Eight vias placed, all 0.5/0.3, all on existing GND copper so connectivity does not depend on the
pour:**

| Target | GND pad (verified) | Was | Vias placed |
|---|---|---|---|
| `U3.4` | (107.713, 73.50) | **10.80 mm** | (107.50, 74.05) and (107.50, 74.75) on the attached GND trace; (108.20, 74.60) and (106.95, 74.60) fed by two new 0.5 mm stubs off (107.50, 74.40) |
| `C31.2` | **(103.50, 72.05)** | 15.13 mm | (102.20, 72.89) on the attached diagonal |
| `C32.2` | **(117.50, 71.25)** | — | (117.50, 70.20) |
| `C33.2` | **(117.50, 75.45)** | — | (118.50, 74.45) |
| `C34.2` | **(103.50, 86.225)** | 11.15 mm | (102.575, 87.60) |

`SW` still contains **exactly** `L1.2` and `U3.5` (§14.5) — the cluster was placed clear of it, the
nearest approach being 0.71 mm edge-to-edge.

**Two placements had to move after DRC objected, and both objections were real:**

- **C34's first position (102.60, 85.325) sat 0.03 mm from `EN_BOOST`.** That B.Cu track runs
  *parallel* to C34's GND trace, 0.407 mm away centre-to-centre — a 0.5 mm via cannot fit between
  them at all. Moved to the pad's *other* GND branch, the one heading south-west.
- **C33's first position (118.60, 74.35) was 0.165 mm hole-to-hole from an existing via** at
  (118.925, 73.95) — under the 0.2495 mm minimum. Backed off along the same diagonal.

The lesson for job 1: **check B.Cu and existing vias, not just F.Cu tracks.** Both misses were
things I had not queried.

**Also worth doing while you are in there** (Tier 2, §14.2.1): `CAM_LVDSCLK`'s layer transition at
(148.01, 84.84) has **no GND via within 8 mm** — the worst on the board. Two deliberate stitches
there. D0/D2/SYNC all cross at y = 98.800 and are covered by four vias at x ≈ 138.1, 140.4, 142.8,
145.1; D3 needs one near (140.2, 94.4). This is common-mode/EMI, not differential-eye — cheap
insurance, not a blocker.

---

## Job 3 — the whole board is powered through 0.2 mm and one via

Traced end to end, `+3V3_SYS` reaches everything like this:

```
J3 pins (odd 1-15)  --0.2mm B.Cu, daisy-chained along y=65.355-->  x=111.7
   -->  0.2mm B.Cu riser to (111.7, 69.9)  -->  ONE 0.8/0.4 via  -->
   0.2mm F.Cu  (111.7,69.9)->(107.7,69.9)->(107,70.6)->(107,73.175)  -->  U3.3 (boost VIN)
```

Cut that one via and `L1.1`, `U3.3` and `U2.1` all go dark — **everything.** Current is ~320 mA
average (234 mA boost input + 80 mA for U2) plus boost peak inductor current, against ~0.5 A for
0.2 mm on 1 oz outer copper: **64 % loaded, no redundancy, and the last daisy-chain segment carries
the full aggregate.**

Three changes — **1 and 2 are done, 3 is yours:**

**1. ✅ Widened.** Not uniformly, because the run is not uniformly free:

| Segment | Was | Now | Why |
|---|---|---|---|
| F.Cu (111.7, 69.9) → (107.7, 69.9) | 0.2 | **0.8** | nothing within 1.3 mm — verified clear |
| F.Cu (107.7, 69.9) → (107, 70.6) | 0.2 | **0.8** | same |
| F.Cu (107, 70.6) → (107, 71.6) | 0.2 | **0.8** | clear until U3's pad field starts |
| F.Cu (107, 71.6) → (107, 73.175) | 0.2 | **0.3** | **capped by U3's pads** — see below |
| B.Cu (111.7, 66.3) → (111.7, 69.9) | 0.2 | **0.8** | clear of J3's courtyard |
| B.Cu (111.7, 65.355) → (111.7, 66.3) | 0.2 | **0.2** | inside J3's courtyard, stays necked |

> **The last approach into U3 cannot take 0.5 mm.** `U3.2` (`EN_BOOST`) and `U3.5` (`SW`) sit
> **0.3745 mm** from that segment's centreline, so 0.5 mm width leaves 0.125 mm — under the 0.2 mm
> netclass clearance. Maximum legal there is ~0.349 mm; it was set to **0.3**, giving 0.2245 mm.
> A short neck at a fine-pitch IC pad is normal; the defect §14.1 identified was the *long* run and
> the single via, and both are gone.

**2. ✅ Two parallel vias added** at (112.35, 69.90) and (113.00, 69.90), on 0.8 mm stub copper
extended east on **both** layers from the original transition. Three vias now carry the rail where
one did. Spacing is set by the **0.2495 mm minimum hole-to-hole**: with 0.4 mm drills, centres must
be ≥0.65 mm apart, which is why they are not tucked in tighter.

**3. ⬜ YOURS — fan the eight J3 power pins** into a short bus rather than chaining them along
y = 65.355, so no single segment carries the full aggregate. This is inside the 0.4 mm-pitch
connector fanout and it is routing, not a mechanical edit.

While you are here: §14.2.2 flags two more single-via rails — (124.42, 89.20) is the sole feed to
all four `+3V3_CAM` sensor pins, and (109.67, 73.20) the sole feed to both LDOs off `+4V5`. DC
current density is fine; this is single-point-of-failure and AC impedance. **Double both up.**

---

## Job 4 — silk off the pads ✅ DONE (for U1)

Three reference fields moved. **U1's socket pads now carry no silk at all** except the pin-1 marker:

| Ref | Was | Now | Cleared |
|---|---|---|---|
| `U1` | (136, 72.118) — dead centre of the pad-36/37 row | **(136, 94.6)**, south of the socket | pads 36, 37 |
| `R1` | (146.905, 77.5) — pointing west onto the socket | **(148.075, 76.0)** | pads 28, 29 |
| `R14` | (146.93, 80.7) — same | **(148.10, 82.4)** | pads 25, 26, 27 |

U1's designator went **north first and landed on C20** (which sits at exactly (136, 69.4) — the
`vdd_pix` cap row is right there). South of the socket is the only genuinely empty ground: no
footprint origins at all in x 125–150, y 92–100.

**Deliberately left alone: U1's pin-1 marker circle over pad 1.** It is flagged, but it is the pin-1
indicator on a part with no mechanical keying (§10), it will be clipped by the fab like any silk over
a mask opening, and moving it is a footprint-library edit rather than a board edit.

`R1`'s and `R14`'s references now overlap **their own** pads — the ordinary, harmless case that most
of the 38 remaining `silk_over_copper` warnings are. The point was to get them off the *socket*.

---

## Closing out

1. **Re-run DRC** — expect 0 errors. The command is in README §14.7.
   Watch two things specifically: the `CAM_LVDSCLK` uncoupled margin is only **0.29 mm** (8.7148 vs
   9.0), and the B.Cu GND pour has a **0.5 mm keep-back from the LVDS pairs** to preserve the
   microstrip impedance — job 1 pours new copper near neither, but a refill can surprise you.
2. **Re-run with `--schematic-parity`** after the schematic changes. Expect the same 110 benign
   `unconnected-(…)` warnings and **zero net conflicts**; a new net conflict means a cap landed on
   the wrong net.
3. **Regenerate `production/`** — gerbers, drill, **and** BOM + CPL, since job 1 changes both
   (README §15.6).
4. **Order** per README §15 — and note `U1` stays **do not place**.

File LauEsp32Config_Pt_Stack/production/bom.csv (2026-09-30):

Comment | Designator | Footprint | LCSC Part #
22u | C1,C2 | C_0805_2012Metric | C45783
10u | C3,C7 | C_0805_2012Metric | C15850
100n | C4,C6,C8 | C_0402_1005Metric | C1525
1u | C5 | C_0402_1005Metric | C52923
Red | D1 | LED_0603_1608Metric | C2286
DF40C-80DP-0.4V(51) | J1,J2 | Hirose_DF40C-80DP-0.4V_2x40-1MP_P0.4mm | C294544
DF40C-50DP-0.4V(51) | J3 | Hirose_DF40C-50DP-0.4V_2x25-1MP_P0.4mm | C424645
DF40HC(4.0)-80DS-0.4V(51) | J4,J5 | Hirose_DF40HC(4.0)-80DS-0.4V_2x40_P0.4mm | C5254351
DF40HC(4.0)-50DS-0.4V(51) | J6 | Hirose_DF40HC(4.0)-50DS-0.4V_2x25_P0.4mm | C5338326
1040310811 | J7 | microSD_HC_Molex_104031-0811 | C585350
2N7002 | Q1,Q2 | SOT-23 | C8545
10k | R1,R2,R3,R4,R5,R31,R32,R33,R34,R35,R36 | R_0402_1005Metric | C25744
1k | R6,R7 | R_0402_1005Metric | C11702
0R | R10,R11,R12 | R_0402_1005Metric | C17168
33R | R13,R20,R21,R22,R23,R24,R25,R26,R27,R30 | R_0402_1005Metric | C25105
ESP32-S3-MINI-1U-N8 | U1 | ESP32-S2-MINI-1U | C2980299
SN74LVC125APWR | U2 | TSSOP-14_4.4x5mm_P0.65mm | C7813

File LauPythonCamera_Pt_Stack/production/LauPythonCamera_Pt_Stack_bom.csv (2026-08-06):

Comment | Designator | Footprint | LCSC Part #
1u | C1,C2,C3,C4,C5,C6,C7 | C_0402_1005Metric | C52923
100n | C8,C9,C10,C11,C26,C27,C28,C38,C40 | C_0402_1005Metric | C1525
10n | C12,C13,C14,C15,C16,C17,C18,C19,C20,C21,C22,C39 | C_0402_1005Metric | C15195
10u | C23,C24,C31,C32,C33 | C_0805_2012Metric | C15850
1u | C29,C30,C34,C35,C36,C37 | C_0603_1608Metric | C15849
220n | C41 | C_0402_1005Metric | C16772
DF40C-80DP (Bank A) | J1 | Hirose_DF40C-80DP-0.4V_2x40-1MP_P0.4mm | C294544
DF40C-80DP (Bank B) | J2 | Hirose_DF40C-80DP-0.4V_2x40-1MP_P0.4mm | C294544
DF40C-50DP (Control) | J3 | Hirose_DF40C-50DP-0.4V_2x25-1MP_P0.4mm | C424645
2.2uH | L1 | L_Power_4x4mm_SMNR4020 | C135262
47k | R1 | R_0402_1005Metric | C25792
100R | R2 | R_0402_1005Metric | C25076
10k | R3,R4,R5,R6,R7,R12,R13,R14 | R_0402_1005Metric | C25744
330k | R8 | R_0402_1005Metric | C25778
51k | R9 | R_0402_1005Metric | C25794
1k | R10,R11,R17 | R_0402_1005Metric | C11702
100k | R15,R16 | R_0402_1005Metric | C25741
NOIP1SN1300A-QTI | U1 | Andon_680-48-SM-G10-R14
TPS7A2018PDBVR | U2 | SOT-23-5 | C963430
TPS61023DRLR | U3 | SOT-563 | C919459
TPS7A2033PDBVR | U4,U5 | SOT-23-5 | C2862740
TLV803SDBZR | U6,U7 | SOT-23 | C132016

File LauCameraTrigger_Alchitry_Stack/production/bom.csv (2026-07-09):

Comment | Designator | Footprint | Qty | MPN | LCSC Part #
SM07B-SRSS-TB | MASTER1,SLAVE1,SLAVE2 | JST_SH_SM07B-SRSS-TB_1x07-1MP_P1.00mm_Horizontal | 3 | SM07B-SRSS-TB(LF)(SN) | C160406
0.1uF | C1,C2 | C_0805_2012Metric | 2 | 0.1uF 0805 X7R | C49678
1k (tie-high pull-ups: CAM_READY/CAM_MODE -- Basler ace open-collector cam outputs) | R1,R7 | R_1206_3216Metric | 2 | 1206W4F1001T5E | C4410
DIP4 RGB/HV select -- DNP for PCBA; hand-solder (Wurth 418121160804) | SW1 | SW_DIP_SPSTx04_Slide_6.7x11.72mm_W8.61mm_P2.54mm_LowProfile | 1 | 418121160804
DF40C-80DP (Bank A / Site B / MECH-ONLY) | J2 | Hirose_DF40C-80DP-0.4V_2x40-1MP_P0.4mm | 1 | DF40C-80DP-0.4V(51) | C294544
DF40C-80DP (Bank B / Site C) | J3 | Hirose_DF40C-80DP-0.4V_2x40-1MP_P0.4mm | 1 | DF40C-80DP-0.4V(51) | C294544
DF40C-50DP (Site A / +3V3 only) | J1 | Hirose_DF40C-50DP-0.4V_2x25-1MP_P0.4mm | 1 | DF40C-50DP-0.4V(51) | C424645

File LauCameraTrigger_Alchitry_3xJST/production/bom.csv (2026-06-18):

Comment | Designator | Footprint | MPN
JST SM07B-SRSS-TB | J3,J9,J10 | JST_SH_SM07B-SRSS-TB_1x07-1MP_P1.00mm_Horizontal | SM07B-SRSS-TB(LF)(SN)

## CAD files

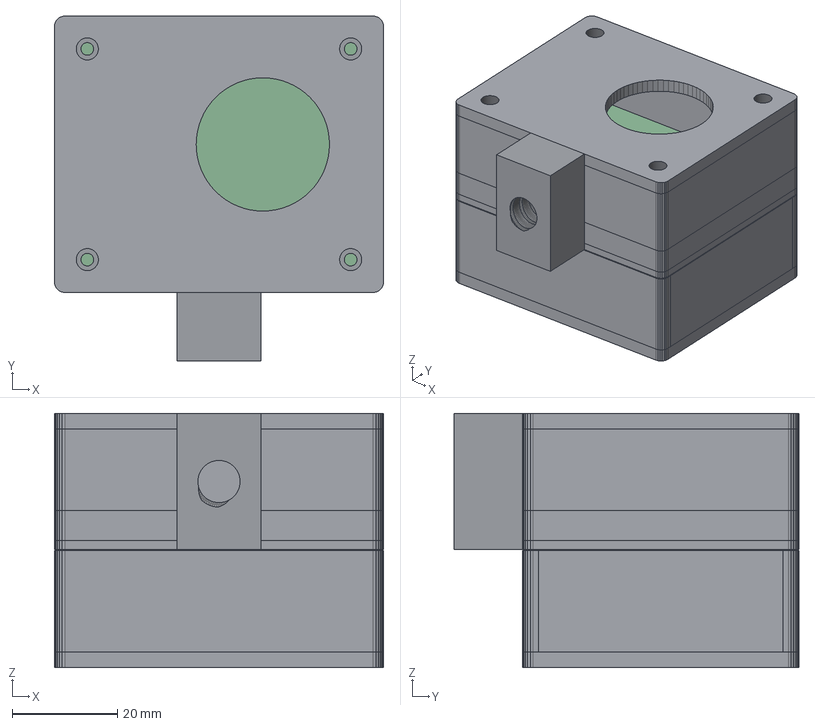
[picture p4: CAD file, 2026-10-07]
LauPythonCamera_Pt_Stack/3dmodels/camera_enclosure_assembly.step
62.5 x 65.5 x 48.3 mm

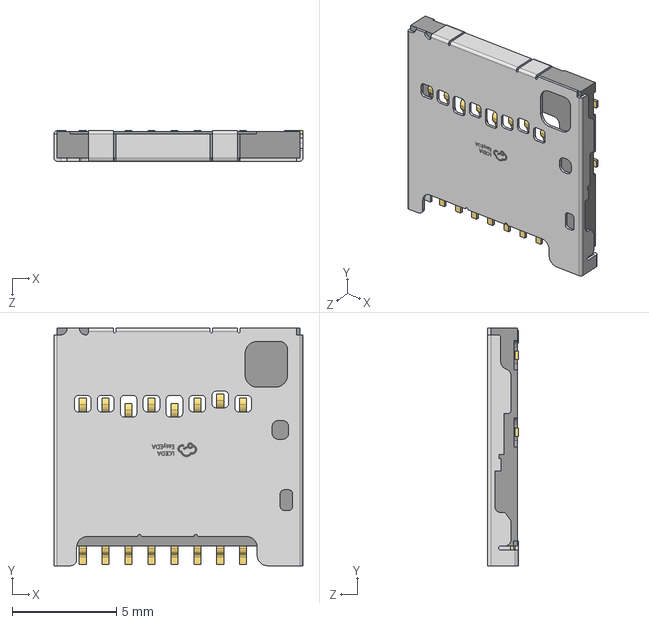
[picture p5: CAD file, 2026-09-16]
LauEsp32Config_Pt_Stack/3dmodels/Molex_1040310811_C585350.step
12.0 x 11.4 x 1.47 mm

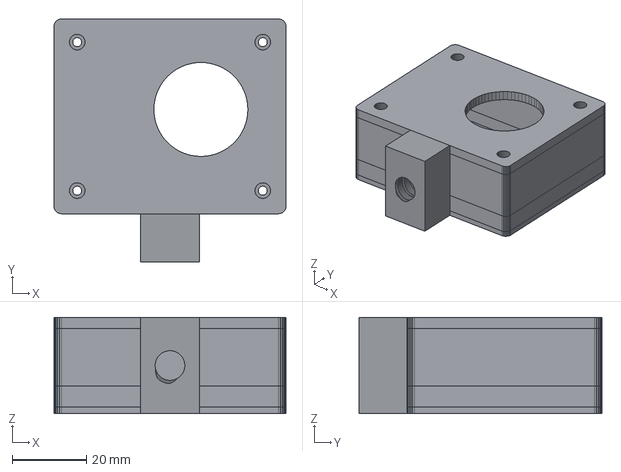
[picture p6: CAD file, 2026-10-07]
LauPythonCamera_Pt_Stack/3dmodels/camera_lens_box.step
62.5 x 65.5 x 25.9 mm

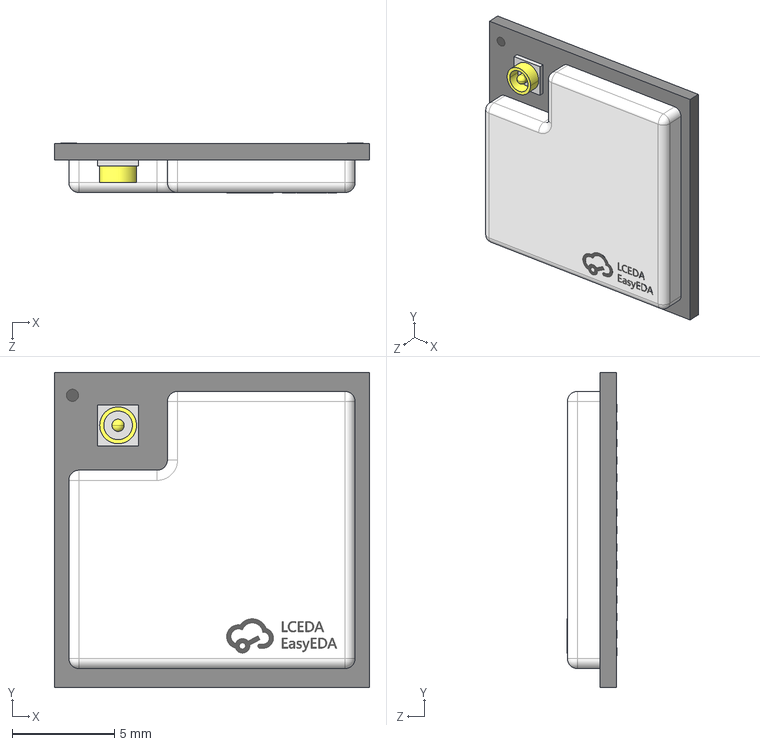
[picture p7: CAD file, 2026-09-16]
LauEsp32Config_Pt_Stack/3dmodels/ESP32-S3-MINI-1U-N8_C2980299.step
15.4 x 15.4 x 2.43 mm

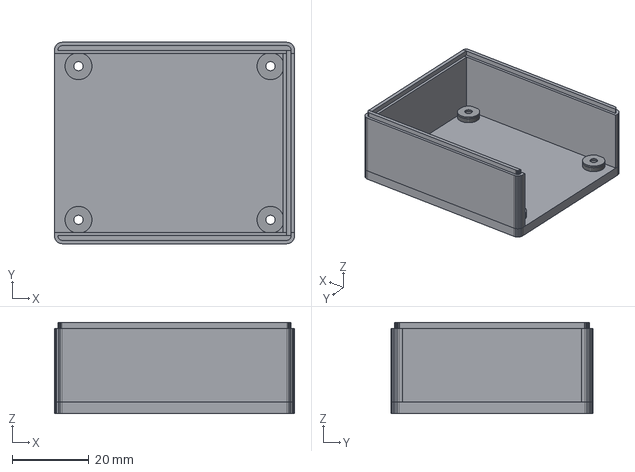
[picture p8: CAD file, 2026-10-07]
LauPythonCamera_Pt_Stack/3dmodels/camera_base_box.step
62.5 x 52.5 x 23.7 mm

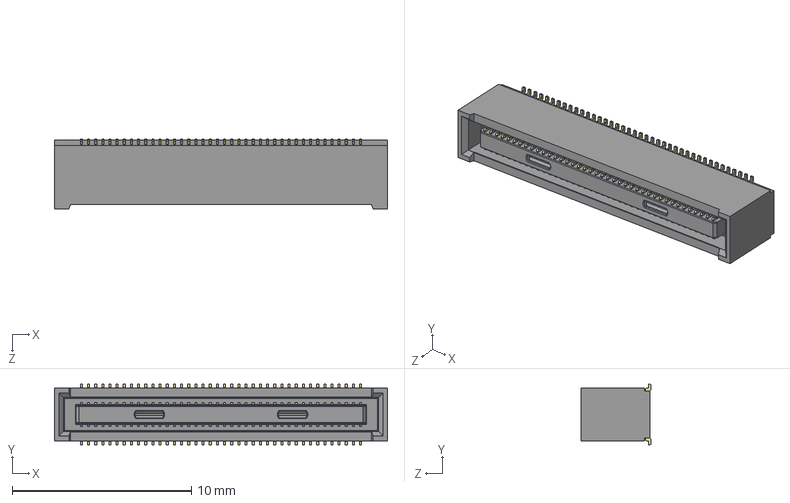
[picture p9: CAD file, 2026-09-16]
LauEsp32Config_Pt_Stack/3dmodels/DF40HC(4.0)-80DS-0.4V(51)_C5254351.step
18.6 x 3.38 x 3.90 mm

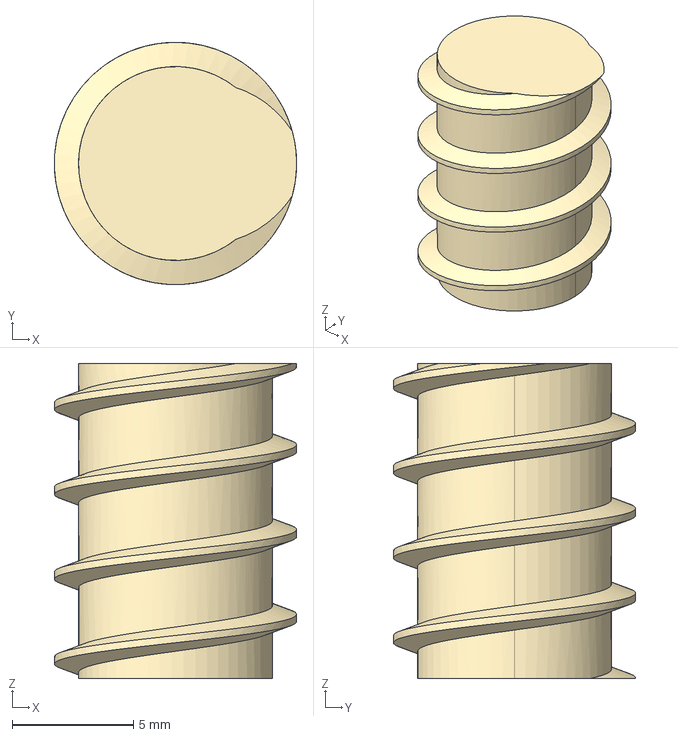
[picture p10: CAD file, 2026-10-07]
LauPythonCamera_Pt_Stack/3dmodels/insert_quarter20.step
10.00 x 10.00 x 13.0 mm

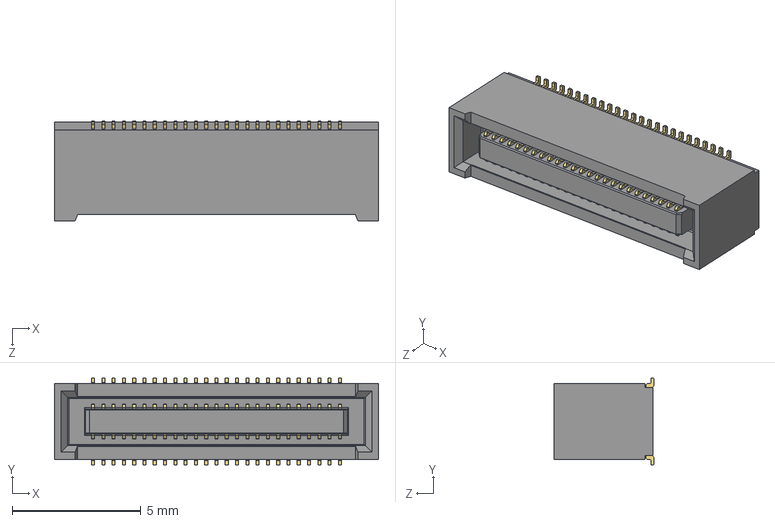
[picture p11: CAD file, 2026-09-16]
LauEsp32Config_Pt_Stack/3dmodels/DF40HC(4.0)-50DS-0.4V(51)_C5338326.step
12.6 x 3.38 x 3.90 mm

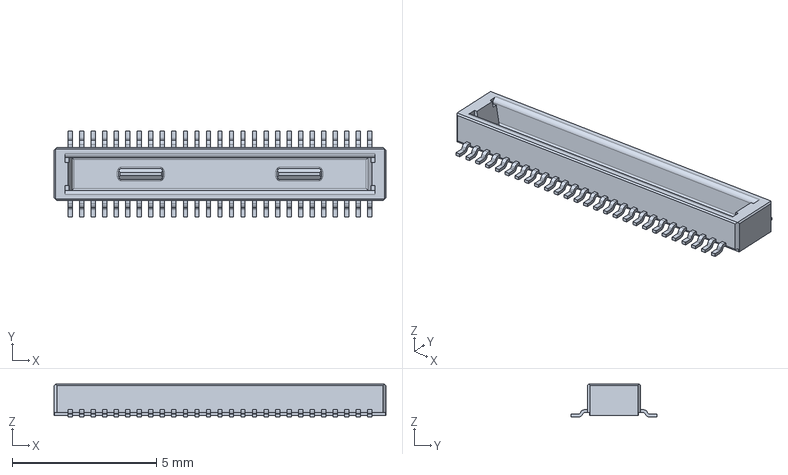
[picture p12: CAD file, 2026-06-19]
LauEsp32Config_Pt_Stack/3dmodels/DF40C-50DP.step
11.5 x 2.97 x 1.14 mm

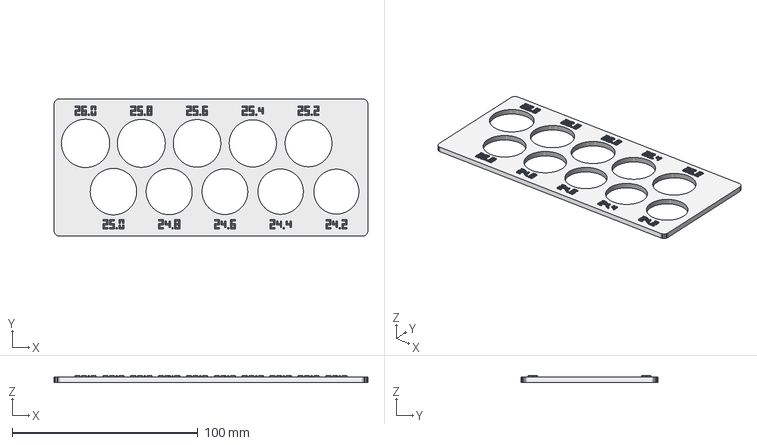
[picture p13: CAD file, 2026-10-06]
LauPythonCamera_Pt_Stack/3dmodels/bore_test_plate.step
169.0 x 74.0 x 3.60 mm

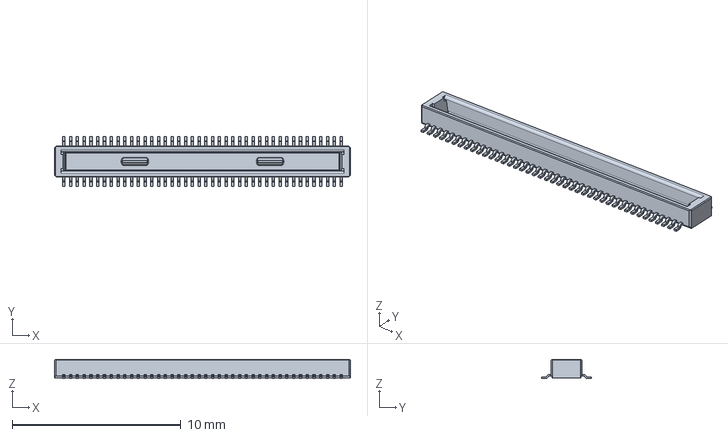
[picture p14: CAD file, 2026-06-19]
LauEsp32Config_Pt_Stack/3dmodels/DF40C-80DP.step
17.5 x 2.97 x 1.14 mm

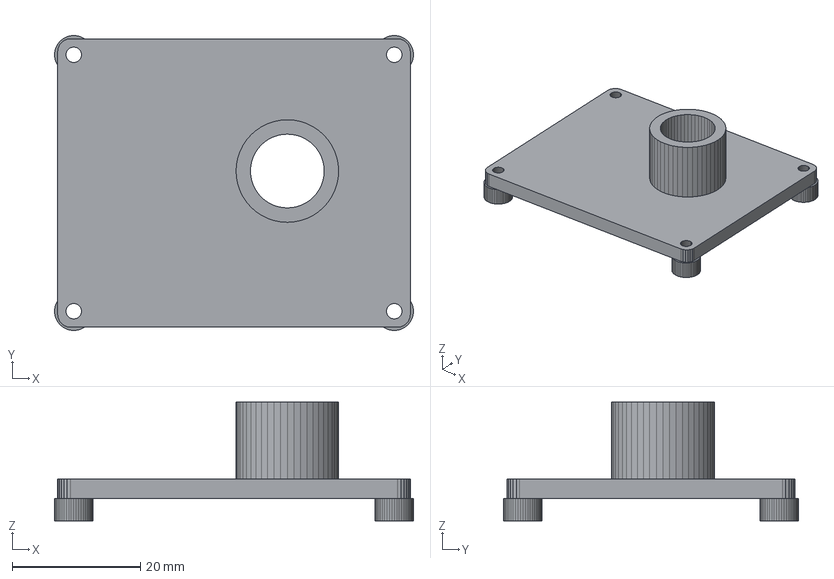
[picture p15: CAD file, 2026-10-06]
LauPythonCamera_Pt_Stack/3dmodels/camera_lens_holder.step
56.0 x 46.0 x 18.5 mm

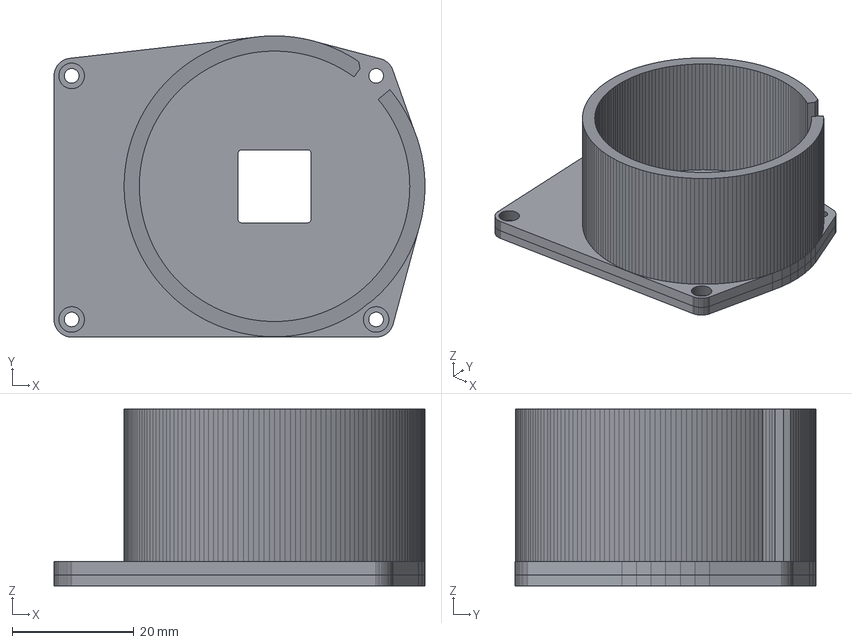
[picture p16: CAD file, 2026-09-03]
LauPythonCamera_Pt_Stack/3dmodels/projector_lens_cap.step
60.9 x 49.5 x 29.0 mm

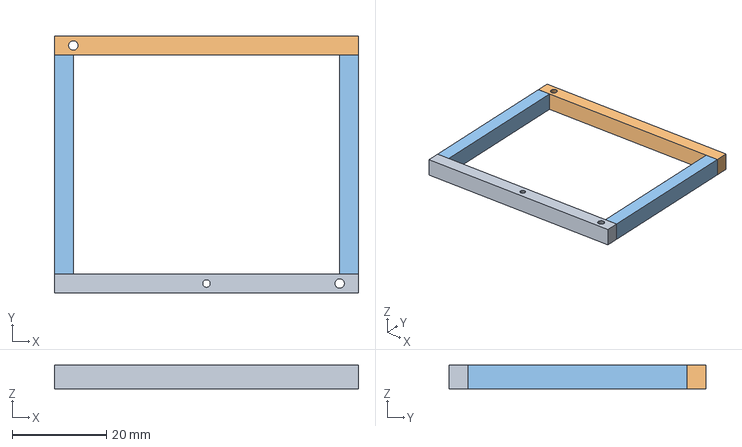
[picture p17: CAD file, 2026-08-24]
LauPythonCamera_Pt_Stack/3dmodels/stack_shroud_hd.step
64.5 x 54.5 x 5.03 mm

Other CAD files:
LauPythonCamera_Pt_Stack/3dmodels/stack_shroud_ftplus.step
LauPythonCamera_Pt_Stack/3dmodels/stack_shroud_pt.step
LauPythonCamera_Pt_Stack/3dmodels/stack_shroud_camera.step
LauPythonCamera_Pt_Stack/3dmodels/PYTHON1300_NOIP1SN1300A_LCC48.step
LauPythonCamera_Pt_Stack/3dmodels/NOIP1SN1300A_LCC48.step
LauPythonCamera_Pt_Stack/3dmodels/NOIP1SN1300A_LCC48.stl
LauPythonCamera_Pt_Stack/3dmodels/bore_test_plate.stl
LauPythonCamera_Pt_Stack/3dmodels/camera_base_box.stl
LauPythonCamera_Pt_Stack/3dmodels/camera_enclosure_assembly.stl
LauPythonCamera_Pt_Stack/3dmodels/camera_lens_box.stl
LauPythonCamera_Pt_Stack/3dmodels/camera_lens_holder.stl
LauPythonCamera_Pt_Stack/3dmodels/camera_socket_tile.step
LauPythonCamera_Pt_Stack/3dmodels/camera_socket_tile.stl
LauPythonCamera_Pt_Stack/3dmodels/insert_quarter20.stl
LauPythonCamera_Pt_Stack/3dmodels/projector_lens_cap.stl
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

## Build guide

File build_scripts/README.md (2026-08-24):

# build_scripts/

Historical Vivado build scripts, rescued from the (gitignored) `build/` directory
before it was deleted. They were the only copies in existence.

**These are not the current build.** The current builds are repo-root TCL scripts
that read straight from the git-tracked RTL and XDC, with no Vivado project and no
zip:

| Script | Part | Contents |
|---|---|---|
| [`build_merged.tcl`](../build_merged.tcl) | XC7A100T (Pt V2) | **The current design** — HDMI/SLI + camera + Ft+ in one bitstream |
| [`build.tcl`](../build.tcl) | XC7A35T (Au V2) | The original HDMI/SLI-only design |
| [`build_pt.tcl`](../build_pt.tcl) | XC7A100T | **Stale** — predates M2, no longer reads `cam_frame_ft.v` |

```
vivado -mode batch -source build_merged.tcl
```

Everything below predates that. They are **project-mode** scripts: they operate on
an unzipped Vivado project in `build/Au2_SLI` (regenerated from `Au2_SLI.zip`), so
they will not run as-is against a fresh checkout — `build/` no longer exists. They
are kept for reference: each documents how a particular experiment was built, and
several carry design notes in their headers.

| script | what it built |
|---|---|
| `build_stackb.tcl`  | Functional SLI build with Camera-1 + config switches remapped to Bank B (LauCameraTrigger stack board). Superseded — Bank B is now active in the tracked `Au2.xdc`, so root `build.tcl` produces this. |
| `build_pat.tcl` | Offline pattern-generator build. |
| `build_outclk.tcl`  | Output-clock / EDID-auto experiments (Phase D). |
| `build_drpA.tcl` | DRP clock-reconfiguration bring-up. |
| `build_uart.tcl` | UART/telemetry build. |
| `build_port1.tcl`, `build_port2.tcl`, `build_port2b.tcl` | Port/pin-mapping experiments. |
| `elab_check.tcl` | Elaboration-only syntax check (fast, no synthesis). |

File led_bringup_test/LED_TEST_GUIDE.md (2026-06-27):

# Stack-Board LED Continuity Test — Guide

A bring-up smoke test for the **LauCameraTrigger_Alchitry_Stack** board. The 8 user
LEDs on the Alchitry Au V2 mirror the 8 Bank-B signals that travel up through the
stack, so you can verify every camera GPIO and DIP-switch line with your eyes.

```
   ┌──────────────────────────────────────┐
   │  Stack board   (DF40 plugs, face down)│  ← DIP switch SW1 + MASTER/SLV JSTs
   ├──────────────────────────────────────┤
   │  Hd V2         (passes Bank B through)│
   ├──────────────────────────────────────┤
   │  Au V2         (FPGA + the 8 LEDs)    │  ← reads Bank B, lights the LEDs
   └──────────────────────────────────────┘
```

The FPGA drives **nothing** on the signal pins — all eight are **inputs**. It only
reads each line and lights the matching LED. Pure continuity check.

---

## The 8 LEDs on the Au V2

LEDs sit in a single row on the Au V2 board, `led0` … `led7`. Each lights when its
line is driven **HIGH**; all are **OFF at rest** (internal pull-downs).

```
            CAMERA GPIO  (MASTER JST)          DIP SWITCH  (SW1)
        ┌───────────────────────────┐   ┌───────────────────────────┐

 LED:   ● led0   ● led1   ● led2   ● led3   ● led4   ● led5   ● led6   ● led7

 SIG:  CAM_READY CAM_TRIG CAM_PAT  CAM_MODE  HVSV     BLUE     GREEN    RED

 BALL:   R11      R16      R10      R15       K5       N16      E6       M16

 DF40:    27       28       29       30       33       34       35       36

 JST:    pin5     pin2     pin4     pin3      —        —        —        —
 SW1:     —        —        —        —       SW1-1    SW1-2    SW1-3    SW1-4
```

> `CAM_PAT` = `CAM_PATTERN`. JST pins are on the **MASTER** connector.

---

## Mapping table

| LED  | Signal | Au ball | DF40 pin | Driven by |
|---|---|:---:|:---:|---|
| led0 | `CAM_READY` | R11 | 27 | Camera GPIO → MASTER JST pin 5  |
| led1 | `CAM_TRIG` | R16 | 28 | Camera GPIO → MASTER JST pin 2  |
| led2 | `CAM_PATTERN` | R10 | 29 | Camera GPIO → MASTER JST pin 4  |
| led3 | `CAM_MODE` | R15 | 30 | Camera GPIO → MASTER JST pin 3  |
| led4 | `SW_HVSV` | K5 | 33 | DIP SW1-1 |
| led5 | `SW_BLUE` | N16 | 34 | DIP SW1-2 |
| led6 | `SW_GREEN` | E6 | 35 | DIP SW1-3 |
| led7 | `SW_RED` | M16 | 36 | DIP SW1-4 |

Pins from `ROADMAP.md §5.2` (Bank A low → Bank B high remap).

---

## How to run the test

1. **Stack the boards:** Stack board → Hd V2 → Au V2. Plug the camera cable into
   the **MASTER JST**.
2. **Flash** `led_test.bin` via `..\AlchitryFlasher\AlchitryFlasher.cmd`
   (Step 3 → choose **RAM / temporary** so a power-cycle restores your normal image).
3. **Camera lines (led0–led3):** in the **Pylon viewer**, configure all four camera
   GPIO lines as **outputs (push-pull)** and toggle each one. Push-pull cleanly
   overrides the internal pull-downs.
   - led0 ON ⇒ `CAM_READY` continuity good. led1 ⇒ `CAM_TRIG`, led2 ⇒ `CAM_PATTERN`,
     led3 ⇒ `CAM_MODE`.
4. **DIP switches (led4–led7):** flip each of SW1's four positions.
   - One orientation ties the net to **+3V3** (LED **on**), the other to **GND**
     (LED **off**). SW1-1 ⇒ led4 (HVSV), SW1-2 ⇒ led5 (BLUE), SW1-3 ⇒ led6 (GREEN),
     SW1-4 ⇒ led7 (RED).

### Pass / fail

- **LED follows its line** → that ball + the full DF40 → Hd → Au path is good. ✅
- **LED never lights** → open/continuity fault on that net (check the DF40 solder
  joint, the JST crimp, or the switch).
- **LED stuck on** → short to +3V3, or a wrong/bridged net.

---

## Notes

- This test uses an **all-pull-down** constraint for clean "high = on" semantics.
  The *functional* `Au2.xdc` Bank-B remap should instead use the mixed
  pull-up/down from `ROADMAP.md §5.2` (safe SLI defaults).
- Build/flash details and the source are in [`README.md`](README.md);
  RTL is [`led_test_top.v`](led_test_top.v), pins are [`led_test.xdc`](led_test.xdc).

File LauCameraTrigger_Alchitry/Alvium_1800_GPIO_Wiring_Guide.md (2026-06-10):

# Allied Vision Alvium 1800 USB GPIO Wiring Guide

## FPGA Slave Mode Configuration

This document describes the GPIO wiring between an Allied Vision Alvium 1800 USB camera and an FPGA that synchronizes the camera to an HDMI signal.

---

## Alvium 1800 USB I/O Connector Pinout

**Connector Type:** JST BM07B-SRSS-TBT (7-pin)

**Pin 1 is closest to the screw lock hole on the camera body.**

| Pin | Signal Name | Software Name | Wire Color (12322 cable) |
|-----|---|---|---|
| 1 | GND | — | Black |
| 2 | EXT-GPIO 0  | **Line0** | Brown |
| 3 | EXT-GPIO 1  | **Line1** | Orange |
| 4 | EXT-GPIO 2  | **Line2** | Yellow |
| 5 | EXT-GPIO 3  | **Line3** | Green |
| 6 | Don't care  | — | — |
| 7 | Don't care  | — | — |

---

## Complete Wiring Chart for FPGA Slave Mode

| JST Pin | Wire Color | Signal | Direction | Software Setting | Connect to FPGA |
|---|---|---|---|---|---|
| **1** | Black | GND | — | — | FPGA GND |
| **2** | Brown | Line0  | INPUT | TriggerSource=Line0, RisingEdge | FPGA Trigger Output |
| **3** | Orange | Line1  | OUTPUT | LineSource=Off, Inverted | FPGA: SLI/HDMI Mode Select  |
| **4** | Yellow | Line2  | INPUT | LineMode=Input | FPGA: Pattern Zero Status |
| **5** | Green | Line3  | OUTPUT | LineSource=FrameTriggerWait, Inverted  | FPGA: Camera Ready Signal |

---

## Wiring Diagram

```
Allied Vision Alvium 1800 USB                Your FPGA
(JST 7-pin connector, Pin 1 closest to screw lock hole)
───────────────────────────────────────────────────────────
Pin 1 (Black)  - GND    ──────────────────  GND (common ground)
Pin 2 (Brown)  - Line0  ◄─────────────────  Trigger Output
Pin 3 (Orange) - Line1  ──────────────────► SLI/HDMI Mode Input
Pin 4 (Yellow) - Line2  ◄─────────────────  Pattern Status Output
Pin 5 (Green)  - Line3  ──────────────────► Camera Ready Input
```

---

## DB9 Connector Wiring (FPGA Interface)

This section describes how to wire the AVT Alvium camera to a DB9 connector for interfacing with an FPGA. The mapping is based on compatibility with existing Basler ACE USB camera wiring.

### DB9 Pin Functions (from FPGA perspective)

| DB9 Pin | FPGA Pin | FPGA Signal | FPGA Direction | Description |
|---|---|---|---|---|
| 1 | — | GND | — | Ground |
| 4 | A29_1 | Pattern frame out  | Output | Sends pattern frame indicator TO camera |
| 5 | A31_1 | Trigger out | Output | Sends trigger signal TO camera |
| 8 | A32_1 | Camera ready in | Input | Receives camera ready FROM camera |
| 9 | A28_1 | Mode select in | Input | Receives mode switch FROM camera |

### AVT Alvium to DB9 Wiring Table

| AVT JST Pin | AVT Signal | Wire Color | Camera Dir | Function | DB9 Pin | FPGA Pin |
|---|---|---|---|---|---|---|
| 1 | GND | **Black**  | — | Ground | **1** | GND |
| 2 | Line0 | **Brown**  | INPUT | Frame trigger  | **5** | A31_1 |
| 3 | Line1 | **Orange** | OUTPUT | SLI/HDMI mode  | **9** | A28_1 |
| 4 | Line2 | **Yellow** | INPUT | Pattern status | **4** | A29_1 |
| 5 | Line3 | **Green**  | OUTPUT | Camera ready | **8** | A32_1 |

### Quick Reference: Wire Color to DB9

| Wire Color | DB9 Pin |
|---|---|
| Black | 1 |
| Brown | 5 |
| Orange | 9 |
| Yellow | 4 |
| Green | 8 |

### DB9 Wiring Diagram

```
AVT Alvium 1800 USB                            DB9 Female (to FPGA)
(JST 7-pin, Pin 1 closest to screw lock hole)
──────────────────────────────────────────────────────────────────────
Pin 1 (Black)  - GND    [IN]  ─────────────────  Pin 1 (GND)
Pin 2 (Brown)  - Line0  [IN]  ◄────────────────  Pin 5 (A31_1) - Trigger
Pin 3 (Orange) - Line1  [OUT] ─────────────────► Pin 9 (A28_1) - Mode Switch
Pin 4 (Yellow) - Line2  [IN]  ◄────────────────  Pin 4 (A29_1) - Pattern Status
Pin 5 (Green)  - Line3  [OUT] ─────────────────► Pin 8 (A32_1) - Camera Ready
```

### Comparison with Basler ACE USB Wiring

| Function | Basler Line | Basler Pin | AVT Line | AVT JST Pin | AVT Wire | DB9 Pin |
|---|---|---|---|---|---|---|
| Ground | — | 5 & 6 | GND | 1 | Black | 1 |
| Trigger (to camera) | Line 1 | 2 | Line0 | 2 | Brown | 5 |
| Mode switch (from camera) | Line 4 | 3 | Line1 | 3 | Orange | 9 |
| Pattern status (to camera)  | Line 3 | 1 | Line2 | 4 | Yellow | 4 |
| Camera ready (from camera)  | Line 2 | 4 | Line3 | 5 | Green | 8 |

---

## Signal Descriptions

| Signal | Purpose | Behavior |
|---|---|---|
| **Line0** (Brown) | Frame trigger | Rising edge triggers frame capture |
| **Line1** (Orange)  | Mode switch | Inverted output; controls SLI vs HDMI pass-through |
| **Line3** (Green) | Camera ready  | Inverted; goes LOW on wire when camera is ready for next trigger |
| **Line2** (Yellow)  | Pattern sync  | Input from FPGA indicating pattern index/zero status |

---

## Electrical Specifications

| Parameter | Value |
|---|---|
| Output High (Uout) | 2.4 - 3.3 VDC  |
| Output Current (max) | 12 mA |
| External Power (VCC-EXT-IN) | 4.5 - 5.5 VDC  |

---

## Software Configuration (Vimba SDK)

### Trigger Configuration (in connectToHost)

```cpp
setAttribute(handle, "TriggerMode", "On");
setAttribute(handle, "TriggerSelector", "FrameStart");
setAttribute(handle, "TriggerSource", "Line0");
setAttribute(handle, "TriggerActivation", "RisingEdge");
setAttribute(handle, "AcquisitionMode", "MultiFrame");
```

### GPIO Configuration (in setSynchronization for ModeSlave)

```cpp
// Line0 = Trigger INPUT from FPGA
setAttribute(handle, "LineSelector", "Line0");
setAttribute(handle, "LineMode", "Input");
setAttribute(handle, "LineInverter", "false");

// Line2 = Pattern zero status INPUT from FPGA
setAttribute(handle, "LineSelector", "Line2");
setAttribute(handle, "LineMode", "Input");
setAttribute(handle, "LineInverter", "false");

// Line1 = OUTPUT to FPGA (SLI/HDMI mode switch)
setAttribute(handle, "LineSelector", "Line1");
setAttribute(handle, "LineMode", "Output");
setAttribute(handle, "LineInverter", "true");
setAttribute(handle, "LineSource", "Off");

// Line3 = OUTPUT: FrameTriggerWait (camera ready for next trigger)
setAttribute(handle, "LineSelector", "Line3");
setAttribute(handle, "LineMode", "Output");
setAttribute(handle, "LineInverter", "true");
setAttribute(handle, "LineSource", "FrameTriggerWait");
```

---

## Important Notes

1. **Pin 1 identification**: Pin 1 is closest to the screw lock hole on the camera body. The non-screw-lock cable (12319) has **all blue wires** - use a multimeter to verify pin continuity if needed.

2. **Wire colors** apply to Allied Vision cables with screw locks (12322, 12326, 12327).

3. **Inverted signals**: Line1 and Line3 are configured with `LineInverter = true`, so the physical voltage is opposite to the logical state.

4. **3.3V Logic**: The GPIO outputs are 3.3V logic level - ensure your FPGA inputs are compatible.

5. **No pull-ups required**: Unlike the Basler ACE USB (which has open-collector opto-isolated outputs requiring pull-up resistors), the Alvium's GPIO lines are all **3.3V push-pull** and can drive the FPGA inputs directly. The Mimas A7 PCB includes pull-up resistors on the FPGA input lines (DB9 pins 8 and 9) for Basler compatibility — these are harmless when using an Alvium but not necessary.

6. **Handshaking**: The FPGA should wait for Line3 (FrameTriggerWait) to indicate the camera is ready before sending the next trigger pulse on Line0.

---

## FPGA Compatibility (MimasA7-SLI vs AuV2-SLI)

The same DB-9 cable described above is wire-level compatible with both FPGAs — the DB-9 pin functions and FPGA directions match exactly.

- **MimasA7-SLI** (Numato Mimas A7 Rev3): uses the [`LauCameraTrigger_MimasA7`](https://github.com/ruffner/MojoV3_HDMI_Interface/tree/master/pcb/LauCameraTrigger_MimasA7) breakout PCB. Adds pull-ups on DB-9 pins 8 and 9 (FPGA-input lines) and level shifting for the 5–24V Basler opto-trigger. Single camera channel.
- **AuV2-SLI** (Alchitry Au V2 + Hd V2 + Br V2): uses the stock Alchitry Br V2 breakout. DB-9 pin functions are identical. The Br V2 does **not** add pull-ups or level shifting — fine for the Alvium (3.3V push-pull), but a Basler would need them added externally. Two camera channels exposed on the DB-9.

### Camera 2 on AuV2-SLI: outputs-only in current bitstream

The AuV2 README lists a second camera channel on DB-9 pins 2, 3, 6, 7, but in `constrs_1/imports/RTL/Au2.xdc` the `C2_in[0]` (DB-9 pin 7 / camera-ready) and `C2_in[1]` (DB-9 pin 2 / mode) constraints are **commented out**. Only `C2_out[0]` (trigger, DB-9 6) and `C2_out[1]` (first frame, DB-9 3) are bound. Camera 2 therefore runs open-loop with no `FrameTriggerWait` handshake until the XDC is updated upstream.

---

## Cable Part Numbers

| Part Number | Description |
|---|---|
| 12322 | I/O cable 7-pin JST with screw locks, 3m (color-coded wires)  |
| 12326 | I/O cable 7-pin JST with screw locks, 5m (color-coded wires)  |
| 12327 | I/O cable 7-pin JST with screw locks, 10m (color-coded wires) |
| 12319 | I/O cable 7-pin JST without screw lock, 0.4m (all blue wires) |

---

## References

### Camera Documentation
- [Allied Vision Alvium Pin Assignment PDF](https://cdn.alliedvision.com/fileadmin/content/documents/products/cameras/Alvium_common/appnote/Alvium_Pin-Assignment.pdf)
- [Alvium USB Cameras User Guide](https://cdn.alliedvision.com/fileadmin/content/documents/products/cameras/Alvium_USB/techman/Alvium-USB-Cameras_User-Guide.pdf)
- [ManualsLib - Alvium Series Manual](https://www.manualslib.com/manual/1679546/Allied-Vision-Alvium-Series.html?page=77)
- [DigiKey - Allied Vision 12322 Cable](https://www.digikey.com/en/products/detail/allied-vision-inc/12322/11200629)

### FPGA Code Repositories
- [MimasA7-SLI](https://github.com/Qishi-Hu/MimasA7-SLI) - Structured light illumination system using Numato Mimas A7 Rev3 board (Artix-7 FPGA, VHDL)
- [AuV2-SLI](https://github.com/Qishi-Hu/AuV2-SLI) - Structured light illumination system using Alchitry Au V2 board (Artix-7 FPGA, VHDL)

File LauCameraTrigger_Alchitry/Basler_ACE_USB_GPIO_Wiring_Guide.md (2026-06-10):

# Basler ACE USB 3.0 GPIO Wiring Guide

## FPGA Slave Mode Configuration

This document describes the GPIO wiring between a Basler ACE USB 3.0 camera and an FPGA that synchronizes the camera to an HDMI signal.

---

## Basler ACE USB 3.0 I/O Connector Pinout

**Connector Type:** Hirose 6-pin [HR10A-7P-6S (73)]

| Pin | Signal Name | Line | Type | Direction |
|-----|---|---|---|---|
| 1 | GPIO | **Line 3** | TTL (direct-coupled) | Input/Output |
| 2 | Opto-isolated IN  | **Line 1** | Opto-isolated | Input only |
| 3 | GPIO | **Line 4** | TTL (direct-coupled) | Input/Output |
| 4 | Opto-isolated OUT | **Line 2** | Opto-isolated | Output only  |
| 5 | Opto Ground | — | Ground | — |
| 6 | GPIO Ground | — | Ground | — |

---

## Opto-GP-I/O Y-Cable Wire Colors

The Basler Opto-GP-I/O Y-Cable (Part# 2000034088) splits into two branches:

### Blue Jacket Cable (Opto-Isolated Signals)

| Pin | Wire Color | Signal | Line |
|-----|---|---|---|
| 2 | **Brown** | Opto-isolated IN  | Line 1 |
| 4 | **Yellow** | Opto-isolated OUT | Line 2 |
| 5 | **White/Green** | Opto Ground | — |

### Yellow Jacket Cable (TTL GPIO Signals)

| Pin | Wire Color | Signal | Line |
|-----|---|---|---|
| 1 | **Brown** | GPIO | Line 3 |
| 3 | **Yellow** | GPIO | Line 4 |
| 6 | **White/Green** | GPIO Ground | — |

---

## Complete Wiring Chart for FPGA Slave Mode

| Basler Pin | Basler Line | Type | Camera Dir | Function | Cable  | Wire Color  |
|---|---|---|---|---|---|---|
| 2 | Line 1 | Opto IN  | INPUT | Frame trigger  | Blue | Brown |
| 1 | Line 3 | TTL GPIO | INPUT | Pattern status | Yellow | Brown |
| 4 | Line 2 | Opto OUT | OUTPUT | Camera ready | Blue | Yellow |
| 3 | Line 4 | TTL GPIO | OUTPUT | Mode switch | Yellow | Yellow |
| 5 | — | Opto GND | — | Ground | Blue | White/Green |
| 6 | — | GPIO GND | — | Ground | Yellow | White/Green |

---

## DB9 Connector Wiring (FPGA Interface)

### DB9 Pin Functions (from FPGA perspective)

| DB9 Pin | FPGA Signal | FPGA Direction | Description |
|---|---|---|---|
| 1 | GND | — | Ground |
| 4 | Pattern frame out | Output | Sends pattern status TO camera (Line 3) |
| 5 | Frame trigger out | Output | Sends frame trigger TO camera (Line 1) |
| 8 | Camera ready in | Input | Receives camera ready FROM camera (Line 2) |
| 9 | Mode select in | Input | Receives mode switch FROM camera (Line 4)  |

### Basler ACE USB to DB9 Wiring Table

| Basler Pin | Basler Line | Cable  | Wire Color | Camera Dir | Function | DB9 Pin | FPGA Signal |
|---|---|---|---|---|---|---|---|
| 2 | Line 1 | Blue | **Brown** | INPUT | Frame trigger  | **5** | Frame trigger out |
| 1 | Line 3 | Yellow | **Brown** | INPUT | Pattern status | **4** | Pattern frame out |
| 4 | Line 2 | Blue | **Yellow** | OUTPUT | Camera ready | **8** | Camera ready in |
| 3 | Line 4 | Yellow | **Yellow** | OUTPUT | Mode switch | **9** | Mode select in |
| 5 | — | Blue | **White/Green** | — | Opto Ground | **1** | GND |
| 6 | — | Yellow | **White/Green** | — | GPIO Ground | **1** | GND |

### Quick Reference: Wire to DB9

| Cable  | Wire Color  | DB9 Pin |
|---|---|---|
| Blue | Brown | 5 |
| Blue | Yellow | 8 |
| Blue | White/Green | 1 |
| Yellow | Brown | 4 |
| Yellow | Yellow | 9 |
| Yellow | White/Green | 1 |

### DB9 Wiring Diagram

```
Basler ACE USB 3.0                                  DB9 Female (to FPGA)
(Hirose 6-pin)
──────────────────────────────────────────────────────────────────────────
Pin 2 (Blue/Brown)    - Line 1 [IN]  ◄─────────────  Pin 5 (Frame trigger out) - Trigger
Pin 1 (Yellow/Brown)  - Line 3 [IN]  ◄─────────────  Pin 4 (Pattern frame out) - Pattern Status
Pin 4 (Blue/Yellow)   - Line 2 [OUT] ──────────────► Pin 8 (Camera ready in)   - Camera Ready
Pin 3 (Yellow/Yellow) - Line 4 [OUT] ──────────────► Pin 9 (Mode select in)    - Mode Switch
Pin 5 (Blue/Wht-Grn)  - Opto GND    ──────────────  Pin 1 (GND)
Pin 6 (Yellow/Wht-Grn)- GPIO GND    ──────────────  Pin 1 (GND)
```

---

## Signal Descriptions

| Signal | Line  | Purpose | Behavior |
|---|---|---|---|
| **Line 1** (Opto IN) | Pin 2 | Frame trigger  | Rising edge triggers frame capture (opto-isolated for noise immunity) |
| **Line 3** (GPIO) | Pin 1 | Pattern status | Input from FPGA indicating pattern index/zero status |
| **Line 2** (Opto OUT)  | Pin 4 | Camera ready | Indicates camera is ready for next trigger |
| **Line 4** (GPIO) | Pin 3 | Mode switch | Output for SLI vs HDMI pass-through control |

---

## Electrical Specifications

### Opto-Isolated Input (Line 1)

| Parameter | Value |
|---|---|
| Input Voltage (VIL)  | 0 - 2.0 VDC |
| Input Voltage (VIH)  | 5.0 - 24.0 VDC |
| Max Input Voltage | 24 VDC |
| Input Current | ~8 mA typical |

### Opto-Isolated Output (Line 2)

| Parameter | Value |
|---|---|
| Output Type | Open collector |
| Max Sink Current | 25 mA |
| Max Voltage | 24 VDC |

### TTL GPIO (Line 3, Line 4)

| Parameter | Value |
|---|---|
| Logic Levels | 3.3V TTL |
| Output High (VOH)  | 2.4 - 3.3 VDC |
| Output Low (VOL) | 0 - 0.4 VDC |
| Input High (VIH) | 2.0 - 3.3 VDC |
| Input Low (VIL) | 0 - 0.8 VDC |

---

## Software Configuration (Pylon SDK)

### Trigger Configuration

```cpp
camera.TriggerSelector.SetValue(TriggerSelector_FrameStart);
camera.TriggerMode.SetValue(TriggerMode_On);
camera.TriggerSource.SetValue(TriggerSource_Line1);
camera.TriggerActivation.SetValue(TriggerActivation_RisingEdge);
```

### GPIO Configuration

```cpp
// Line 3 as Input (Pattern Status from FPGA)
camera.LineSelector.SetValue(LineSelector_Line3);
camera.LineMode.SetValue(LineMode_Input);

// Line 4 as Output (Mode Switch to FPGA)
camera.LineSelector.SetValue(LineSelector_Line4);
camera.LineMode.SetValue(LineMode_Output);
camera.LineSource.SetValue(LineSource_UserOutput1);

// Line 2 as Output (Camera Ready - typically automatic)
camera.LineSelector.SetValue(LineSelector_Line2);
camera.LineSource.SetValue(LineSource_ExposureActive);
```

---

## Important Notes

1. **Opto-isolated vs TTL**: Line 1 (opto-isolated input) is more robust against EMI than the TTL GPIO lines. Use Line 1 for the trigger signal in noisy environments.

2. **Pull-ups required for open-collector output**: Line 2 (opto-isolated output, camera ready) is an **open-collector** output — it can only sink current to ground but cannot drive a high level. A **pull-up resistor** is required on the FPGA input side for a valid logic high. The Mimas A7 PCB includes pull-up resistors on the FPGA input lines (DB9 pins 8 and 9) for this reason. Unlike the Basler, the Alvium 1800 USB has push-pull 3.3V GPIO outputs and does not require pull-ups.

3. **Opto-isolated input voltage**: Line 1 (opto-isolated input, trigger) requires **5–24V** to drive the internal opto-coupler. The FPGA's 3.3V GPIO output may not reliably trigger it — verify that the Mimas A7 PCB provides level shifting or a higher voltage supply for this line.

4. **Ground connections**: Both ground wires (Pin 5 Opto Ground and Pin 6 GPIO Ground) should be connected to ground for optimal signal-to-noise ratio.

5. **Unused GPIO lines**: If not using a GPIO line, connect its wire to ground to reduce noise.

6. **Y-Cable identification**: The blue jacket cable connects to opto-isolated pins; the yellow jacket cable connects to TTL GPIO pins.

7. **3.3V Logic**: The TTL GPIO outputs (Line 3, Line 4) are 3.3V logic level - ensure your FPGA inputs are compatible.

---

## FPGA Compatibility (MimasA7-SLI vs AuV2-SLI)

The DB-9 pin functions and FPGA directions are identical between the two FPGAs, so wire-level the same Basler cable harness can plug into either. However, the breakout-board electrical support differs:

- **MimasA7-SLI** (Numato Mimas A7 Rev3): uses the [`LauCameraTrigger_MimasA7`](https://github.com/ruffner/MojoV3_HDMI_Interface/tree/master/pcb/LauCameraTrigger_MimasA7) PCB. Includes the pull-ups on DB-9 pins 8 and 9 that the Basler open-collector Line 2 needs, and provides the 5–24V drive required by the opto-isolated Line 1 trigger. Single camera channel.
- **AuV2-SLI** (Alchitry Au V2 + Hd V2 + Br V2): uses the stock Br V2 breakout. The DB-9 pinout is the same, but the Br V2 does **not** add pull-ups for the open-collector Line 2 output, nor does it level-shift the trigger line above 3.3V. For a Basler camera on the AuV2 you must add an external pull-up on DB-9 pin 8 (and pin 9 if using Line 4) and either a level shifter or higher-voltage drive on DB-9 pin 5 to reliably fire Line 1. The Alvium 1800 (push-pull 3.3V) works on the AuV2 with no extra circuitry.

### Camera 2 on AuV2-SLI: outputs-only in current bitstream

The AuV2 exposes a second camera channel on DB-9 pins 2, 3, 6, 7, but in `constrs_1/imports/RTL/Au2.xdc` the `C2_in[0]` (DB-9 pin 7 / camera-ready) and `C2_in[1]` (DB-9 pin 2 / mode) constraints are **commented out**. Only `C2_out[0]` (trigger, DB-9 6) and `C2_out[1]` (first frame, DB-9 3) are bound. Camera 2 therefore runs open-loop with no camera-ready handshake until the XDC is updated upstream.

---

## Cable Part Numbers

| Part Number | Description |
|---|---|
| 2000034088  | Opto-GP-I/O Y-Cable, HRS 6p/open, 2 x 10 m (both opto and GPIO) |
| 2000034087  | GP-I/O Cable, HRS 6p/open, 10 m (GPIO only) |
| 2000034084  | Power-I/O Cable, HRS 6p/open, 10 m (power + opto I/O) |

---

## Comparison with AVT Alvium 1800 USB

| Function | Basler Line | Basler Pin | AVT Line | AVT JST Pin | DB9 Pin |
|---|---|---|---|---|---|
| Trigger (to camera) | Line 1 (Opto)  | 2 | Line0 | 2 | 5 |
| Pattern status (to camera)  | Line 3 (GPIO)  | 1 | Line2 | 4 | 4 |
| Camera ready (from camera)  | Line 2 (Opto)  | 4 | Line3 | 5 | 8 |
| Mode switch (from camera) | Line 4 (GPIO)  | 3 | Line1 | 3 | 9 |
| Ground | — | 5 & 6 | GND | 1 | 1 |

---

## References

### Camera Documentation
- [Basler Opto-GP-I/O Y-Cable Documentation](https://docs.baslerweb.com/basler-opto-gp-io-y-cable-hrs-6p-open-p-2x10m)
- [Basler GP-I/O Cable Documentation](https://docs.baslerweb.com/basler-gp-io-cable-hrs-6p-open-p)
- [Basler ACE Circuit Diagrams](https://docs.baslerweb.com/circuit-diagrams-(ace))
- [Basler ACE USB 3.0 User Manual](https://www.micropticsl.com/wp-content/uploads/2013/09/basler_ace_usb_manual.pdf)

### FPGA Code Repositories
- [MimasA7-SLI](https://github.com/Qishi-Hu/MimasA7-SLI) - Structured light illumination system using Numato Mimas A7 Rev3 board (Artix-7 FPGA, VHDL)
- [AuV2-SLI](https://github.com/Qishi-Hu/AuV2-SLI) - Structured light illumination system using Alchitry Au V2 board (Artix-7 FPGA, VHDL)

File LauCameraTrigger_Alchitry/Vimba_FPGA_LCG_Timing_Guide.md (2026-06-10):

# Vimba Camera FPGA-Triggered LCG Timing Guide

This document describes the camera timing and GPIO handshake required for FPGA-triggered LCG (Liquid Crystal Grating) structured light scanning with Allied Vision (Vimba) cameras.

## Overview

The FPGA controls both the projector pattern sequence and the camera triggers. The camera captures one frame per projector pattern, synchronized via GPIO lines. Two applications use this pipeline:

- **LAU3DVideoRecorder** — full 3D scanning with DFT phase computation (async callback capture)
- **LAUMultiPathRecorder** — raw frame recording for debugging/analysis (synchronous capture)

## Camera Settings

| Setting | Value | Notes |
|---|---|---|
| AcquisitionMode | MultiFrame | Camera knows exact frame count |
| AcquisitionFrameCount | N (e.g. 28) | 24 depth + 4 flashing for 8-8-8 |
| TriggerMode | On | External trigger from FPGA |
| TriggerSource | Line0 | FPGA sends rising edges on Line0 |
| TriggerActivation | RisingEdge | |
| TriggerDelay | 17167 us | 1/60s + 500us (see below) |
| ExposureMode | Timed | |
| ExposureTime | 8333 us | Fixed at 1/120s in FPGA mode |
| PixelFormat | Mono12 | 12-bit LSB-aligned, no bit shifting |
| LineDebounceDuration | 10 us | Noise filter on Line0 trigger input |

## GPIO Wiring

| Camera Line | Direction | Function |
|---|---|---|
| Line0 | Input | Frame trigger from FPGA |
| Line1 | Output | Start/stop signal to FPGA |
| Line3 | Output | FrameTriggerWait — tells FPGA camera is ready |

## GPIO Setup (setSynchronization)

```
Line0: Input, LineInverter=false
Line1: Output, LineSource=Off, LineInverter=false (starts low)
Line3: Output, LineSource=FrameTriggerWait, LineInverter=false
```

## Capture Sequence

### LAU3DVideoRecorder (Async Callbacks)

```
1. Queue all frames with FrameDoneXYZGCallback
2. AcquisitionStart for all cameras
3. Line1: false -> true  (reset FPGA counter, start patterns)
4. FrameTriggerWait on Line3 paces each trigger automatically
5. Callbacks fire as frames arrive, filling depth/color buffers
6. After all frames received:
   - AcquisitionStop
   - Line1: true -> false (stop FPGA)
```

### LAUMultiPathRecorder (Synchronous)

```
1. VmbCaptureStart
2. Queue N pFrames (nullptr callback)
3. AcquisitionStart
4. Line1: false -> true  (reset FPGA counter, start patterns)
5. VmbCaptureFrameWait for each frame, copy to depth buffer
6. AcquisitionStop
7. Line1: true -> false (stop FPGA)
8. VmbCaptureEnd + VmbCaptureQueueFlush
```

## Critical Timing Issues

### Spurious First Trigger

When Line1 transitions from low to high, PCB crosstalk between Line1 and Line0 causes a spurious trigger. The camera captures a frame of the projector's black/idle pattern.

**Solution:** A trigger delay of 17167us (one 60Hz frame + 500us margin) delays the actual exposure past the spurious trigger. By the time the camera exposes, the FPGA has advanced to the first real pattern.

### Frame Ordering

Frames must be queued BEFORE Line1 goes high. If frames are queued after the FPGA starts, the first triggers have no buffers to land in, causing missed or out-of-order frames. This was a bug in the original code where Line1/Line3 toggling happened before frame queuing.

### FrameTriggerWait Polarity

Line3 outputs the FrameTriggerWait signal with LineInverter=false. The FPGA watches this line and only sends the next trigger when the camera signals it is ready. This prevents triggers from arriving faster than the camera can read out frames, which is critical at full resolution (4112x2176).

### No Bit Shifting for Mono12

Vimba Mono12 delivers 12-bit pixel data LSB-aligned in 16-bit words (range 0-4095). The DFT filter uses signed 16-bit multiplication (`_mm_mulhi_epi16`), so values must stay within the signed range (0-32767). The old Prosilica code shifted bits left by 4 to fill 16 bits (range 0-65520), which caused values above 32767 to be misinterpreted as negative, corrupting the DFT phase computation.

**Rule:** Do NOT shift Mono12 or Mono10 pixel data. Only Mono8 data needs conversion when copied into unsigned short buffers (shift left by 4).

## Projector Frame Rate

The trigger delay and exposure are tuned for a 60Hz projector:

- Trigger delay: 17167us = 1/60s + 500us
- Exposure: 8333us = 1/120s (half the frame period to avoid capturing during pattern transitions)

If the projector runs at a different rate, scale these values accordingly:
- Trigger delay = 1/fps + 500us
- Exposure = 1/(2*fps)

## Pattern Sequences

For PatternEightEightEight with SchemeFlashingSequence:
- 24 depth frames (3 frequencies x 8 phase steps)
- 4 flashing sequence frames (for calibration)
- Total: 28 frames per scan

The vimbaFrameMapping list maps callback frame indices to interleaved channel positions in the depth and color memory objects. Positive indices go to depth, negative indices go to color.

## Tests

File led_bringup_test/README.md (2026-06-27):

# Stack-board LED bring-up smoke test

Lights the **8 user LEDs on the Alchitry Au V2** from the 8 Bank-B signals coming
up through the **LauCameraTrigger_Alchitry_Stack** board (DF40 → Hd pass-through →
Au). Use it to verify a freshly fabbed batch: drive a line high, its LED turns on.

## LED map

| LED  | Signal | Au ball | DF40 pin | Source |
|---|---|---|---|---|
| led0 | `CAM_READY` | R11 | 27 | MASTER JST pin 5 (camera out)  |
| led1 | `CAM_TRIG` | R16 | 28 | MASTER JST pin 2 (camera **in**) |
| led2 | `CAM_PATTERN` | R10 | 29 | MASTER JST pin 4 (camera **in**) |
| led3 | `CAM_MODE` | R15 | 30 | MASTER JST pin 3 (camera out)  |
| led4 | `SW_HVSV` | K5 | 33 | SW1-1 (DIP) |
| led5 | `SW_BLUE` | N16 | 34 | SW1-2 (DIP) |
| led6 | `SW_GREEN` | E6 | 35 | SW1-3 (DIP) |
| led7 | `SW_RED` | M16 | 36 | SW1-4 (DIP) |

All inputs have an internal **pull-down**, so every LED is **off at rest** and
lights only when its line is driven high. (This is bring-up-friendly and is *not*
the functional pull scheme — the real `Au2.xdc` remap should use the mixed
pull-up/down from `ROADMAP.md §5.2`.)

## How to test

- **DIP switches (led4–led7):** SW1 is SPDT — one orientation ties the net to
  +3V3 (LED on), the other to GND (LED off). Flip each of the 4 positions and
  watch led4–led7 toggle.
- **Camera lines (led0–led3):** plug the GPIO cable into the **MASTER JST**.
  - `CAM_MODE` (led3) and `CAM_READY` (led0) are **camera outputs** — set those
    Alvium GPIO lines high and the LEDs follow.
  - `CAM_TRIG` (led1) and `CAM_PATTERN` (led2) are **camera inputs** (the camera
    won't drive them). To exercise their LEDs, either jumper the JST pin to +3V3,
    or set the camera's GPIO line direction to output and drive it.
  - If a camera-output line stays dark, check the Alvium line is configured
    **push-pull / active-driving** (a weak internal pull-down can't see an
    open-drain high).

## Build

From this folder, with the project's Vivado on PATH:

```
vivado -mode batch -source build.tcl
```

Produces `led_test.bit` (JTAG/RAM load) and `led_test.bin` (for the
`AlchitryFlasher` GUI). The design is pure routing — build is well under a minute.

GUI alternative: create a new RTL project for part `xc7a35tftg256-2`, add
`led_test_top.v` + `led_test.xdc`, set `led_test_top` as top, Generate Bitstream.

## Flash

Use `../AlchitryFlasher/AlchitryFlasher.cmd` (Step 3 → pick `led_test.bin`,
choose **RAM / temporary** for a smoke test), or the Alchitry loader directly.
RAM-loading means a power-cycle returns the board to its previous flash image.

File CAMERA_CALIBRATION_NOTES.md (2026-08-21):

# Two-point calibration — where it could live, and what it would cost

_Discussion note, 2026-08-21. Nothing here is built._ Captured so the reasoning
survives to whenever this gets picked up.

The question: apply a two-point (offset + gain) correction to the camera, and can
the correction be embedded in the bitstream?

    corrected = (raw - dark[x,y]) * gain[x,y]

---

## 1. The memory arithmetic decides the shape of the answer

| | |
|---|---|
| Pixels | 1280 × 1024 = **1,310,720** |
| Per-pixel offset + gain, 8 bits each | **2.62 MB** of coefficients |
| Offset only, 8 bits | 1.31 MB |
| Artix-7 100T block RAM | 135 × RAMB36 = 4,860 Kbit = **607 KB** |

**Full per-pixel maps are about 4× too large for on-chip memory**, and that is
before anything else claims a BRAM. Offset-only is still double. So per-pixel
correction cannot be a BRAM lookup on this part, at this resolution, in any
arrangement.

> Note the merged design currently uses **3.5 of 135 BRAMs**. The constraint is
> not that BRAM is busy — it is that there is nowhere near enough of it.

That leaves three real options.

---

## 2. Option A — per-pixel, coefficients in DDR3

Possible: there is 256 MB and a working MIG. The cost is bandwidth, and the
budget is already interesting.

| Traffic | MB/s |
|---|---|
| Capture writer (during the 4.55 ms burst) | 360 |
| Reader feeding USB at 120 Hz | 197 |
| **Coefficient read, per-pixel, during the burst** | **~360** |
| Total against a 1600 MB/s theoretical bus | **~900** |

Feasible on paper at ~56% utilisation, but DDR3 does not deliver its theoretical
peak once reads and writes interleave — turnaround penalties are real, and this
design has already been bitten by a sustained-rate shortfall that looked like a
transient (the cfifo overflow behind the rolling-frame bug).

It also puts a third master on the MIG, and **M3 exists precisely because
subsystems that share the memory controller can stop being independent.** Test
3d (`ldrop` must not move during an HDMI mode change) would need re-running with
real weight behind it.

Verdict: possible, but it is a substantial project and it spends the margin in
the place where this design's failures have historically lived.

---

## 3. Option B — column-wise (or row+column), coefficients in BRAM

If the dominant artifact is **column fixed-pattern noise** — usually the case on
CMOS, from per-column amplifier offsets — the table collapses:

| | Entries | Size |
|---|---|---|
| Column offset + gain | 1280 × 2 | **~2.5 KB** = 0.4% of BRAM |
| Row + column, separable | (1280 + 1024) × 2 | ~4.6 KB |

**This is essentially free**, and the project already has the mechanism: the SLI
control plane uploads a 720-byte row LUT (`0x00`), a 1280-byte column LUT
(`0x01`) and a 256-byte intensity correction (`0x02`) over the `0xA5` protocol,
with `host/upload_corr.py` driving it. Same transport, same framing, already
verified byte-exact by `test_silicon.py`.

Verdict: the natural fit, IF the FPN is columnar. That is a measurement, not an
assumption — see §6.

---

## 4. Option C — do it on the host

On the host it is a numpy expression over 1.31 Mpix: a couple of milliseconds
per frame, full per-pixel maps, no FPGA resources, and trivially changeable when
calibration drifts with temperature, exposure or gain.

**It costs no bandwidth to skip.** Corrected 10-bit is the same number of bits as
raw 10-bit, so doing the correction in the FPGA saves nothing on the link. The
FPGA version only wins if you correct *and then* reduce bit depth, or if
something on-chip needs corrected pixels.

Worth weighing against the viewer's measured budget: the render path is ~9.7 ms
per frame today, so a 2–3 ms correction is not free at 120 fps, but it is also
not where the time goes.

---

## 5. "Embedded in the bin" — two separate things

| | Feasible? | Consequence |
|---|---|---|
| Correction **logic** in the bitstream | Yes, easily | 8 parallel multiply-adds at the kernel stage, 36 M kernels/s. 8 of 240 DSPs. Must sit BEFORE the 10-bit packing. |
| Correction **data** baked in as ROM init | Yes for small tables | **Recalibration becomes a Vivado rebuild** rather than a host command |

Since calibration drifts with temperature, exposure and gain, baking the
coefficients in is the wrong trade. Upload them over the existing control link
and keep the bitstream fixed.

One datapath detail: `(raw − dark) × gain` wants headroom. Correcting in 10 bits
and rounding back to 10 loses precision at the ends; a 12-bit intermediate then
rounding is the usual answer. That interacts with the packed-10 format, which
assumes exactly 10 bits per pixel.

---

## 6. Two things to settle BEFORE choosing

**Characterise the FPN first.** Per-pixel and per-column need completely
different solutions — DDR3 and a serious project versus 2.5 KB of BRAM. A dark
frame and a flat field, differenced and examined column-wise versus pixel-wise,
answers it in an afternoon and decides everything above.

**Apply the CDS/sequencer program first.** `sources_1/imports/RTL/cam_cds_rom.v`
holds Avnet's `vita_cds_seq` table, committed but **not yet wired in**. 91 of its
104 entries are registers 384–474 — the sensor's CDS / sequencer TIMING PROGRAM —
and it has never been uploaded, so the pixel array has been running on power-on
defaults throughout all of this work, including the 120 Hz bring-up.

That block materially affects fixed-pattern noise. **Calibrating around a
misconfigured sensor means the coefficients encode a problem that could have been
removed instead.** Fix the configuration, re-measure the FPN, and the calibration
question may look different — or partly answer itself.

---

## 7. Suggested order

1. Wire in `cam_cds_rom.v` and compare FPN before/after. It is a wholesale rewrite
   of sensor timing registers, so it wants its own bring-up rather than being
   folded into other work.
2. Capture a dark frame and a flat field; decide whether the residual FPN is
   per-pixel or columnar.
3. If columnar → Option B, following the existing uploadable-LUT pattern.
   If per-pixel → start on the host (Option C) and only move it into DDR3 if
   there is a concrete reason the host cannot own it.

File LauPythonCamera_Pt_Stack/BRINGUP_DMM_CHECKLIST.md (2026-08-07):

# Bring-up — pin-by-pin DMM checklist

**Conditions this checklist assumes.** Socket **empty** (no PYTHON 1300 inserted), board mated to
the Pt V2 via J1/J2/J3, Pt powered, **FPGA unconfigured** (no bitstream). Every expected value
below was derived from `LauPythonCamera_Pt_Stack.kicad_pcb` — the pad-to-net map, not the docs.

> **Do not insert the sensor until §1, §2 and §4 all pass.** The socket exists precisely so a
> wiring fault costs a board and not a 27-week-lead sensor.

---

## Bench results — 2026-08-07

**§1–§3 PASS. §4 answered. The power tree is fully confirmed, including both hand-soldered supervisors.**

> ### ⚠️ The meter used for these readings has a +3.3 % gain error
>
> Established against three independent regulators: TP1 (the Pt's ADP5052) read +3.42 %, TP3 (U2)
> +3.50 %, TP5 (U5) +3.33 %. TP3 at 1.863 V settled it — a pure offset error would have put it at
> 1.911 V. **Divide readings by 1.033.** Zero is unaffected. Swap the meter battery before any
> absolute measurement matters.

| Probe | Read | ÷1.033 | Window | |
|---|---|---|---|---|
| TP1 `+3V3_SYS` | 3.390 | **3.282 V** | 3.229 – 3.327 | ✓ |
| TP2 `+4V5` | 4.690 | **4.540 V** | 4.33 – 4.56 | ✓ |
| TP3 `+1V8_CAM` | 1.863 | **1.804 V** | 1.760 – 1.840 | ✓ |
| TP4 `+3V3_CAM` | 3.401 | **3.293 V** | 3.250 – 3.350 | ✓ |
| TP5 `+3V3_PIX` | 3.410 | **3.301 V** | 3.250 – 3.350 | ✓ |

`vdd_pix` landed at 3.301 V — essentially dead centre of a window the design had **0.5 mV** of
margin in. TP4 and TP5 are the same MPN off the same reel and read 9 mV apart, which also rules out
a bad U5 independently.

**§3 needed no measurements.** `+3V3_PIX` existing at all requires `EN_PIX` high → U6 released →
`+3V3_CAM` present → U2's 1.8 V → `+4V5` → boost running → `EN_BOOST` high → U7 released. Both
supervisors are alive and correctly oriented.

**§4: configuration pull-ups are OFF.** R5 pad 1 read 0.001 V against a hard 0.000 V on its ground
pad. The Pt leaves its I/Os in high-Z, so **17 pins cannot be resolved by voltage at all** — see the
revised split in §5. Most of the remaining proof now lives in §6.

---

> **Getting to "unconfigured".** Erase the Pt's flash first:
> `alchitry.exe load --erase --board PtV2` (2.0.52 loader), **then power-cycle the board** — the
> FPGA's SRAM configuration survives a flash erase and only clears on power-down or PROGRAM_B.
> Confirm the Pt's DONE LED stays off. A leftover bitstream does not have to *conflict* with the
> camera pins to ruin these readings: Vivado's default `UNUSEDPIN` policy is `PULLDOWN`, so any
> unrelated design still actively pulls all 25 camera pins down and hides exactly the opens §5
> is looking for.

**Probing the socket.** The Andon 680-48-SM is an **open-frame** socket — no lid, no clamshell, no
clip. All 48 gold castellation contacts are exposed from above at all times, and the sensor is
retained by contact friction alone. Use a fine/needle probe and no force: a bent contact scraps the
socket, it is hand-solder DNP, and no distributor stocks a replacement (§ ordering).

**Physical orientation of U1** (board as drawn, top side up, J3 control header at the bottom edge):

```
                    N (top edge)  — pins 31…42, left→right
        +-------------------------------------------+
        |  48                                   43  |
   W    |   1  ←pin 1, just BELOW centre of the     |    E
 (left) |      left edge                            |  (right)
  pins  |                                           |   pins
 1…6,   |                  U1                       |  19…30,
 43…48  |                                           |  top→bottom
        |   6                                   19  |
        +-------------------------------------------+
                    S (bottom edge) — pins 7…18, left→right
```

Pin 1 sits one position **below** the left-edge centreline; pin 48 one position above it. The two
unnumbered mechanical pads are on the SW and NE diagonals — use them to confirm rotation.

---

## 1. FIRST, BEFORE ANYTHING ELSE — the VBSEL straps

Bank 13's VCCO is set by **hardware**, by this board strapping the Pt's tri-voltage select pins.
Alchitry: *"failing to set the tri-voltage pins correctly could damage the FPGA."* The board is
already powered, so verify this before spending time anywhere else.

| Probe point | Location (KiCad page coords, top side) | Net | Expected |
|---|---|---|---|
| **R10 pad 2** | 119.51, 101.0 | `VBSEL_A` | **3.23 – 3.33 V** |
| **R11 pad 2** | 122.51, 101.0 | `VBSEL_B` | **3.23 – 3.33 V** |

Both R10 and R11 are 1 kΩ 0402 at the bottom edge of the board, next to TP1. Both HIGH → bank 13
VCCO = 2.5 V, which is what `LVDS_25` and `DIFF_TERM` require.

❌ **Either one at 0 V or floating → power the stack down now.** Bank 13 is at the wrong VCCO.

---

## 2. Rails — the six test points (powered)

All six test points are on the **top** layer. Black lead on TP6 for every reading.

| TP | Location | Net | Expected | Notes |
|---|---|---|---|---|
| **TP6** | 119.64, 82.79 | `GND` | — | reference for everything |
| **TP1** | 111.6, 101.0 | `+3V3_SYS` | **3.23 – 3.33 V** (typ 3.278) | the Pt's rail. *Not* 3.300 — its divider makes 3.278 |
| **TP2** | 121.4, 67.5 | `+4V5` | **4.33 – 4.56 V** (typ 4.445) | TPS61023 boost, set by R8 330 k / R9 51 k |
| **TP3** | 117.3, 86.48 | `+1V8_CAM` | **1.76 – 1.84 V** | TPS7A2018, enabled straight off +3V3_SYS |
| **TP4** | 115.36, 88.81 | `+3V3_CAM` | **3.23 – 3.37 V** | TPS7A2033 (U4), EN tied to `+1V8_CAM` |
| **TP5** | 128.14, 65.71 | `+3V3_PIX` | **3.25 – 3.35 V** | TPS7A2033 (U5), EN from supervisor U6 |

### Reading the failures

| Symptom | Meaning |
|---|---|
| TP2 ≈ TP1 (~3.3 V, not 4.4 V) | Boost not switching — `EN_BOOST` low, or L1/U3 fault. Go to §3 |
| TP2 = 0 V | Boost dead or `+4V5` shorted |
| TP3 = 0 V | U2 (TPS7A2018) dead — everything downstream stays dark, because U4's EN comes from this rail |
| TP4 = 0 V but TP3 = 1.8 V | U4 fault |
| **TP5 = 0 V, everything else good** | `EN_PIX` low → **U6**. This is your hand-soldered part. Go to §3 |

---

## 3. The two supervisors you soldered — U6 and U7 (powered)

TLV803S, SOT-23-3. Pinout: **pin 1 = GND, pin 2 = RESET (open-drain, active low), pin 3 = VDD.**
A 180°-rotated part puts VDD on GND — if either package is warm to the touch, kill power now.

> **Ordering, if you need more:** `TLV803SDBZR` = **`C132016`**. Order the **`R`** (reel) code, not
> the `T` — same die, same SOT-23-3, same 2.93 V threshold, but only the `R` is actually stocked.
> The BOM originally named the `T` code and **the first order shipped without U6/U7 entirely**,
> which is why these two are hand-soldered. Only an order-time check catches it.

| Probe point | Location | Net | Expected |
|---|---|---|---|
| U7 pin 3 | 105.938, 96.5 | `+3V3_SYS` | 3.23 – 3.33 V |
| U7 pin 1 | 104.062, 95.55 | `GND` | 0.000 V |
| **U7 pin 2** (= R16 pad 2) | 104.062, 97.45 | `RST_BOOST` | **≈ 3.28 V** — reset *released* |
| **R17 pad 2** | 113.5, 97.01 | `EN_BOOST` | **≈ 3.28 V** — boost enabled |
| U6 pin 3 | 105.938, 92.0 | `+3V3_SYS` | 3.23 – 3.33 V |
| U6 pin 1 | 104.062, 91.05 | `GND` | 0.000 V |
| **U6 pin 2** (= R15 pad 2) | 104.062, 92.95 | `EN_PIX` | **≈ 3.3 V** (pulled to `+3V3_CAM`) — vdd_pix enabled |

Both supervisors trip at **V_IT = 2.93 V** with a **200 ms** power-up delay. With +3V3_SYS at
3.278 V both must be released. A RESET pin stuck LOW while its VDD pin reads 3.28 V is a dead or
mis-oriented supervisor, not a sequencing event.

Note `EN_PIX`'s 100 kΩ pull-up (R15) goes to **`+3V3_CAM`, not `+3V3_SYS`** — that is the deliberate
interlock. Before vdd_33 exists, EN_PIX physically cannot rise. If TP4 = 0 V then EN_PIX = 0 V is
*correct behaviour*, not a U6 fault. Fix TP4 first.

---

## 4. Establish what the FPGA is doing to its pins — ONE measurement

With no bitstream, the Artix-7's I/Os are either Hi-Z or holding weak configuration pull-ups,
depending on how the Pt straps PUDC_B. Which one it is decides how much of §5 is conclusive, so
measure it once, up front.

**Probe R5 pad 1** (130.89, 69.7) = `CAM_TRIG0`, which has a 10 kΩ pull-down to GND on this board.

| Reading | Conclusion | Consequence for §5 |
|---|---|---|
| **0.000 V** | Config pull-ups **OFF** (PUDC_B high) | The 15 pins with no on-board passive (3, 44, 45, and the 12 LVDS) **float** — §5 cannot resolve them. Use §6 |
| **≈ 1.0 – 2.0 V** | Config pull-ups **ON** | Every pin is measurable, and the LVDS pins double as a live readout of bank 13's VCCO |

> ### ✅ ANSWERED 2026-08-07 — **0.001 V. Pull-ups are OFF.**
>
> Ground pad read a hard 0.000 V; `CAM_TRIG0` read 0.001 V with a millivolt of last-digit jitter.
> The 48 pins now split **four** ways, not two:
>
> | | Count | Verdict from the powered walk |
> |---|---|---|
> | Rails + pin 47 | **12** | fully verified — real voltages |
> | Grounds + pin 28 | **12** | fully verified — hard 0.000 V |
> | Control pins 2, 4, 25, 41, 42, 43, 46 | **7** | read 0.000 V — **but proves little** |
> | LVDS 7–18, 23, 24 + pins 3, 44, 45 | **17** | float — **no verdict** |
>
> **Eight pins read correctly even when broken.** Those seven control pins and pin 47 sit on
> on-board pull resistors. Their reading proves the resistor and the copper to the socket, *not*
> the link onward through J1 to the FPGA. Only the walking-ones bitstream (§7) proves that, because
> only it catches pin **swaps**.

---

## 5. The 48-pin walk (powered, socket empty)

Black lead on TP6 throughout. **"pull-ups ON" / "OFF"** columns refer to the §4 result.

| Pin | Side | Net | Expected — pull-ups OFF | Expected — pull-ups ON |
|---|---|---|---|---|
| 1 | W | `+3V3_CAM` | = TP4, within a few mV | same |
| 2 | W | `CAM_MOSI` | 0.000 V (R12 10k↓) | 1.0–2.0 V, **same as pins 4, 25, 41, 42, 43, 46** |
| 3 | W | `CAM_MISO` | floats — inconclusive | ≈ 3.3 V |
| 4 | W | `CAM_SCK` | 0.000 V (R13 10k↓) | matches the group |
| 5 | W | `GND` | 0.000 V | 0.000 V |
| 6 | W | `+1V8_CAM` | = TP3 | same |
| 7 | S | `CAM_CLKOUT_N` | floats | **≈ 2.5 V** ← bank 13 VCCO |
| 8 | S | `CAM_CLKOUT_P` | floats | ≈ 2.5 V |
| 9 | S | `CAM_D0_N` | floats | ≈ 2.5 V |
| 10 | S | `CAM_D0_P` | floats | ≈ 2.5 V |
| 11 | S | `CAM_D1_N` | floats | ≈ 2.5 V |
| 12 | S | `CAM_D1_P` | floats | ≈ 2.5 V |
| 13 | S | `CAM_D2_N` | floats | ≈ 2.5 V |
| 14 | S | `CAM_D2_P` | floats | ≈ 2.5 V |
| 15 | S | `CAM_D3_N` | floats | ≈ 2.5 V |
| 16 | S | `CAM_D3_P` | floats | ≈ 2.5 V |
| 17 | S | `CAM_SYNC_N` | floats | ≈ 2.5 V |
| 18 | S | `CAM_SYNC_P` | floats | ≈ 2.5 V |
| 19 | E | `+3V3_CAM` | = TP4 | same |
| 20 | E | `GND` | 0.000 V | 0.000 V |
| 21 | E | `GND` | 0.000 V | 0.000 V |
| 22 | E | `+1V8_CAM` | = TP3 | same |
| 23 | E | `CAM_LVDSCLK_N` | floats — but see §6, R2 | ≈ 2.5 V |
| 24 | E | `CAM_LVDSCLK_P` | floats — but see §6, R2 | ≈ 2.5 V |
| 25 | E | `CAM_CLK_PLL` | 0.000 V (R14 10k↓) | matches the group |
| 26 | E | `+1V8_CAM` | = TP3 | same |
| 27 | E | `GND` | 0.000 V | 0.000 V |
| 28 | E | `IBIAS_MASTER` | **0.000 V** (R1 47 k to GND, no source with the socket empty) | 0.000 V |
| 29 | E | `+3V3_CAM` | = TP4 | same |
| 30 | E | `GND` | 0.000 V | 0.000 V |
| 31 | N | `+3V3_PIX` | = TP5 | same |
| 32 | N | `GND` | 0.000 V | 0.000 V |
| 33 | N | `+3V3_PIX` | = TP5 | same |
| 34 | N | `GND` | 0.000 V | 0.000 V |
| 35 | N | `GND` | 0.000 V | 0.000 V |
| 36 | N | `+3V3_CAM` | = TP4 | same |
| 37 | N | `GND` | 0.000 V | 0.000 V |
| 38 | N | `+3V3_PIX` | = TP5 | same |
| 39 | N | `GND` | 0.000 V | 0.000 V |
| 40 | N | `+3V3_PIX` | = TP5 | same |
| 41 | N | `CAM_TRIG0` | 0.000 V (R5 10k↓) | matches the group |
| 42 | N | `CAM_TRIG1` | 0.000 V (R6 10k↓) | matches the group |
| 43 | W | `CAM_TRIG2` | 0.000 V (R7 10k↓) | matches the group |
| 44 | W | `CAM_MON0` | floats — inconclusive | ≈ 3.3 V |
| 45 | W | `CAM_MON1` | floats — inconclusive | ≈ 3.3 V |
| 46 | W | `CAM_RESET_N` | 0.000 V (R4 10k↓) | matches the group |
| 47 | W | **`CAM_SS_N`** | **≈ 3.3 V** — R3 is a 10 kΩ **pull-UP** to `+3V3_CAM` | ≈ 3.3 V |
| 48 | W | `GND` | 0.000 V | 0.000 V |

### What to actually look for

- **Pin 47 is the odd one out by design.** It is the only control pin pulled *up*. If it reads
  0 V, R3 is open/missing or `CAM_SS_N` is shorted to GND. If any *other* control pin reads 3.3 V,
  you have a short to a 3.3 V rail.
- **Uniformity is the test, not the absolute number.** With pull-ups ON, pins 2, 4, 25, 41, 42, 43
  and 46 all sit on identical 10 kΩ↓ + weak↑ dividers and must read within ~50 mV of each other.
  One pin low → open on the FPGA side. One pin high → open pull-down, or short to a rail.
- **11 GND pins:** 5, 20, 21, 27, 30, 32, 34, 35, 37, 39, 48. Any one not at 0.000 V is an
  unsoldered socket contact.
- **Rail groups must match their TP exactly**, not approximately. A pin reading 3.2 V where TP4
  reads 3.30 V means current is flowing through a bad joint.

---

## 6. Resistance walk — power OFF, board unplugged from the Pt

This is what proves the *socket solder joints*, which voltage alone cannot: a socket contact that
is merely near its pad will still show the right voltage through the meter's 10 MΩ input.

Unplug the stack. Wait for the rails to bleed (the TPS7A20's auto-discharge makes this quick).

**6.1 Ground integrity** — TP6 to each of pins **5, 20, 21, 27, 30, 32, 34, 35, 37, 39, 48**:
**< 1 Ω** each. This is the check that would have caught the LauCameraTrigger rev-1 floating-GND
island, so do not skip it.

**6.2 Rail pins to their test point** — **< 1 Ω** each:

| Pins | → TP |
|---|---|
| 1, 19, 29, 36 | TP4 (`+3V3_CAM`) |
| 6, 22, 26 | TP3 (`+1V8_CAM`) |
| 31, 33, 38, 40 | TP5 (`+3V3_PIX`) |

**6.3 Signal pins to their pull resistor** — **< 1 Ω** each. All on the top layer:

| Socket pin | Net | Probe partner | Location |
|---|---|---|---|
| 2 | `CAM_MOSI` | R12 pad 1 | 123.75, 82.79 |
| 4 | `CAM_SCK` | R13 pad 1 | 123.75, 85.09 |
| 25 | `CAM_CLK_PLL` | R14 pad 1 | 148.10, 80.19 |
| 28 | `IBIAS_MASTER` | R1 pad 1 | 148.075, 76.99 |
| 41 | `CAM_TRIG0` | R5 pad 1 | 130.89, 69.70 |
| 42 | `CAM_TRIG1` | R6 pad 1 | 128.39, 69.70 |
| 43 | `CAM_TRIG2` | R7 pad 1 | 123.75, 75.89 |
| 46 | `CAM_RESET_N` | R4 pad 1 | 123.75, 78.19 |
| 47 | `CAM_SS_N` | R3 pad 2 | 123.75, 81.51 |

Also: **pin 28 → TP6 should read 47 kΩ** (R1). That single reading proves the mandatory
`ibias_master` bias resistor is present, correctly valued, and bonded to ground.

**6.4 The LVDS clock pair — the one differential check you can do with a meter:**

> **Pin 23 ↔ pin 24 = 100 Ω.** That is R2, the far-end termination for the FPGA→sensor LVDS clock.

R2 is on the **bottom** layer (147.59–148.61, 83.0), so it is inaccessible while the board is mated
to the Pt — but you do not need to reach it. Measuring 100 Ω between the two socket pins proves
R2's value, both of its joints, and both socket contacts in one reading.

**6.5 Short hunt on the 15 pins with no passive** (3, 44, 45 and 7–18). Resistance can only prove
the *absence* of shorts here, not the presence of connections:

- Each → TP6: **open** (> 1 MΩ)
- Each → its physical neighbour: **open**
- Each LVDS P/N pair (7↔8, 9↔10, 11↔12, 13↔14, 15↔16, 17↔18): **open** with the FPGA
  unconfigured. `DIFF_TERM` is internal to the FPGA and inactive until a bitstream is loaded —
  once one is, these same pairs should read ≈ 100 Ω, which is a useful later confirmation that
  bank 13 really came up at 2.5 V.

---

## 7. What this checklist cannot prove

**Continuity to the FPGA for 15 pins.** `CAM_MISO` (3), `CAM_MON0` (44), `CAM_MON1` (45) and the
12 LVDS pins (7–18) connect only to the socket, the DF40 (J1/J2) and the FPGA ball. With the board
mated there is no third probe point, so a meter can rule out shorts but cannot confirm the FPGA is
actually reachable — unless §4 found config pull-ups ON, in which case the ≈2.5 V / ≈3.3 V readings
*do* confirm it end to end.

**If §4 came back 0.000 V, these 15 pins need a bring-up bitstream** — a walking-ones design that
drives one pin at a time so the meter sees 3.3 V (or 2.5 V) on exactly one socket contact and 0 V
on the other 47. That catches pin **swaps**, which no static reading can. Notes toward building it:

- The 12 LVDS pins are inputs in `pt_camera.xdc`. For bring-up only, re-constrain them as
  `LVCMOS25` **outputs** — legal and safe with the socket empty, since nothing else drives them.
- **Do not drive pins 23 and 24 to opposite levels**: R2's 100 Ω across them would draw 25 mA.
  Drive one at a time with the other at Hi-Z, or drive both to the same level.
- `iocheck/pt_stack_iocheck.v` is a *placement* check only — it proves the pin plan fits, it does
  not toggle anything. The walking-ones design is new work.

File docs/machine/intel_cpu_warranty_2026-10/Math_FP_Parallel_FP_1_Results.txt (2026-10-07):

Floating Point Test
Module Version: 1.1.0.64b.W
Start Time: Wed Oct  7 16:52:13 2026
DetectUtils64 DLL Version - 1.1.10
AVX is supported in your OS
Max AVX supported = AVX2
FMA3 supported
Test Result - PASS
Million Floating Points per Second, MFLOPS: 4768.855
Error: 0
--- Floating Point Test Passed!!!---
End Time: Wed Oct  7 16:52:58 2026
Total Time: in seconds: 45

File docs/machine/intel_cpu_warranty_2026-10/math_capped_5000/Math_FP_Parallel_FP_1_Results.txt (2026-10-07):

Floating Point Test
Module Version: 1.1.0.64b.W
Start Time: Wed Oct  7 17:22:43 2026
DetectUtils64 DLL Version - 1.1.10
AVX is supported in your OS
Max AVX supported = AVX2
FMA3 supported
Test Result - PASS
Million Floating Points per Second, MFLOPS: 3908.125
Error: 0
--- Floating Point Test Passed!!!---
End Time: Wed Oct  7 17:23:28 2026
Total Time: in seconds: 45

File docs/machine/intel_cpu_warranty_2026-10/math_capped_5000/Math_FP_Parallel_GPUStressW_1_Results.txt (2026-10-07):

Floating Point Test
Module Version: 1.1.0.64b.W
Start Time: Wed Oct  7 17:24:13 2026
DetectUtils64 DLL Version - 1.1.10
AVX is supported in your OS
Max AVX supported = AVX2
FMA3 supported
Test Result - PASS
Million Floating Points per Second, MFLOPS: 3990.87
Error: 0
--- Floating Point Test Passed!!!---
End Time: Wed Oct  7 17:24:43 2026
Total Time: in seconds: 30

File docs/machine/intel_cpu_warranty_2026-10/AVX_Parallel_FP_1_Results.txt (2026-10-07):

AVX Test
Module Version: 2.1.0.64b.W
Start Time: Wed Oct  7 16:52:13 2026
Test Result - PASS

DetectUtils64 DLL Version - 1.1.10

  --- CPU Features Detection --- 
..AVX is supported by this CPU..
..AVX2 is supported by this CPU..
..AVX512BW is NOT supported by this CPU..
..AVX512CD is NOT supported by this CPU..
..AVX512DQ is NOT supported by this CPU..
..AVX512ER is NOT supported by this CPU..
..AVX512F is NOT supported by this CPU..
..AVX512IFMA52 is NOT supported by this CPU..
..AVX512PF is NOT supported by this CPU..
..AVX512VBMI is NOT supported by this CPU..
..AVX512VL is NOT supported by this CPU..
..AES is supported by this CPU..
..PCLMULQDQ is supported by this CPU..

..AVX is supported by this Operating System..

Most Advanced AVX Feature Detected.. AVX2
AVX2 Test Result --- PASS
AES Test Result --- PASS
PCLMULQDQ Test Result --- PASS

End Time: Wed Oct  7 16:52:58 2026
Total Time: in seconds: 45

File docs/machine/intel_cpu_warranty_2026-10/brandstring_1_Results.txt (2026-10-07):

CPU Brand String Test
Module Version: 1.1.0.64b.W
Start Time: Wed Oct  7 16:51:27 2026
Test Result - PASS 
Expected: Intel(R) Core(TM) 
Detected: Intel(R) Core(TM) i9-14900KF
Intel(R) Core(TM) processor detected..!!..
End Time: Wed Oct  7 16:51:27 2026
Total Time: in seconds: 0

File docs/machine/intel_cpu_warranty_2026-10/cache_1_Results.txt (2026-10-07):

Cache Test
Module Version: 1.1.0.64b.W
Start Time: Wed Oct  7 16:51:27 2026
Test Result - PASS

 --- Reading Cache Size ---  

- Detected L1 Data Cache Size --> 48
- Detected L1 Inst Cache Size --> 32

- Detected L2 Cache Size --> 2048
- Detected L3 Cache Size --> 36864

Cache Size Test Passed!!!

End Time: Wed Oct  7 16:51:27 2026
Total Time: in seconds: 0

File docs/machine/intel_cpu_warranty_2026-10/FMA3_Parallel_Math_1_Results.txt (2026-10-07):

FMA3 Test
Module Version: 1.1.0.64b.W
Start Time: Wed Oct  7 16:52:58 2026
Test Result - FAIL

DetectUtils64 DLL Version - 1.1.10

  --- CPU Features Detection --- 
..FMA3 is supported by this CPU..
..FMA3 is supported by this Operating System..

FMA3 Test Result --- FAIL

End Time: Wed Oct  7 16:53:43 2026
Total Time: in seconds: 45

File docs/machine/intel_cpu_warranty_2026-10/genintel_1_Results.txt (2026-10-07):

Genuine Intel CPU Test
Module Version: 1.1.0.64b.W
Start Time: Wed Oct  7 16:51:27 2026
Test Result - PASS 
Expected: GenuineIntel
Detected: GenuineIntel
End Time: Wed Oct  7 16:51:27 2026
Total Time: in seconds: 0

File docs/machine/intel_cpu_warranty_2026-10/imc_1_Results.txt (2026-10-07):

IMC Test
Module Version: 1.1.0.64b.W
Start Time: Wed Oct  7 16:51:27 2026
Test Result - PASS
--- Reading Memory Size --- 
Detected Memory Size is --> 96.00GB
--- Subtest - Memory Size Test Passed!!!  ---
--- Integrated Memory Controller Stress Test --- 
Memory to be allocated = 1048576 bytes
Memory Allocated.
Test 1 Ones and Zeros Moving Inversions write operations - Passed
Test 1 Ones and Zeros Moving Inversions verification operations - Passed
Test 2 32Bits Sliding Ones write operations - Passed
Test 2 32Bits Sliding Ones verification operations - Passed
Test 3 32Bits Sliding Zero write operations - Passed
Test 3 32Bits Sliding Zero verification operations - Passed
Memory Deallocated.
--- Subtest - Memory Stress Test Passed!!!  ---
Integrated Memory Controller Test Passed!!!
End Time: Wed Oct  7 16:51:27 2026
Total Time: in seconds: 0

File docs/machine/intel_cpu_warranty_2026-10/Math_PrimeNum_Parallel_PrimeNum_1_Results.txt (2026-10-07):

Prime Number Generation Test
Module Version: 1.1.0.64b.W
Start Time: Wed Oct  7 16:51:28 2026
DetectUtils64 DLL Version - 1.1.10
AVX is supported in your OS
Max AVX supported = AVX2
Test Result - PASS
Operation Per Second: 235500
Error: 0
--- Prime Number Generation Test Passed!!!---
End Time: Wed Oct  7 16:52:13 2026
Total Time: in seconds: 45

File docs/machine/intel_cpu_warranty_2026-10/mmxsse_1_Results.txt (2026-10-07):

MMXSSE Test
Module Version: 1.1.0.64b.W
Start Time: Wed Oct  7 16:51:27 2026
Test Result - PASS

DetectUtils64 DLL Version - 1.1.10

 --- Determining MMX - SSE capabilities --- 
..MMX is supported on this CPU..
..SSE is supported on this CPU..
..SSE2 is supported on this CPU..
..SSE3 is supported on this CPU..
..SSSE3 is supported on this CPU..
..SSE4.1 is supported on this CPU..
..SSE4.2 is supported on this CPU..

SSE Test Result --- PASS
SSE2 Test Result --- PASS
SSE3 Test Result --- PASS
SSSE3 Test Result --- PASS
SSE4.1 Test Result --- PASS
SSE4.2 Test Result --- PASS

End Time: Wed Oct  7 16:51:27 2026
Total Time: in seconds: 0

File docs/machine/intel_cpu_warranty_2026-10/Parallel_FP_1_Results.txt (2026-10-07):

Parallel_FP Test
Module Version: 1.0.0.13
Start Time: 10/7/2026 4:52:13 PM
Test Result - PASS
 
Module AVX.exe Completed - Pass
Module Math_FP.exe Completed - Pass

AVX Test
Module Version: 2.1.0.64b.W
Start Time: Wed Oct  7 16:52:13 2026
Test Result - PASS

DetectUtils64 DLL Version - 1.1.10

  --- CPU Features Detection --- 
..AVX is supported by this CPU..
..AVX2 is supported by this CPU..
..AVX512BW is NOT supported by this CPU..
..AVX512CD is NOT supported by this CPU..
..AVX512DQ is NOT supported by this CPU..
..AVX512ER is NOT supported by this CPU..
..AVX512F is NOT supported by this CPU..
..AVX512IFMA52 is NOT supported by this CPU..
..AVX512PF is NOT supported by this CPU..
..AVX512VBMI is NOT supported by this CPU..
..AVX512VL is NOT supported by this CPU..
..AES is supported by this CPU..
..PCLMULQDQ is supported by this CPU..

..AVX is supported by this Operating System..

Most Advanced AVX Feature Detected.. AVX2
AVX2 Test Result --- PASS
AES Test Result --- PASS
PCLMULQDQ Test Result --- PASS

End Time: Wed Oct  7 16:52:58 2026
Total Time: in seconds: 45

Floating Point Test
Module Version: 1.1.0.64b.W
Start Time: Wed Oct  7 16:52:13 2026
DetectUtils64 DLL Version - 1.1.10
AVX is supported in your OS
Max AVX supported = AVX2
FMA3 supported
Test Result - PASS
Million Floating Points per Second, MFLOPS: 4768.855
Error: 0
--- Floating Point Test Passed!!!---
End Time: Wed Oct  7 16:52:58 2026
Total Time: in seconds: 45
 
Parallel_FP
End Time: 10/7/2026 4:52:58 PM

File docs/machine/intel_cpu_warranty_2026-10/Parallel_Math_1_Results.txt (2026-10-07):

Parallel_Math Test
Module Version: 1.0.0.13
Start Time: 10/7/2026 4:52:58 PM
Test Result - FAIL
 
Module FMA3.exe Completed - Fail

FMA3 Test
Module Version: 1.1.0.64b.W
Start Time: Wed Oct  7 16:52:58 2026
Test Result - FAIL

DetectUtils64 DLL Version - 1.1.10

  --- CPU Features Detection --- 
..FMA3 is supported by this CPU..
..FMA3 is supported by this Operating System..

FMA3 Test Result --- FAIL

End Time: Wed Oct  7 16:53:43 2026
Total Time: in seconds: 45
 
Parallel_Math
End Time: 10/7/2026 4:53:43 PM

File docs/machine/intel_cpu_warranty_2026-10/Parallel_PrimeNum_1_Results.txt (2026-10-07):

Parallel_PrimeNum Test
Module Version: 1.0.0.13
Start Time: 10/7/2026 4:51:28 PM
Test Result - PASS
 
Module Math_PrimeNum.exe Completed - Pass

Prime Number Generation Test
Module Version: 1.1.0.64b.W
Start Time: Wed Oct  7 16:51:28 2026
DetectUtils64 DLL Version - 1.1.10
AVX is supported in your OS
Max AVX supported = AVX2
Test Result - PASS
Operation Per Second: 235500
Error: 0
--- Prime Number Generation Test Passed!!!---
End Time: Wed Oct  7 16:52:13 2026
Total Time: in seconds: 45
 
Parallel_PrimeNum
End Time: 10/7/2026 4:52:13 PM

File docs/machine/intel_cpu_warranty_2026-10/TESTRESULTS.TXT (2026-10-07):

--- IPDT64 - Revision: 4.5.0.0
--- IPDT64 - Start Time: 10/7/2026 4:51:26 PM

CPU1
Genuine Intel CPU Test
Module Version: 1.1.0.64b.W
Start Time: Wed Oct  7 16:51:27 2026
Test Result - PASS 
Expected: GenuineIntel
Detected: GenuineIntel
End Time: Wed Oct  7 16:51:27 2026
Total Time: in seconds: 0
--------------------------------------------------------------------
CPU1
CPU Brand String Test
Module Version: 1.1.0.64b.W
Start Time: Wed Oct  7 16:51:27 2026
Test Result - PASS 
Expected: Intel(R) Core(TM) 
Detected: Intel(R) Core(TM) i9-14900KF
Intel(R) Core(TM) processor detected..!!..
End Time: Wed Oct  7 16:51:27 2026
Total Time: in seconds: 0
--------------------------------------------------------------------
CPU1
Cache Test
Module Version: 1.1.0.64b.W
Start Time: Wed Oct  7 16:51:27 2026
Test Result - PASS

 --- Reading Cache Size ---  

- Detected L1 Data Cache Size --> 48
- Detected L1 Inst Cache Size --> 32

- Detected L2 Cache Size --> 2048
- Detected L3 Cache Size --> 36864

Cache Size Test Passed!!!

End Time: Wed Oct  7 16:51:27 2026
Total Time: in seconds: 0
--------------------------------------------------------------------
CPU1
MMXSSE Test
Module Version: 1.1.0.64b.W
Start Time: Wed Oct  7 16:51:27 2026
Test Result - PASS

DetectUtils64 DLL Version - 1.1.10

 --- Determining MMX - SSE capabilities --- 
..MMX is supported on this CPU..
..SSE is supported on this CPU..
..SSE2 is supported on this CPU..
..SSE3 is supported on this CPU..
..SSSE3 is supported on this CPU..
..SSE4.1 is supported on this CPU..
..SSE4.2 is supported on this CPU..

SSE Test Result --- PASS
SSE2 Test Result --- PASS
SSE3 Test Result --- PASS
SSSE3 Test Result --- PASS
SSE4.1 Test Result --- PASS
SSE4.2 Test Result --- PASS

End Time: Wed Oct  7 16:51:27 2026
Total Time: in seconds: 0
--------------------------------------------------------------------
CPU1
IMC Test
Module Version: 1.1.0.64b.W
Start Time: Wed Oct  7 16:51:27 2026
Test Result - PASS
--- Reading Memory Size --- 
Detected Memory Size is --> 96.00GB
--- Subtest - Memory Size Test Passed!!!  ---
--- Integrated Memory Controller Stress Test --- 
Memory to be allocated = 1048576 bytes
Memory Allocated.
Test 1 Ones and Zeros Moving Inversions write operations - Passed
Test 1 Ones and Zeros Moving Inversions verification operations - Passed
Test 2 32Bits Sliding Ones write operations - Passed
Test 2 32Bits Sliding Ones verification operations - Passed
Test 3 32Bits Sliding Zero write operations - Passed
Test 3 32Bits Sliding Zero verification operations - Passed
Memory Deallocated.
--- Subtest - Memory Stress Test Passed!!!  ---
Integrated Memory Controller Test Passed!!!
End Time: Wed Oct  7 16:51:27 2026
Total Time: in seconds: 0
--------------------------------------------------------------------
CPU1
Parallel_PrimeNum Test
Module Version: 1.0.0.13
Start Time: 10/7/2026 4:51:28 PM
Test Result - PASS
 
Module Math_PrimeNum.exe Completed - Pass

Prime Number Generation Test
Module Version: 1.1.0.64b.W
Start Time: Wed Oct  7 16:51:28 2026
DetectUtils64 DLL Version - 1.1.10
AVX is supported in your OS
Max AVX supported = AVX2
Test Result - PASS
Operation Per Second: 235500
Error: 0
--- Prime Number Generation Test Passed!!!---
End Time: Wed Oct  7 16:52:13 2026
Total Time: in seconds: 45
 
Parallel_PrimeNum
End Time: 10/7/2026 4:52:13 PM
--------------------------------------------------------------------
CPU1
Parallel_FP Test
Module Version: 1.0.0.13
Start Time: 10/7/2026 4:52:13 PM
Test Result - PASS
 
Module AVX.exe Completed - Pass
Module Math_FP.exe Completed - Pass

AVX Test
Module Version: 2.1.0.64b.W
Start Time: Wed Oct  7 16:52:13 2026
Test Result - PASS

DetectUtils64 DLL Version - 1.1.10

  --- CPU Features Detection --- 
..AVX is supported by this CPU..
..AVX2 is supported by this CPU..
..AVX512BW is NOT supported by this CPU..
..AVX512CD is NOT supported by this CPU..
..AVX512DQ is NOT supported by this CPU..
..AVX512ER is NOT supported by this CPU..
..AVX512F is NOT supported by this CPU..
..AVX512IFMA52 is NOT supported by this CPU..
..AVX512PF is NOT supported by this CPU..
..AVX512VBMI is NOT supported by this CPU..
..AVX512VL is NOT supported by this CPU..
..AES is supported by this CPU..
..PCLMULQDQ is supported by this CPU..

..AVX is supported by this Operating System..

Most Advanced AVX Feature Detected.. AVX2
AVX2 Test Result --- PASS
AES Test Result --- PASS
PCLMULQDQ Test Result --- PASS

End Time: Wed Oct  7 16:52:58 2026
Total Time: in seconds: 45

Floating Point Test
Module Version: 1.1.0.64b.W
Start Time: Wed Oct  7 16:52:13 2026
DetectUtils64 DLL Version - 1.1.10
AVX is supported in your OS
Max AVX supported = AVX2
FMA3 supported
Test Result - PASS
Million Floating Points per Second, MFLOPS: 4768.855
Error: 0
--- Floating Point Test Passed!!!---
End Time: Wed Oct  7 16:52:58 2026
Total Time: in seconds: 45
 
Parallel_FP
End Time: 10/7/2026 4:52:58 PM
--------------------------------------------------------------------
CPU1
Parallel_Math Test
Module Version: 1.0.0.13
Start Time: 10/7/2026 4:52:58 PM
Test Result - FAIL
 
Module FMA3.exe Completed - Fail

FMA3 Test
Module Version: 1.1.0.64b.W
Start Time: Wed Oct  7 16:52:58 2026
Test Result - FAIL

DetectUtils64 DLL Version - 1.1.10

  --- CPU Features Detection --- 
..FMA3 is supported by this CPU..
..FMA3 is supported by this Operating System..

FMA3 Test Result --- FAIL

End Time: Wed Oct  7 16:53:43 2026
Total Time: in seconds: 45
 
Parallel_Math
End Time: 10/7/2026 4:53:43 PM
--------------------------------------------------------------------

System Information
------------------
Processor Name: Intel(R) Core(TM) i9-14900KF
Processor Information: Family 6 Model B7 Stepping 1
Number of Physical Cores: 24
Number of Logical Cores: 32
Operating System: Microsoft Windows 11 Pro 64-bit
Graphics Information: AMD Radeon RX 7900 XTX
--------------------------------------------------------------------

--- IPDT64 - End Time: 10/7/2026 4:53:43 PM
--- IPDT64 - Result: Fail
--------------------------------------------------------------------

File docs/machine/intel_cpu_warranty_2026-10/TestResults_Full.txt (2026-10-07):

--- IPDT64 - Revision: 4.5.0.0
--- IPDT64 - Start Time: 10/7/2026 4:47:15 PM

CPU1
Genuine Intel CPU Test
Module Version: 1.1.0.64b.W
Start Time: Wed Oct  7 16:47:15 2026
Test Result - PASS 
Expected: GenuineIntel
Detected: GenuineIntel
End Time: Wed Oct  7 16:47:15 2026
Total Time: in seconds: 0
--------------------------------------------------------------------
CPU1
CPU Brand String Test
Module Version: 1.1.0.64b.W
Start Time: Wed Oct  7 16:47:15 2026
Test Result - PASS 
Expected: Intel(R) Core(TM) 
Detected: Intel(R) Core(TM) i9-14900KF
Intel(R) Core(TM) processor detected..!!..
End Time: Wed Oct  7 16:47:15 2026
Total Time: in seconds: 0
--------------------------------------------------------------------
CPU1
Cache Test
Module Version: 1.1.0.64b.W
Start Time: Wed Oct  7 16:47:15 2026
Test Result - PASS

 --- Reading Cache Size ---
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

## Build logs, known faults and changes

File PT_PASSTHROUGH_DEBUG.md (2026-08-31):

# HDMI pass-through on the Pt — SOLVED

_2026-08-27. Pass-through works: `1281x720 @ 60.00 Hz`, `meas_ok=1`, video confirmed
on the display. Commit `9e1bc80`._

## The fault, in one paragraph

The receiver decoded **sync perfectly and passed zero pixels**. `vdp_prefix_seen`
defaults to `'0'` every cycle and only sets while control symbols are valid, so it
fell at the **first** guard-band character. But only the **second** of the two guard
characters is ever detected on this hardware — 40 per 65536-pixel window, exactly one
per line at 720p. The flag and the detection could therefore never coincide, so
`vdp_guardband_detect` never latched and the video data period was never entered.
`pfx_hold` now keeps the flag alive across both guard characters.

| | before | after |
|---|---|---|
| guard band detected | 40 | 40 |
| `vdp_guardband_detect` | **0** | **40** |
| `in_vdp` duty | **0** | **50815** (77.5%; ~74.5% expected) |
| frame period | 263 / 428 / 1911 Hz (noise) | **60.00 Hz** |
| raster | `4095x0`, `meas_ok=0` | **`1281x720`, `meas_ok=1`** |

## It was two faults, not one

**Sync half** — three copy-paste guard bugs, each reading a third channel's *value*
while confirming only two channels' validity:

* VDP preamble (`:551`) tested `ch1_ctl_valid` twice, never `ch2_ctl_valid`
* ADP preamble (`:573`) same
* ADP guard band (`:588`) tested `ch1_guardband_valid` twice, never `ch2`

Fixing these took the frame period from noise to exactly 60.00 Hz. (`:512` also
tested `ch2_invalid_symbol` three times — fixed, but it only gates substitute pixel
values and was never the fault.)

**Pixel half** — the `vdp_prefix_seen` expiry above. Both halves had to be fixed
before a single pixel appeared, which is why partial fixes looked like no progress.

> A comment in this code records that this same class of bug was fixed once before by
> widening the preamble pulse. **That fix was not wide enough.** If pass-through ever
> breaks again, suspect this flag's lifetime before anything else.

## Eliminated by measurement — do not re-investigate

| stage | evidence |
|---|---|
| Recovered pixel clock | 74250 kHz, exact |
| TMDS decode, per lane | zero invalid symbols, all three channels |
| IDELAY calibration | `RDY = 1` |
| `video_phase_fifo` | primed; re-prime count static |
| Inter-channel alignment | 98% coincidence |
| **ch1/ch2 lane swap** | preamble counts **14680 as-coded vs 0 swapped** — lane order is correct |
| HDMI timing closure | `pixel_clk_raw_i` WNS +6.198 ns (the +0.082 ns figure is `ft_clk_13`, the FT601 — unrelated) |
| Camera independence | camera streamed throughout; `ldrop` never left 0 |

Two of the above — a stuck video-period latch and the lane swap — were working
theories that measurement **refuted**. Both cost a build. Prefer instrumenting the
one signal between two known-good stages over reasoning about which stage is wrong.

## Instrumentation (this is what made it findable)

All counted over one 65536-pixel window, readable over the Ft+ or COM6:

| reg | meaning |
|---|---|
| `0x60`–`0x63` | measured incoming h/v active |
| `0x64`–`0x66` | frame period, 10 ns units (Hz = 1e8/period) |
| `0x67` | `{vid_valid, meas_ok}` |
| `0x68`–`0x6A` | recovered pixel clock, kHz |
| `0x6B` | `[7]primed [6]idelay_rdy [5:3]ch2/1/0 invalid [2]dvid [1]pll [0]sym` |
| `0x6C` | phase-FIFO re-primes (static = healthy) |
| `0x6D`–`0x70` | ch0 control cycles / all-three coincident |
| `0x71`–`0x74` | **`in_vdp` duty / `in_adp` duty** |
| `0x75`–`0x78` | **vsync rises / hsync rises** per window (NOT preamble counts) |
| `0x79`–`0x7C` | **VDP guard band detected / `vdp_guardband_detect`** |

> `0x22`–`0x25` are **NOT** the input — they are the offline mode `mode_select` chose
> from the EDID. With a PC sending 1280×720 they read 1280×800.

Host: `host/rx_timing.py` (refuses to interpret when `meas_ok=0`),
`host/test_modecycle.py` (mode sweep; `--camera-only`).

## The pass-through pixel-clock floor is 40 MHz (Pt, and Au V2 alike)

> **SUPERSEDED 2026-08-31 -- THIS SECTION IS HISTORY, NOT CURRENT BEHAVIOUR.**
> The fixed `CLKFBOUT_MULT_F = 15.0` it describes is gone; `rx_freq_band` +
> `rx_drp_recfg` now retune the recovery MMCM per band. MEASURED on hardware:
> 640x480@75 locks at exactly 31500 kHz and 640x480@60 at 25156 kHz, both with
> `pll=1 sym=1` and zero invalid symbols -- so the "broken (below minimum)" rows
> in the table below are NO LONGER TRUE. Those modes still fail, but on SYNC
> DECODE, not on clocking: see "Known defects still open" section A.
> Keep this section for the arithmetic and for why the floor once existed.

`hdmi_input.vhd` fixes `CLKFBOUT_MULT_F = 15.0`, so VCO = pixel x 15. The Artix-7
`-2` MMCM VCO minimum is 600 MHz, giving a hard floor of **600 / 15 = 40.0 MHz**.
Measured behaviour matches that arithmetic exactly:

| mode | pixel clk | VCO | result |
|---|---|---|---|
| 1280x720@60 | 74.25 | 1114 | solid |
| 1280x800@60 | 71.00 | 1065 | solid |
| 1024x768@60 | 65.00 | 975 | solid |
| 800x600@75 | 49.50 | 743 | **TWITCHY — never worked, see below** |
| 800x600@60 | 40.00 | 600 | **TWITCHY — never worked, see below** |
| 640x480@75 | 31.50 | 473 | broken (below minimum) |
| 640x480@60 | 25.175 | 378 | broken (below minimum) |

**This is not a part limitation and moving boards will not fix it.** Au V2 is
`xc7a35tftg256-2`, Pt V2 is `xc7a100tfgg484-2` — same speed grade, same 600 MHz VCO
floor. A previous attempt on the Au V2 was abandoned; the Pt offers no advantage.

`edid_builder.v` already excludes 640x480 as `"<40, below floor"` — that floor came
from this same calculation.

> **CORRECTED TWICE. Read this before trusting any 800x600 claim.**
>
> First correction (wrong): this file blamed the VCO floor for 800x600's black
> sequences. The floor is real arithmetic but only excludes 640x480, so that was an
> overstatement.
>
> Second correction (the one that matters): the replacement text claimed 800x600
> "PASSES at both 60 and 75 Hz". **It does not.** That claim came from
> `test_modecycle.py`, which only checks the FPGA's measurement of the INCOMING
> raster -- it says nothing about the picture. The user reported 800x600 twitchy with
> black screens at both rates, before AND after every fix attempted on 2026-08-28.
>
> **800x600 PASS-THROUGH HAS NEVER WORKED, ON EITHER BOARD.** Before `8790569`,
> `edid_builder.v` read `Excluded: all 640x480/720x400/800x600 (<60, below floor)` --
> the x10 recovery MMCM could not reach it. `8790569` changed x10 to x15, widening the
> window to 40-90 MHz, and ADDED 800x600@60/72/75 **because the arithmetic now
> admitted it**. That commit's hardware verification was `1024x768@60 and @75 rock
> solid` -- 1024x768 only. 800x600 went from excluded-by-calculation to
> advertised-by-calculation without ever being looked at.
>
> On the Pt it was never exercised at all: M1's hardware record is
> `mode_idx 2 (1024x768@75), edid_ok False -- correct failsafe, no display`, i.e.
> verified with NO DISPLAY ATTACHED.
>
> The thing that IS solid at 800x600 is the OFFLINE path -- all 14 table modes were
> eyes-on verified on 2026-08-28. Offline generates its own clean clock and emits no
> data islands. That contrast is the evidence, not a contradiction.

**There is also nothing to fix in the EDID.** Verified against Windows' own cached
copy of the EDID we serve: byte35 = `0x01`, so bit5 (640x480@60) and bit2
(640x480@75) are both **zero** -- we already do not advertise them. The merge is
provably correct: the attached Dell offers `0xA5`, our mask is `0x01`, Windows
received `0xA5 & 0x01 = 0x01`; byte36 likewise `0x4B & 0xCE = 0x4A`. 640x480 shows
up in Windows' mode list because the OS exposes it as a legacy fallback regardless
of EDID (CEA-861 requires VIC 1 of HDMI sinks generally), and Windows substitutes a
different mode when asked to actually set it.
**Alternative (expensive, deliberately not done):** DRP-reconfigure `CLKFBOUT_MULT`,
all three `CLKOUT` dividers and the filter/lock registers per XAPP888 to raise the
multiplier at low pixel clocks (x30 at 25.175 MHz = 755 MHz, in range), re-locking
cleanly on every mode change.

**Left unmeasured:** `CLKIN1_PERIOD` is hard-coded at 13.000 ns (76.9 MHz) while the
real input varies per mode; it programs the lock filter and is a second, weaker
effect on top of the VCO floor. A 20.000 ns diagnostic build was started to separate
the two and abandoned before finishing. Do not assume it is or is not a contributor.
It is the obvious first probe if a low-clock mode is ever chased again -- though
800x600@75 no longer needs chasing.

## Known defects still open

_Register rebuilt 2026-08-31 from a full audit of the pass-through path plus that
day's measurements. Grouped by ROOT CAUSE / WORKAROUND / INSTRUMENT, because most of
the list exists only because the first group was never fixed._

### A. Decoder root causes

All of this is INHERITED code -- `hdmi_input`, `tmds_decoder`, `tmds_encoder`,
`input_channel`, `alignment_detect`, `deserialiser_1_to_10`, `hdmi_io` all arrived
whole as "Add files via upload" (2025-03-24 / 2025-04-17, `Engineer: Qihsi Hu`) and
were never audited. They showed a picture at 1280x720 and 1024x768, and that was
taken as sufficient.

1. **THE CONTROL-PERIOD DETECTOR IS SYMBOL-LOCAL.** It declares a control period
   whenever three symbols pattern-match control codes, ANYWHERE in the line, with no
   knowledge of where it is in the raster. A correct receiver brackets the video data
   period with the preamble -> guard-band -> video SEQUENCE. MEASURED per line
   (65536-px windows, normalised):

   | mode | ctl_call/line | real hblank | vdp/line | real active | display |
   |---|---|---|---|---|---|
   | 1280x720@60 | 363.6 | 370 | 1249 | 1280 | works |
   | 640x480@75 | **232.9** | **200** | 600 | 640 | 95% black |

   A control period CANNOT outlast the blanking interval. At 640x480 it does, by 33
   cycles per line -- real VIDEO data decoding as control on all three lanes at once.
   Each of those cycles feeds `ch0_ctl(1)` into vsync, i.e. pushes PIXEL DATA into the
   sync signal, and steals the same ~40 px from the video period.
   The false rate per line is roughly CONSTANT; only the denominator changes --
   33/370 = 9% at 720p, 33/200 = 16.5%, 33/160 = 21% at 640x480@60. That is the whole
   ">=256 px blanking works / <=200 fails" split, and it is why a majority vote cannot
   close it: the false samples are IN the vote.

2. **The preamble gate does no real work.** 14680 hits per window -- essentially every
   control cycle -- where a real 8-character preamble gives ~320. `ch1_ctl` is
   effectively stuck at `"01"`, so `vdp_prefix_seen` is asserted almost continuously.
   Logged earlier as "permissive rather than blocking [...] may bite later". IT BIT.

3. **Only one of the two guard characters is detected.** Worked around, not explained.

4. **`alignment_detect` IS STRUCTURALLY BLIND TO THE ERROR THAT MATTERS.** Its only
   feedback is `invalid_symbol`. A corrupted control symbol is still a LEGAL control
   code, so the flag never fires, the delay is never advanced, bitslip never asserts --
   and every instrument reports a perfect link while sync rots. This is why
   `inv ch2/ch1/ch0 = 0/0/0`, `sym=1`, `pll=1` coexisted with a black screen all day.
   **"Zero invalid symbols" is NOT evidence the link is clean.**

5. **The video data period runs ~40 px/line short and is unstable** -- 600 detected vs
   640 real at 640x480@75, drifting 600 <-> 641 between reads. Consequence of (1).

### B. Workarounds stacked on the above (2026-08-31, UNCOMMITTED)

Every one of these exists only because A1-A4 are unfixed. If A is repaired these
should be DELETED, not left layered on a correct decoder.

6. Sync HELD through the VDP instead of forced low. Spec-correct and a proven no-op for
   positive-polarity modes. **Did not fix the target bug.**
7. ADP sync overwrite removed (two sites). Defensible independently -- `edid_merge`
   forwards no CEA extension, so we present a DVI sink and every data island is
   spurious by construction. **Did not fix the target bug.**
8. 16-cycle persistence debounce. **MANUFACTURED A DEFECT** -- control cycles exist only
   inside blanking, so an edge arriving late deferred into the next line, giving +/-1
   line jitter in the transmitted frame. Removed.
9. Per-line vsync majority vote committed at the hsync edge. Jitter span 2 -> 1.
   OFFLINE at the same mode is span 0. **Partial.**
10. `CTL_MIN = 12` qualified-control-period gate on the sync latch only. Gates sync,
    NOT `in_vdp`/`raw_blank`/pixels, so working-mode geometry cannot shift -- which also
    means the ~40 stolen pixels are NOT recovered. Built 2026-08-31, result pending.

### C. Instruments that misreported

11. **`pre_diag`'s header comment is WRONG.** It claims `[15:0]` = video preamble
    as-coded and `[31:16]` = the same with ch1/ch2 swapped. The live code counts
    **vsync rises** and **hsync rises**. Reading the header instead of the code yields a
    bogus "the channels are swapped" conclusion -- it produced exactly that today.
12. `vdp_diag[31:16]` is labelled `in_dvid` but counts `in_adp`.
13. `video_meas` `vs_hi` overflow: 22-bit counter, 2^21 window, and the ">= half" test
    reads bit 20. At 100.0% duty the count reaches 2^21, bit 20 CLEARS, and the vote
    comes out INVERTED. Latent, not today's cause.
14. `vs_pol` reads 0 even at 1024x768@60, a negative-vsync mode that passes through
    perfectly. The polarity detector does not do what its comments claim.
15. **Saturating 8-bit counters read 255 and look STALE while actively climbing.** This
    hid `edid_fall` for hours -- it reads 255 static, and only a bitstream reload (which
    zeroes it) reveals it is incrementing ~3/sec.
16. `video_phase_fifo` freezes `rdata` when unprimed, so a stalled FIFO emits a FROZEN
    raster rather than blanking -- it presents as valid signal, not as "no signal".

### D. Open and unexplained

17. ~~`edid_fall` climbs ~3/sec~~ **NOT A DEFECT -- RESOLVED 2026-08-31.** It is the
    designed monitor-presence heartbeat. `edid_merge` has no working output HPD sense,
    so it re-reads the display EDID over DDC on a `probe_cnt == 50_000_000` timer at
    clk100 = **exactly 0.5 s = 2.0 Hz**, and `chk0_ok` deasserts during each read and
    re-asserts on a good checksum -> one falling edge per probe. Measured ~2/sec, an
    exact match. A HEALTHY board sits at 2/sec forever; the 8-bit counter saturating at
    255 just means it has been up two minutes. The NAME reads like an error counter and
    it is not one -- that misled this investigation twice, first as "stale", then as a
    "live unexplained fault".
18. 640x480@60 (160 px blanking, the worst case in the table) is untested against any
    2026-08-31 change.
19. 1280x800@60 is claimed working at hblank 160, which would BREAK the blanking
    correlation. The attached display does not offer that mode, so the load-bearing
    counter-example cannot be checked here. Treat the correlation as unconfirmed until
    it is.

### E. Theories KILLED by measurement (do not revive without new evidence)

* **Negative sync polarity.** 1024x768@60 is `-hsync -vsync` and passes through
  perfectly. Both the vsync and the hsync variants of this theory are dead.
* **Low pixel clock / IDELAY range.** OFFLINE drives the SAME 31500 kHz to the SAME
  sink flawlessly (`v_active` span 0). 315 Mbps is not too slow for this board, cable
  or display.
* **Single-bit errors from an uncentred eye.** The implied BER (~4e-4) would visibly
  destroy pixel data; all three lanes report ZERO invalid symbols.
* **Blanking budget as a spec limit.** 160 px is far above the ~22-character HDMI
  minimum. Short blanking is the STRESSOR that exposes A1, not the cause.
* The raster measured `1281x720` -- one extra pixel per line -- because `in_vdp` rose a
  cycle early. Fixed in `c1b00c6`; re-measure for exactly 1280 if it recurs.

## Two traps that cost time here

**An HDMI-only isolation build is a dead end as specified.** `cam_frame_ft` owns every
`ft_*` pin *and* `usb_tx`, so `WITH_CAM=0` deletes the register readback path along
with the camera — leaving no way to read the diagnostics it was built to expose. The
Ft+ reply path also rides the video frame stream, so it needs the camera streaming.

**The EDID source changed mid-investigation** (fob → real display), which changes the
merged EDID served to the PC and therefore the timings Windows uses. Measurements
spanning that swap are not comparable.

## Build environment

Roughly half of all Vivado runs died for reasons unrelated to the design: `EXIT=127`
mid-synthesis, `EXIT=139` (SIGSEGV), a bitgen `[Designutils 12-1097]` that vanished on
retry, CPython segfaults, and corrupt git objects. **Always check for the `BUILD DONE`
marker and a fresh bitfile timestamp, not the exit code** — flashing a stale bitstream
reads as a hardware result. Two Vivado instances sharing the out-of-tree IP dir cause a
real `upgrade_ip` failure; run one. See `[[step-write-corruption]]`.

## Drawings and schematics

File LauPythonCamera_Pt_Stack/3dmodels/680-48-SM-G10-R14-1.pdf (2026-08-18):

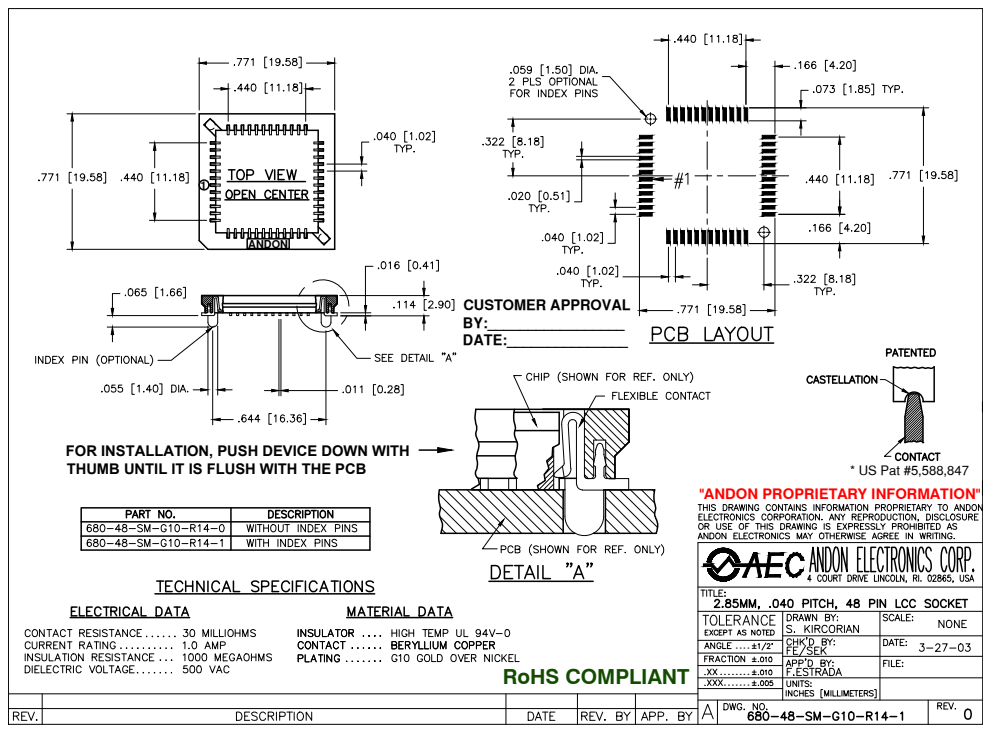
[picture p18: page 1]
THUMB UNTIL IT IS FLUSH WITH THE PCB; * US Pat #5,588,847; RoHS COMPLIANT; CUSTOMER APPROVAL

FOR INSTALLATION, PUSH DEVICE DOWN WITH

"ANDON PROPRIETARY INFORMATION"

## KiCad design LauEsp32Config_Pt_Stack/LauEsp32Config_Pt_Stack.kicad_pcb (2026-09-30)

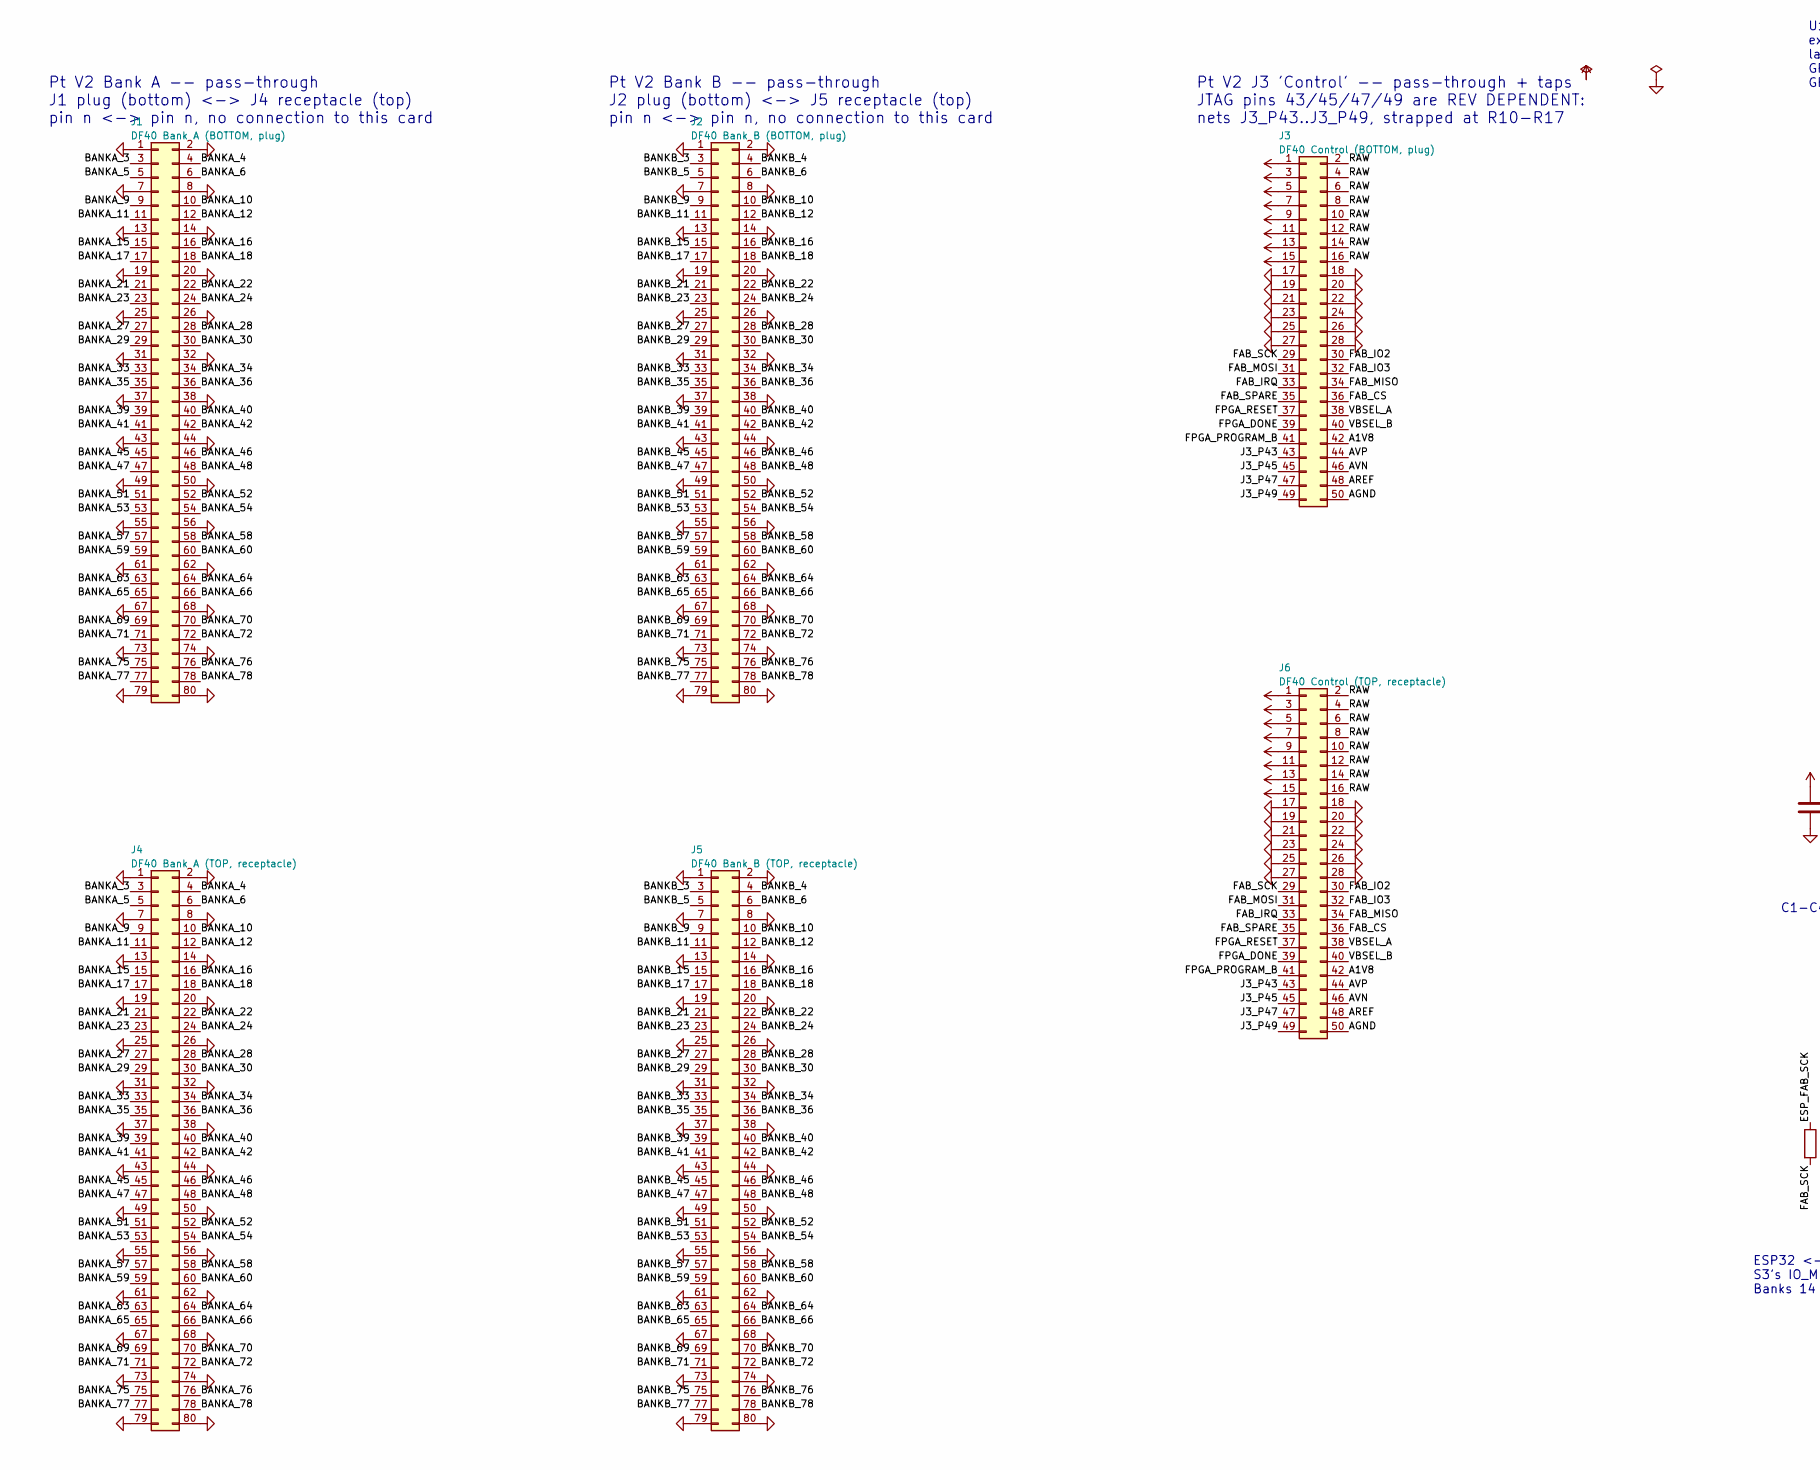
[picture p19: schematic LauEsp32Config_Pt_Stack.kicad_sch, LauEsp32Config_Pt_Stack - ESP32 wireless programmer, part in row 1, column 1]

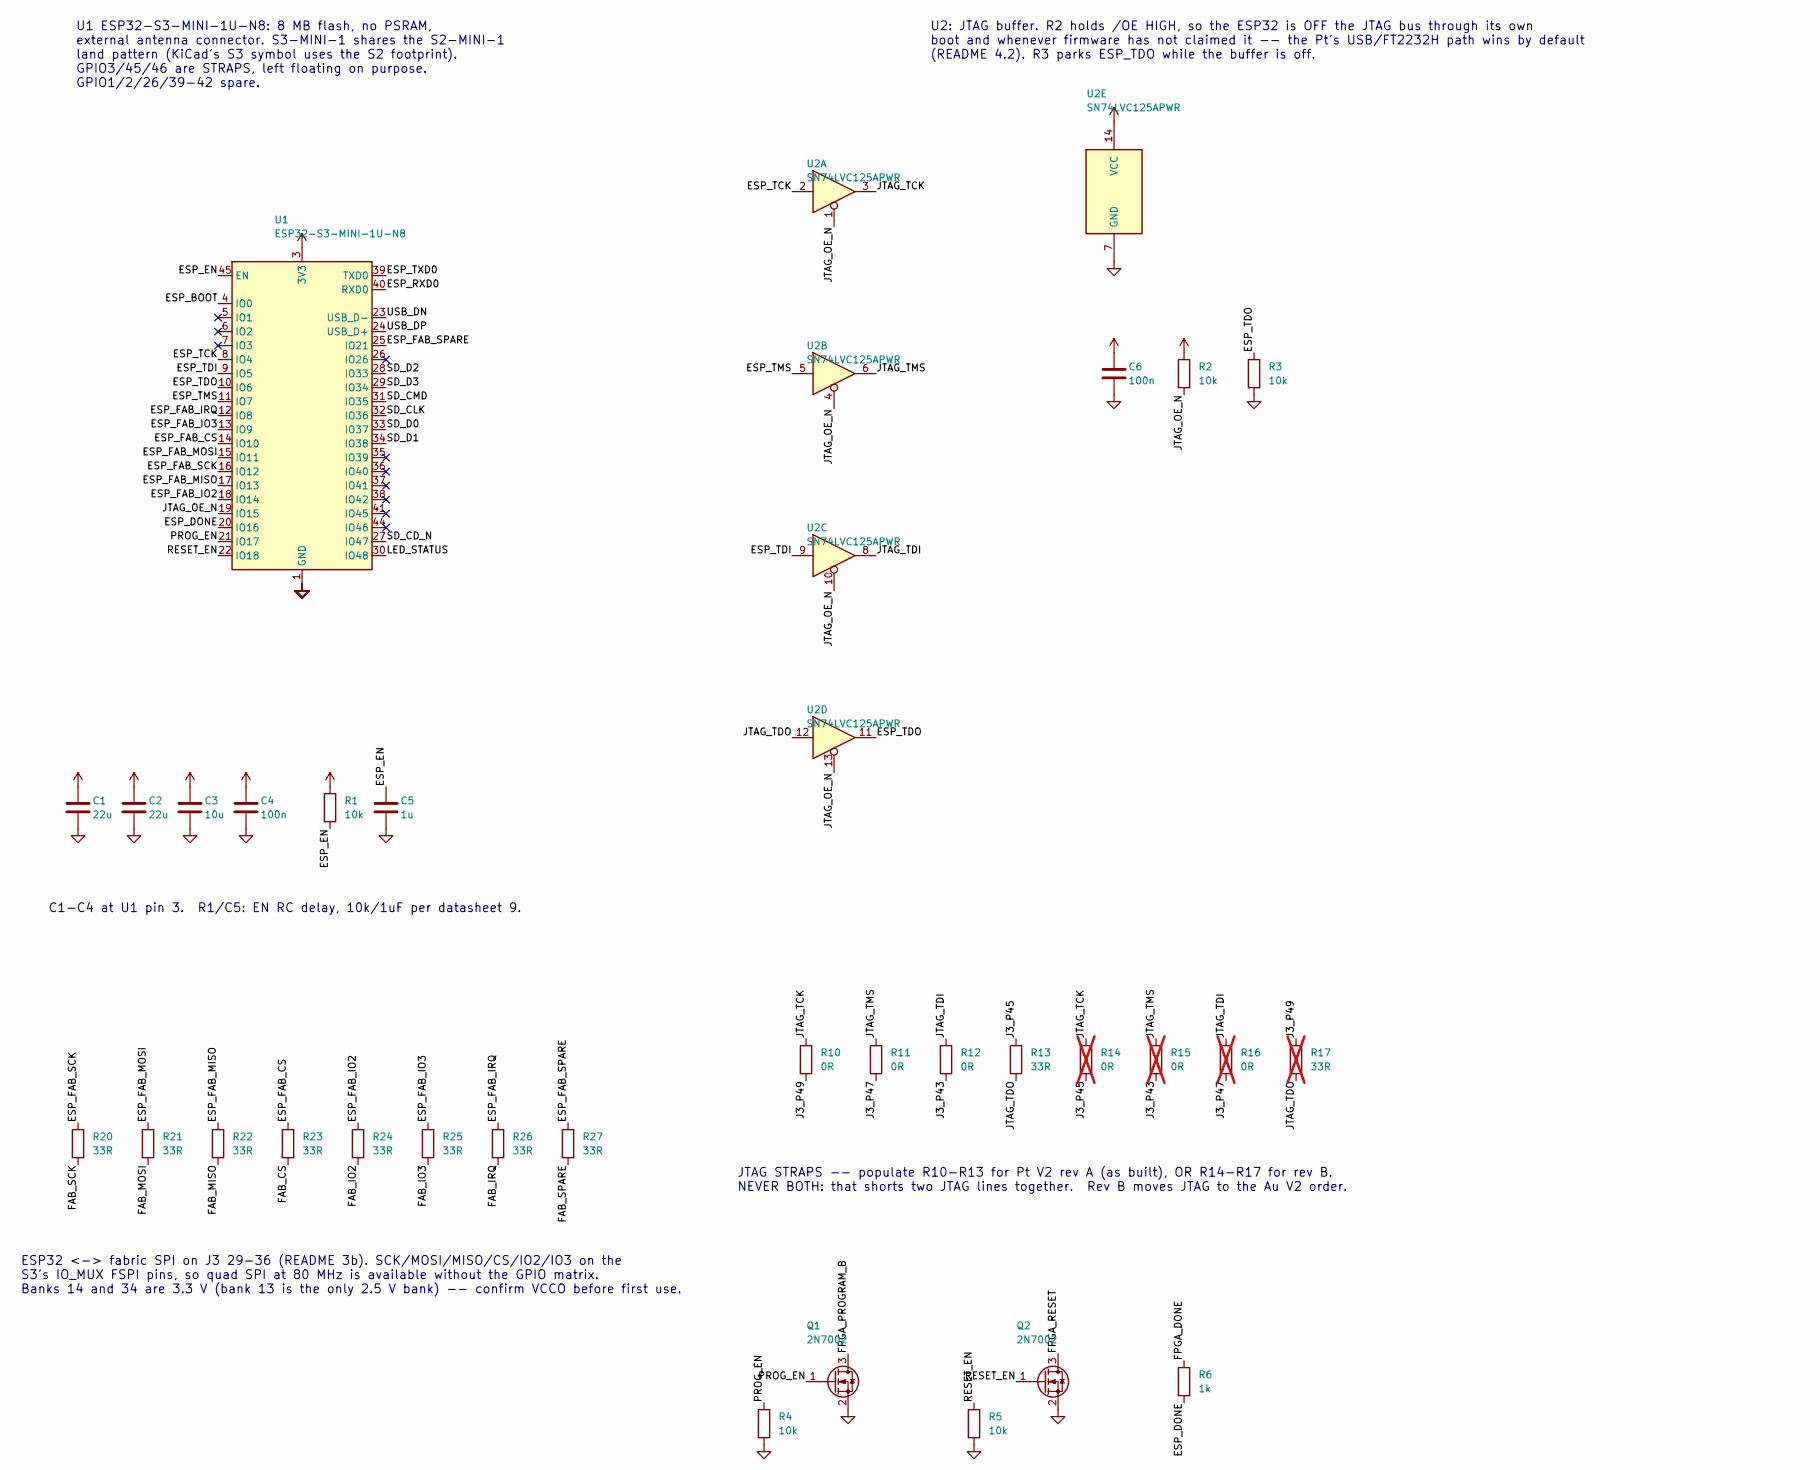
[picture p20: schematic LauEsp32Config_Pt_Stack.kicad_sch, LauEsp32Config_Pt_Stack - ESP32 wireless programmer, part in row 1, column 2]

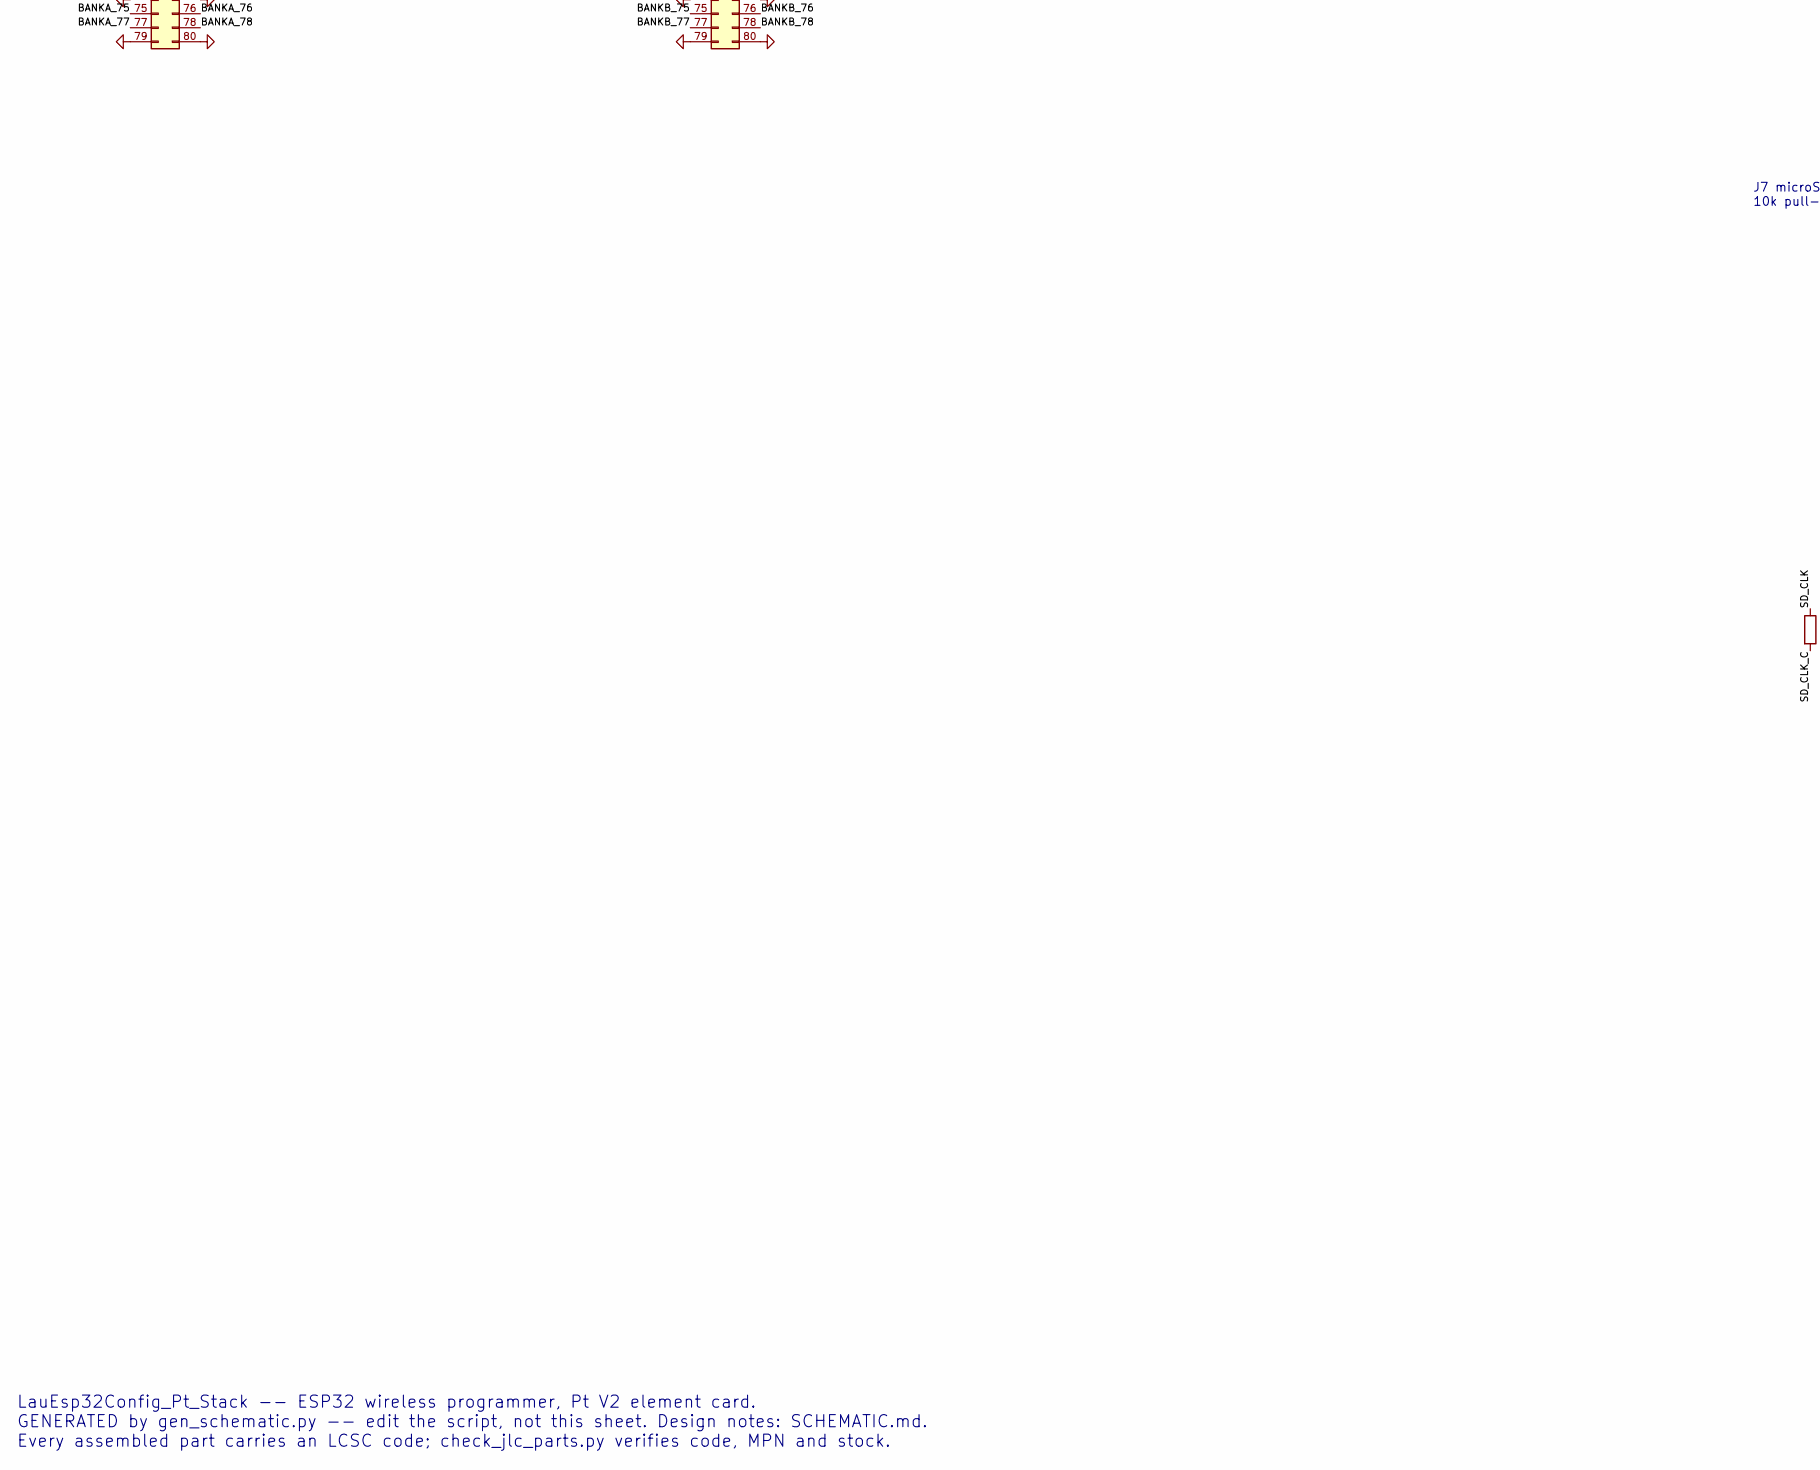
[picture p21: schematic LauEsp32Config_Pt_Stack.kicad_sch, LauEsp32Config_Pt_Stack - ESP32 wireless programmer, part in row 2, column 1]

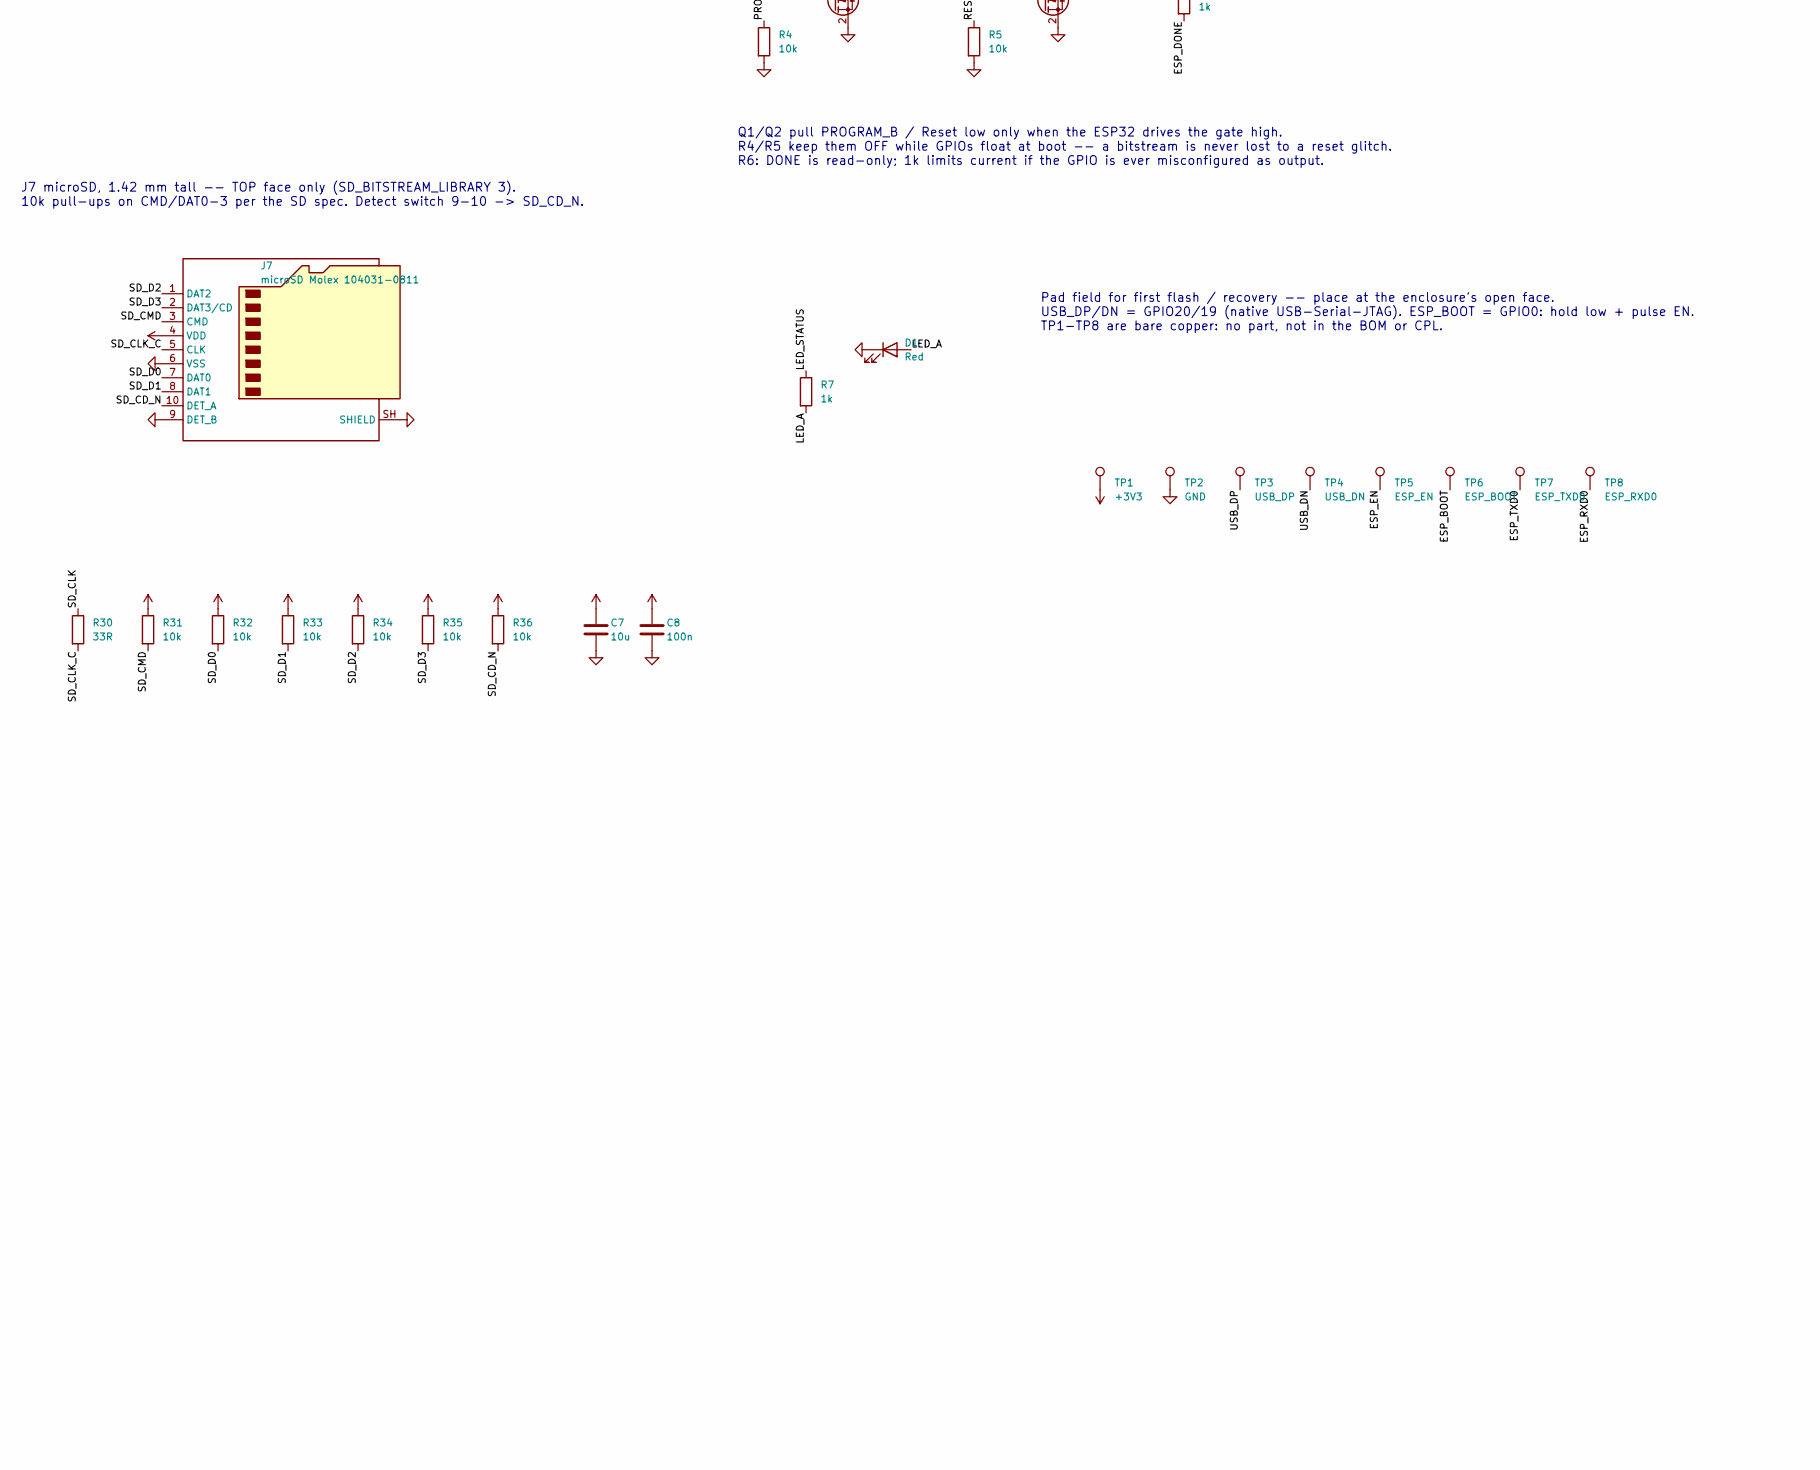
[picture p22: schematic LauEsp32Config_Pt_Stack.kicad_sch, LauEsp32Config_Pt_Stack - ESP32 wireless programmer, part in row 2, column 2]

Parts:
C1, C2: 22u; C_0805_2012Metric; MPN CL21A226MAQNNNE; LCSC C45783
C3, C7: 10u; C_0805_2012Metric; MPN CL21A106KAYNNNE; LCSC C15850
C4, C6, C8: 100n; C_0402_1005Metric; MPN CL05B104KO5NNNC; LCSC C1525
C5: 1u; C_0402_1005Metric; MPN CL05A105KA5NQNC; LCSC C52923
D1: Red; LED_0603_1608Metric; MPN KT-0603R; LCSC C2286
J1: DF40 Bank A (BOTTOM, plug); Hirose_DF40C-80DP-0.4V_2x40-1MP_P0.4mm; MPN DF40C-80DP-0.4V(51); LCSC C294544
J2: DF40 Bank B (BOTTOM, plug); Hirose_DF40C-80DP-0.4V_2x40-1MP_P0.4mm; MPN DF40C-80DP-0.4V(51); LCSC C294544
J3: DF40 Control (BOTTOM, plug); Hirose_DF40C-50DP-0.4V_2x25-1MP_P0.4mm; MPN DF40C-50DP-0.4V(51); LCSC C424645
J4: DF40 Bank A (TOP, receptacle); Hirose_DF40HC(4.0)-80DS-0.4V_2x40_P0.4mm; MPN DF40HC(4.0)-80DS-0.4V(51); LCSC C5254351
J5: DF40 Bank B (TOP, receptacle); Hirose_DF40HC(4.0)-80DS-0.4V_2x40_P0.4mm; MPN DF40HC(4.0)-80DS-0.4V(51); LCSC C5254351
J6: DF40 Control (TOP, receptacle); Hirose_DF40HC(4.0)-50DS-0.4V_2x25_P0.4mm; MPN DF40HC(4.0)-50DS-0.4V(51); LCSC C5338326
J7: microSD Molex 104031-0811; microSD_HC_Molex_104031-0811; MPN 1040310811; LCSC C585350
Q1, Q2: 2N7002; SOT-23; MPN 2N7002; LCSC C8545
R1, R2, R3, R4, R5, R31, R32, R33, R34, R35, R36: 10k; R_0402_1005Metric; MPN 0402WGF1002TCE; LCSC C25744
R6, R7: 1k; R_0402_1005Metric; MPN 0402WGF1001TCE; LCSC C11702
R10, R11, R12: 0R; R_0402_1005Metric; MPN 0402WGF0000TCE; LCSC C17168
R13, R20, R21, R22, R23, R24, R25, R26, R27, R30: 33R; R_0402_1005Metric; MPN 0402WGF330JTCE; LCSC C25105
R14, R15, R16: 0R; R_0402_1005Metric; MPN 0402WGF0000TCE; LCSC C17168; not fitted
R17: 33R; R_0402_1005Metric; MPN 0402WGF330JTCE; LCSC C25105; not fitted
TP1: +3V3; TestPoint_Pad_D1.0mm
TP2: GND; TestPoint_Pad_D1.0mm
TP3: USB_DP; TestPoint_Pad_D1.0mm
TP4: USB_DN; TestPoint_Pad_D1.0mm
TP5: ESP_EN; TestPoint_Pad_D1.0mm
TP6: ESP_BOOT; TestPoint_Pad_D1.0mm
TP7: ESP_TXD0; TestPoint_Pad_D1.0mm
TP8: ESP_RXD0; TestPoint_Pad_D1.0mm
U1: ESP32-S3-MINI-1U-N8; ESP32-S2-MINI-1U; MPN ESP32-S3-MINI-1U-N8; LCSC C2980299
U2: SN74LVC125APWR; TSSOP-14_4.4x5mm_P0.65mm; MPN SN74LVC125APWR; LCSC C7813

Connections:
+3V3: C1.1, C2.1, C3.1, C4.1, C6.1, C7.1, C8.1, J3.1, J3.3, J3.5, J3.7, J3.9, J3.11, J3.13, J3.15, J6.1, J6.3, J6.5, J6.7, J6.9, J6.11, J6.13, J6.15, J7.4 (VDD), R1.1, R2.1, R31.1, R32.1, R33.1, R34.1, R35.1, R36.1, TP1.1, U1.3 (3V3), U2.14 (VCC)
/A1V8: J3.42, J6.42
/AGND: J3.50, J6.50
/AREF: J3.48, J6.48
/AVN: J3.46, J6.46
/AVP: J3.44, J6.44
/BANKA_3: J1.3, J4.3
/BANKA_4: J1.4, J4.4
/BANKA_5: J1.5, J4.5
/BANKA_6: J1.6, J4.6
/BANKA_9: J1.9, J4.9
/BANKA_10: J1.10, J4.10
/BANKA_11: J1.11, J4.11
/BANKA_12: J1.12, J4.12
/BANKA_15: J1.15, J4.15
/BANKA_16: J1.16, J4.16
/BANKA_17: J1.17, J4.17
/BANKA_18: J1.18, J4.18
/BANKA_21: J1.21, J4.21
/BANKA_22: J1.22, J4.22
/BANKA_23: J1.23, J4.23
/BANKA_24: J1.24, J4.24
/BANKA_27: J1.27, J4.27
/BANKA_28: J1.28, J4.28
/BANKA_29: J1.29, J4.29
/BANKA_30: J1.30, J4.30
/BANKA_33: J1.33, J4.33
/BANKA_34: J1.34, J4.34
/BANKA_35: J1.35, J4.35
/BANKA_36: J1.36, J4.36
/BANKA_39: J1.39, J4.39
/BANKA_40: J1.40, J4.40
/BANKA_41: J1.41, J4.41
/BANKA_42: J1.42, J4.42
/BANKA_45: J1.45, J4.45
/BANKA_46: J1.46, J4.46
/BANKA_47: J1.47, J4.47
/BANKA_48: J1.48, J4.48
/BANKA_51: J1.51, J4.51
/BANKA_52: J1.52, J4.52
/BANKA_53: J1.53, J4.53
/BANKA_54: J1.54, J4.54
/BANKA_57: J1.57, J4.57
/BANKA_58: J1.58, J4.58
/BANKA_59: J1.59, J4.59
/BANKA_60: J1.60, J4.60
/BANKA_63: J1.63, J4.63
/BANKA_64: J1.64, J4.64
/BANKA_65: J1.65, J4.65
/BANKA_66: J1.66, J4.66
/BANKA_69: J1.69, J4.69
/BANKA_70: J1.70, J4.70
/BANKA_71: J1.71, J4.71
/BANKA_72: J1.72, J4.72
/BANKA_75: J1.75, J4.75
/BANKA_76: J1.76, J4.76
/BANKA_77: J1.77, J4.77
/BANKA_78: J1.78, J4.78
/BANKB_3: J2.3, J5.3
/BANKB_4: J2.4, J5.4
/BANKB_5: J2.5, J5.5
/BANKB_6: J2.6, J5.6
/BANKB_9: J2.9, J5.9
/BANKB_10: J2.10, J5.10
/BANKB_11: J2.11, J5.11
/BANKB_12: J2.12, J5.12
/BANKB_15: J2.15, J5.15
/BANKB_16: J2.16, J5.16
/BANKB_17: J2.17, J5.17
/BANKB_18: J2.18, J5.18
/BANKB_21: J2.21, J5.21
/BANKB_22: J2.22, J5.22
/BANKB_23: J2.23, J5.23
/BANKB_24: J2.24, J5.24
/BANKB_27: J2.27, J5.27
/BANKB_28: J2.28, J5.28
/BANKB_29: J2.29, J5.29
/BANKB_30: J2.30, J5.30
/BANKB_33: J2.33, J5.33
/BANKB_34: J2.34, J5.34
/BANKB_35: J2.35, J5.35
/BANKB_36: J2.36, J5.36
/BANKB_39: J2.39, J5.39
/BANKB_40: J2.40, J5.40
/BANKB_41: J2.41, J5.41
/BANKB_42: J2.42, J5.42
/BANKB_45: J2.45, J5.45
/BANKB_46: J2.46, J5.46
/BANKB_47: J2.47, J5.47
/BANKB_48: J2.48, J5.48
/BANKB_51: J2.51, J5.51
/BANKB_52: J2.52, J5.52
/BANKB_53: J2.53, J5.53
/BANKB_54: J2.54, J5.54
/BANKB_57: J2.57, J5.57
/BANKB_58: J2.58, J5.58
/BANKB_59: J2.59, J5.59
/BANKB_60: J2.60, J5.60
/BANKB_63: J2.63, J5.63
/BANKB_64: J2.64, J5.64
/BANKB_65: J2.65, J5.65
/BANKB_66: J2.66, J5.66
/BANKB_69: J2.69, J5.69
/BANKB_70: J2.70, J5.70
/BANKB_71: J2.71, J5.71
/BANKB_72: J2.72, J5.72
/BANKB_75: J2.75, J5.75
/BANKB_76: J2.76, J5.76
/BANKB_77: J2.77, J5.77
/BANKB_78: J2.78, J5.78
/ESP_BOOT: TP6.1, U1.4 (IO0)
/ESP_DONE: R6.2, U1.20 (IO16)
/ESP_EN: C5.1, R1.2, TP5.1, U1.45 (EN)
/ESP_FAB_CS: R23.1, U1.14 (IO10)
/ESP_FAB_IO2: R24.1, U1.18 (IO14)
/ESP_FAB_IO3: R25.1, U1.13 (IO9)
/ESP_FAB_IRQ: R26.1, U1.12 (IO8)
/ESP_FAB_MISO: R22.1, U1.17 (IO13)
/ESP_FAB_MOSI: R21.1, U1.15 (IO11)
/ESP_FAB_SCK: R20.1, U1.16 (IO12)
/ESP_FAB_SPARE: R27.1, U1.25 (IO21)
/ESP_RXD0: TP8.1, U1.40 (RXD0)
/ESP_TCK: U1.8 (IO4), U2.2
/ESP_TDI: U1.9 (IO5), U2.9
/ESP_TDO: R3.1, U1.10 (IO6), U2.11
/ESP_TMS: U1.11 (IO7), U2.5
/ESP_TXD0: TP7.1, U1.39 (TXD0)
/FAB_CS: J3.36, J6.36, R23.2
/FAB_IO2: J3.30, J6.30, R24.2
/FAB_IO3: J3.32, J6.32, R25.2
/FAB_IRQ: J3.33, J6.33, R26.2
/FAB_MISO: J3.34, J6.34, R22.2
/FAB_MOSI: J3.31, J6.31, R21.2
/FAB_SCK: J3.29, J6.29, R20.2
/FAB_SPARE: J3.35, J6.35, R27.2
/FPGA_DONE: J3.39, J6.39, R6.1
/FPGA_PROGRAM_B: J3.41, J6.41, Q1.3 (D)
/FPGA_RESET: J3.37, J6.37, Q2.3 (D)
/J3_P43: J3.43, J6.43, R12.2, R15.2
/J3_P45: J3.45, J6.45, R13.1, R14.2
/J3_P47: J3.47, J6.47, R11.2, R16.2
/J3_P49: J3.49, J6.49, R10.2, R17.1
/JTAG_OE_N: R2.2, U1.19 (IO15), U2.1, U2.4, U2.10, U2.13
/JTAG_TCK: R10.1, R14.1, U2.3
/JTAG_TDI: R12.1, R16.1, U2.8
/JTAG_TDO: R13.2, R17.2, U2.12
/JTAG_TMS: R11.1, R15.1, U2.6
/LED_A: D1.2 (A), R7.2
/LED_STATUS: R7.1, U1.30 (IO48)
/PROG_EN: Q1.1 (G), R4.1, U1.21 (IO17)
/RAW: J3.2, J3.4, J3.6, J3.8, J3.10, J3.12, J3.14, J3.16, J6.2, J6.4, J6.6, J6.8, J6.10, J6.12, J6.14, J6.16
/RESET_EN: Q2.1 (G), R5.1, U1.22 (IO18)
/SD_CD_N: J7.10 (DET_A), R36.2, U1.27 (IO47)
/SD_CLK: R30.1, U1.32 (IO36)
/SD_CLK_C: J7.5 (CLK), R30.2
/SD_CMD: J7.3 (CMD), R31.2, U1.31 (IO35)
/SD_D0: J7.7 (DAT0), R32.2, U1.33 (IO37)
/SD_D1: J7.8 (DAT1), R33.2, U1.34 (IO38)
/SD_D2: J7.1 (DAT2), R34.2, U1.28 (IO33)
/SD_D3: J7.2 (DAT3/CD), R35.2, U1.29 (IO34)
/USB_DN: TP4.1, U1.23 (USB_D-)
/USB_DP: TP3.1, U1.24 (USB_D+)
/VBSEL_A: J3.38, J6.38
/VBSEL_B: J3.40, J6.40
GND: C1.2, C2.2, C3.2, C4.2, C5.2, C6.2, C7.2, C8.2, D1.1 (K), J1.1, J1.2, J1.7, J1.8, J1.13, J1.14, J1.19, J1.20, J1.25, J1.26, J1.31, J1.32, J1.37, J1.38, J1.43, J1.44, J1.49, J1.50, J1.55, J1.56, J1.61, J1.62, J1.67, J1.68, J1.73, J1.74, J1.79, J1.80, J2.1, J2.2, J2.7, J2.8, J2.13, J2.14, J2.19, J2.20, J2.25, J2.26, J2.31, J2.32, J2.37, J2.38, J2.43, J2.44, J2.49, J2.50, J2.55, J2.56, J2.61, J2.62, J2.67, J2.68, J2.73, J2.74, J2.79, J2.80, J3.17, J3.18, J3.19, J3.20, J3.21, J3.22, J3.23, J3.24, J3.25, J3.26, J3.27, J3.28, J4.1, J4.2, J4.7, J4.8, J4.13, J4.14, J4.19, J4.20, J4.25, J4.26, J4.31, J4.32, J4.37, J4.38, J4.43, J4.44, J4.49, J4.50, J4.55, J4.56, J4.61, J4.62, J4.67, J4.68, J4.73, J4.74, J4.79, J4.80, J5.1, J5.2, J5.7, J5.8, J5.13, J5.14, J5.19, J5.20, J5.25, J5.26, J5.31, J5.32, J5.37, J5.38, J5.43, J5.44, J5.49, J5.50, J5.55, J5.56, J5.61, J5.62, J5.67, J5.68, J5.73, J5.74, J5.79, J5.80, J6.17, J6.18, J6.19, J6.20, J6.21, J6.22, J6.23, J6.24, J6.25, J6.26, J6.27, J6.28, J7.6 (VSS), J7.9 (DET_B), J7.SH (SHIELD), Q1.2 (S), Q2.2 (S), R3.2, R4.2, R5.2, TP2.1, U1.1 (GND), U1.2 (GND), U1.42 (GND), U1.43 (GND), U1.46 (GND), U1.47 (GND), U1.48 (GND), U1.49 (GND), U1.50 (GND), U1.51 (GND), U1.52 (GND), U1.53 (GND), U1.54 (GND), U1.55 (GND), U1.56 (GND), U1.57 (GND), U1.58 (GND), U1.59 (GND), U1.60 (GND), U1.61 (GND), U1.62 (GND), U1.63 (GND), U1.64 (GND), U1.65 (GND), U2.7 (GND)

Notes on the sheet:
Pt V2 Bank A -- pass-through J1 plug (bottom) <-> J4 receptacle (top) pin n <-> pin n, no connection to this card
Pt V2 Bank B -- pass-through J2 plug (bottom) <-> J5 receptacle (top) pin n <-> pin n, no connection to this card
Pt V2 J3 'Control' -- pass-through + taps JTAG pins 43/45/47/49 are REV DEPENDENT: nets J3_P43..J3_P49, strapped at R10-R17
U1 ESP32-S3-MINI-1U-N8: 8 MB flash, no PSRAM, external antenna connector. S3-MINI-1 shares the S2-MINI-1 land pattern (KiCad's S3 symbol uses the S2 footprint). GPIO3/45/46 are STRAPS, left floating on purpose. GPIO1/2/26/39-42 spare.
C1-C4 at U1 pin 3. R1/C5: EN RC delay, 10k/1uF per datasheet 9.
U2: JTAG buffer. R2 holds /OE HIGH, so the ESP32 is OFF the JTAG bus through its own boot and whenever firmware has not claimed it -- the Pt's USB/FT2232H path wins by default (README 4.2). R3 parks ESP_TDO while the buffer is off.
JTAG STRAPS -- populate R10-R13 for Pt V2 rev A (as built), OR R14-R17 for rev B. NEVER BOTH: that shorts two JTAG lines together. Rev B moves JTAG to the Au V2 order.
Q1/Q2 pull PROGRAM_B / Reset low only when the ESP32 drives the gate high. R4/R5 keep them OFF while GPIOs float at boot -- a bitstream is never lost to a reset glitch. R6: DONE is read-only; 1k limits current if the GPIO is ever misconfigured as output.
ESP32 <-> fabric SPI on J3 29-36 (README 3b). SCK/MOSI/MISO/CS/IO2/IO3 on the S3's IO_MUX FSPI pins, so quad SPI at 80 MHz is available without the GPIO matrix. Banks 14 and 34 are 3.3 V (bank 13 is the only 2.5 V bank) -- confirm VCCO before first use.
J7 microSD, 1.42 mm tall -- TOP face only (SD_BITSTREAM_LIBRARY 3). 10k pull-ups on CMD/DAT0-3 per the SD spec. Detect switch 9-10 -> SD_CD_N.
Pad field for first flash / recovery -- place at the enclosure's open face. USB_DP/DN = GPIO20/19 (native USB-Serial-JTAG). ESP_BOOT = GPIO0: hold low + pulse EN. TP1-TP8 are bare copper: no part, not in the BOM or CPL.
LauEsp32Config_Pt_Stack -- ESP32 wireless programmer, Pt V2 element card. GENERATED by gen_schematic.py -- edit the script, not this sheet. Design notes: SCHEMATIC.md. Every assembled part carries an LCSC code; check_jlc_parts.py verifies code, MPN and stock.

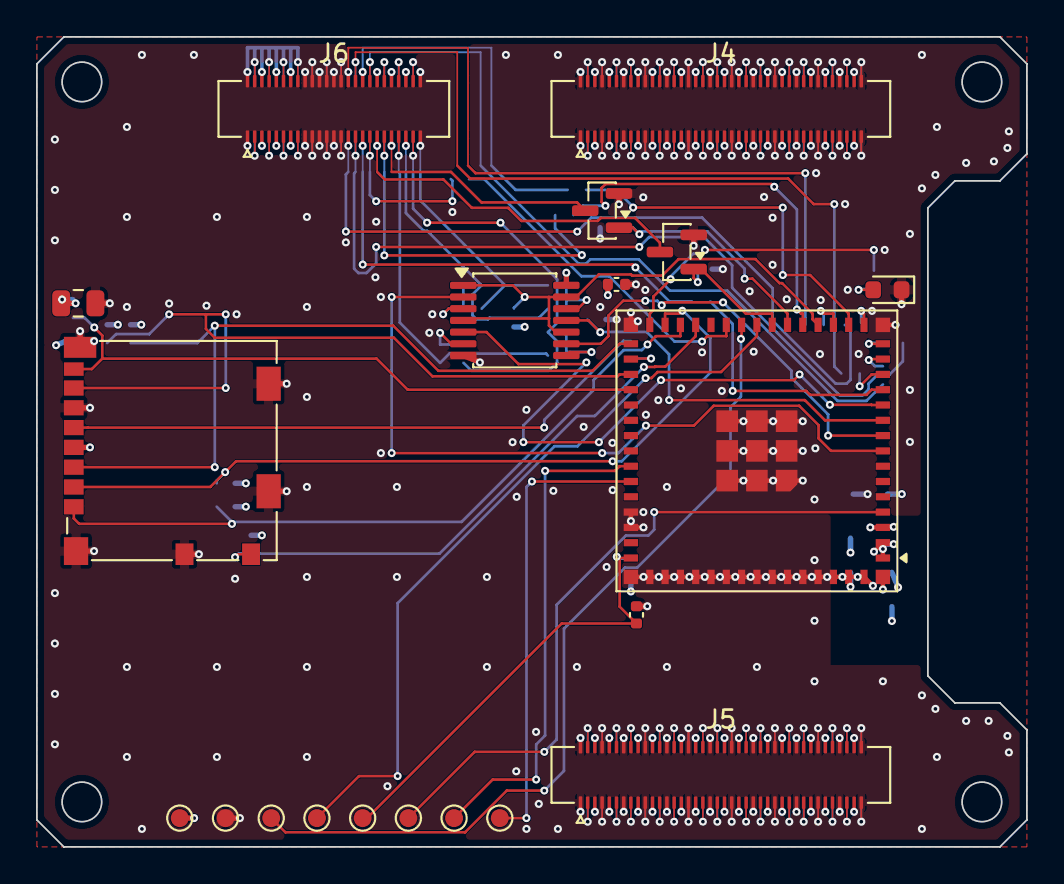
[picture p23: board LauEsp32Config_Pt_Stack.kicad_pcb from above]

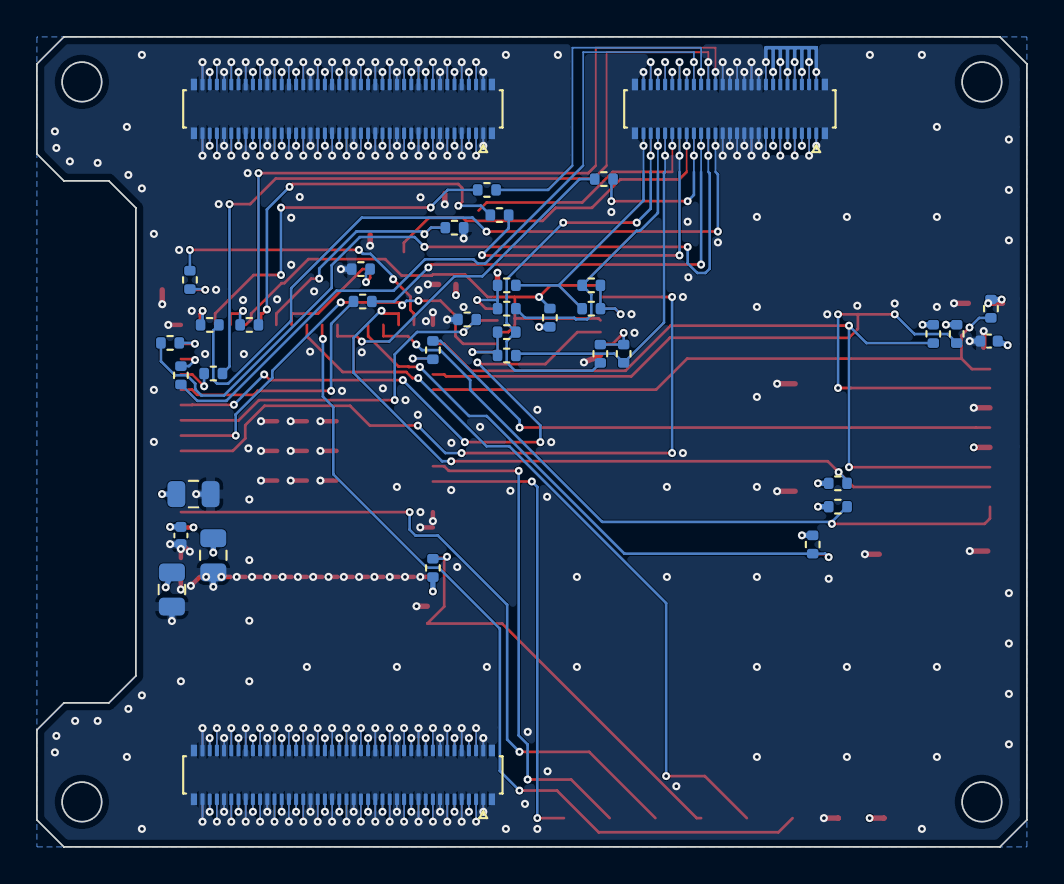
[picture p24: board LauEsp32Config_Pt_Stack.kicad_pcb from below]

Board: 4 copper layers, 55.0 x 45.0 mm, 58 parts (38 on the bottom side), 165 nets.

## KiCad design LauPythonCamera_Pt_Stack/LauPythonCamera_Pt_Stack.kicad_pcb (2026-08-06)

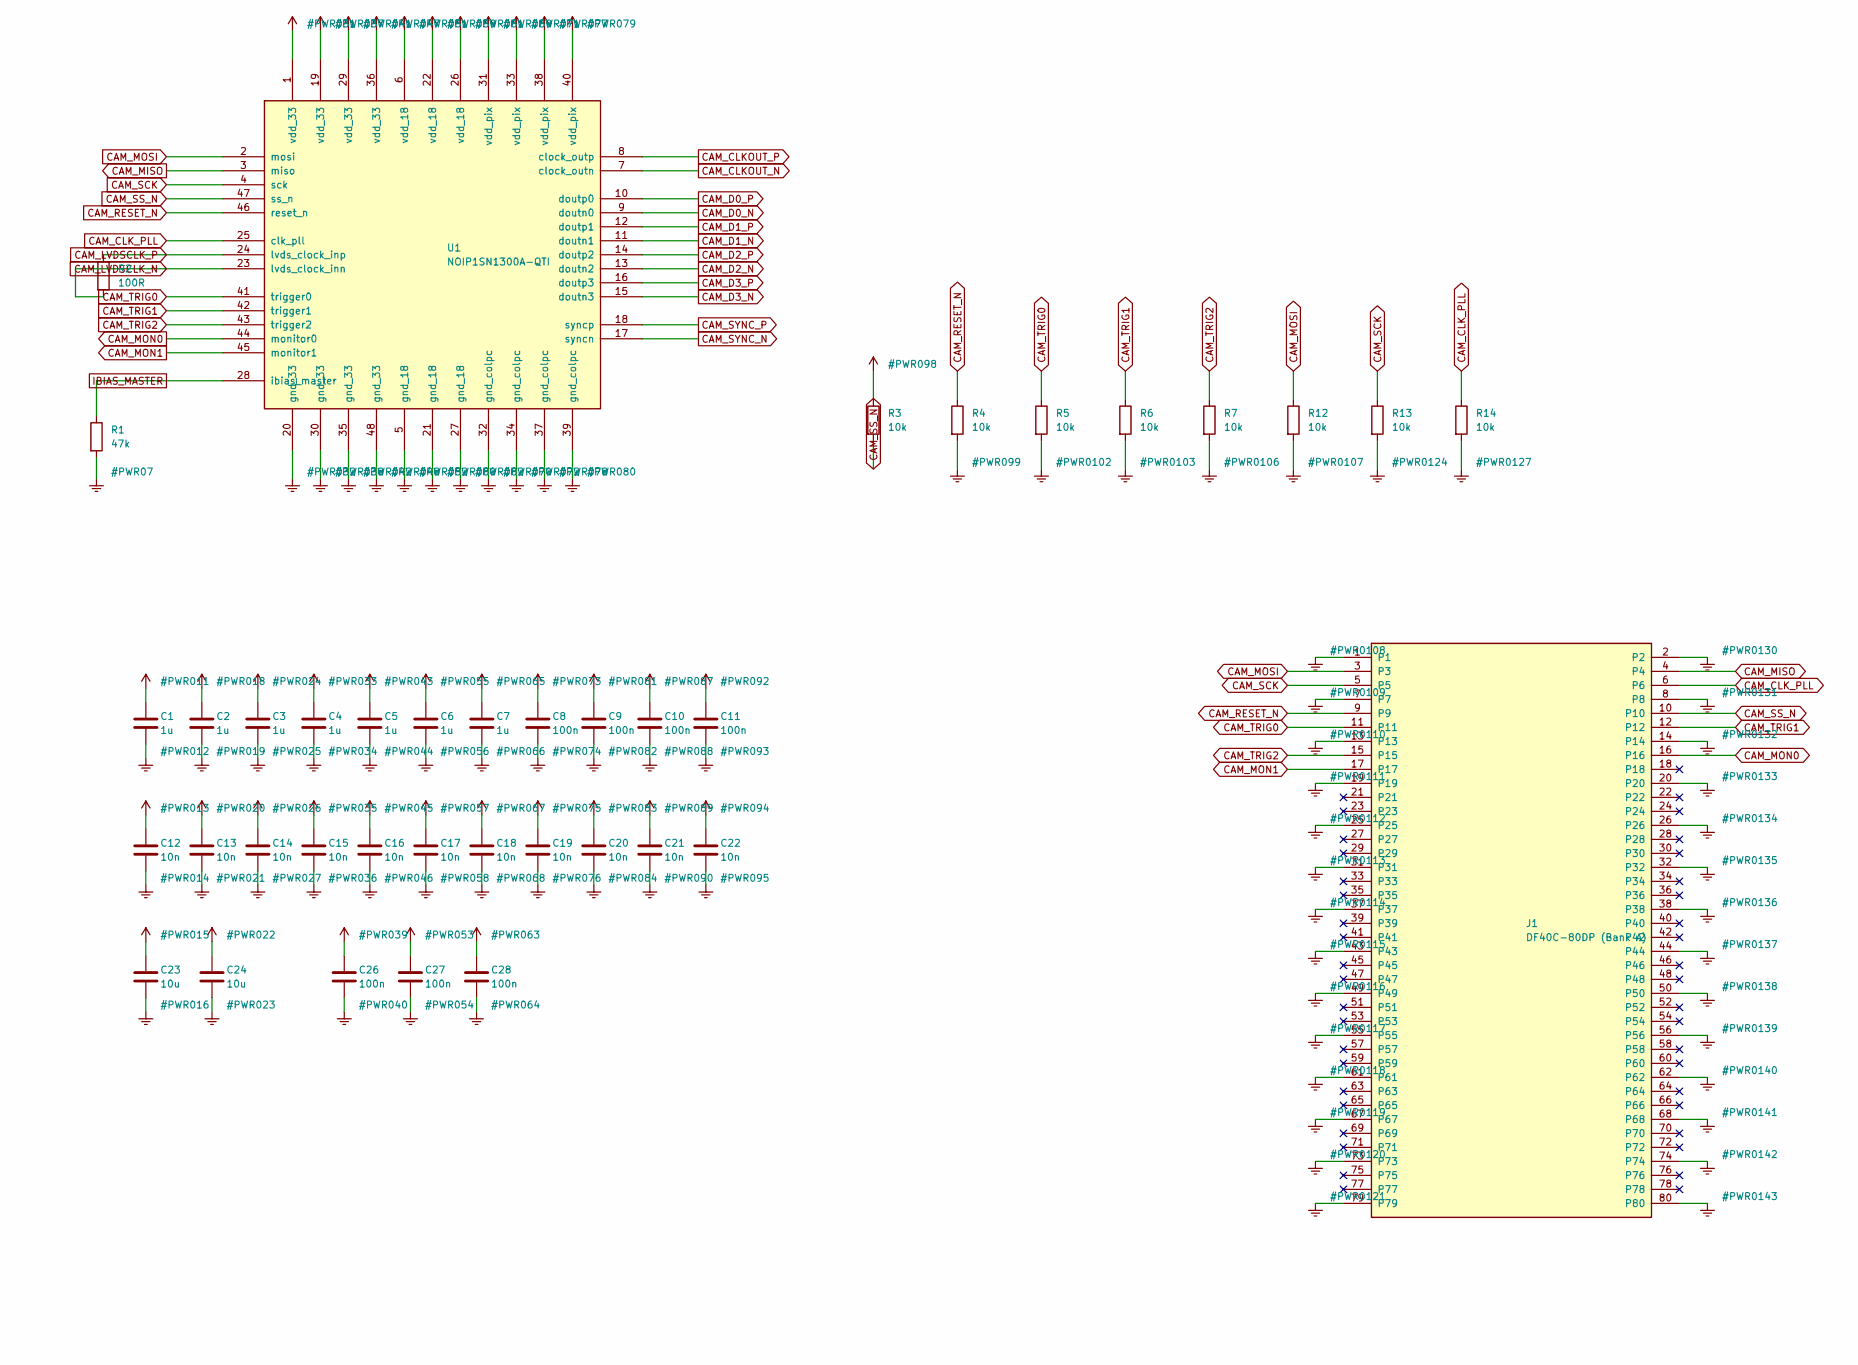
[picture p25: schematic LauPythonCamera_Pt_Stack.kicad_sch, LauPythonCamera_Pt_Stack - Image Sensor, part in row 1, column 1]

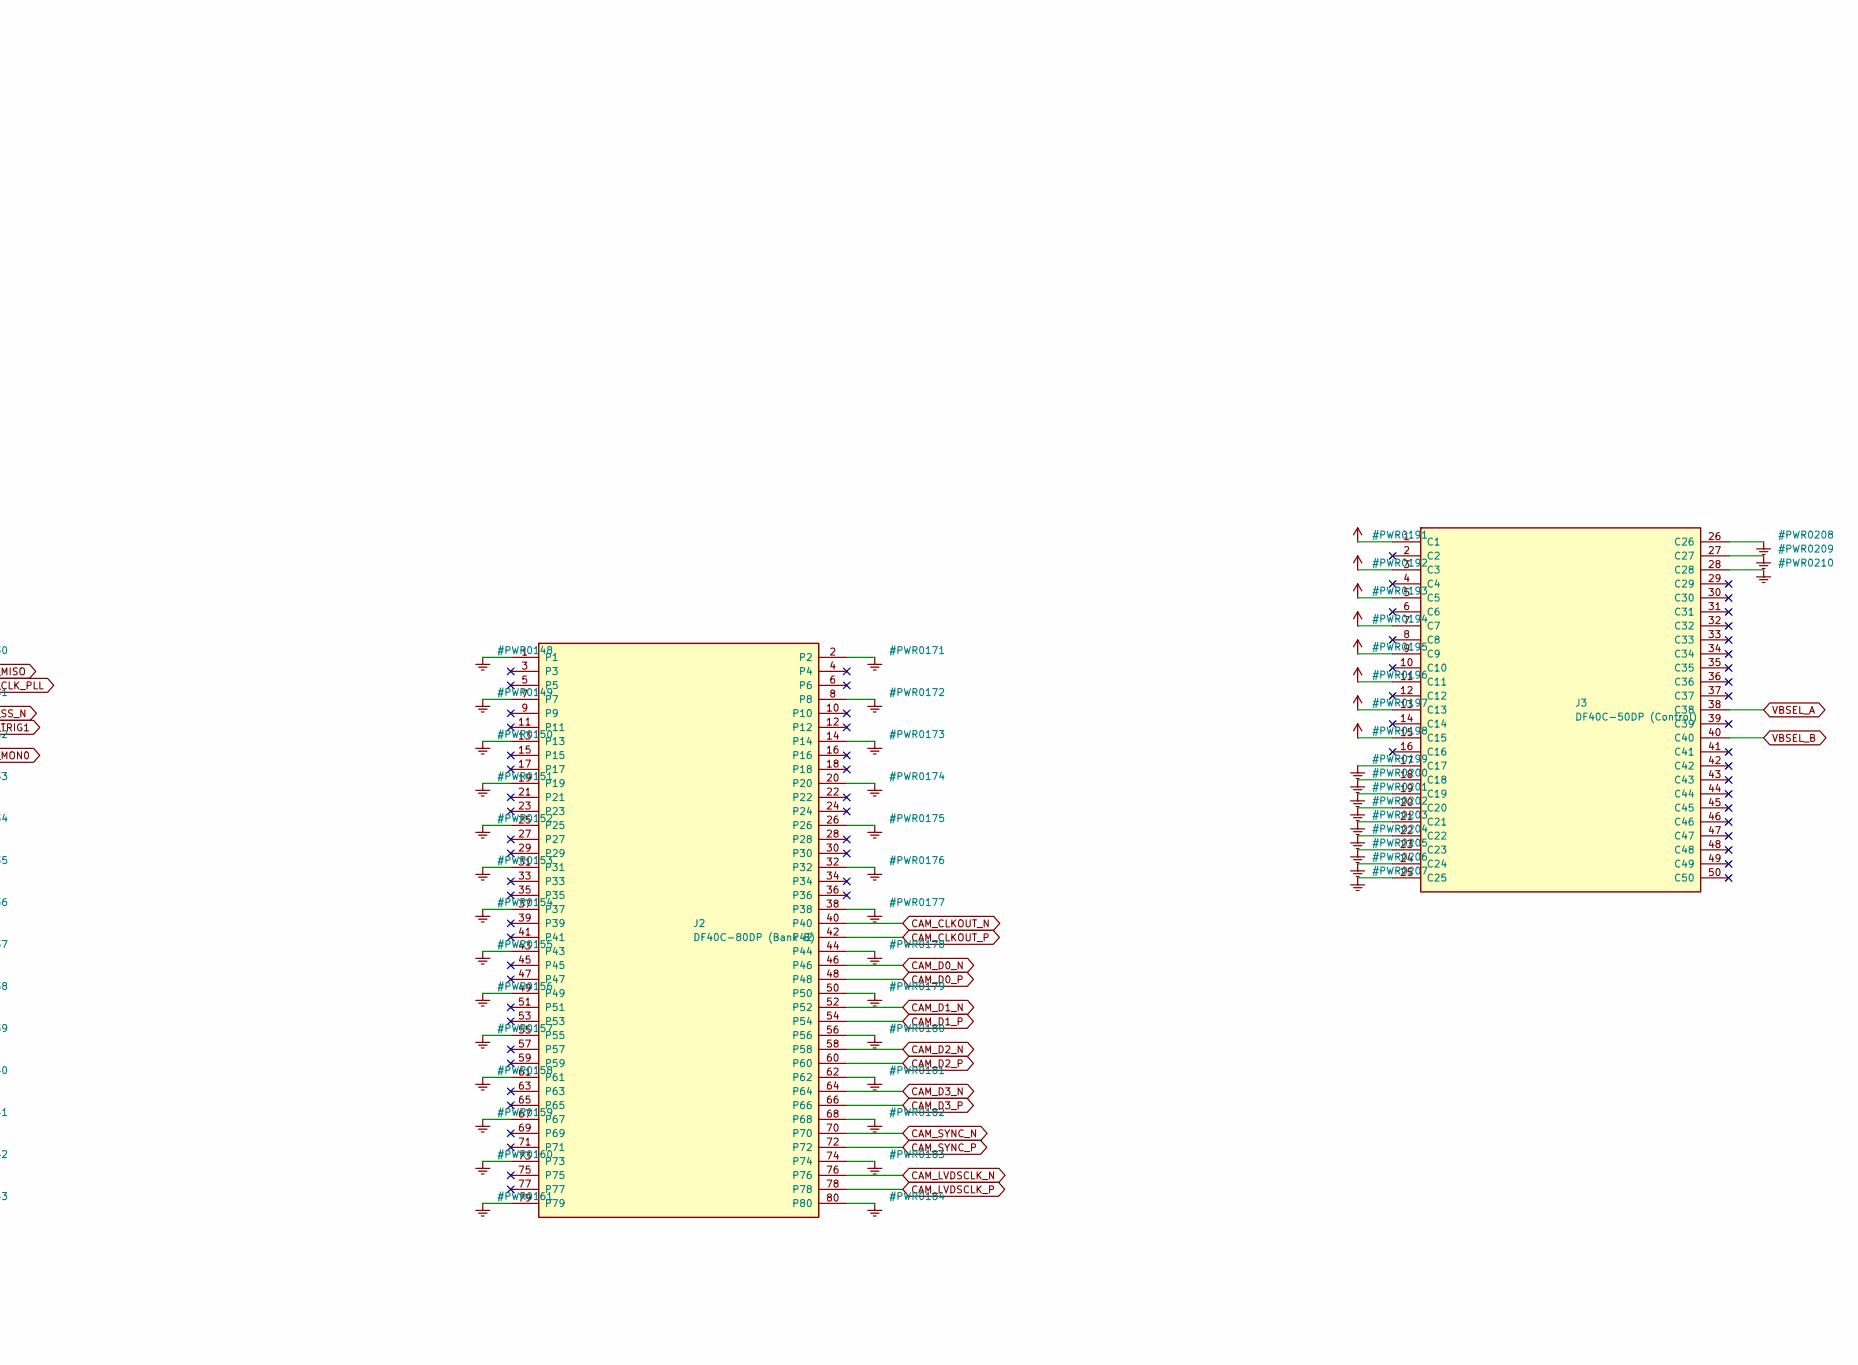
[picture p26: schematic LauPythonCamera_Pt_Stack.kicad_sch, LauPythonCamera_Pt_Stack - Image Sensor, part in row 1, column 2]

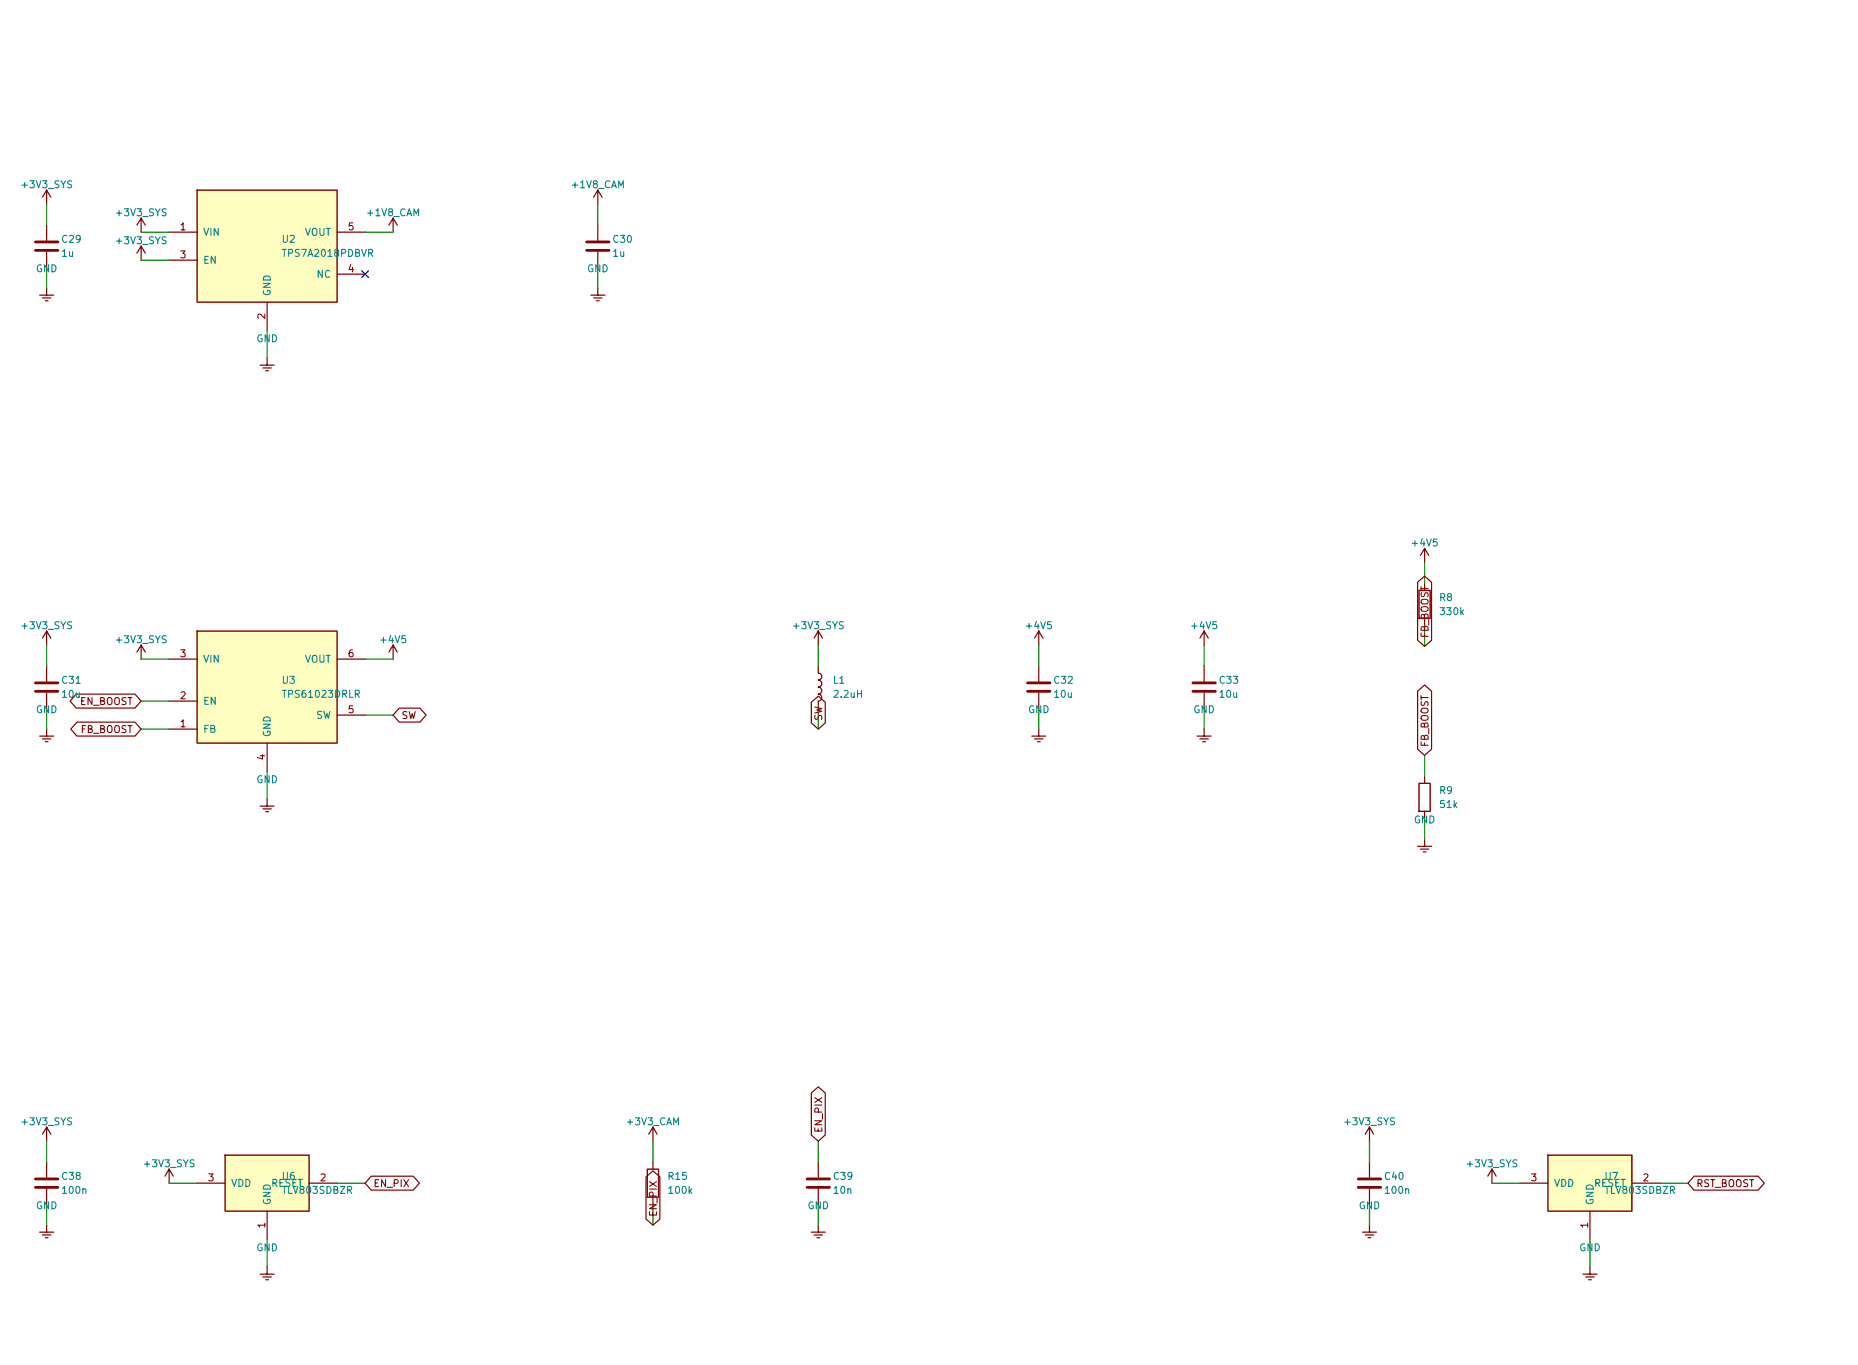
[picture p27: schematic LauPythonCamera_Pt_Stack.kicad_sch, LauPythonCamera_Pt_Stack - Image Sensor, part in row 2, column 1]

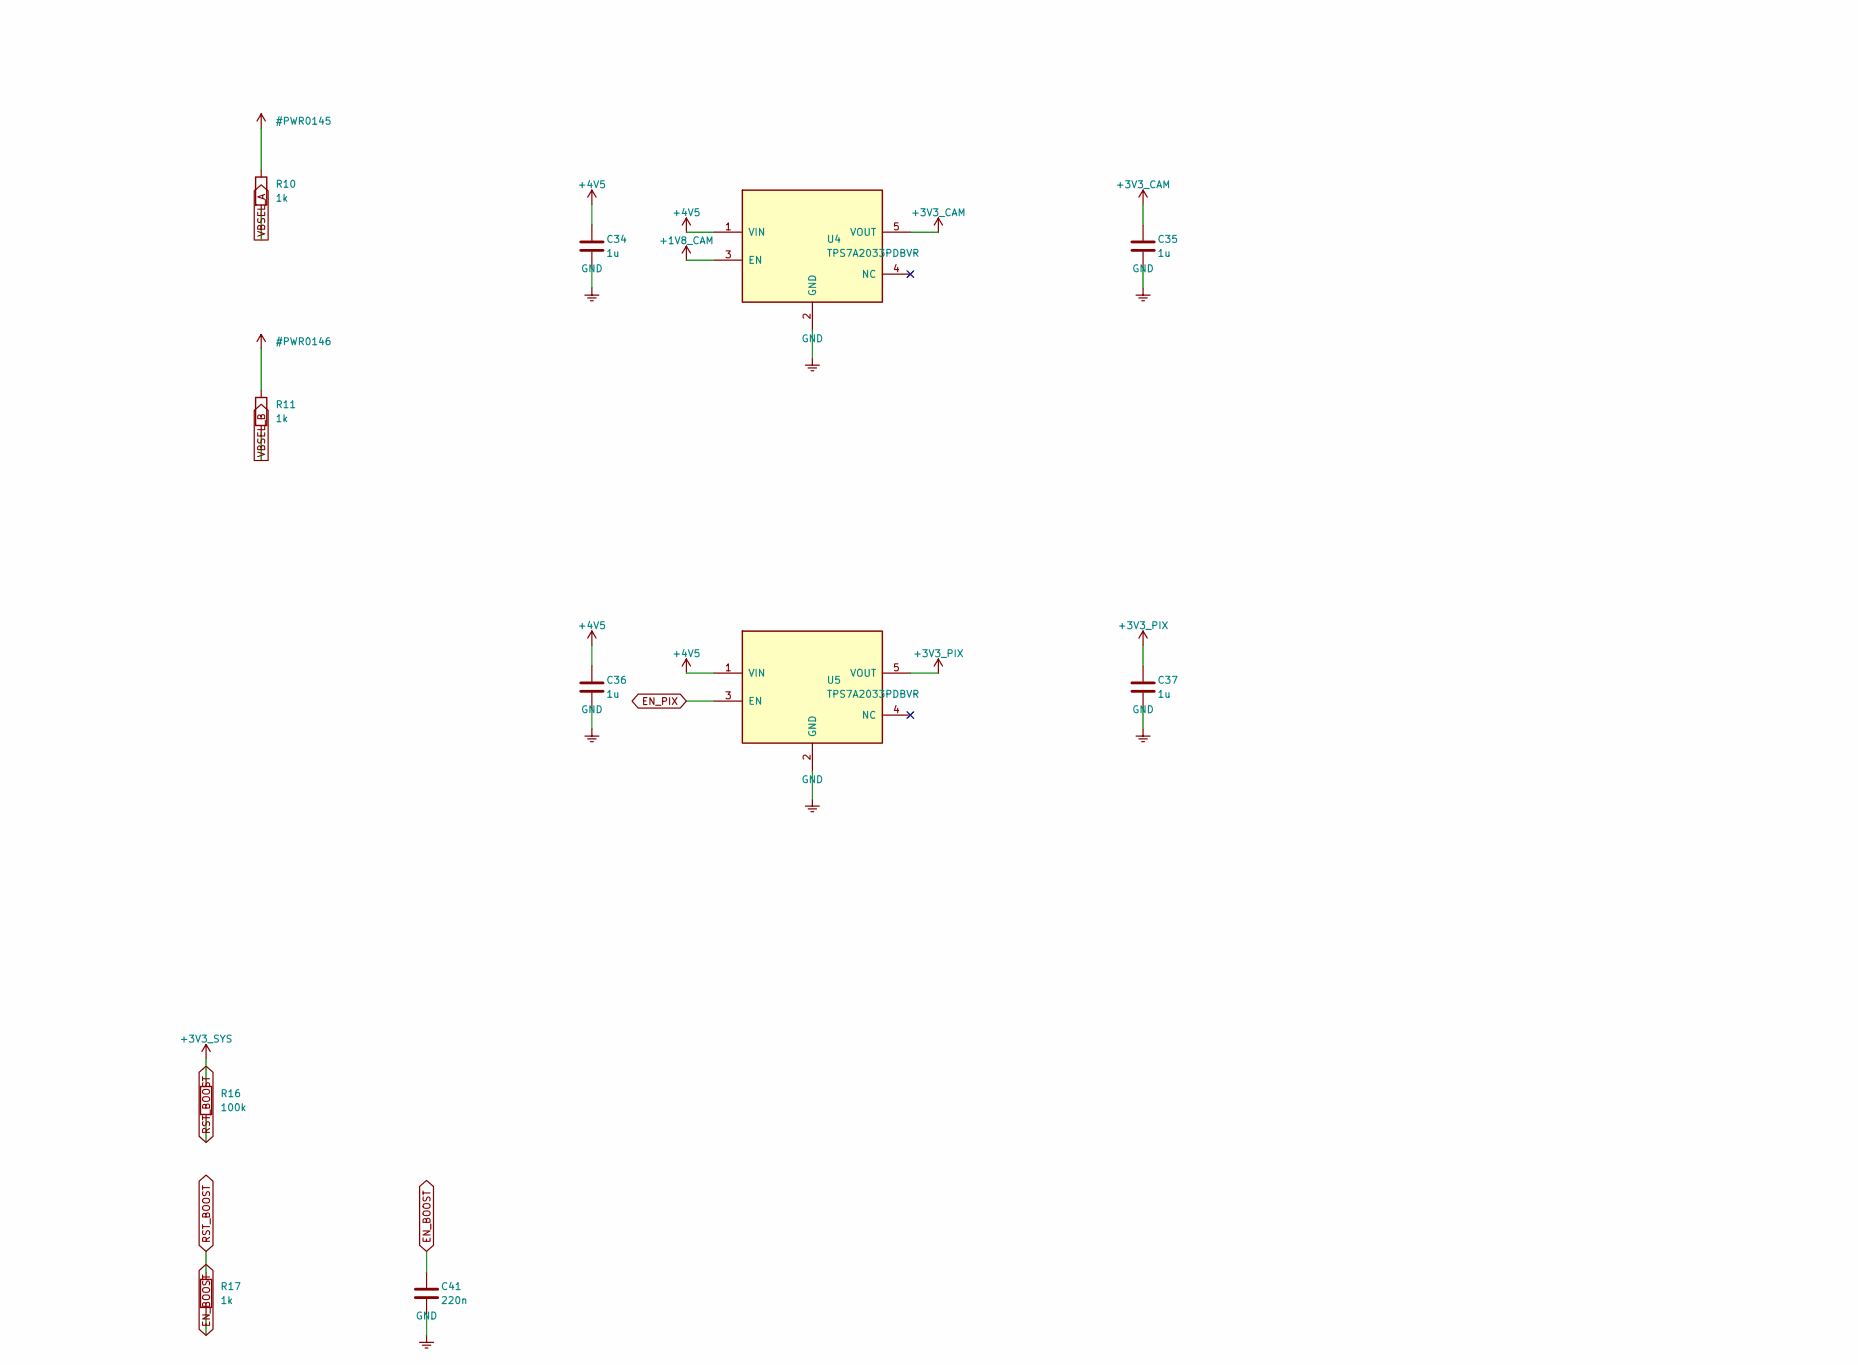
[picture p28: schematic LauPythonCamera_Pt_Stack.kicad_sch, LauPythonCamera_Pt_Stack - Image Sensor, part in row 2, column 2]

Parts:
C1, C2, C3, C4, C5, C6, C7: 1u; C_0402_1005Metric; MPN CL05A105KA5NQNC; LCSC C52923
C8, C9, C10, C11, C26, C27, C28, C38, C40: 100n; C_0402_1005Metric; MPN CL05B104KO5NNNC; LCSC C1525
C12, C13, C14, C15, C16, C17, C18, C19, C20, C21, C22, C39: 10n; C_0402_1005Metric; MPN CL05B103KB5NNNC; LCSC C15195
C23, C24, C31, C32, C33: 10u; C_0805_2012Metric; MPN CL21A106KAYNNNE; LCSC C15850
C29, C30, C34, C35, C36, C37: 1u; C_0603_1608Metric; MPN CL10A105KB8NNNC; LCSC C15849
C41: 220n; C_0402_1005Metric; MPN CL05B224KO5NNNC; LCSC C16772
J1: DF40C-80DP (Bank A); Hirose_DF40C-80DP-0.4V_2x40-1MP_P0.4mm; MPN DF40C-80DP-0.4V(51); LCSC C294544
J2: DF40C-80DP (Bank B); Hirose_DF40C-80DP-0.4V_2x40-1MP_P0.4mm; MPN DF40C-80DP-0.4V(51); LCSC C294544
J3: DF40C-50DP (Control); Hirose_DF40C-50DP-0.4V_2x25-1MP_P0.4mm; MPN DF40C-50DP-0.4V(51); LCSC C424645
L1: 2.2uH; L_Power_4x4mm_SMNR4020; MPN SMNR4020-2.2UH; LCSC C135262
R1: 47k; R_0402_1005Metric; MPN 0402WGF4702TCE; LCSC C25792
R2: 100R; R_0402_1005Metric; MPN 0402WGF1000TCE; LCSC C25076
R3, R4, R5, R6, R7, R12, R13, R14: 10k; R_0402_1005Metric; MPN 0402WGF1002TCE; LCSC C25744
R8: 330k; R_0402_1005Metric; MPN 0402WGF3303TCE; LCSC C25778
R9: 51k; R_0402_1005Metric; MPN 0402WGF5102TCE; LCSC C25794
R10, R11, R17: 1k; R_0402_1005Metric; MPN 0402WGF1001TCE; LCSC C11702
R15, R16: 100k; R_0402_1005Metric; MPN 0402WGF1003TCE; LCSC C25741
U1: NOIP1SN1300A-QTI; Andon_680-48-SM-G10-R14; MPN 680-48-SM-G10-R14-1
U2: TPS7A2018PDBVR; SOT-23-5; MPN TPS7A2018PDBVR; LCSC C963430
U3: TPS61023DRLR; SOT-563; MPN TPS61023DRLR; LCSC C919459
U4, U5: TPS7A2033PDBVR; SOT-23-5; MPN TPS7A2033PDBVR; LCSC C2862740
U6, U7: TLV803SDBZR; SOT-23; MPN TLV803SDBZR; LCSC C132016

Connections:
+1V8_CAM: C5.1, C6.1, C7.1, C16.1, C17.1, C18.1, C24.1, C27.1, C30.1, U1.6 (vdd_18), U1.22 (vdd_18), U1.26 (vdd_18), U2.5 (VOUT), U4.3 (EN); also elsewhere on the board
+3V3_CAM: C1.1, C2.1, C3.1, C4.1, C12.1, C13.1, C14.1, C15.1, C23.1, C26.1, C35.1, R3.1, R15.1, U1.1 (vdd_33), U1.19 (vdd_33), U1.29 (vdd_33), U1.36 (vdd_33), U4.5 (VOUT); also elsewhere on the board
+3V3_PIX: C8.1, C9.1, C10.1, C11.1, C19.1, C20.1, C21.1, C22.1, C28.1, C37.1, U1.31 (vdd_pix), U1.33 (vdd_pix), U1.38 (vdd_pix), U1.40 (vdd_pix), U5.5 (VOUT); also elsewhere on the board
+3V3_SYS: C29.1, C31.1, C38.1, C40.1, J3.1 (C1), J3.3 (C3), J3.5 (C5), J3.7 (C7), J3.9 (C9), J3.11 (C11), J3.13 (C13), J3.15 (C15), L1.1, R10.1, R11.1, R16.1, U2.1 (VIN), U2.3 (EN), U3.3 (VIN), U6.3 (VDD), U7.3 (VDD); also elsewhere on the board
+4V5: C32.1, C33.1, C34.1, C36.1, R8.1, U3.6 (VOUT), U4.1 (VIN), U5.1 (VIN); also elsewhere on the board
CAM_CLKOUT_N: J2.40, U1.7 (clock_outn)
CAM_CLKOUT_P: J2.42, U1.8 (clock_outp)
CAM_CLK_PLL: J1.6, R14.1, U1.25 (clk_pll)
CAM_D0_N: J2.46, U1.9 (doutn0)
CAM_D0_P: J2.48, U1.10 (doutp0)
CAM_D1_N: J2.52, U1.11 (doutn1)
CAM_D1_P: J2.54, U1.12 (doutp1)
CAM_D2_N: J2.58, U1.13 (doutn2)
CAM_D2_P: J2.60, U1.14 (doutp2)
CAM_D3_N: J2.64, U1.15 (doutn3)
CAM_D3_P: J2.66, U1.16 (doutp3)
CAM_LVDSCLK_N: J2.76, R2.2, U1.23 (lvds_clock_inn)
CAM_LVDSCLK_P: J2.78, R2.1, U1.24 (lvds_clock_inp)
CAM_MISO: J1.4, U1.3 (miso)
CAM_MON0: J1.16, U1.44 (monitor0)
CAM_MON1: J1.17, U1.45 (monitor1)
CAM_MOSI: J1.3, R12.1, U1.2 (mosi)
CAM_RESET_N: J1.9, R4.1, U1.46 (reset_n)
CAM_SCK: J1.5, R13.1, U1.4 (sck)
CAM_SS_N: J1.10, R3.2, U1.47 (ss_n)
CAM_SYNC_N: J2.70, U1.17 (syncn)
CAM_SYNC_P: J2.72, U1.18 (syncp)
CAM_TRIG0: J1.11, R5.1, U1.41 (trigger0)
CAM_TRIG1: J1.12, R6.1, U1.42 (trigger1)
CAM_TRIG2: J1.15, R7.1, U1.43 (trigger2)
EN_BOOST: C41.1, R17.2, U3.2 (EN)
EN_PIX: C39.1, R15.2, U5.3 (EN), U6.2 (RESET)
FB_BOOST: R8.2, R9.1, U3.1 (FB)
GND: C1.2, C2.2, C3.2, C4.2, C5.2, C6.2, C7.2, C8.2, C9.2, C10.2, C11.2, C12.2, C13.2, C14.2, C15.2, C16.2, C17.2, C18.2, C19.2, C20.2, C21.2, C22.2, C23.2, C24.2, C26.2, C27.2, C28.2, C29.2, C30.2, C31.2, C32.2, C33.2, C34.2, C35.2, C36.2, C37.2, C38.2, C39.2, C40.2, C41.2, J1.1, J1.2, J1.7, J1.8, J1.13, J1.14, J1.19, J1.20, J1.25, J1.26, J1.31, J1.32, J1.37, J1.38, J1.43, J1.44, J1.49, J1.50, J1.55, J1.56, J1.61, J1.62, J1.67, J1.68, J1.73, J1.74, J1.79, J1.80, J2.1, J2.2, J2.7, J2.8, J2.13, J2.14, J2.19, J2.20, J2.25, J2.26, J2.31, J2.32, J2.37, J2.38, J2.43, J2.44, J2.49, J2.50, J2.55, J2.56, J2.61, J2.62, J2.67, J2.68, J2.73, J2.74, J2.79, J2.80, J3.17 (C17), J3.18 (C18), J3.19 (C19), J3.20 (C20), J3.21 (C21), J3.22 (C22), J3.23 (C23), J3.24 (C24), J3.25 (C25), J3.26 (C26), J3.27 (C27), J3.28 (C28), R1.2, R4.2, R5.2, R6.2, R7.2, R9.2, R12.2, R13.2, R14.2, U1.5 (gnd_18), U1.20 (gnd_33), U1.21 (gnd_18), U1.27 (gnd_18), U1.30 (gnd_33), U1.32 (gnd_colpc), U1.34 (gnd_colpc), U1.35 (gnd_33), U1.37 (gnd_colpc), U1.39 (gnd_colpc), U1.48 (gnd_33), U2.2 (GND), U3.4 (GND), U4.2 (GND), U5.2 (GND), U6.1 (GND), U7.1 (GND); also elsewhere on the board
IBIAS_MASTER: R1.1, U1.28 (ibias_master)
RST_BOOST: R16.2, R17.1, U7.2 (RESET)
SW: L1.2, U3.5 (SW)
VBSEL_A: J3.38 (C38), R10.2
VBSEL_B: J3.40 (C40), R11.2

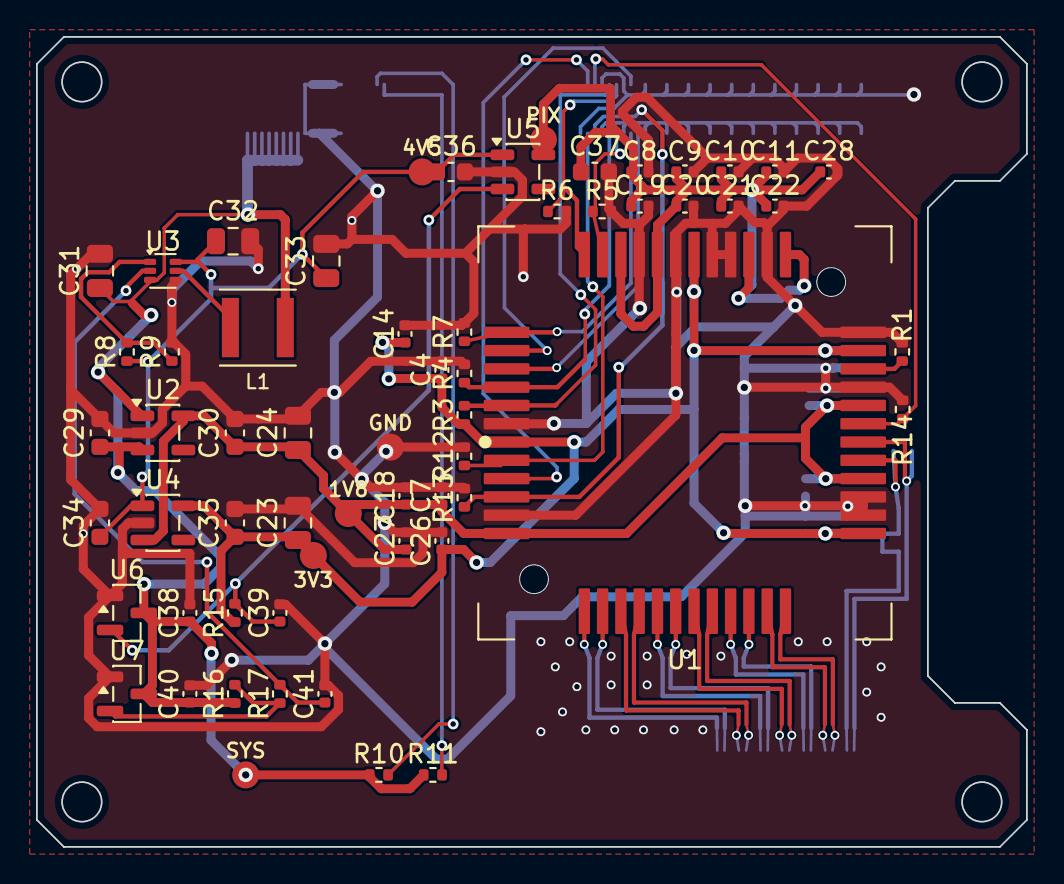
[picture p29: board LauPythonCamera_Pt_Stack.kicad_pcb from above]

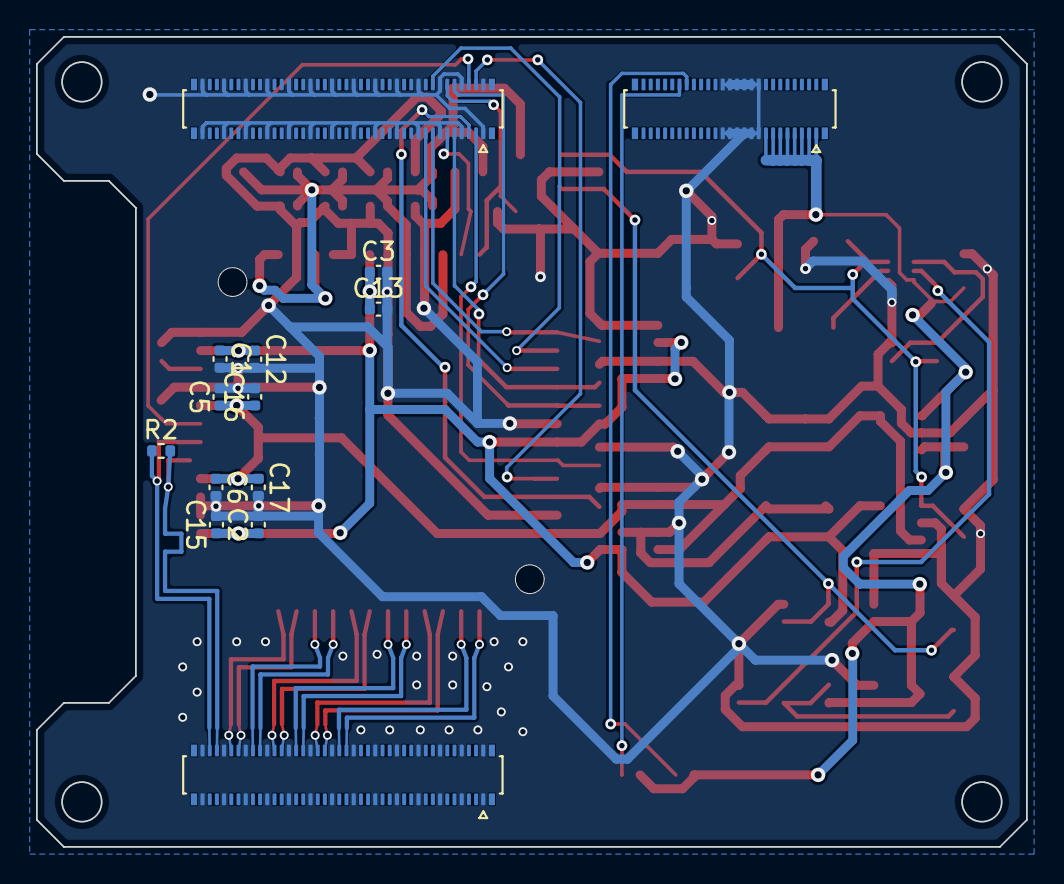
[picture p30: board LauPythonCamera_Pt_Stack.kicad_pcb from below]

Board: 4 copper layers, 55.0 x 45.0 mm, 74 parts (14 on the bottom side), 39 nets.

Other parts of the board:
TP1: SYS; TestPoint_Pad_D1.5mm
TP2: 4V5; TestPoint_Pad_D1.5mm
TP3: 1V8; TestPoint_Pad_D1.5mm
TP4: 3V3; TestPoint_Pad_D1.5mm
TP5: PIX; TestPoint_Pad_D1.5mm
TP6: GND; TestPoint_Pad_D1.5mm

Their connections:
+1V8_CAM: TP3.1; also elsewhere on the board
+3V3_CAM: TP4.1; also elsewhere on the board
+3V3_PIX: TP5.1; also elsewhere on the board
+3V3_SYS: TP1.1; also elsewhere on the board
+4V5: TP2.1; also elsewhere on the board
GND: TP6.1; also elsewhere on the board

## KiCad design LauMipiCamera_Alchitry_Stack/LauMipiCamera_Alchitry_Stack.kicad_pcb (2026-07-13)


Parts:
C1: 100n; C_0805_2012Metric
C2: 10u; C_0805_2012Metric
J1: DF40C-50DP; Hirose_DF40C-50DP-0.4V_2x25-1MP_P0.4mm
J2, J3: DF40C-80DP; Hirose_DF40C-80DP-0.4V_2x40-1MP_P0.4mm
J_CAM1: MIPI_CSI_22pin; Hirose_FH12-22S-0.5SH_1x22-1MP_P0.50mm_Horizontal
R_LP0N1, R_LP0P1, R_LP1N1, R_LP1P1, R_LP2N1, R_LP2P1: 100; R_0402_1005Metric
R_SCL1: 4k7; R_0402_1005Metric
R_SDA1: 4k7; R_0402_1005Metric
R_T0, R_T1, R_T2: 150; R_0402_1005Metric
R_TRIG1: 33; R_0402_1005Metric
SW1: SW_DIP_x4; SW_DIP_SPSTx04_Slide_6.7x11.72mm_W8.61mm_P2.54mm_LowProfile

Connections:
+3V3: C1.1, C2.1, J1.1, J1.3, J1.5, J_CAM1.22, R_SCL1.1, R_SDA1.1
CAM_CK_N: J3.45, J_CAM1.8, R_LP0N1.1, R_T0.2
CAM_CK_P: J3.47, J_CAM1.9, R_LP0P1.1, R_T0.1
CAM_D0_N: J3.40, J_CAM1.2, R_LP1N1.1, R_T1.2
CAM_D0_P: J3.42, J_CAM1.3, R_LP1P1.1, R_T1.1
CAM_D1_N: J3.46, J_CAM1.5, R_LP2N1.1, R_T2.2
CAM_D1_P: J3.48, J_CAM1.6, R_LP2P1.1, R_T2.1
CAM_SCL: J3.21, J_CAM1.20, R_SCL1.2
CAM_SDA: J3.23, J_CAM1.21, R_SDA1.2
CAM_STROBE: J3.18, J_CAM1.18
CAM_TRIG: J3.17, R_TRIG1.1
CAM_TRIG_R: J_CAM1.17, R_TRIG1.2
GND: C1.2, C2.2, J2.1, J2.2, J2.7, J2.8, J2.13, J2.14, J2.19, J2.20, J2.25, J2.26, J2.31, J2.32, J2.37, J2.38, J2.43, J2.44, J2.49, J2.50, J2.55, J2.56, J2.61, J2.62, J2.67, J2.68, J2.73, J2.74, J2.79, J2.80, J3.1, J3.2, J3.7, J3.8, J3.13, J3.14, J3.19, J3.20, J3.25, J3.26, J3.31, J3.32, J3.37, J3.38, J3.43, J3.44, J3.49, J3.50, J3.55, J3.56, J3.61, J3.62, J3.67, J3.68, J3.73, J3.74, J3.79, J3.80, J_CAM1.1, J_CAM1.4, J_CAM1.7, J_CAM1.10, J_CAM1.13, J_CAM1.16, J_CAM1.19, SW1.5, SW1.6, SW1.7, SW1.8
LP_CK_N: J3.35, R_LP0N1.2
LP_CK_P: J3.33, R_LP0P1.2
LP_D0_N: J3.36, R_LP1N1.2
LP_D0_P: J3.34, R_LP1P1.2
LP_D1_N: J3.53, R_LP2N1.2
LP_D1_P: J3.51, R_LP2P1.2
SW_BLUE: J3.28, SW1.2
SW_GREEN: J3.29, SW1.3
SW_HVSV: J3.27, SW1.1
SW_RED: J3.30, SW1.4

Board: 4 copper layers, 19 parts (3 on the bottom side), 23 nets, no tracks yet.

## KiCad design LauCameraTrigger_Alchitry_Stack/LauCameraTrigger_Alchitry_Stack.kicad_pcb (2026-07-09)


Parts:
C1, C2: 0.1uF; C_0805_2012Metric
J1: DF40C-50DP (Site A / +3V3 only); Hirose_DF40C-50DP-0.4V_2x25-1MP_P0.4mm
J2: DF40C-80DP (Bank A / Site B / MECH-ONLY); Hirose_DF40C-80DP-0.4V_2x40-1MP_P0.4mm
J3: DF40C-80DP (Bank B / Site C); Hirose_DF40C-80DP-0.4V_2x40-1MP_P0.4mm
MASTER1: SM07B-SRSS-TB; JST_SH_SM07B-SRSS-TB_1x07-1MP_P1.00mm_Horizontal
R1, R7: 1k; R_1206_3216Metric
R2, R3, R4, R5, R6, R8: 10k; R_1206_3216Metric; not fitted
SLAVE1, SLAVE2: SM07B-SRSS-TB; JST_SH_SM07B-SRSS-TB_1x07-1MP_P1.00mm_Horizontal
SW1: DIP4 RGB/HV select; SW_DIP_SPSTx04_Slide_6.7x11.72mm_W8.61mm_P2.54mm_LowProfile

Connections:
+3V3: C1.1, C2.1, J1.1 (Pin_1_1), R1.2, R3.2, R5.2, R7.2, SW1.8
CAM_MODE: J3.30, MASTER1.3, R7.1, R8.1
CAM_PATTERN: J3.29, MASTER1.4, R5.1, R6.1, SLAVE1.4, SLAVE2.4
CAM_READY: J3.27, MASTER1.5, R1.1, R2.1
CAM_TRIG: J3.28, MASTER1.2, R3.1, R4.1, SLAVE1.2, SLAVE2.2
GND: C1.2, C2.2, J2.1 (Pin_1_1), J3.1, J3.2, J3.7, J3.8, J3.13, J3.14, J3.19, J3.20, J3.25, J3.26, J3.31, J3.32, MASTER1.1, R2.2, R4.2, R6.2, R8.2, SLAVE1.1, SLAVE2.1, SW1.5, SW1.6, SW1.7
SW_BLUE: J3.34, SW1.2
SW_GREEN: J3.35, SW1.3
SW_HVSV: J3.33, SW1.1
SW_RED: J3.36, SW1.4



Board: 2 copper layers, 55.0 x 45.0 mm, 17 parts (3 on the bottom side), 10 nets.

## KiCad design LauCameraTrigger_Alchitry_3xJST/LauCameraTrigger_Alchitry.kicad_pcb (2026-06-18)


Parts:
J1: CAM A; PinHeader_1x08_P2.54mm_Vertical
J2: CAM B; PinHeader_1x08_P2.54mm_Vertical
J3: CAM MASTER; JST_SH_SM07B-SRSS-TB_1x07-1MP_P1.00mm_Horizontal; MPN SM07B-SRSS-TB(LF)(SN)
J4: CRTL; PinHeader_2x03_P2.54mm_Vertical
J5: HvsV; PinHeader_1x03_P2.54mm_Vertical
J6: BLU; PinHeader_1x03_P2.54mm_Vertical
J7: GRN; PinHeader_1x03_P2.54mm_Vertical
J8: RED; PinHeader_1x03_P2.54mm_Vertical
J9: CAM SLV1; JST_SH_SM07B-SRSS-TB_1x07-1MP_P1.00mm_Horizontal; MPN SM07B-SRSS-TB(LF)(SN)
J10: CAM SLV2; JST_SH_SM07B-SRSS-TB_1x07-1MP_P1.00mm_Horizontal; MPN SM07B-SRSS-TB(LF)(SN)
R2: A1o; R_Axial_DIN0207_L6.3mm_D2.5mm_P10.16mm_Horizontal; not fitted
R3: A2o; R_Axial_DIN0207_L6.3mm_D2.5mm_P10.16mm_Horizontal; not fitted
R5: A1h; R_Axial_DIN0207_L6.3mm_D2.5mm_P10.16mm_Horizontal; not fitted
R6: A2h; R_Axial_DIN0207_L6.3mm_D2.5mm_P10.16mm_Horizontal; not fitted

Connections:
A28_1: J1.7, J3.3, R3.1, R6.2
A29_1: J1.6, J3.4, J9.4, J10.4
A31_1: J1.5, J3.2, J9.2, J10.2, R2.1, R5.2
A32_1: J1.4, J3.5
GND: J1.1, J2.1, J3.1, J4.5, J4.6, J5.3, J6.3, J7.3, J8.3, J9.1, J10.1, R2.2, R3.2
unnamed: J1.2, J5.2
unnamed: J1.3, J7.2
unnamed: J2.2, J6.2
unnamed: J2.3, J8.2
unnamed: J4.1, J5.1, J6.1, J7.1, J8.1, R5.1, R6.1

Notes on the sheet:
CAMERA 1: "sync_in_1". --> A28_1; (input of FPGA) LINE_2_2 DB9-9 blue + white "sync_in_2" --> A29_1; (input of FPGA) LINE_2_4 DB9-4 orange + white "sync_out_1" --> A31_1; (output of FPGA) LINE_2_1 DB9-5 blue "sync_out_2". --> A32_1; (output of FPGA, trigger) LINE_2_3 DB9-8 orange CAMERA 2: "sync_in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


Board: 2 copper layers, 50.8 x 39.1 mm, 14 parts (0 on the bottom side), 10 nets.

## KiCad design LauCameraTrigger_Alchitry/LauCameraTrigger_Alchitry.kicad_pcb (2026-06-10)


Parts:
J1: CAM A; PinHeader_1x08_P2.54mm_Vertical
J2: CAM B; PinHeader_1x08_P2.54mm_Vertical
J3: DE9_Plug_MountingHoles; DSUB-9_Pins_Horizontal_P2.77x2.84mm_EdgePinOffset4.94mm_Hou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
J4: CRTL; PinHeader_2x03_P2.54mm_Vertical
J5: HvsV; PinHeader_1x03_P2.54mm_Vertical
J6: BLU; PinHeader_1x03_P2.54mm_Vertical
J7: GRN; PinHeader_1x03_P2.54mm_Vertical
J8: RED; PinHeader_1x03_P2.54mm_Vertical
R1: B2o; R_Axial_DIN0207_L6.3mm_D2.5mm_P10.16mm_Horizontal
R2: A1o; R_Axial_DIN0207_L6.3mm_D2.5mm_P10.16mm_Horizontal
R3: A2o; R_Axial_DIN0207_L6.3mm_D2.5mm_P10.16mm_Horizontal
R4: B1o; R_Axial_DIN0207_L6.3mm_D2.5mm_P10.16mm_Horizontal
R5: A1h; R_Axial_DIN0207_L6.3mm_D2.5mm_P10.16mm_Horizontal
R6: A2h; R_Axial_DIN0207_L6.3mm_D2.5mm_P10.16mm_Horizontal
R7: B1h; R_Axial_DIN0207_L6.3mm_D2.5mm_P10.16mm_Horizontal
R8: B2h; R_Axial_DIN0207_L6.3mm_D2.5mm_P10.16mm_Horizontal

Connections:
A28_1: J1.7, J3.9, R3.1, R6.2
A28_2: J2.7, J3.2, R1.1, R8.2
A29_1: J1.6, J3.4
A29_2: J2.6, J3.3
A31_1: J1.5, J3.5, R2.1, R5.2
A31_2: J2.5, J3.6, R4.1, R7.2
A32_1: J1.4, J3.8
A32_2: J2.4, J3.7
GND: J1.1, J2.1, J3.0 (PAD), J3.1, J4.5, J4.6, J5.3, J6.3, J7.3, J8.3, R1.2, R2.2, R3.2, R4.2
unnamed: J1.2, J5.2
unnamed: J1.3, J7.2
unnamed: J2.2, J6.2
unnamed: J2.3, J8.2
unnamed: J4.1, J5.1, J6.1, J7.1, J8.1, R5.1, R6.1, R7.1, R8.1

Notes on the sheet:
CAMERA 1: "sync_in_1". --> A28_1; (input of FPGA) LINE_2_2 DB9-9 blue + white "sync_in_2" --> A29_1; (input of FPGA) LINE_2_4 DB9-4 orange + white "sync_out_1" --> A31_1; (output of FPGA) LINE_2_1 DB9-5 blue "sync_out_2". --> A32_1; (output of FPGA, trigger) LINE_2_3 DB9-8 orange CAMERA 2: "sync_in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


Board: 2 copper layers, 50.8 x 39.1 mm, 16 parts (0 on the bottom side), 14 nets.

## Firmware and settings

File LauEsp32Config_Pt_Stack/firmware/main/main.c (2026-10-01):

/*********************************************************************************
 *                                                                               *
 * Copyright (c) 2026, Dr. Daniel L. Lau                                         *
 * All rights reserved.                                                          *
 *                                                                               *
 * Redistribution and use in source and binary forms, with or without            *
 * modification, is strictly forbidden.                                          *
 *                                                                               *
 * THIS SOFTWARE IS PROVIDED BY DR. DANIEL L. LAU ''AS IS'' AND ANY              *
 * EXPRESS OR IMPLIED WARRANTIES, INCLUDING, BUT NOT LIMITED TO, THE IMPLIED     *
 * WARRANTIES OF MERCHANTABILITY AND FITNESS FOR A PARTICULAR PURPOSE ARE        *
 * DISCLAIMED. IN NO EVENT SHALL DR. DANIEL L. LAU BE LIABLE FOR ANY             *
 * DIRECT, INDIRECT, INCIDENTAL, SPECIAL, EXEMPLARY, OR CONSEQUENTIAL DAMAGES    *
 * (INCLUDING, BUT NOT LIMITED TO, PROCUREMENT OF SUBSTITUTE GOODS OR SERVICES;  *
 * LOSS OF USE, DATA, OR PROFITS; OR BUSINESS INTERRUPTION) HOWEVER CAUSED AND   *
 * ON ANY THEORY OF LIABILITY, WHETHER IN CONTRACT, STRICT LIABILITY, OR TORT    *
 * (INCLUDING NEGLIGENCE OR OTHERWISE) ARISING IN ANY WAY OUT OF THE USE OF THIS *
 * SOFTWARE, EVEN IF ADVISED OF THE POSSIBILITY OF SUCH DAMAGE.                  *
 *                                                                               *
 *********************************************************************************/

#include <stdio.h>
#include <string.h>

#include "driver/gpio.h"
#include "esp_log.h"
#include "esp_ota_ops.h"
#include "esp_random.h"
#include "freertos/FreeRTOS.h"
#include "freertos/task.h"
#include "nvs.h"
#include "nvs_flash.h"
#include "sdkconfig.h"

#include "laufpga.h"
#include "laulibrary.h"
#include "launetwork.h"
#include "laupins.h"
#include "lauserver.h"

// LAU ESP32 CARD: MICROSD BITSTREAM LIBRARY BEHIND AN MCP SERVER (SD_BITSTREAM_LIBRARY.MD)

static const char *TAG = "LAUMain";

/***************************************************************************************************/
/***************************************************************************************************/
/***************************************************************************************************/
static void readBearerToken(char *token, size_t capacity)
{
    // USE THE MENUCONFIG TOKEN IF ONE WAS SET
    if (strlen(CONFIG_LAU_MCP_TOKEN) > 0) {
        snprintf(token, capacity, "%s", CONFIG_LAU_MCP_TOKEN);
        return;
    }

    // OTHERWISE KEEP ONE IN NVS, GENERATED ON FIRST BOOT, SO NO SECRET LIVES IN SDKCONFIG
    nvs_handle_t handle;
    ESP_ERROR_CHECK(nvs_open("lau", NVS_READWRITE, &handle));
    size_t length = capacity;
    if (nvs_get_str(handle, "token", token, &length) != ESP_OK) {
        // THE RADIO IS ON BY NOW SO THIS IS A TRUE RANDOM SOURCE
        uint8_t randomBytes[16];
        esp_fill_random(randomBytes, sizeof(randomBytes));
        for (int index = 0; index < 16; index++) {
            sprintf(token + 2 * index, "%02x", randomBytes[index]);
        }
        ESP_ERROR_CHECK(nvs_set_str(handle, "token", token));
        ESP_ERROR_CHECK(nvs_commit(handle));
        ESP_LOGW(TAG, "readBearerToken() :: generated a new MCP bearer token");
    }
    nvs_close(handle);
}

/***************************************************************************************************/
/***************************************************************************************************/
/***************************************************************************************************/
static void statusLedTask(void *argument)
{
    // SLOW BLINK MEANS NO WIFI, STEADY MEANS READY, AND FAST BLINK MEANS JTAG IS BUSY
    bool ledOnFlag = false;
    while (true) {
        int periodMs;
        if (lauFpgaLockOwner()) {
            ledOnFlag = !ledOnFlag;
            periodMs = 80;
        } else if (!lauNetworkIsConnected()) {
            ledOnFlag = !ledOnFlag;
            periodMs = 500;
        } else {
            ledOnFlag = true;
            periodMs = 200;
        }
        gpio_set_level(PINSTATUSLED, ledOnFlag);
        vTaskDelay(pdMS_TO_TICKS(periodMs));
    }
}

/***************************************************************************************************/
/***************************************************************************************************/
/***************************************************************************************************/
static void confirmOrRollback(bool connectedFlag)
{
    // NEW OTA FIRMWARE MUST PROVE IT CAN REACH THE NETWORK OR THE BOOTLOADER ROLLS BACK, WITHOUT
    // THIS A BAD WIFI SETTING IN AN UPDATE WOULD BRICK A SEALED CAMERA
    const esp_partition_t *runningPartition = esp_ota_get_running_partition();
    esp_ota_img_states_t state;
    if (esp_ota_get_state_partition(runningPartition, &state) != ESP_OK || state != ESP_OTA_IMG_PENDING_VERIFY) {
        return;
    }
    if (connectedFlag) {
        ESP_LOGI(TAG, "confirmOrRollback() :: new firmware is on the network, marking it valid");
        esp_ota_mark_app_valid_cancel_rollback();
    } else {
        ESP_LOGE(TAG, "confirmOrRollback() :: new firmware never reached the network, rolling back");
        esp_ota_mark_app_invalid_rollback_and_reboot();
    }
}

/***************************************************************************************************/
/***************************************************************************************************/
/***************************************************************************************************/
void app_main(void)
{
    // SAFE STATES BEFORE ANYTHING ELSE: FET GATES LOW, JTAG BUFFER OFF, DONE AS AN INPUT
    lauFpgaInit();

    gpio_config_t ledConfig = { .pin_bit_mask = 1ULL << PINSTATUSLED, .mode = GPIO_MODE_OUTPUT };
    gpio_config(&ledConfig);
    xTaskCreate(statusLedTask, "led", 2048, NULL, 2, NULL);

    esp_err_t error = nvs_flash_init();
    if (error == ESP_ERR_NVS_NO_FREE_PAGES || error == ESP_ERR_NVS_NEW_VERSION_FOUND) {
        ESP_ERROR_CHECK(nvs_flash_erase());
        error = nvs_flash_init();
    }
    ESP_ERROR_CHECK(error);

    // MOUNT THE SD LIBRARY, WHICH IS NOT FATAL SINCE STATUS AND OTA STILL WORK WITHOUT A CARD
    lauLibraryMount();

    // BRING UP THE NETWORK AND THEN THE SERVER, NEVER TOUCHING THE FPGA AT BOOT (NO AUTOLOAD)
    if (lauNetworkStart() != ESP_OK) {
        ESP_LOGE(TAG, "app_main() :: no network configuration, the MCP server is not started");
        return;
    }
    bool connectedFlag = lauNetworkWaitConnected(120 * 1000);

    char token[72];
    readBearerToken(token, sizeof(token));
    ESP_LOGW(TAG, "app_main() :: MCP endpoint http://%s.local/mcp   token: %s", CONFIG_LAU_HOSTNAME, token);
    ESP_ERROR_CHECK(lauServerStart(token));

    confirmOrRollback(connectedFlag);
}

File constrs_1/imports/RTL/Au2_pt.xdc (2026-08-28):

# =============================================================================
# Au2_pt.xdc  --  Au2_SLI ported to the Alchitry Pt V2  (XC7A100T-2FGG484I)
#
# The Pt port (CAMERA_RTL_PLAN.md). Phase 1 was the EXISTING SLI design (HDMI passthrough
# + offline pattern generator) re-pinned. Phase 2 (task #12) adds the camera on top: the
# bank-13 LVDS receive interface + the 72 MHz cam_clk_pll reference are at the bottom of
# this file; the CMOS SPI/control pins were already here from Phase 1.
#
# This is a from-scratch re-pin: every PACKAGE_PIN in Au2.xdc is invalid on the Pt V2
# (different die AND package). Derivation, all cross-checked:
#   - Onboard clk/led/usb/rst: LauPythonCamera_Pt_Stack/iocheck/alchitry_pt_base.xdc.
#   - HDMI: the Hd V2 sits on the Pt; its bottom connector maps HDMI to Pt balls in
#     iocheck/alchitry_pt_hd_bottom.xdc. WHICH Hd port is TX vs RX was resolved by tracing
#     the WORKING Au design: its hdmi_tx balls -> element pins (AuV2Pin.kt) -> Hd port
#     (hd_v2.acf) = PORT 1; hdmi_rx = PORT 2. So here TX = Hd port 1, RX = Hd port 2.
#   - C1 handshake: element B27-B30 -> Pt balls (PtV2TopPin.kt), same element pins as the Au.
#   - newSW / C2: spare 3.3 V element pins -- see notes at those blocks.
#
# The timing constraints (false_paths, clock_groups, set_max_delay) are INSTANCE-based and
# carry over verbatim from Au2.xdc; only the two pin-based create_clock lines change.
# =============================================================================

# --- bitstream config (Pt values: bigger flash, x4 SPI, faster config) --------------
set_property BITSTREAM.GENERAL.COMPRESS   TRUE   [current_design]
set_property BITSTREAM.CONFIG.CONFIGRATE   66    [current_design]
set_property CONFIG_VOLTAGE                3.3   [current_design]
set_property CFGBVS                        VCCO  [current_design]
set_property BITSTREAM.CONFIG.SPI_32BIT_ADDR NO  [current_design]
set_property BITSTREAM.CONFIG.SPI_BUSWIDTH  4    [current_design]
set_property BITSTREAM.CONFIG.SPI_FALL_EDGE YES  [current_design]

# =============================================================================
#  CLOCKS
# =============================================================================
# 100 MHz onboard oscillator (Pt: W19)
set_property -dict { PACKAGE_PIN "W19" IOSTANDARD LVCMOS33 SLEW FAST } [get_ports { clk100 }]
create_clock -add -name sys_clk_pin -period 10.00 -waveform {0 5} [get_ports clk100]
# recovered HDMI-input pixel clock (Pt RX = Hd port 2 clk = C18)
create_clock -add -name hdmi_clk -period 13.300 -waveform {0 5} [get_ports hdmi_rx_clk_p]

# --- timing exceptions: VERBATIM from Au2.xdc (all instance-based) -------------------
set_false_path -from [get_clocks sys_clk_pin] -to [get_clocks -of_objects [get_pins i_hdmi_io/i_hdmi_input/hdmi_MMCME2_BASE_inst/CLKOUT0]]
set_false_path -through [get_ports led[*]]
set_false_path -through [get_ports newSW[*]]
set_false_path -from [get_clocks hdmi_clk] -to [get_clocks -of_objects [get_pins ref_clk_pll/inst/mmcm_adv_inst/CLKOUT2]]

# ---- rx_freq_band: sys_clk_pin <-> hdmi_clk, both directions ASYNCHRONOUS ----
# rx_freq_band measures the recovery MMCM's INPUT by counting hdmi_clk edges inside
# a 1 ms gate generated on clk100, so two signals cross between unrelated domains:
#   clk100 -> hdmi_clk : gate_tog, resynchronised by the 3-flop gt_t shift register
#   hdmi_clk -> clk100 : freq_t, held stable for a whole 1 ms window before sampling
# Nothing had ever crossed into hdmi_clk before -- the existing false paths cover
# sys_clk_pin -> CLKOUT0 (the RECOVERED pixel clock), not the MMCM's input -- so
# these were timed as if synchronous and reported -2.438 ns.
set_false_path -from [get_clocks sys_clk_pin] -to [get_clocks hdmi_clk]
set_false_path -from [get_clocks hdmi_clk]    -to [get_clocks sys_clk_pin]
set_false_path -from [get_clocks -of_objects [get_pins ref_clk_pll/inst/mmcm_adv_inst/CLKOUT2]] -to [get_clocks -of_objects [get_pins i_hdmi_io/i_hdmi_input/hdmi_MMCME2_BASE_inst/CLKOUT0]]
set_false_path -from [get_clocks -of_objects [get_pins i_hdmi_io/i_hdmi_input/hdmi_MMCME2_BASE_inst/CLKOUT0]] -to [get_clocks -of_objects [get_pins ref_clk_pll/inst/mmcm_adv_inst/CLKOUT2]]
set_false_path -from [get_clocks -of_objects [get_pins ref_clk_pll/inst/mmcm_adv_inst/CLKOUT2]] -to [get_clocks -of_objects [get_pins i_hdmi_io/i_hdmi_input/hdmi_MMCME2_BASE_inst/CLKOUT1]]
set_false_path -from [get_clocks -of_objects [get_pins ref_clk_pll/inst/mmcm_adv_inst/CLKOUT2]] -to [get_clocks -of_objects [get_pins i_hdmi_io/i_hdmi_input/hdmi_MMCME2_BASE_inst/CLKOUT2]]
set_false_path -from [get_clocks -of_objects [get_pins ref_clk_pll/inst/mmcm_adv_inst/CLKOUT1]]
set_false_path -to   [get_clocks -of_objects [get_pins ref_clk_pll/inst/mmcm_adv_inst/CLKOUT1]]
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

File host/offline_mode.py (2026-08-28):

#!/usr/bin/env python3
"""Inspect both EDIDs and drive the OFFLINE display mode.

    python host/offline_mode.py                 # show everything, change nothing
    python host/offline_mode.py --list          # just the mode table
    python host/offline_mode.py --set 1024x768@75
    python host/offline_mode.py --set 11        # by index, if you prefer
    python host/offline_mode.py --release       # back to the EDID's own pick
    python host/offline_mode.py --dump-display edid_display.bin
    python host/offline_mode.py --dump-served  edid_served.bin

THREE THINGS THAT ARE EASY TO CONFUSE, so this prints them side by side.

  1. THE DISPLAY'S EDID (rdtbl 0x03) -- what the monitor on HDMI-OUT told us.
  2. THE SERVED EDID (rdtbl 0x05)    -- the merged block we present to the PC on
     the input DDC. It is the display's modes INTERSECTED with the pass-through
     clock window, so it is deliberately SHORTER than the display's. Until this
     target existed the served copy could only be inspected through Windows'
     registry cache, which is the host's copy and can be stale.
  3. THE OFFLINE MODE (regs 0x20..0x28) -- what the FPGA generates when no source
     is connected. Nothing to do with either EDID's *timings*; the EDID only
     decides which entry of the curated table gets picked.

SETTING A MODE IS A FORCE, AND IT IS STICKY. --set writes MODEFORCE (reg 0x14)
with force_en set, which OVERRIDES the EDID pick until you --release it or the
FPGA is reloaded. That is the point -- it is how you test a mode the attached
display would never ask for -- but it means "why is my offline mode wrong" has a
second answer besides the EDID.

WHAT IT VERIFIES. After writing, it reads 0x20..0x28 back and reports what the
FPGA actually applied, rather than assuming the write took. The applied index,
the geometry AND the pixel clock all come from the fabric.
"""
import argparse, os, re, sys, time

SYNC, OP_W, OP_R, OP_LR = 0xA5, 0x57, 0x52, 0x72
TGT_DISPLAY, TGT_SERVED = 0x03, 0x05
REG_FORCE = 0x14

ck = lambda s: (256 - (s & 0xFF)) & 0xFF

# ---------------------------------------------------------------- mode table
# Parsed from the RTL itself so it cannot drift from what the fabric will do.
# mode_table.vh is the single source of truth for both the DRP clock words and
# the timing ROM, so re-deriving it here by hand would be a second copy to rot.
MROW = re.compile(r"MROW\(\s*(\d+),\s*(\d+),\s*(\d+),\s*(\d+),\s*(\d+),")


def mode_table(rtl_dir):
    p = os.path.join(rtl_dir, "mode_table.vh")
    if not os.path.exists(p):
        return []
    out = []
    for line in open(p):
        m = MROW.search(line)
        if m:
            i, w, h, hz, khz = (int(x) for x in m.groups())
            out.append(dict(idx=i, w=w, h=h, hz=hz, khz=khz))
    return sorted(out, key=lambda r: r["idx"])


class Link:
    def __init__(self, port, prefer_uart=False):
        self.f = None
        if not prefer_uart:
            try:
                sys.path.insert(0, os.path.dirname(os.path.abspath(__file__)))
                from ftlink import FtLink
                f = FtLink()
                f.drain(quiet=0.3, limit=2.0)
                if f.read_reg(0x00) is not None:
                    self.f, self.name = f, "Ft+ USB 3"
                    return
                f.close()
            except Exception:
                pass
        import serial
        self.s = serial.Serial(port, 115200, timeout=0.2)
        self.name = "%s UART" % port
        time.sleep(0.25)

    def rd(self, a):
        if self.f is not None:
            try:
                return self.f.read_reg(a)
            except Exception:
                return None
        self.s.reset_input_buffer()
        self.s.write(bytes([SYNC, OP_R, a, ck(OP_R + a)]))
        buf, dl = bytearray(), time.time() + 0.35
        while time.time() < dl:
            buf += self.s.read(self.s.in_waiting or 1)
            for i in range(len(buf) - 2):
                if buf[i] == a and ((buf[i] + buf[i + 1] + buf[i + 2]) & 0xFF) == 0:
                    return buf[i + 1]
        return None

    def wr(self, a, v):
        if self.f is not None:
            self.f.write_reg(a, v)
            return
        self.s.write(bytes([SYNC, OP_W, a, v, ck(OP_W + a + v)]))
        time.sleep(0.3)

    def table(self, tgt, n=256):
        """Frame-scan for a reply whose checksum closes -- the reply shares the
        UART with ASCII telemetry, so it will not start at byte 0."""
        if self.f is not None:
            try:
                return bytes(self.f.read_table(tgt, n))
            except Exception:
                return None
        self.s.reset_input_buffer()
        self.s.write(bytes([SYNC, OP_LR, tgt, ck(OP_LR + tgt)]))
        need, buf, dl = n + 2, bytearray(), time.time() + 4.0
        while time.time() < dl:
            buf += self.s.read(self.s.in_waiting or 1)
            for i in range(len(buf) - need + 1):
                if buf[i] != tgt:
                    continue
                w = buf[i:i + need]
                if (sum(w) & 0xFF) == 0:
                    return bytes(w[1:1 + n])
        return None

    def close(self):
        (self.f or self.s).close()


def rd16(link, a):
    lo, hi = link.rd(a), link.rd(a + 1)
    return None if lo is None or hi is None else lo | (hi << 8)


def applied(link):
    b20 = link.rd(0x20)
    if b20 is None:
        return None
    p0, p1, p2 = link.rd(0x26), link.rd(0x27), link.rd(0x28)
    pk = 0 if None in (p0, p1, p2) else p0 | (p1 << 8) | ((p2 & 1) << 16)
    return dict(valid=(b20 >> 7) & 1, edid_ok=(b20 >> 6) & 1, idx=b20 & 0xF,
                hz=link.rd(0x21), w=rd16(link, 0x22), h=rd16(link, 0x24), khz=pk)


def show_applied(a, tag="offline mode now"):
    if a is None:
        print("  %s: (no reply)" % tag)
        return
    print("  %-18s idx %-2d  %sx%s @ %s Hz  pclk %d kHz   valid=%d edid_ok=%d"
          % (tag, a["idx"], a["w"], a["h"], a["hz"], a["khz"], a["valid"], a["edid_ok"]))
    if not a["edid_ok"]:
        print("       edid_ok=0 -> this is the FAILSAFE pick, not a choice made "
              "from the display's EDID.")


def est_timings(b):
    """Established-timing bitmaps, EDID bytes 35/36. The compact part of an EDID
    and the part the merge actually filters, so it is what is worth diffing."""
    B35 = [(7, "720x400@70"), (6, "720x400@88"), (5, "640x480@60"),
           (4, "640x480@67"), (3, "640x480@72"), (2, "640x480@75"),
           (1, "800x600@56"), (0, "800x600@60")]
    B36 = [(7, "800x600@72"), (6, "800x600@75"), (5, "832x624@75"),
           (4, "1024x768@87i"), (3, "1024x768@60"), (2, "1024x768@70"),
           (1, "1024x768@75"), (0, "1280x1024@75")]
    if b is None or len(b) < 38:
        return None
    out = [n for bit, n in B35 if (b[35] >> bit) & 1]
    out += [n for bit, n in B36 if (b[36] >> bit) & 1]
    return out
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

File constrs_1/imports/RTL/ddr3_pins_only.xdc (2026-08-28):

# ddr3_ck_p/ck_n are declared as two SEPARATE single-ended ports on Au2_SLI's
# entity; only the MIG turns them into a differential pair via OBUFDS. With no
# MIG here they are single-ended, so DIFF_SSTL135 fails DRC IOSTDTYPE-1. They
# are idle in this build, so the single-ended standard is the honest constraint.
# ddr3_pins_only.xdc -- PIN CONSTRAINTS ONLY for the DDR3 ports, extracted from
# the MIG's generated XDC.
#
# WHY THIS EXISTS. build_pt_hdmi.tcl does not instantiate cam_frame_ft, and the MIG
# lives inside it, so the MIG's XDC is never read -- but Au2_SLI's ENTITY still
# declares the ddr3_* ports. Unconstrained ports fail DRC (NSTD-1 / UCIO-1), and the
# documented workaround of downgrading those checks to warnings is NOT acceptable
# here: Vivado would then place those ports on arbitrary package pins, and on this
# board those pins are physically wired to the DDR3 device. That is a hardware risk,
# not a paperwork one.
#
# Constraining them to their REAL locations is both safe and honest: the pins land
# where the board expects, and with no MIG driving them they simply sit idle.
# Timing/termination constraints are deliberately NOT copied -- there is no MIG here
# for them to apply to.
set_property SLEW FAST [get_ports {ddr3_dq[0]}]
set_property IN_TERM UNTUNED_SPLIT_50 [get_ports {ddr3_dq[0]}]
set_property IOSTANDARD SSTL135 [get_ports {ddr3_dq[0]}]
set_property PACKAGE_PIN J22 [get_ports {ddr3_dq[0]}]
set_property SLEW FAST [get_ports {ddr3_dq[1]}]
set_property IN_TERM UNTUNED_SPLIT_50 [get_ports {ddr3_dq[1]}]
set_property IOSTANDARD SSTL135 [get_ports {ddr3_dq[1]}]
set_property PACKAGE_PIN M21 [get_ports {ddr3_dq[1]}]
set_property SLEW FAST [get_ports {ddr3_dq[2]}]
set_property IN_TERM UNTUNED_SPLIT_50 [get_ports {ddr3_dq[2]}]
set_property IOSTANDARD SSTL135 [get_ports {ddr3_dq[2]}]
set_property PACKAGE_PIN L21 [get_ports {ddr3_dq[2]}]
set_property SLEW FAST [get_ports {ddr3_dq[3]}]
set_property IN_TERM UNTUNED_SPLIT_50 [get_ports {ddr3_dq[3]}]
set_property IOSTANDARD SSTL135 [get_ports {ddr3_dq[3]}]
set_property PACKAGE_PIN J20 [get_ports {ddr3_dq[3]}]
set_property SLEW FAST [get_ports {ddr3_dq[4]}]
set_property IN_TERM UNTUNED_SPLIT_50 [get_ports {ddr3_dq[4]}]
set_property IOSTANDARD SSTL135 [get_ports {ddr3_dq[4]}]
set_property PACKAGE_PIN H20 [get_ports {ddr3_dq[4]}]
set_property SLEW FAST [get_ports {ddr3_dq[5]}]
set_property IN_TERM UNTUNED_SPLIT_50 [get_ports {ddr3_dq[5]}]
set_property IOSTANDARD SSTL135 [get_ports {ddr3_dq[5]}]
set_property PACKAGE_PIN G20 [get_ports {ddr3_dq[5]}]
set_property SLEW FAST [get_ports {ddr3_dq[6]}]
set_property IN_TERM UNTUNED_SPLIT_50 [get_ports {ddr3_dq[6]}]
set_property IOSTANDARD SSTL135 [get_ports {ddr3_dq[6]}]
set_property PACKAGE_PIN J21 [get_ports {ddr3_dq[6]}]
set_property SLEW FAST [get_ports {ddr3_dq[7]}]
set_property IN_TERM UNTUNED_SPLIT_50 [get_ports {ddr3_dq[7]}]
set_property IOSTANDARD SSTL135 [get_ports {ddr3_dq[7]}]
set_property PACKAGE_PIN H19 [get_ports {ddr3_dq[7]}]
set_property SLEW FAST [get_ports {ddr3_dq[8]}]
set_property IN_TERM UNTUNED_SPLIT_50 [get_ports {ddr3_dq[8]}]
set_property IOSTANDARD SSTL135 [get_ports {ddr3_dq[8]}]
set_property PACKAGE_PIN H13 [get_ports {ddr3_dq[8]}]
set_property SLEW FAST [get_ports {ddr3_dq[9]}]
set_property IN_TERM UNTUNED_SPLIT_50 [get_ports {ddr3_dq[9]}]
set_property IOSTANDARD SSTL135 [get_ports {ddr3_dq[9]}]
set_property PACKAGE_PIN G18 [get_ports {ddr3_dq[9]}]
set_property SLEW FAST [get_ports {ddr3_dq[10]}]
set_property IN_TERM UNTUNED_SPLIT_50 [get_ports {ddr3_dq[10]}]
set_property IOSTANDARD SSTL135 [get_ports {ddr3_dq[10]}]
set_property PACKAGE_PIN J15 [get_ports {ddr3_dq[10]}]
set_property SLEW FAST [get_ports {ddr3_dq[11]}]
set_property IN_TERM UNTUNED_SPLIT_50 [get_ports {ddr3_dq[11]}]
set_property IOSTANDARD SSTL135 [get_ports {ddr3_dq[11]}]
set_property PACKAGE_PIN H17 [get_ports {ddr3_dq[11]}]
set_property SLEW FAST [get_ports {ddr3_dq[12]}]
set_property IN_TERM UNTUNED_SPLIT_50 [get_ports {ddr3_dq[12]}]
set_property IOSTANDARD SSTL135 [get_ports {ddr3_dq[12]}]
set_property PACKAGE_PIN G15 [get_ports {ddr3_dq[12]}]
set_property SLEW FAST [get_ports {ddr3_dq[13]}]
set_property IN_TERM UNTUNED_SPLIT_50 [get_ports {ddr3_dq[13]}]
set_property IOSTANDARD SSTL135 [get_ports {ddr3_dq[13]}]
set_property PACKAGE_PIN G17 [get_ports {ddr3_dq[13]}]
set_property SLEW FAST [get_ports {ddr3_dq[14]}]
set_property IN_TERM UNTUNED_SPLIT_50 [get_ports {ddr3_dq[14]}]
set_property IOSTANDARD SSTL135 [get_ports {ddr3_dq[14]}]
set_property PACKAGE_PIN G16 [get_ports {ddr3_dq[14]}]
set_property SLEW FAST [get_ports {ddr3_dq[15]}]
set_property IN_TERM UNTUNED_SPLIT_50 [get_ports {ddr3_dq[15]}]
set_property IOSTANDARD SSTL135 [get_ports {ddr3_dq[15]}]
set_property PACKAGE_PIN H15 [get_ports {ddr3_dq[15]}]
set_property SLEW FAST [get_ports {ddr3_addr[13]}]
set_property IOSTANDARD SSTL135 [get_ports {ddr3_addr[13]}]
set_property PACKAGE_PIN L16 [get_ports {ddr3_addr[13]}]
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

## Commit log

2026-06-08 Add USB telemetry, EDID read/merge, robust HDMI passthrough + camera trigger
    Major feature work on the Au V2 (xc7a35tftg256-2) repeater + SLI controller,
    all verified on hardware:
    UART telemetry (FT2232H ch.B / COM port, P16, 115200 8N1)
    - usb_status.v / status_line.v: live status line (sel, polarity, mode/rdy,
    frame-rate, hdmi_io decode flags, edid_merge state, sampled TLP, trig count)
    Offline output retimed 1280x720@120 -> 800x600@60
    - vga.vhd 800x600 VESA timing; ref_clk MMCM clk125->40MHz, clk625->200MHz
    HDMI passthrough fixes
    - hdmi_input.vhd: VDP preamble detect held across long preambles (AMD Radeon
    RX 7900 XTX) so in_vdp enters -> picture (was black despite symbol lock)
    - clk_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
    [Au2.xdc]
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2026-06-09 Offline output: EDID auto-select + on-the-fly SLI patterns (Phase 2, HW-verified)
    The offline (FPGA-generated) output now picks its resolution/frame rate from the
    PROJECTOR's EDID automatically -- no hardcoded mode. Verified on hardware: the
    projector's EDID drove 1024x768@75, the camera triggers in sync, and the SLI
    stripes render correctly. Timing closes with margin at the worst-case 78.67 MHz
    (WNS +2.71ns / WHS +0.113ns), so 1024x768@75 and 800x600@120 are both covered.
    EDID auto-select:
    - i2c_master_edid.v: 2nd read port (rd_addr2/rd_data2) into the captured display
    EDID RAM, so the mode picker reuses the bytes edid_merge already reads (no 2nd
    DDC master / no bus contention).
    - edid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
    [Au2.xdc]
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2026-06-12 host: port Qt linearization tool onto main
    Bring the host/ Qt app (Basler camera capture + tone-correction curve builder +
    LAUAuBoard USB uploader) onto the main line as the starting point for the
    correction-table workflow.
    Next steps (separate commits): wire pattern_lut.v into pattern_gen's lut_din/
    lut_dout seam, add a USB receive path (main is TX-only today), and adapt
    LAUAuBoard to main's protocol (drop the qishi-hu register R/W; keep the
    A5 5B 02 correction upload).
    [lauauboard.cpp]
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2026-06-19 LauCameraTrigger stacking board: unique JST refs + corrected order files
    Rename the three JSTs to MASTER1/SLAVE1/SLAVE2 (resolving a duplicate SLAVE reference designator) so the assembly CPL has unique designators; PCB synced via F8. Regenerate production bom/bom_full/cpl from the corrected board with matched MPNs (DF40C-80DP/50DP-0.4V(51), SM07B-SRSS-TB). Matches the JLCPCB rev-1 PCBA order. FPGA Bank-B remap intentionally left uncommitted until the board is validated.
    [LauCameraTrigger_Alchitry_Stack.kicad_pcb, LauCameraTrigger_Alchitry_Stack.kicad_sch, bom.csv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]
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2026-06-29 hw: bond DIP-switch GND island to DF40 ground + document errata
    The fabricated LauCameraTrigger_Alchitry_Stack had a floating GND island:
    SW1 GND pads, the decoupling caps (C1/C2), and the tie-low resistor grounds
    (R2/R4/R6/R8) sat on an F.Cu pour fragment never bonded to the DF40 connector
    grounds. Net-level DRC missed it (all logically on GND); the RGB switches
    couldn't pull their nets low and the caps were ungrounded.
    Fix (PCB): explicit B.Cu GND traces from the SW1 GND pad (~140.8,99.8) to the
    J3/DF40 ground region (~156.5,102.8), a GND stitching via at (162,97.5) by
    C1/C2, and switch-position silkscreen (HvsV/Blue/Green/Red).
    Docs (SCHEMATIC.md): new section 10 errata describing the d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
    [LauCameraTrigger_Alchitry_Stack.kicad_pcb]
2026-06-29 hw: regenerate production files for GND-fixed rev (ordered)
    Rebuilt Gerbers + Excellon drill from the GND-fixed PCB (KiCad 10 kicad-cli;
    zones refilled on export). Gerber filenames switch from Protel extensions
    (.gtl/.gbl/...) to KiCad-native .gbr. DRC: 0 violations / 0 unconnected
    (drc_report.txt).
    BOM now carries LCSC part numbers for turnkey PCBA:
    JST SM07B-SRSS-TB -> C160406; 0.1uF 0805 -> C49678;
    DF40C-80DP-0.4V (J2,J3) -> C294544; DF40C-50DP-0.4V (J1) -> C424645.
    SW1 left DNP for PCBA (LCSC stock ~0) -- hand-solder Wurth 418121160804.
    CPL verified against current PCB: all 9 placed parts match position exactly
    (GND fix moved nothing); R1-R8 excluded as DNP.
    Ordered from JLCPCB (d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
    [LauCameraTrigger_Alchitry_Stack-B_Cu.gbr, LauCameraTrigger_Alchitry_Stack-B_Mask.gbr, LauCameraTrigger_Alchitry_Stack-B_Paste.gbr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]
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2026-07-09 hw: rebuild Bank-B stack bitstream with EDID hot-plug fix; commit its sources
    Rebuild Bitstream/Au2_SLI_stackB.bin so the shipped image includes the
    edid_merge content-change HPD re-pulse (2faac4d) -- a projector that swaps its
    warm-up placeholder EDID for the real one now gets re-read automatically. Update
    the AlchitryFlasher pinned SHA-256 to match the new bin.
    Also commit the sources the bitstream is actually built from, which until now
    lived only in the gitignored Vivado project, so the repo can reproduce it:
    * Au2.xdc -- activate the Bank-B (DF40 stacking board) remap; the 8
    Bank-A camera/config lines become comments. The stacking
    board i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
    [Au2.xdc]
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2026-07-09 hw(mipi): wire the schematic -- 23 nets, XAPP894 front end, explicit no-connects
    The scaffold had 10 symbols and zero connectivity (no wires, no labels, no
    nets). Net it out per SCHEMATIC.md, add the 9 XAPP894 front-end resistors, and
    snap every pin endpoint onto the 1.27 mm grid.
    Nets (verified with kicad-cli 10.0.3 `sch export netlist`): 23 real nets,
    0 single-node nets, all 22 signal nets match the spec.
    * 3 HS pairs: camera -> J3, with R_T (150R) across each pair and R_LP*
    (100R) tapping each line to its HSUL_12 LP input
    * CAM_TRIG through R_TRIG (33R series) to the camera; CAM_STROBE direct
    * I2C pulled to +3V3 (camera abs max on those pins is 3.8 V)
    * J1 +3V3 on pins 1/3/5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
    [LauMipiCamera_Alchitry_Stack.kicad_sch]
2026-07-09 hw(mipi): fix overlapping schematic graphics (cosmetic; netlist unchanged)
    Three separate overlaps, none of them electrical:
    1. Property text. The scaffold parked Reference/Value text far from its symbols
    and stacked it: J2 and J3 both at (154.94,77.47), R_SCL/R_SDA/R_TRIG all at
    (350.52,81.80), C1 and C2 both at (42.54,167.46) -- over by J1, nowhere near
    the caps. Re-anchor every symbol's text to its own body.
    2. Labels drawn through the R/C bodies. A global label anchored directly on a
    vertical resistor's pin renders on top of the symbol. Give each R/C pin a
    5.08 mm stub wire and put the label at the far end.
    3. J_CAM labels sitting inside the connector body. J_CAM is the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
    [LauMipiCamera_Alchitry_Stack.kicad_sch]
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2026-07-09 hw(mipi): import netlist onto the PCB; repair what F8 broke
    Update PCB from Schematic pulled all 23 nets onto the board: 268 pads netted,
    0 node mismatches against the schematic netlist, and kicad-cli reports
    schematic_parity: 0. The scaffold's R_1206 became R_0402 and the 9 XAPP894
    front-end resistors were added. KiCad also annotated the non-numeric refs
    (R_SCL -> R_SCL1, J_CAM -> J_CAM1, R_LP* -> R_LP*1); schematic and PCB agree.
    F8 ran with "replace footprints", which re-created every footprint with new
    UUIDs at default placement. Two consequences, both fixed here:
    1. J1/J2/J3 landed on F.Cu. They are bottom-side DF40 plugs, and their old
    coordinates encoded the Alchitry stack geomet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
    [LauMipiCamera_Alchitry_Stack.kicad_pcb, LauMipiCamera_Alchitry_Stack.kicad_sch]
2026-07-09 hw(mipi): adopt the trigger board's real outline (55x45 mm) for the MIPI board
    The scaffold shipped a placeholder 72x61 mm rectangle. Replace it with the
    Edge.Cuts geometry of LauCameraTrigger_Alchitry_Stack, which is fabricated and
    known to mate the Alchitry stack:
    * 55 x 45 mm body, 1.5 mm chamfered corners
    * right-edge relief notch (x 169.045..174.545, y 68.412..97.412)
    * 4x mounting holes, dia 2.2 mm, 50 x 40 mm centres
    Copied verbatim with ZERO translation: both boards already place the three DF40
    sites at identical coordinates (J1 136.045,64.413 / J2 157.545,64.413 /
    J3 157.545,101.413). Cross-checks against ROADMAP SS3 (from Br.step): the outline
    sits -38.0 mm in x and +4.0 mm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
    [LauMipiCamera_Alchitry_Stack.kicad_pcb]
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2026-07-09 hw(mipi): rotate J_CAM1 180 deg so the HS pairs stop crossing
    All three D-PHY pairs crossed between the camera and J3:
    lane at J_CAM1 at J3 verdict
    CK P=159.25 N=159.75 P=158.94 N=158.54 P-left vs P-right
    D0 P=162.25 N=162.75 P=157.75 N=157.34 P-left vs P-right
    D1 P=160.75 N=161.25 P=158.94 N=158.54 P-left vs P-right
    Systematic, not a per-lane slip: J_CAM1 was at rot=180 so its pin numbers ran
    right-to-left, while J3's run left-to-right. The FPGA side cannot absorb this --
    on the DF40 the higher B-number is always the P ball (CK = B47/B45 -> V13/V14,
    V13 = P; the spare MRCC pair B41/B39 has the same parity), so P is always to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
    [LauMipiCamera_Alchitry_Stack.kicad_pcb]
2026-07-09 hw(mipi): route the 4 DIP-switch nets and the +3V3 feed to C1/C2
    31 segments, 5 vias. All four switch nets are fully connected end to end
    (kicad-cli ratsnest: SW_HVSV / SW_BLUE / SW_GREEN / SW_RED all closed).
    Topology. SW1's own GND pads (column at x=135.3) block a straight run east, and
    J3's targets straddle both rows of a 0.4 mm-pitch connector, so:
    * each net takes a short F.Cu stub off SW1's west pad column
    * SW_HVSV and SW_GREEN drop to B.Cu beside the switch, run east under the
    board, and enter J3 through the INTER-ROW CORRIDOR (y 100.387..102.437 --
    empty between the even and odd pad rows), then turn south into pads 27/29.
    This is the escape the fabricated trigger b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
    [LauMipiCamera_Alchitry_Stack.kicad_pcb]
2026-07-09 hw(mipi): explicit GND returns for SW1 and C1/C2; trim J1 +3V3 to 3 contacts
    GND ties (13 segments, 5 vias). Both loads now have a dedicated copper return to
    a DF40 ground pin, rather than relying on the pour alone -- and they return to
    DIFFERENT connectors, so the paths are genuinely separate:
    * SW1's four GND pads -> short F.Cu stubs west to a B.Cu spine at x=133.5,
    then east under the board to J3 pad 2 (GND, 149.745/100.057), entering from
    the north as even-row pads require.
    The spine cannot run at x=135.305 (through the pads) because SW_BLUE and
    SW_RED thread the gaps between those same GND pads at y=93.46 and y=99.0.
    * C1/C2 GND pads -> F.Cu around the caps' own +3V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
    [LauMipiCamera_Alchitry_Stack.kicad_pcb, LauMipiCamera_Alchitry_Stack.kicad_sch]
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2026-07-12 hw(camera): fix pin plan — all 7 LVDS pairs must be on the DF40's odd row
    The previous pin plan was wrong and would have cost a board spin.
    The DF40's two rows escape in OPPOSITE directions. Measured from the footprint
    already used on LauMipiCamera/LauCameraTrigger (DF40C-80DP-0.4V): odd pins sit
    at y=+1.355mm, even pins at y=-1.355mm. The old plan put sync/dout0/dout2 on
    even-row pairs (B40/42, B46/48, B52/54) — those three would have escaped out the
    FAR side of the connector, away from the sensor, forcing each to loop around the
    connector body or via down to another layer. The .kicad_dru flags exactly that as
    a warning.
    Alchitry's pairs are always (odd, odd+2) or (even, even+2), so b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
    [LauPythonCamera_Pt_Stack.kicad_sch]
2026-07-12 hw(camera): power-on-safe pulls + complete the XDC pin map
    Two related fixes, both from the same root cause: FPGA user I/O are Hi-Z until
    DONE goes high, so between power-up and bitstream load every control line into
    the sensor floats.
    1. POWER-ON-SAFE PULLS (R3-R7, 10k 0402). The schematic had none.
    ss_n PULL-UP a floating SPI select could read as ASSERTED, and the
    sensor would clock in garbage from a floating sck/mosi
    reset_n PULL-DOWN holds the sensor in reset until the FPGA is configured
    and deliberately releases it (fail-safe direction)
    trigger0-2 PULL-DOWN no spurious exposures during configuration
    The XD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
    [LauPythonCamera_Pt_Stack.kicad_sch]
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2026-07-12 hw(camera): apply three fixes learned from a fabbed board (ruffner/lupa300)
    Compared this schematic against ruffner/lupa300 -> pcb/uZed/lupa-hdmi-carrier.sch,
    a MANUFACTURED FPGA carrier for a LUPA300 in the SAME Andon LCC48 socket. Three
    changes came out of it.
    1. FB1 — FERRITE BEAD ON vdd_pix. Their board beads VPIX, VDDA and VADC (BLM18).
    We had NOTHING on the pixel supply, which is the most noise-sensitive rail on
    the sensor. This was a genuine omission, not a simplification. U4 -> FB1 -> the
    sensor.
    2. U4 -> ADP7158-3.3. They used the ADP7158 (ultra-low-noise, high-PSRR, +/-0.8%)
    for their sensitive rails. It meets the vdd_pix 3.25-3.35V window with margin,
    where a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
    [LauPythonCamera_Pt_Stack.kicad_sch]
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2026-07-12 fix(camera): MIRRORED FOOTPRINT + LVDS moves to the DF40's even row
    Two serious bugs, both surfaced by the reminder that the DF40s are on the BOTTOM
    and the sensor is on the TOP. Both would have scrapped a board.
    ===========================================================================
    BUG 1 — THE FOOTPRINT WAS MIRRORED
    ===========================================================================
    KiCad's canvas has +y DOWN. The datasheet drawings use +y UP. The footprint was
    built straight from the datasheet without converting.
    Result: numbering ran CLOCKWISE on the canvas where the real part runs
    COUNTER-CLOCKWISE. No rotation of a physical part can fix a mirrored footprint.
    shipp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
    [LauPythonCamera_Pt_Stack.kicad_sch]
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2026-07-12 fix(camera): schematic audit — D2 (LDO cap behind the bead), D4, D5, D6
    Adversarial audit of the schematic against the datasheet. Six defects. Four fixed
    here; D1 and D3 need design decisions and follow.
    D2 — U4's LDO OUTPUT CAP WAS BEHIND THE FERRITE. (serious)
    +3V3_PIX_RAW had ZERO capacitance. Every vdd_pix cap sat behind FB1.
    An LDO's output capacitor is part of its COMPENSATION LOOP and must be at the
    VOUT pin. With a bead in series, the bead's impedance swamps the cap's at the
    loop crossover, the output pole moves, and the regulator can peak or
    oscillate — on the one rail whose entire purpose is to be quiet.
    This was introduced when FB1 was added (t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
    [LauPythonCamera_Pt_Stack.kicad_sch]
2026-07-12 fix(camera): D1 (anti-sequenced power-down) + D3 (U4 was the wrong part)
    The last two defects from the schematic audit. Both were mine.
    D1 — POWER-DOWN WAS ANTI-SEQUENCED, not merely unsequenced
    Root cause I had missed: VDD_SYS OUTLIVES +3V3_SYS. The Pt's 3.3 V regulator is
    fed FROM VDD, so on power-down the 3.3 V rail dies while VDD is still coasting.
    And vdd_pix was the ONLY rail I fed from VDD_SYS.
    So on every power-down, vdd_33 and vdd_18 collapsed while vdd_pix sat at 3.3 V
    into a dead core for ~9 ms (14 uF of bulk against a 5 mA lo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
    [LauPythonCamera_Pt_Stack.kicad_sch]
2026-07-12 fix(camera): REBUILD the power tree — it was architecturally wrong
    The power/analog audit found the power section was not buggy, it was BACKWARDS.
    VDD is confirmed 5 V (USB-C), which makes the correct architecture available.
    WHAT WAS WRONG
    --------------
    * vdd_33 -- the sensor's ANALOG 3.3 V domain, 140 mA -- came through a bare LOAD
    SWITCH off the Pt's +3V3_SYS, which is a 4 A ADP5052 buck feeding an XC7A100T
    and DDR3L. A load switch has NO PSRR. Every FPGA and DDR3 transient went
    straight into the sensor's analog supply.
    Meanwhile the 5 mA vdd_pix got the ultra-low-noise LDO. Backwards.
    * The DC budget did not close. At +/-2% on the Pt's rail there was 34 mV of total
    IR budge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
    [LauPythonCamera_Pt_Stack.kicad_sch]
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2026-07-13 fix(camera): power tree — 3.3 V ONLY. There is no 5 V on the Pt V2.
    The previous rebuild assumed VDD = 5 V from USB-C, based on Alchitry's pinout page
    ("5V-12V board power. When plugged into USB, this can supply 5V"). That was wrong:
    the Pt V2 is a 3.3 V board. Every sensor rail must come from the +3.3V on the
    control header.
    The VDD pins (control header, even 2-16) are now DELIBERATELY LEFT UNCONNECTED.
    THE TREE
    --------
    +3.3V --+--> U2 LDO 1.8 V ---------------------------> +1V8_CAM vdd_18 80 mA
    | (comes up FIRST)
    +--> U3 load switch --+-- FB1 (LOW DCR) -----> +3V3_CAM vdd_33 140 mA
    Rds <= 50 mO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
    [LauPythonCamera_Pt_Stack.kicad_sch]
2026-07-13 fix(camera): REBUILD the power tree — boost + LDO. The 3.3 V tap never worked.
    The Pt V2's +3V3 rail is 3.278 V, not 3.300 V. It is fully derivable from
    Alchitry's own schematic: the ADP5052 buck ch.1 divider (R16 31.6k / R15 10.2k)
    against an 0.8 V feedback reference. Validated — the same convention predicts
    the Pt's 1V, 1V8 and 1V35 rails exactly. With the ADP5052's +/-1.5 % accuracy
    the rail is 3.229 to 3.327 V.
    Three consequences, all arithmetic, none of them opinion:
    * vdd_pix (3.25-3.35 V) is OUT OF SPEC at the low corner, by 21 mV.
    * vdd_33 had ~7 mV of worst-case margin after ferrite + connector IR drop.
    * The tap made correct power-up sequencing IMPOSSIBLE. vdd_33 tapped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
    [LauPythonCamera_Pt_Stack.kicad_sch]
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2026-07-13 fix(camera): footprints — every one now resolves. Two were broken, two were missing.
    Verified all 10 footprint references in the schematic against the authoritative
    sources rather than trusting the names. KiCad is not installed on this machine,
    so the standard names were checked against the official KiCad/kicad-footprints
    repository on GitHub.
    Two were WRONG and would have failed to resolve:
    * U3 (boost) was "Package_SON:SOT-563". SOT-563 lives in Package_TO_SOT_SMD,
    not Package_SON. Fixed.
    * J1/J2/J3 referenced "Connector_Hirose_DF40:...". THAT LIBRARY DOES NOT EXIST
    in KiCad -- the real one is Connector_Hirose, and it ships no DF40 parts.
    The fabbed LauCameraTrigger_Alc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
    [LauPythonCamera_Pt_Stack.kicad_sch]
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2026-07-13 fix(camera): LDO stability caps 0402 -> 0603 (DC-bias derating)
    The six LDO input/output caps (C29, C30, C34-C37) were 1uF in an 0402. At the
    3.3-4.5 V bias they actually see, an 0402 X7R loses 30-40% of its capacitance,
    which can drop below the TPS7A20's 1 uF MINIMUM FOR STABILITY. CAMERA_POWER_DESIGN.md
    specifies 0603 for exactly this reason; the schematic did not match. Now it does.
    Sensor per-pin decoupling (C1-C7) stays 0402 -- those are decoupling caps, not
    stability-critical, and derating there is harmless.
    Full audit against the design docs also confirms:
    * all 48 sensor pins connected
    * all 8 sensor CMOS inputs have pulls, correct polarity (ss_n UP to the
    sensor's own +3V3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
    [LauPythonCamera_Pt_Stack.kicad_sch]
2026-07-13 feat(camera): JLCPCB-ready BOM — LCSC part number on every assembled component
    The schematic had footprints but NO LCSC part numbers, so no exported BOM would
    have told JLCPCB what to actually buy. Now every component carries MPN + LCSC
    fields, and production/bom.csv is generated in JLCPCB's format.
    22 line items, 68 placements. 21 line items assembled by JLCPCB; 1 hand-soldered.
    WHY THIS MATTERS MORE THAN USUAL: the two 3.3 V LDOs (C2862740) are exactly the
    part JLCPCB would "helpfully" substitute. A BOM saying "3.3 V LDO, SOT-23-5"
    with no part number invites an RT9080 or ME6211 -- both +/-2% or worse, both of
    which FAIL the vdd_pix window (3.25-3.35 V) on their own. The part number is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
    [bom.csv]
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2026-07-13 feat(camera): dual-source the inductor; document why every Extended part is forced
    TWO ASKS: don't burn money on Extended parts, and don't leave me picking
    replacements later. Addressed both.
    === The BOM is already at the Extended floor ===
    JLCPCB charges ~$3 per unique EXTENDED part; BASIC parts are free. All 13
    passive line items are Basic (that alone avoids ~$39). The 7 Extended parts are
    each forced -- there is no Basic part that does the job:
    * TPS7A2033 (LDO 3.3 V) -- Basic has only AMS1117 / XC6206, +/-2% or worse.
    +/-2% of 3.3 V spans 3.234-3.366 V against a vdd_pix window of 3.250-3.350 V.
    They FAIL THE SPEC ON THEIR OWN, before a single millivolt of IR drop.
    * TPS7A2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
    [LauPythonCamera_Pt_Stack.kicad_sch, bom.csv]
2026-07-13 fix(camera): SPICE found a real bug — L1 saturates on every startup. Resized 3x3 -> 4x4.
    Simulated the power tree in LTspice with TI's ACTUAL PSpice models: TPS7A20
    (SBVM961) x3, TLV803S (SBVM034) x2, TPS61023 (SLVMD68). The sensor has no public
    SPICE model (confirmed with onsemi) so it is modelled as its datasheet loads plus
    the board's real decoupling.
    === THE BUG SPICE FOUND ===
    Peak inductor current at STARTUP is 1.496 A -- about 3x the 0.54 A steady-state
    peak. It is the boost charging its output caps against its own 3.7 A internal
    current limit. NOT a numerical spike: the current sits above 1.2 A for 15 us and
    above 1.4 A for 6 us, on EVERY power-up.
    I had sized L1 on steady-state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
    [LauPythonCamera_Pt_Stack.kicad_sch, bom.csv]
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2026-07-13 fix(camera): socket P/N confirmed from onsemi's own headboard BOM — it needs the "-1"
    Pulled onsemi's NOIP-48PIN-HEAD-BD-A-GEVK headboard schematic and read their BOM
    (31000040 REV4). Against the NOIP1SN1300A they list:
    MFG Part#: 680-48-SM-G10-R14-1
    MFG: ANDON SOCKET
    Count: 1 Ref: U6
    So the socket already in this design is the right one -- but the part number was
    MISSING THE "-1" SUFFIX. Every distributor lists it with the -1; we had
    680-48-SM-G10-R14. Fixed in the schematic and the BOM.
    Also confirmed OPEN-TOP, which the lens requires: the same schematic notes "U6A
    Socket Cap is NOT USED for 48 Pin Socket Assembly" -- the cap/spacer belongs only
    to the 84-pin PY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
    [LauPythonCamera_Pt_Stack.kicad_sch, bom.csv]
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2026-07-13 feat(edid): read the display's captured EDID over USB (rdtbl TGT_EDID)
    The FPGA has always captured the output display's EDID into a RAM inside
    edid_merge, but nothing exposed it: edid_hex_dumper.v was never instantiated
    and the control protocol only read back the LUT/correction tables. So we could
    tell that an EDID was valid, but never see it.
    Add it as target 0x03 on the EXISTING rdtbl opcode rather than wiring up the
    dumper, so it reuses the checksum, arbiter and S_RTAB streaming path that
    test_silicon.py already verifies on hardware:
    host -> A5 72 03 8B
    FPGA -> 03 D[0..255] CK (03 + sum(D) + CK) == 0 mod 256
    Both existing read ports on the EDID RAM were taken (edid_builde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
    [dump_edid.py]
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2026-07-13 hw(camera): PYTHON 1300 board — schematic rework + PCB layout started
    Work in progress on the Pt V2 PYTHON 1300 camera daughter board (authored in KiCad,
    not by the assistant — committing it so it is not lost):
    - LauPythonCamera_Pt_Stack.kicad_sch substantially reworked
    - LauPythonCamera_Pt_Stack.kicad_pcb new — layout started
    - LauPythonCamera_Pt_Stack.kicad_dru design rules added
    - LauSensors.kicad_sym drop the unused vendored Device:D and
    Device:Q_PMOS_GSD symbols (24 -> 18)
    The two dropped symbols were local copies of stock KiCad Device parts; verified that
    no schematic in the repo references LauSensors:Device:D or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
    [LauPythonCamera_Pt_Stack.kicad_pcb, LauPythonCamera_Pt_Stack.kicad_sch]
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
